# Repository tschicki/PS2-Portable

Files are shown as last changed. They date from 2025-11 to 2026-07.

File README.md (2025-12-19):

# A Custom PlayStation 2 Portable from Scratch

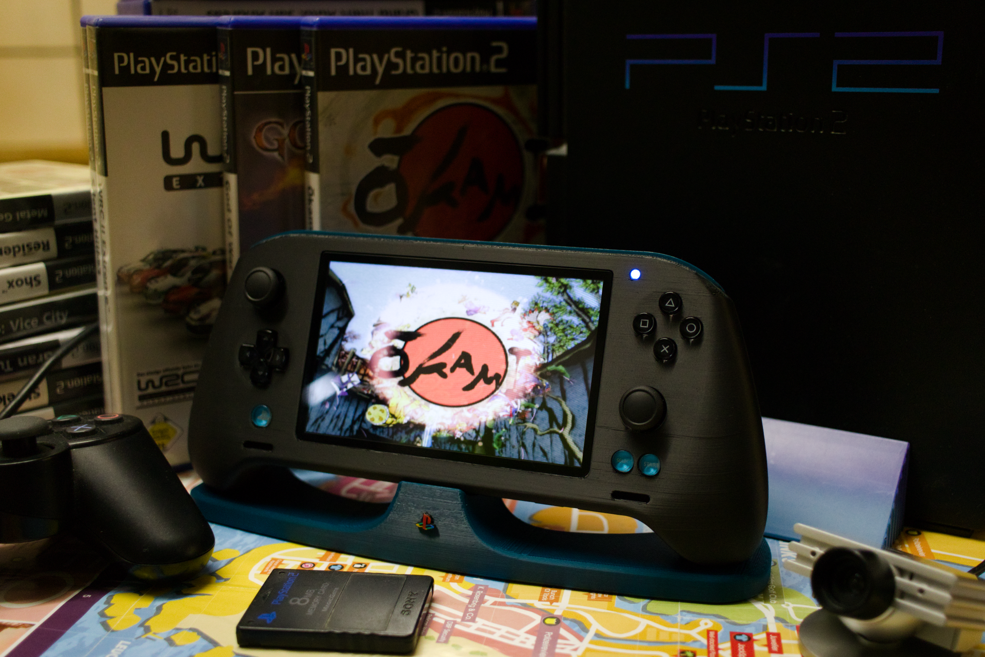
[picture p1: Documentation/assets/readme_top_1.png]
  

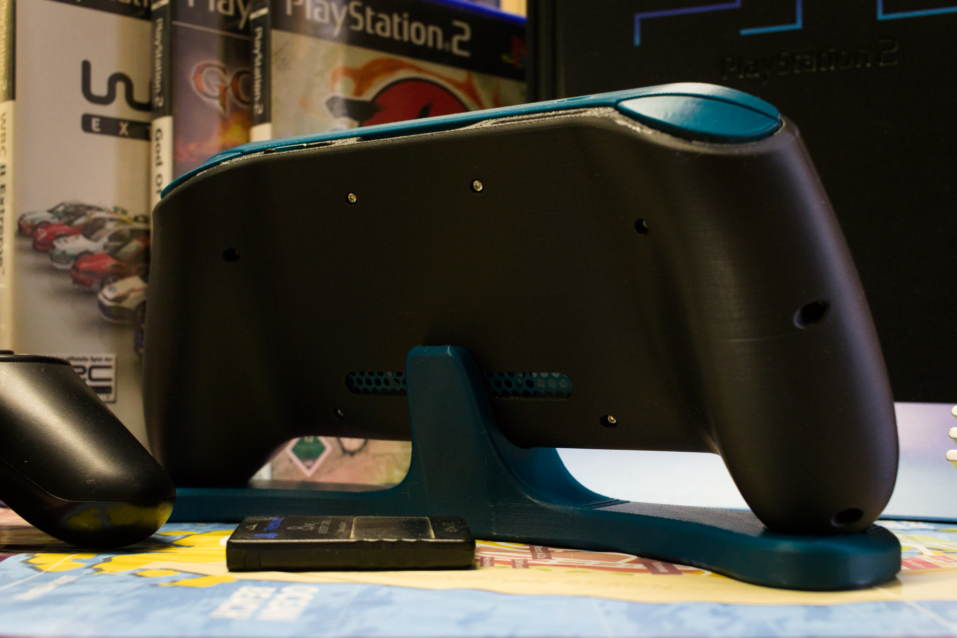
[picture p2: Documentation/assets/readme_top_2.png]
  

  

## About this Project
Just like the title says, this is a PlayStation 2 portable designed from scratch. This portable contains presumably world's first custom reverse engineered PS2 mainboard not made by Sony. It is only reusing 6 ICs of an original PS2, salvaged from SCPH-7900x or SCPH-9000x mainboards.

Most PS2 games can be played natively via OPL or NHDDL and the portable also features support for PS1 games via DKWDRV. Its two custom memory card slots are compatible with miniaturized PS2 Memory Cards, SD-Cards (MX4SIO) and a miniaturized SD2PSX.

Development of this project was started in 2022.

## Overview

### Custom PS2 AIO Mainboard
The mainboard was designed from scratch and is based on the SCPH-7900x and SCPH-9000x PS2 revisions. It also includes modern features, like USB-C PD charging and battery management, fully digital video output, I2S speaker and headphone amplifier and a customized boot ROM to boot directly into homebrew.  

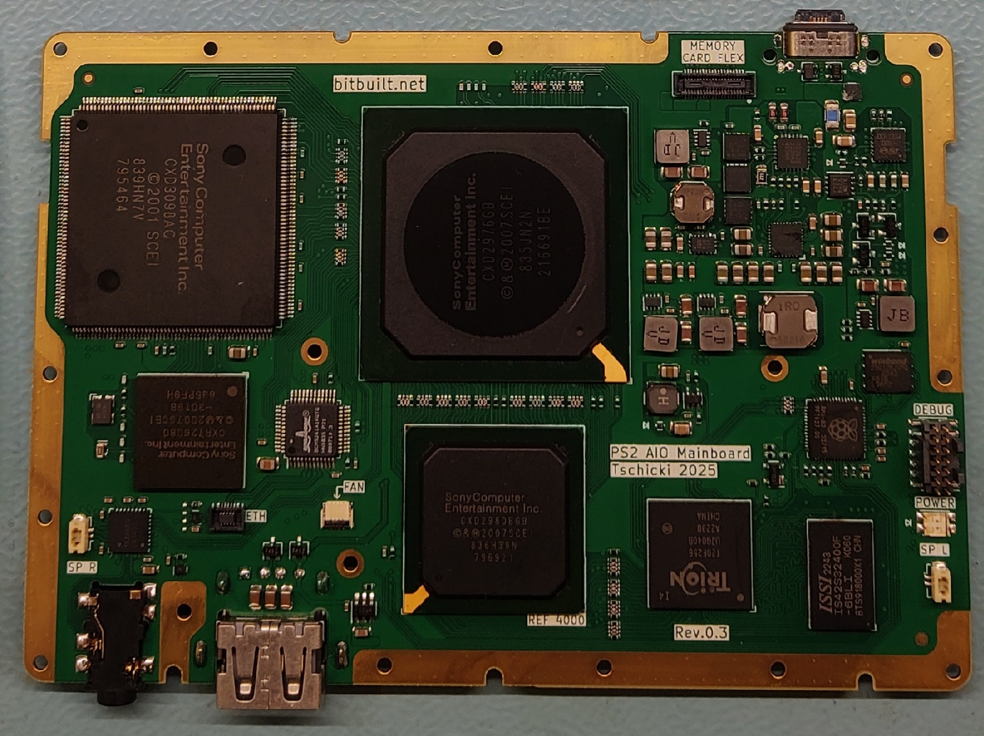
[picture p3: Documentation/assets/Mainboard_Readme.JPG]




#### Details:

- Battery Management:
    - USB C PD charging at 5V/9V/15V
    - Powered from 2S 5000mAh 21700 batteries for a total of 37Wh or about 4.5h of runtime on a single charge
    - Supports charge & play and includes a battery fuel gauge, protector and cell balancing

- Power Management:
    - Custom developed power management featuring modest EE and GS undervolting
    - Soft power button with minimal quiescent current
    - Monitoring to detect short circuits and overcurrent conditions

- Video Output:
    - Custom developed digital video processor based on a Trion T20 FPGA, written from scratch in VHDL
    - Fully digital direct drive of a 5” 480x800p DPI LCD by tapping right into the Graphics Synthesizer 24bit RGB output, replacing the stock PS2 video DAC
    - Features a motion-adaptive deinterlacer, line doubler, bilinear video scaler and OSD
    - Includes support for following resolutions:
        - 512i(256p) x 256, 512i(256p) x 320, 512i(256p) x 384, 512i(256p) x 448, 512i(256p) x 512, 512i(256p) x 640 at 50Hz
        - 448i(240p) x 256, 448i(240p) x 320, 448i(240p) x 384 at, 448i(240p) x 448, 448i(240p) x 512, 448i(240p) x 640 at 60Hz
        - VESA 480x640 at 60Hz

- Audio:
    - Custom I2S headphone and speaker amplifier using LM49450

- System Management:
    - Custom RP2040-based System Controller (SysCon) handling charging, discharging, power on/off, power management and monitoring
    - Custom developed DualShock 2 gamepad emulator running on core 1
        - Developed from scratch
        - Including rumble
        - Support for PS1 games
    - Custom developed configuration menu for changing and displaying various settings:
        - State of charge display (both in menu and via RGB LED)
        - EE temperature display and fan settings
        - Headphone and speaker volume
        - Various video processing settings, LCD brightness
        - Analog stick calibration and inversion
        - Deadzone settings
        - Power monitoring and TTE/TTF
        - And more…
    - SysCon firmware and video processor gateware updatable via drag & drop from USB-C

- Custom PS2 Boot ROM
    - Boots directly into PS2BBL, thanks to the BIOS modifications of Epaminondas – no softmods required

- Additional Features:
    - Fully functional PS2 RTC, enabled by an always-on standby rail

### Mechanical Assembly

The whole mechanical assembly was designed from scratch for FDM printing. The design goal was to make it as ergonomic as possible, while keeping the overall appearance simple and minimalistic.
The assembly is split into an outer shell and an inner assembly called 'skeleton' in an attempt to make assembly & disassembly easier and to allow easy shell replacements. Another priority for me was to use threaded inserts for all screws and to have easily replaceable non-soldered batteries.

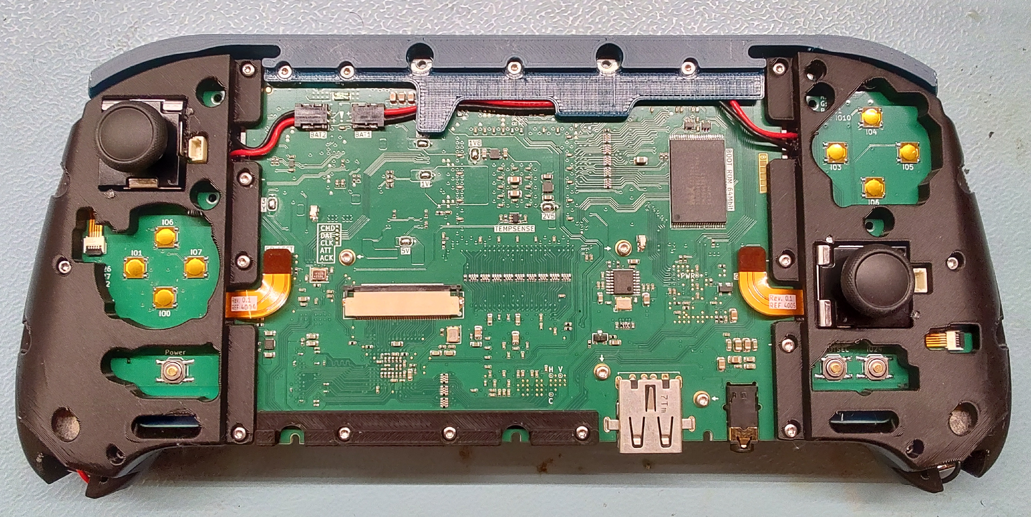
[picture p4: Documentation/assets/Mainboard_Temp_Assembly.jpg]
  

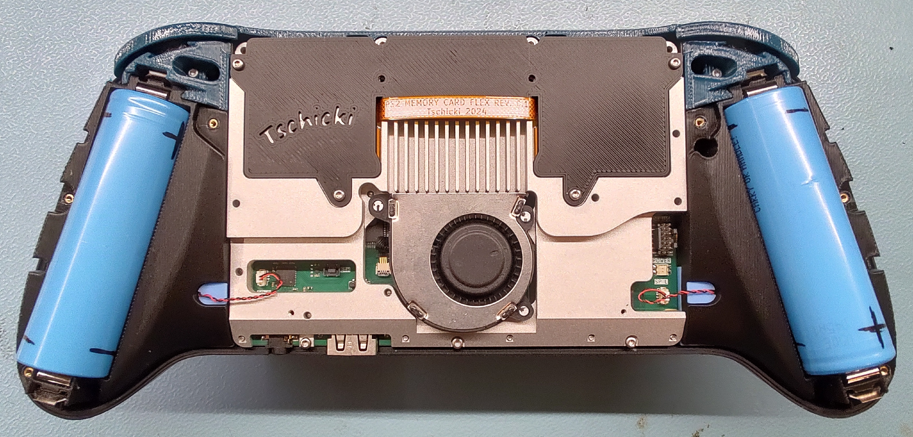
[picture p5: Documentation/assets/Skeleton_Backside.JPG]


#### Details:

- Gamepads
    - Custom designed & modular gamepad subassemblies that connect to the mainboard via I2C for best flexibility
    - PSVITA 2000 face buttons
    - 3.3V Nintendo Switch hall effect analog sticks
    - Rumble support: Coin-style rumble motors
    - Custom developed trigger mechanism using living hinges

- Cooling:
    - Custom designed aluminium heatsink covering the whole mainboard for maximum mechanical rigidity
    - Nintendo switch lite fan with configurable linear fan curve

- Interfaces:
    - Two fully accessible memory card slots, miniaturized by reusing SD card sockets
        - Natively compatible with MX4SIO, a custom reverse engineered PS2 memory card and a custom form factor SD2PSX 'uSD2PSX'
    - One USB A connector of the PS2, for using original accessories or USB sticks (DKWDRV)
    - Stereo headphone jack
    - USB-C connector for charging and SysCon firmware update

- Video and Audio
    - Stereo Nintendo Switch OLED speakers
    - 5" DPI LCD covered by a Nintendo 3DS XL glass screen lens

## Accessories
To further enhance the user experience, some more or less optional accessories were designed. 
- A *uSD2PSX* memory card in SD-Card format for running backups and saving games. Can also be unplugged to play on multiple consoles / portables, and is compatible for use on a stock console using a modified MX4SIO memory card. The best way to play games on the PS2 portable, and pretty much mandatory.
- A stand to place the portable while charging and when not in use.
- A travel case to protect the portable on-the-go.
- A reverse engineered PS2 memory card for saving games. Same form factor and interface as the uSD2PSX, but less useful. Don't bother with this and build the uSD2PSX instead.

## How to Build
I would highly recommend **not** to build one, even if you know what you are getting yourself into. If you're still not convinced to stop here, you can find the project documentation in the [documentation](https://github.com/tschicki/PS2-Portable/tree/main/Documentation) folder. It's best to read all the docs before you decide to continue.

You will need a lot of equipment and comprehensive electronics, soldering, troubleshooting and preferably also programming skills to have a chance of getting the custom PS2 mainboard to boot.

There is a [worklog](https://bitbuilt.net/forums/threads/some-ps2-project.5433/) of the whole project on BitBuilt, you might find some additional information there.

### Electronics
All custom PCBs, their Gerbers and their BOM can be found in the respective project under the [Electronics](https://github.com/tschicki/PS2-Portable/tree/main/Electronics) folder. All PCBs come from JLCPCB.

### Mechanics
All custom designed mechanical parts can be found under [Solidworks](https://github.com/tschicki/PS2-Portable/tree/main/Solidworks). If you would like to edit them, they were all designed using SolidWorks Maker. Otherwise, the STEP and STL exports can be found under [Output](https://github.com/tschicki/PS2-Portable/tree/main/Solidworks/Output).  
The housing parts were designed to be FDM printed, the CNC heatsink can be ordered from JLCCNC.

### Firmware & Gateware
The source files of the left & right gamepad firmware can be found [here](https://github.com/tschicki/PS2-Portable/tree/main/SysCon%20Firmware/PS2_Gamepad_02).  
The SysCon firmware can be found [here](https://github.com/tschicki/PS2-Portable/tree/main/SysCon%20Firmware/SysCon_FW).  
The Trion T20 gateware can be found [here](https://github.com/tschicki/PS2-Portable/tree/main/SysCon%20Firmware/SysCon_FW/ps2_video_processor).  

In order to obtain the required firmware, you need to compile it yourself. See the [documentation](https://github.com/tschicki/PS2-Portable/blob/main/Documentation/Part%2010_Development%20and%20Debugging.md) for that.

### Bill of Materials
The bill of materials for the mechanical assembly can be found [here](https://github.com/tschicki/PS2-Portable/blob/main/Documentation/Part%200_Mechanical%20BOM.md). The electrical BOM for each PCBA is in the [Electronics](https://github.com/tschicki/PS2-Portable/tree/main/Electronics) folder.

### Assembly Instructions
Check the [documentation](https://github.com/tschicki/PS2-Portable/tree/main/Documentation) folder. I tried to structure the sequence of documents so that it can guide you along for your build.

## Special Thanks
Thanks to the BitBuilt community for reading and commenting the worklog, it really helped to keep the motivation up! And special thanks to:
- Mister M and Gman for releasing their PS2 mainboard scans – without them this project would’ve taken much longer!
- Epaminondas for his amazing work on the custom PS2 BIOS. Seriously, you rock!
- Stuckpixel for helping out with converting the SPI part of the gamepad emulator to PIO. It’s much more reliable now!
- wisi and mixa232323 for guiding me in the right direction with all the boot ROM shenanigans
- StonedEdge and thedrew for their various suggestions and tips along the way
- All the awesome people working on the SD2PSX, neutrino and NHDDL! It's incredible to see how far the PS2 homebrew scene has come in the last couple of years!

## Known Bugs and Anomalies
This is a hobby project, so the end result will never be flawless. The design has seen hundreds of hours of playtesting, where following anomalies were discovered:
- The PS2 RTC drifts by about 7s a day, this could most likely be solved by selecting a different 32kHz crystal or by tweaking the load capacitors. However, the characteristics of the original crystal and the Mechacon's oscillator circuits are unknown.
- Games with static and permanently flickering elements can cause image retention on the LCD. I only noticed this on one game so far - Castlevania: Symphony of the Night, where certain HUD elements flicker. It is not recommended to play such games to prevent damage to the LCD.

## License
All firmware, gateware and hardware in this repository is licensed under the [MIT License](LICENSE).

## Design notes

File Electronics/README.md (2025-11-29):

# PCB Outputs

This directory contains all the PCB projects. You will find the Gerber files in the respective *Gerber/* folders. The BOM is in ibom format and can be found in the *BOM/* folders where applicable. For very simple PCBs like the gamepad flex PCBs you will find the needed components in Part 5 of the project documentation.

If you need the BOM in CSV format, you can open the ibom files and export the content as CSV.

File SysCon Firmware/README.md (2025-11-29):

# Firmware

In the */PS2_Gamepad_02/* directory you will find the firmware project for both gamepads. It's the same firmware for both, the side is determined by a pin on the RP2040 that is high on one and low on the other gamepad PCB.

In the */SysCon_FW/* directory you will find the SysCon firmware project. You will need this for the PS2 AIO Mainboard bringup described in the project doc Part 6.

In the */SysCon_FW/ps2_video_processor/* directory you will find the VHDL project for the Video Processor FPGA.

Some more hints and guidance about setting up the environment can be found in the project doc Part 10.

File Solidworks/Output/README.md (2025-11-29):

# Mechanical Part Outputs

In here you will find the STEP and STL exports of all mechanical parts to 3D print / CNC. 

Please ignore the *./Output Assembly* folder, it contains the assembly file and all respective component bodies for me to easily export all files at once. In case you modify any parts in the working assembly under *./Solidworks/PS2_Assembly.SLDASM*, the respective parts in the export assembly should update automatically.
To export all models, open the assembly *./Output Assembly/Export.SLDASM* and save as either STEP or STL - make sure that you select to export the parts of the assembly individually in the options before saving.

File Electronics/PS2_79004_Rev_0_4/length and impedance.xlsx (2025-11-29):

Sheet: Stackup_Impedances
Stackup:
single ended impedances:
 | top | 2 | 3 | 4 | 5 | bot
50R | 0.1565 | n/a | 0,1344* | 0,1344* | n/a | 0.1565 | *assuming gnd on both adjacent layers
68R | 0.0721 | n/a | n/a | n/a | n/a | 0.0721
60R | 0.1026 | n/a | 0.0881 | 0.0881 | n/a | 0.1026
 |  | n/a |  |  | n/a
 |  | n/a |  |  | n/a
 |  | n/a |  |  | n/a
 |  | n/a |  |  | n/a
 |  | n/a |  |  | n/a
 |  | n/a |  |  | n/a
 |  | n/a |  |  | n/a

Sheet: SDRAM
top | DQ0 | 20.33
 | DQ3 | 20.7 | min | max
 | DQ2 | 17.97 | 16.15 | 23.63 | signal propagation speed should be around 6-7ps/mm (very roughly)
 | DQ4 | 17.08 |  |  | the minimum of setup/hold time in the SDRAM DTS is 800ps
 | DQ1 | 18.16 | clk
 | DQ5 | 17.38 | 20.19 |  | 10% of the setup/hold time is 80ps, or about 12mm
 | DQ7 | 19.39 |  |  | at 150MHz and such short traces, length matching most likely doesn't matter much, so based on that napkin math a length mismatch of about +-6mm should be fine for all signals
 | DQM0 | 17.24 | clk+6 | clk-6
 | WE | 16.99 | 26.19 | 14.19 | impedance target for all signals should be in the range of 60R
 | RAS | 17.07
 | CE | 16.48 |  |  | for outer layers: | for layer 3:
 | A11 | 17.95
 | BA1 | 19.74
 | A11 | 17.77
 | A0 | 18.28
 | DQM2 | 19.08
 | DQ18 | 17.09
 | DQ20 | 18.34
 | DQ21 | 16.15
 | DQ19 | 20.16
 | DQ23 | 18.84
2 | DQ13 | 21.98
 | DQ15 | 19.94
 | DQ11 | 19.55
 | DQ14 | 21.19
 | DQ12 | 19.96
 | DQ10 | 19.97
 | DQ9 | 21.16
 | A9 | 20.18
 | A7 | 21.78
 | A8 | 19.79
 | A5 | 21
 | A6 | 19.16
 | A4 | 22.29
 | A3 | 18.84
 | DQM3 | 20.94
 | DQ29 | 20.05
 | DQ30 | 21.24
 | DQ27 | 22.76
 | DQ25 | 23.63
back | DQ6 | 21.23
 | DQM1 | 19.43
 | DQ8 | 20.91
 | CLK | 20.19
 | CKE | 21.05
 | CAS | 17.62
 | BA0 | 18.59
 | A10 | 19.39
 | DQ31 | 22.48
 | DQ28 | 21.68
 | DQ24 | 23.05
 | DQ26 | 21.55
 | DQ16 | 20.24
 | A2 | 20.97
 | DQ17 | 22.66
 | DQ22 | 21.89

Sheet: Ethernet MDI
ethernet:
length: within 1,27mm (RX/TX)
100R Zdiff; 50R Zo; both+-10%
keep below 5 cm total length
coplanar clearance 5*w = 0,6mm
routed on top layer

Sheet: USB+USBC
USB Zdiff/Zo: 90R/45R +-15%
USB-C CC lines: 50R single ended -> 0,125mm trace width is sufficient for layer 3
USB routed on bot layer for PS2 | USB routed on layer3 for SysCon

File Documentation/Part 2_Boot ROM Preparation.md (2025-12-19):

# Part 2: Boot ROM Preparation
This part of the assembly documentation will describe how to prepare the MX29LV640ET NOR flash for the PS2 AIO Maonboard Assembly.
The chip must be flashed with a functional BIOS, otherwise the console will never boot.

For the Boot ROM you have two options:
1. Flash a stock SCPH-7900x BIOS of your console's region
2. Modify the stock SCPH-7900x BIOS of your console's region to auto-boot into PS2BBL and flash that

Since the SD2PSX offers a very easy and attractive way to softmod the PS2, a boot rom modification is not strictly required. However, your choice here will mandate how you have to set up the BOOT Memory Card of your SD2PSX. If you go for option 1, you need to set up the Memory Card just like you would set it up for a stock console. For option 2 on the other hand, you will only need to provide the PS2BBL config file and an .ELF of the hombrew launcher of your choice (NHDDL recommended) on the BOOT Memory Card. The fastest and easiest way for sure is option 1: to flash a stock boot rom and DVD rom onto the 64Mbit NOR flash. For advanced users, option 2 is still listed.

## Option 1: Stock Boot ROM
1. Obtain a SCPH-7900x BIOS of your donor console's region. Make sure to also dump/obtain the matching DVD ROM. 
    - (preferred) You can dump both from the donor console using PS2Ident. 
    - Otherwise you can find a matching v2.20 Boot ROM and v3.11 DVD ROM of the donor's region online.
2. Ensure in PCSX2 that the Boot ROM is functional. 
3. Then you will need to merge Boot and DVD ROM together. 
    - To do that, use the python script 'merge_boot_upper_dvd_lower_with_padding.py' in the *Boot ROM* directory
    - Make sure to rename the Boot ROM to `BOOT_ROM.bin` and the DVD ROM to `DVD_ROM.bin` before running the script, and place them in the script’s directory. 
    - To launch the script, open a terminal in the script’s directory and type `python merge_boot_upper_dvd_lower_with_padding.py`. You need to have Python 3.12+ installed.
4. A file called “MERGED_ROM.bin” will appear in the explorer. This is the ROM you need to program onto the NOR flash. Refer to *Flash Programming* for that.
5. Verify in the file properties that the binary has exactly 8MB, otherwise something went wrong with merging.

## Option 2: Modified Boot ROM
What you will need in addition to Option 1:
- an .ELF of [PS2BBL](https://github.com/israpps/PlayStation2-Basic-BootLoader), preferrably the one with the smallest filesize (i.e. no fancy features like MMCE). You can also use the custom build of PS2BBL I put in the [Boot ROM directory](https://github.com/tschicki/PS2-Portable/tree/main/Boot%20ROM), it launches OSDSYS instead of emergency mode when no memory card is plugged.
- [ROMMAN](https://github.com/israpps/romman) for building the custom Boot ROM binary

Obtain a stock SCPH-7900x BIOS of your console's region. Make sure to also dump/obtain the matching DVD ROM. The easiest is to create a folder and copy both the Boot ROM binary and ROMMAN there.

### The following applies if you have ROMMAN compiled for Windows:
1. Extract the Boot ROM using ROMMAN: 
    > romman-windows.exe -x [*Path to Boot ROM filename*].bin
2. Modify the EELOAD module extracted by ROMMAN, you find it in the **folder** [*Boot ROM filename*].bin
    - Open the EELOAD file in a HEX editor (e.g. [ImHex](https://https://imhex.werwolv.net/)) and look for *rom0:OSDSYS* and *rom0:TESTMODE*; replace **OSDSYS** with **PS2BBL**
    - This modification will force the console to boot into PS2BBL instead of OSDSYS  
      
3. In the ROM config ([*Boot ROM filename*].csv) add the following line before the DECKARD module: `PS2BBL,,,,`
    - This will tell ROMMAN to insert PS2BBL here  
     
4. Delete the .ELF file extension of the obtained PS2BBL ELF (should just be a file, no .ELF file) and copy it to all the other modules in the **folder** [*Boot ROM filename*].bin created by ROMMAN
5. Build the new ROM using ROMMAN: 
    > romman-windows.exe -g [Boot ROM filename].csv ext_[Boot ROM filename].bin/ [name of generated binary].bin
6. Test the newly built Boot ROM in PCSX2 -> you should be greeted by a PS2BBL logo
7. Lastly, merge the custom Boot ROM and the DVD ROM the same way as described for Option 1.

## Last Step: Flash Programming
For programming I use a TL-866II PLUS with TSOP-48 adapter and the software “Xgpro”. 
1. Select the correct flash chip from the top left, for the stock BOM it is “MX29LV640ET @TSOP48”.  

    
2. Open the generated binary file using “load file”, I never had to change the default settings here.  

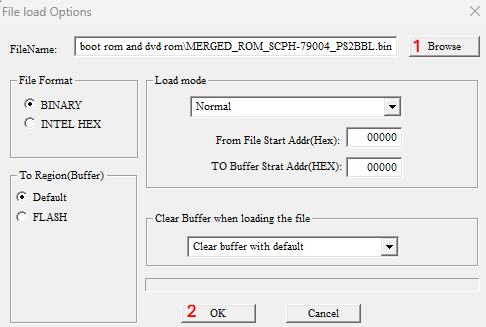
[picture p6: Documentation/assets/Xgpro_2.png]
    
3. Then use the button “PROG.” to program the flash with the binary, this takes some time. Make sure the verify was successful!  

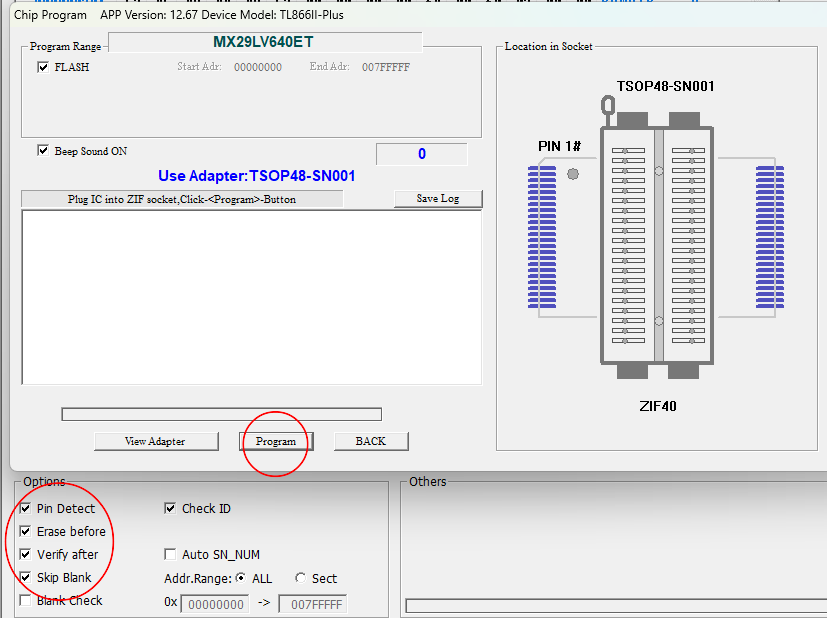
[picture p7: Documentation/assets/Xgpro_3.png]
     
4. Afterwards you can remove the flash from the adapter, it’s now programmed with the BIOS and ready to use for soldering.

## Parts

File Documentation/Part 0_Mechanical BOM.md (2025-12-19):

# Part 0: Mechanical BOM
This part of the assembly documentation will give an overview of all off-the-shelf and custom parts required for the mechanical assembly.

## Off-The-Shelf Components (REF1xxx)
|REF| Description | QTY | Preferred Part | Alternative | Comment |
|-----|---|---|----|---|---|
|1000| Nintendo Switch Lite Fan	 | 1	| - | - | Use an OEM fan if possible, the knockoff ones are hit or miss - some are terribly loud and vibrate a lot |
|1001| PLP1-100-FD Light Pipe	 | 1	|[Link](https://www.digikey.at/en/products/detail/bivar-inc/PLP1-100-FD/5721997)| - | - |
|1002| Switch OLED Speaker | 2	|[Link](https://de.aliexpress.com/item/1005006776523668.html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)| - | A lot of offers are salvaged and arrive broken; order a couple more than needed|
|1003| 5 inch IPS LCD | 1	|[Link](https://www.buydisplay.com/ips-5-tft-lcd-display-module-wvga-800x480-high-resolution-for-mp4-gps)| - | 480x800 IPS; MPN 'ER-TFT050-6'; buydisplay have an ebay store where you might find this panel in your region|
|1004| Rumble Motor | 2	|[Link](https://de.aliexpress.com/item/1005007232956167.html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)| - | dimensions: 10x3.4mm; voltage: 3V |
|1005| Battery Contact | 4	|[Link](https://www.digikey.at/en/products/detail/keystone-electronics/209/151583)| - | Keystone 209 |
|1006| 21700 Battery | 2	| Samsung INR21700-50E | - | It's important to use 5000mAh, that's what the fuel gauge is configured for|
|1007| Screw M1.6x5mm | - | - |	-| ISO14583 T5 Lenshead or similar; A2 stainless|
|1008| Screw M1.6x6mm | - | - | - | ISO14581 T5 Countersunk or similar; A2 stainless|
|1009| PSVITA 2000 Action Buttons | 1 |[Link](https://de.aliexpress.com/item/1005005248755849.html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)| - | Difficult to find good quality OEM options; most suck. Avoid all colors other than black, they are usually terrible. The linked ones are fine from experience|
|1010| PSVITA 2000 DPad | 1	|[Link](https://de.aliexpress.com/item/1005005248755849.html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)| - | Difficult to find good quality OEM options; most suck. Avoid all colors other than black, they are usually terrible. The linked ones are fine from experience|
|1011| PSVITA2000 Start/Select | 1	| - | - | check aliexpress, for this one the cheap knockoff buttons also work OK; difficult to find standalone, you might need to order a full button set |		
|1012| PSVITA 2000 Power | 1 | - | - | check aliexpress, for this one the cheap knockoff buttons also work OK; difficult to find standalone, you might need to order a full button set |		
|1013| Switch Analog Stick | 2	|[Link](https://de.aliexpress.com/item/1005006339839843.html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)| - | Preferrably Hall-Effect. **Must be 3.3V compatible!** |
|1014| M1.6 brass threaded inserts  | - |[Link](https://de.aliexpress.com/item/1005004975376499.html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)| - | M1.6; OD 2.5mm; 3mm length |
|1015| Nintendo 3DS XL Screen Lens  | 1	|[Link](https://de.aliexpress.com/item/1005006348556032.html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)| - | With adhesive |
|1016| EZMate HC Housing | 2	|[Link](https://www.digikey.at/de/products/detail/molex/2082982021/18687096?s=N4IgTCBcDa4AwA4wE4lzARhAXQL5A)| - | MPN: 2082982021|		
|1017| EZMate HC Crimp contacts | 4 |[Link](https://www.digikey.at/de/products/detail/molex/2082995001/18687105?s=N4IgTCBcDa4AwA4wE5kFY5wIwgLoF8g)| - | MPN: 2082995001|		
|1018| Wire red | - |[Link](https://www.digikey.at/de/products/detail/cnc-tech/10064-22-1-0500-004-1-TS/15851348)| - | 22AWG; outer diameter: 1.11-1.26mm|
|1019| Wire black | - |[Link](https://www.digikey.at/de/products/detail/cnc-tech/10064-22-1-0500-001-1-TS/15851314)| - | 22AWG; outer diameter: 1.11-1.26mm|
|1020| Speaker dust cover | 2 |[Link](https://de.aliexpress.com/item/1005008057849390.html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)| - | 16mm*5mm; usually called "short" |			
|1021| Double-sided Adhesive Tape | - |[Link](https://de.aliexpress.com/item/1005009377010900.html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,scm-url:1007.40050.354490.0,pvid:4acd2414-c102-4e50-99c7-33186ac94385,tpp_buckets:668%232846%238112%231997&pdp_ext_f=%7B%22order%22%3A%2272%22%2C%22eval%22%3A%221%22%2C%22sceneId%22%3A%2230050%22%7D&pdp_npi=6%40dis%21EUR%214.08%211.92%21%21%2133.30%2115.65%21%40211b876717579581245908348e77ce%2112000048918233520%21rec%21AT%211649060191%21X%211%210%21n_tag%3A-29919%3Bd%3Ab6ccbfbd%3Bm03_new_user%3A-29895&utparam-url=scene%3ApcDetailBottomMoreOtherSeller%7Cquery_from%3A%7Cx_object_id%3A1005009377010900%7C_p_origin_prod%3A)| - | Use the 2mm wide option |
|1022| 0.5mm thermal pad | - |[Link](https://www.digikey.at/de/products/detail/bergquist/gp1500-0-020-02-0404/307783)| - | can also be a similar one, but it should be 0.5mm thick and soft |
|1023| 1mm thermal pad | - |[Link](https://www.digikey.at/de/products/detail/bergquist/GP1500-0-040-02-0404/307784)| - | can also be a similar one, but it should be 1mm thick and soft |	
|1024| 1mm foam rubber pads with adhesive | - | - | - | for padding of travel case; can be obtained from multiple sources |	
|1025| Screw M3x25 | 2 | - | - | ISO 4762 cylinder head; required for travel case; |

## 3D-Printed Componentss (REF2xxx)
For printing guides, refer to the mechanical components preparation, [Part 1](https://github.com/tschicki/PS2-Portable/blob/main/Documentation/Part%201_Mechanical%20Components%20Preparation.md).

|REF| Description | QTY |
|-----|---|---|
|2000| PS2 Main Housing Top |1|	
|2001| PS2 Main Housing Bot	 |1|	
|2002| Button Cover Left	 |1|
|2003| Button Cover Right	 |1|
|2004| Battery Compartment Left	 |1|
|2005| Battery Compartment Right	|1|
|2006| Speaker Cover Left	 |1|
|2007| Speaker Cover Right	 |1|
|2008| Screen Lens Frame	 |1|	
|2009| Lower Display Mount	 |1|
|2010| R1-L1 Bar	 |1|
|2011| L2 Button	 |1|
|2012| R2 Button	 |1|
|2013| MemoryCard Cover	 |1|
|2014| Backside Vent Cover	 |1|	
|2015| Rumble Sleeve	 |2|	
|2016| Speaker Plug	 |2|
|2017| uSD2PSX Frame |1|
|2018| uSD2PSX Stiffener |1|
|2019| Display Stand |1|
|2020| Travel Case Top |1|
|2021| Travel Case Bot |1|
|2022| Travel Case Latch Left |1|
|2023| Travel Case Latch Right |1|

## CNC Components (REF3xxx)
For ordering information, refer to the mechanical components preparation, [Part 1](https://github.com/tschicki/PS2-Portable/blob/main/Documentation/Part%201_Mechanical%20Components%20Preparation.md).

|REF | Description  | QTY |
|----|---|-----|
|3000| PS2 Heatsink |1 |	

## PCBs (REF4xxx)
For ordering information, refer to the mechanical components preparation, [Part 1](https://github.com/tschicki/PS2-Portable/blob/main/Documentation/Part%201_Mechanical%20Components%20Preparation.md).

|REF | Description  | QTY |
|----|---|-----|
|4000| PS2 Mainboard |1|	
|4001| Gamepad Left	 |1|
|4002| Gamepad Right	 |1|
|4003| Memory Card Flex	 |1|
|4004| Gamepad Flex Left	|1|
|4005| Gamepad Flex Right	|1|
|4006| R1 R2 Flex	 |1|
|4007| L1 L2 Flex	 |1|
|4008| uSD2PSX Flex	 |1|

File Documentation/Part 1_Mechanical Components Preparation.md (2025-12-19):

# Part 1: Components Preparation and Ordering
This part of the assembly documentation will give a couple of hints on obtaining all the custom parts and preparing them for assembly. This includes PCBs, 3D-printed parts and CNC parts.

You will find the 3D models of all mechanical parts in the [Output](https://github.com/tschicki/PS2-Portable/tree/main/Solidworks/Output) folder, the Gerbers of all PCBs are in their respective electronics folder under *Gerber/*.

## Recommended Tools:
- Soldering iron
- Side cutters
- Scalpel or similar
- Tweezers
- Tool for M1.6 brass inserts

## Recommended Materials:
- Solder

## 3D-Printed Parts

In General:
- All excess material must be removed after printing, this especially applies to overhangs and support material interfaces. Just take a good look at all parts and clean them up nicely using the necessary tools.
- The TPU parts should really be printed from TPU to avoid assembly issues.
- The outer housing could also be ordered as SLS or SLA part, but consider the following:
    - Both parts are kind of thin and long, so prone to warping
    - For ordering a SLA, the holes for the set inserts must be enlarged either in the 3D files or manually
- The outer housings can be painted

### PS2 Main Housing Top (REF2000)
- Preferred Material: PLA
- Infill: 100% 

It's best to print this one a bit slower with thinner layers for better quality. Add at least tree supports to the lower display edge, the speaker openings, DPAD and the shoulder button areas. Will need a big brim to stay in place nicely.

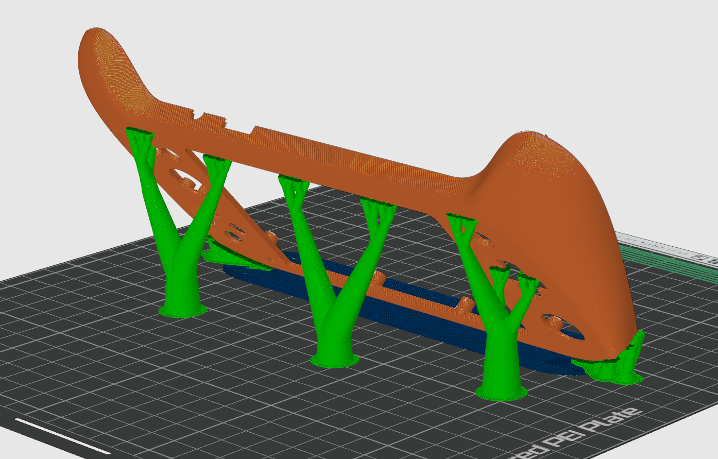
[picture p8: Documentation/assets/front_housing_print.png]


### PS2 Main Housing Bot (REF2001)
- Preferred Material: PLA
- Infill: 100% 

It's best to print this one a bit slower with thinner layers for better quality. Enabling auto tree supports should be sufficient. Can be printed vertically like shown below or tilted a little to remove all the supports for the screw posts.  

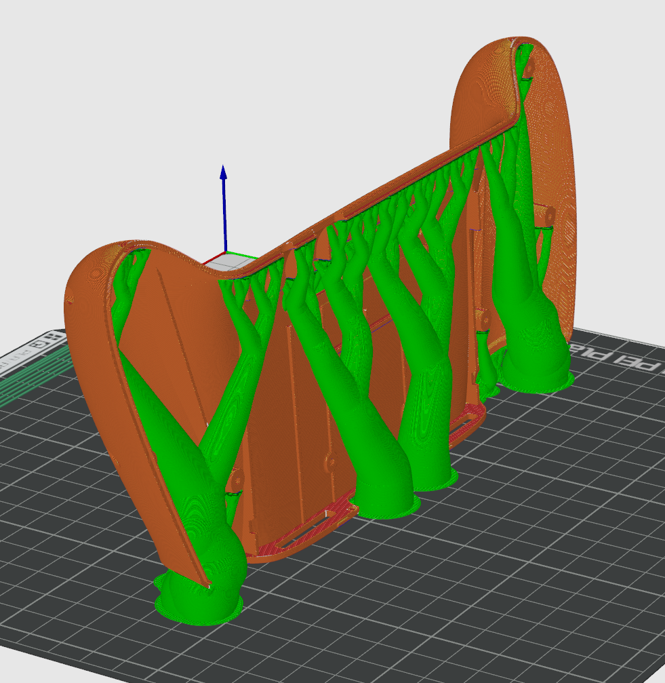
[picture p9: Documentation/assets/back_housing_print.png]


### Button Cover Left (REF2002) and Button Cover Right (REF2003)
- Preferred Material: PLA
- Infill: 50% 

The overall shape is just mirrored, so both are similar to print. Enabling auto tree supports should be sufficient.

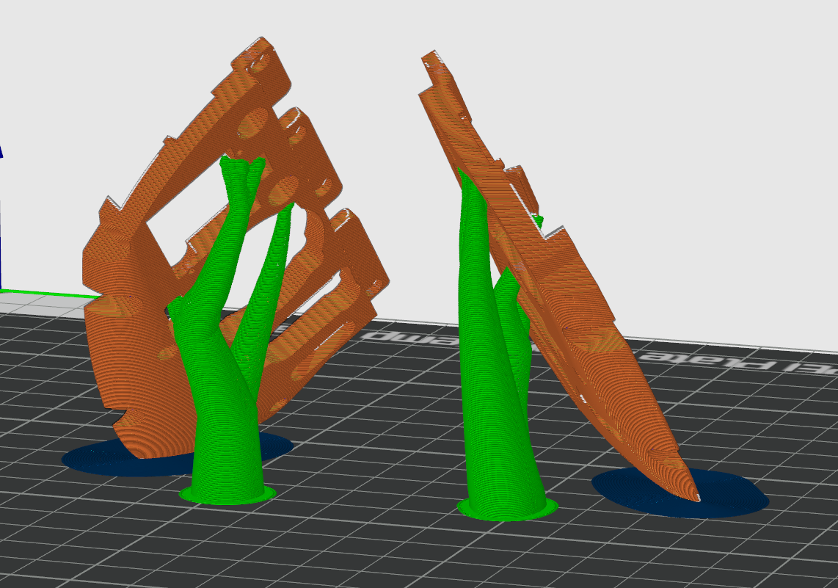
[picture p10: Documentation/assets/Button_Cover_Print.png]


### Battery Compartment Left (REF2004) and Battery Compartment Right (REF2005)
- Preferred Material: PLA
- Infill: 50% 

The overall shape is just mirrored, so both are similar to print. Enabling auto tree supports should be sufficient.

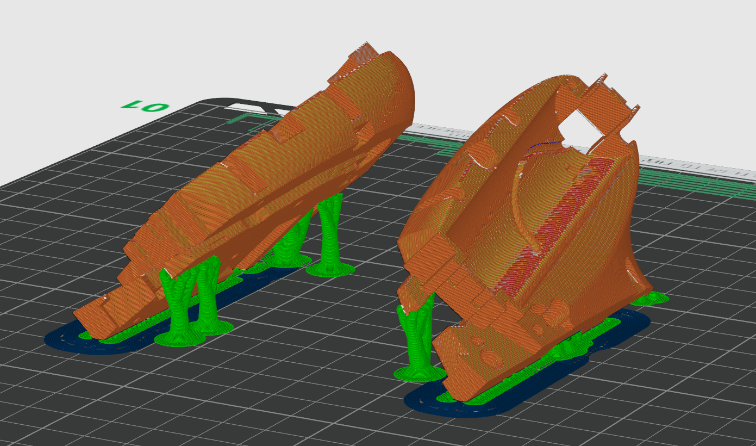
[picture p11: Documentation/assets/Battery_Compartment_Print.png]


### Speaker Cover Left (REF2006) and Speaker Cover Right (REF2007)
- Preferred Material: TPU 95A
- Infill: 15%

Don't use a textured print bed for optimal fitment.

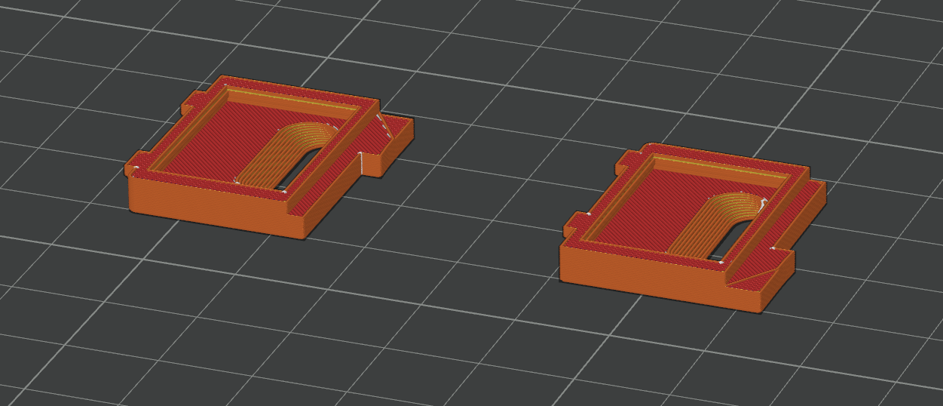
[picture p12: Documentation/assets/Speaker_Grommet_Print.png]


### Screen Lens Frame (REF2008)
- Preferred Material: PLA
- Infill: 50% 

Don't use a textured print bed for optimal fitment.

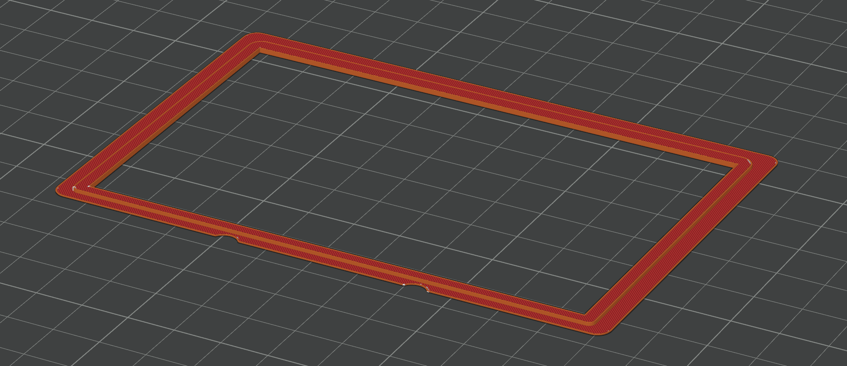
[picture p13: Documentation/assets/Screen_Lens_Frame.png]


### Lower Display Mount (REF2009)
- Preferred Material: PLA
- Infill: 50% 

Don't use a textured print bed for optimal fitment.

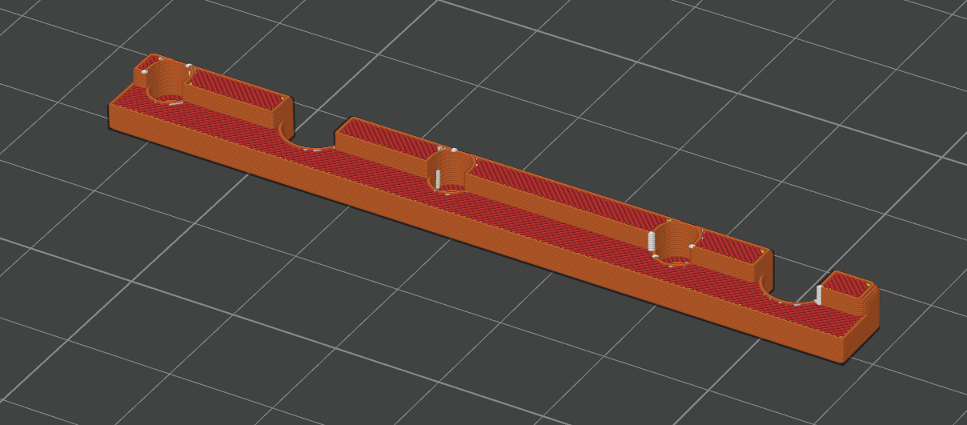
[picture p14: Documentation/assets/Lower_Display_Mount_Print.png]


### R1-L1 Bar (REF2010)
- Preferred Material: PETG
- Infill: 100% 

Likes to warp, so a brim might be needed. For best fitment, it is recommended to use normal (no tree) supports with PLA interface layer to get a smooth and flat surface.

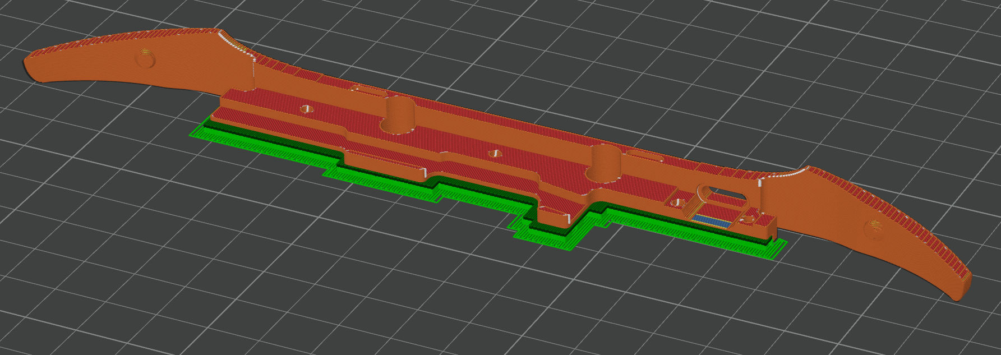
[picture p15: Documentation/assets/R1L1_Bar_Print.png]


### L2 Button (REF2011) and R2 Button (REF2012)
- Preferred Material: PETG
- Infill: 100% 

Prints fine without supports. PLA is not recommended.



### MemoryCard Cover (REF2013)
- Preferred Material: PLA
- Infill: 50% 

Prints fine without supports. PETG could be considered, but the heatsink does not get warm enough to deform PLA.



### Backside Vent Cover (REF2014)
- Preferred Material: PLA
- Infill: 50%

Don't use a textured print bed for optimal fitment.



### Rumble Sleeve (REF2015)
- Preferred Material: TPU 95A
- Infill: 15%

Nothing special to note.



### Speaker Plug (REF2016)
- Preferred Material: TPU 95A
- Infill: 100%

Nothing special to note.



### uSD2PSX Frame (REF2017)
- Preferred Material: PLA
- Infill: 100%

Print with 0.1mm layer height.



### uSD2PSX Stiffener (REF2018)
- Preferred Material: PLA
- Infill: 100%

Print with 0.1mm layer height.



### Travel Case Top (REF2020)

- Preferred Material: PLA
- Infill: 50% 

Print with auto tree support:



### Travel Case Bot (REF2021)

- Preferred Material: PLA
- Infill: 50% 

Print with auto tree support:



### Travel Latch Left & Right (REF2022 & REF2023)

- Preferred Material: PETG
- Infill: 100% 

No supports needed.



### Display Stand (REF2019)

- Preferred Material: PLA
- Infill: 15%

Prints fine without supports.



## CNC Parts and PCBs (JLC)
### Overview



### PS2 Heatsink (REF3000)
- Supplier: JLCCNC
- Material: Aluminium 6061
- Surface: Bead blasting; anodizing is absolutely not recommended for heat transfer reasons!
- Tolerance: ISO 2768 m
- Threads: TODO: create tapping drawing for the supplier; for now it's cheaper and faster to tap yourself; 

If you don't order the part pre-tapped, you will need to tap M1.6 threads in following locations:





### PS2 Mainboard (REF4000)
- Supplier: JLCPCB
- Type: 6-Layer rigid
- Stackup: JLC06121H-3313; 1.2mm thickness
- Material: FR4 TG155
- Copper: Outer 1oz; Inner 0.5oz
- Plating: ENIG
- Via: VIPPO; Epoxy Filled and Capped
- [Gerber](https://github.com/tschicki/PS2-Portable/tree/main/Electronics/PS2_79004_Rev_0_4/Gerber)

### Gamepad Left (REF4001) and Gamepad Right (REF4002)
- Supplier: JLCPCB
- Type: 4-Layer rigid
- Stackup: JLC04081H-7628; 0.8mm thickness
- Material: FR4 TG135-140
- Copper: Outer 1oz; Inner 0.5oz
- Plating: HASL
- Via: tented or plugged
- [Gerber Left](https://github.com/tschicki/PS2-Portable/tree/main/Electronics/PS2_Gamepad_Left/Gamepad_Left_02/Gerber)
- [Gerber Right](https://github.com/tschicki/PS2-Portable/tree/main/Electronics/PS2_Gamepad_Right/Gamepad_Right_02/Gerber)

### Memory Card Flex (REF4003)
- Supplier: JLCPCB
- Type: 2-Layer flex
- Thickness: 0.11mm
- Stiffener: FR4 0.6mm
- Copper: 1/3oz
- Outline: Laser-cut
- [Gerber](https://github.com/tschicki/PS2-Portable/tree/main/Electronics/PS2_memcard_flex/Gerber)

### Gamepad Flex Left (REF4004) and Gamepad Flex Right (REF4005)
- Supplier: JLCPCB
- Type: 2-Layer flex
- Thickness: 0.11mm
- Stiffener: Polyimide 0.25mm
- Copper: 1/3oz
- Outline: Laser-cut 
- [Gerber Left](https://github.com/tschicki/PS2-Portable/tree/main/Electronics/PS2_Gamepad_Left/Flex_Left/Gerber)
- [Gerber Right](https://github.com/tschicki/PS2-Portable/tree/main/Electronics/PS2_Gamepad_Right/FLex_Right/Gerber)

### R1 R2 Flex (REF4006) and L1 L2 Flex (REF4007)
- Supplier: JLCPCB
- Type: 2-Layer flex
- Thickness: 0.11mm
- Stiffener: Polyimide 0.25mm
- Copper: 1/3oz
- Outline: Laser-cut
- Gold Fingers -> YES (0.3mm total thickness flex + stiffener)
- [Gerber L1 L2](https://github.com/tschicki/PS2-Portable/tree/main/Electronics/PS2_Gamepad_Left/Flex_L1_L2/Gerber)
- [Gerber R1 R2](https://github.com/tschicki/PS2-Portable/tree/main/Electronics/PS2_Gamepad_Right/Flex_R1_R2/Gerber)

### uSD2PSX Flex (REF4008)
- Supplier: JLCPCB
- Type: 2-Layer flex
- Thickness: 0.11mm
- Stiffener: None
- Copper: 1/3oz
- Outline: Laser-cut 
- [Gerber](https://github.com/tschicki/PS2-Portable/tree/main/Electronics/uSD2PSX/Gerber)

## Tools

### Reballing Stencils
The custom reballing stencils are supplied by JLCPCB. They are 90x90mm and fit the common rose-gold reballing fixtures. The cutouts are optimized for 0.55mm solder balls. 
You can find the Gerbers [here](https://github.com/tschicki/PS2-Portable/tree/main/Electronics/PS2_Reballing_Stencils_Eval/Gerber). The files contain a panel outline too, so the panel can either have a 190x190mm custom size (cheaper shipping) or JLCs default 380x280mm stencil size.  
For ordering add the following comments:

- Please do not change the stencil aperture
- Stencil thickness: 0.2mm
- Engraving: Text and position, see file "engrave.gbr"

### Tool for M1.6 Brass Inserts
A tool for M1.6 heat set inserts is very difficult to find, especially as a tip for soldering irons. I personally use the M2 adaper for Ersa soldering irons available from [CNCKitchen](https://cnckitchen.store/de/collections/soldering-tips-and-sets). To have the correct diameter and about 3mm length, I modified it using a drill, file and sandpaper.

### Heatsink Tapping Tool
Proper handles for M1.6 taps are just as uncommon as the tools for M1.6 brass inserts. The [Output](https://github.com/tschicki/PS2-Portable/tree/main/Solidworks/Output) folder contains a 3D printed tool that could help you.

### Sanding Tool
In case you want to fill and paint the outer housing I made a tool for sanding the action button & DPAD cavities. It has the same curvature and you can just adhere a piece of sandpaper to it using double-sided tape. You can also find it in the [Output](https://github.com/tschicki/PS2-Portable/tree/main/Solidworks/Output) folder.

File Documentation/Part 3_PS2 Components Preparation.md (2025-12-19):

# Part 3: PS2 Components Preparation
This part of the assembly documentation will describe how to salvage the required PS2 components for the portable PS2.

General tips for the procedure:
- This process will generate lots of toxic solder fumes, so a proper fume extractor and sufficient ventilation are highly recommended!
- While I always touch flux and isopropanol with bare hands, you should know better than me and wear protective gloves!
- Testing a SCPH-9000x mainboard with its internal power supply in a non- or partially assembled housing can expose you to mains voltage! Be very careful when handling the integrated power supply and absolutely avoid touching it as much as possible! Remember: those primary side capacitors can also shock you, even when the unit is unplugged!
- You can and will burn yourself during the procedure! Hot air is hot and soldering irons are hot (doh…)

I’m not a professional IC reballer and I’ve only done a handful of chips so far, so please take the below steps and tools with a grain of salt. If you own a BGA rework station you probably know better than me and should only read the below procedure for reference. If you have no reballing experience, it’s best to try the procedure on a broken mainboard first, as your first attempt is very likely to fail.

Following components of a PS2 **SCPH-7900x or SCPH-9000x** mainboard are to be salvaged:



> White: EE  
> Green: GS  
> Red: Clock PLL  
> Pink: Ethernet PHY  
> Blue: Mechacon  
> Yellow: DSP

Additionally, a USB A port of a PS2 **SCPH-7000x to SCPH-7900x** is required. **DO NOT** use the port of a SCPH-9000x! It is physically different and while it fits the custom mainboard, due to its height distribution it will not fit below the screen!



> On the right is a SCPH-7900x USB port -> WILL FIT  
> On the left is a SCPH-9000x USB port -> WILL NOT FIT!

## Recommended Tools:
The below tools act mainly as a suggestion, you can of course use everything that gets the job done.

-	Temperature controlled (reflow) oven
-	Hot air station (e.g. ATTEN ST-862D), use the biggest possible nozzle
-	IR preheater (e.g. AOYUE 853A)
-	Soldering iron with a high heat capacity tip (for solder wick)
-	Thermometer, ideally with 2 thermocouples rated min. 300°C
-	Vacuum pickup tool (not absolutely needed, but very handy)
-	Reballing fixture for 90x90mm stencils - the common rose-gold ones work well
-	Custom EE, GS and Mechacon stencils, see the tools section in [Part 1](https://github.com/tschicki/PS2-Portable/blob/main/Documentation/Part%201_Mechanical%20Components%20Preparation.md)
-	A microscope, up to 45x magnification
-	All the usual stuff: tweezers, scalpel, Kapton tape, …

## Recommended Materials:
-	0.55mm leaded solder balls
-	Solder, preferably leaded
-	Solder wick
-	Isopropanol 99%
-	Flux, lots of flux. The tacky stuff. Stirri ASM-TF works well.
-	A SCPH-7900x or SCPH-9000x mainboard, obviously

## Procedure

### Before Starting:
-	Make sure you have a **SCPH-7900x or SCPH-9000x** mainboard revision!
-	**IMPORTANT:** Before starting, ensure that the mainboard is fully functional

### Preparation Baking:
1.	Bake the mainboard at 110°C for about 5 hours to remove any moisture from components and PCB.   
    This is important to reduce the likelihood of delamination or popcorning of the EE and GS substrates during reballing and reflowing.
2.	After baking, give the mainboard a quick test to ensure it still works.
3.	In case the chip removal doesn’t happen right after baking, seal the mainboard in an ESD bag, preferably together with desiccant.

### Component Removal:
1.	Place the mainboard on the preheater, preferably mount a thermocouple on the bottom layer for monitoring.
2.	Place another thermocouple on the top layer, if possible try to stick it below or next to the EE, as this is the hardest chip to remove.
3.	Securing the thermocouples with Kapton tape works quite well
4.	Using the preheater, heat the bottom thermocouple to around 220°C, give it a couple of seconds for the heat to transfer through the board.
5.	Heat up the EE using hot air, try to keep the top thermocouple below 300°C to stress the chips as little as possible. A good starting point for the hot air station would be 90% airflow at 360°C.  
    Focus on the EE first, heat it in a circular motion and carefully poke it with the tweezers until you can push it.
6.	Using a vacuum pickup tool (or tweezers if you’re skilled) remove the EE from the board and place it on something with low thermal conductivity and low surface area to reduce the thermal shock. I like to use an empty electrical tape roll for that.
7.	Continue heating the GS the same way, as the board is already on temperature it will be much easier to remove than the EE. Remove it the same way as the EE and put it aside.
8.	Continue with the remaining chips, I recommend the following sequence: Mechacon, Clock PLL, Ethernet PHY and DSP last.
9.	Again, avoid thermal shocks for all chips.
10.	For EE, GS and Mechacon: apply a good amount of flux and leaded solder to the solder balls and clean them up using solder wick. Use the lowest possible soldering iron temperature (between 250 and 300°C), a tip with high thermal mass makes this much easier.  
    And very important: do not apply pressure when wiping the chips with the solder wick!
11.	Make sure that the pads are absolutely clean from solder, any bump or leftover piece will increase the risk of failure later!
12.	Also clean up the remaining QFP chips with leaded solder, flux and wick
13.	Clean all chips thoroughly with 99% isopropanol.

### Reballing:

> - This applies only to EE, GS and Mechacon, the steps are the same for all three  
> - A generic stencil may be used (assuming all unused holes are masked), but I highly recommend the custom designed stencils for all three chips.  
> - It is very important to keep all the equipment and tools as clean as possible! Thoroughly clean the BGA fixture, stencils, tweezers and everything that touches the solder balls using 99% isopropanol. 
> - Do this after every chip and as often as possible! The solder balls stick to everything that’s even slightly contaminated, which will make this much more difficult!  
> - NEVER EVER put contaminated solder balls back into the jar of fresh ones!

1.	Place the chip and respective stencil in the fixture, align them.
2.	Drop a solder ball in each corner and adjust the height of the stencil, so the balls are held in place, but do not protrude too much from the stencil (I’d say approx. 1/3 of the ball’s height can protrude)
    - When the stencil is too high, the solder balls may start moving below the stencil and contaminate everything with flux later
    - When the stencil is too low, the solder balls might jump out of their holes again and contaminate everything with flux.
    - Both results most likely end up with solder balls sticking to the stencil instead of the chip, or moving during stencil removal -> leads to a lot of manual rework with tweezers!
3.	When the height was set, lift the stencil and apply a thin layer of tacky flux over the whole bottom surface of the chip, make sure you don’t miss any pads! Easiest to do with your finger
    - Make sure the chip is absolutely clean before applying flux! No residue, no dust, no hairs!
4.	Place the chip in the fixture again and close it
5.	Drop in a bunch of solder balls and ensure that all holes are filled with exactly one ball
6.	Give the lid a tiny wiggle in both X and Y directions and carefully lift it up
7.	If you’re skilled and/or lucky, all solder balls are in place and perfectly aligned
8.	If not -> either arrange the bad solder balls manually with tweezers or clean everything off and restart
9.	Place the chip on the preheater, I usually use a leftover stencil as a tray for it to sit on
    - I usually pick the chip up using tweezers in one of the corners (all 3 have a missing pad in every corner)
    - Do not bump the chip anymore! The slightest bump might push the solder balls out of alignment!
    - I usually set my preheater to 320°C for reballing
    - Be careful with heating when using a stencil as a tray, it warps
10.	Heat up the chip to about 150-200°C with the preheater and slowly hover over all solder balls using hot air
    - BE VERY CAREFUL WITH THE AIRFLOW! Too high and you will blow the solder balls out of position! Worst case they merge, which is a real pain to fix!
    - Recommended hot air setting (applies to ST-862D): 320°C, 10% airflow
11.	Carefully observe all solder balls, they turn shiny and move slightly when they are melting. When you think all are molten, keep applying the heat for a couple of seconds to ensure all solder balls connect to their pad. Lastly, carefully apply some drops of flux spread over the chip to reach all solder balls. This prevents them from turning dull and wrinkled, and increases the chance of them not falling off during cleaning.
12.	When everything is done, carefully remove the chip from the preheater and place it aside to allow the solder balls to solidify. Again, place it on something with low thermal conductivity to allow the chip to cool down slowly.
13.	When the chip is at room temperature, clean it CAREFULLY using 99% isopropanol. No force at all to not rip off any of the solder balls! A fine ESD safe brush works well. Make sure to remove every little piece of dust to increase the chance of a working mainboard!
14.	When everything is done, bake all chips again for an hour at 110°C

### Obtaining the USB A Port:
1.	As mentioned, make sure you get a mainboard with the right type of USB A port
    - In general, I have seen them on all slim models prior to the SCPH-9000x
    - Make sure you have the right port, compare it to the picture above! The position of the mounting pins when looking into the port are the best way to spot which port you have!
2.	Remove the port, try to keep it in one piece and don’t melt the plastics.
3.	Remove all the solder on the pins using solder wick and clean the port using 99% isopropanol

### Inspection and Packaging: 
1.	Do a final inspection under a microscope. 
    - Check that all solder balls are in place and have the same size. You can also carefully wipe the underside of the chip on some paper; any protruding solder balls will leave very visible lines. This is not very ESD safe, though.
    - The solder balls shall be round and shiny, not dull and wrinkled
    - No flux residue
    - If you spot any soldering defects on the BGA solder balls, you should probably start with a new console. Reflowing the same chips again will reduce the chance of success.
2.	Make sure to remove every piece of dust and hair under the microscope, especially for the BGAs.
3.	Inspect the DSP for bent, missing or shorted pins
    - Slightly bent pins can easily be fixed, for badly bent pins there is a high chance of breaking them while fixing. Lots of DSP pins are unconnected, so in case you do break a pin it might still be salvageable -> check the schematic in that case!
    - Be very careful when handling the DSP in general, the pins are easy to bend
4.	Package all components in an ESD safe bag, together with some desiccant 

## Result:
When everything is done, you should end up with the following components:


 
Package them in ESD & humidity safe packaging: 



# End
You now have all the PS2 components you need for assembling the PS2 AIO Mainboard!

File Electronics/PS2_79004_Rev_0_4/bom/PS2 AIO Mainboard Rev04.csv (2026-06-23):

 | References | Value | Footprint | Part Number | Quantity
1 | C207, C208, C306, C309, C314, C318, C325, C328, C401, C510, C511, C512, C513, C516, C517, C518, C519, C532, C601, C602, C606, C607, C608, C609, C610, C611, C612, C613, C614, C615, C801, C805, C810, C901, C905, C906, C907, C908, C909, C910, C911, C912, C913, C914, C916, C917, C918, C919, C920, C921, C922, C923, C924, C925, C926, C927, C928, C929, C930, C931, C932, C933, C934, C935, C936, C937, C938, C939, C944, C1301, C1401, C1403, C1404, C1405, C1406, C1407, C1408, C1409, C1503, C1504, C1507, C1601, C1602, C1701, C1702, C1802, C1803, C1804, C1805, C1806, C1807, C1808, C1809, C1810, C1811, C1813, C1814, C1815, C1816, C1817, C1818, C2001, C2004, C2005, C2006, C2007, C2008, C2101, C2102, C2104, C2108, C2109, C2110, C2111, C2113, C2116, C2117, C2201, C2203, C2204, C2206, C2207, C2209, C2210, C2213, C2215, C2216, C2217, C2218, C2219, C2220, C2221, C2222, C2223, C2224, C2225, C2226, C2227, C2229, C2230, C2231, C2232, C2233, C2234, C2235, C2236, C2237, C2502, C2903, C3005, C3006 | 100n | C_0402_1005Metric | CC0402KRX7R7BB104 | 151
2 | C2603, C2604, C2605, C2606, C2607, C2609, C2610, C2611, C2612, C2613, C2614, C2615, C2616, C2617, C2619, C2620, C2621, C2622, C2623, C2624, C2802, C2803, C2804, C2805, C2806, C2807, C2808, C2809, C2810, C2811, C2812, C2813 | 100n | C_0201_0603Metric | GRM033Z71C104KE14D | 32
3 | C301, C302, C303, C304, C305, C307, C316, C319, C320, C321, C322, C323, C501, C502, C1801, C1812, C2103, C2501 | 10u | C_0805_2012Metric | TMK212BBJ106MGHT | 18
4 | C504, C505, C507, C508, C521, C522, C523, C524, C533, C536, C537, C942, C943, C2211, C2214, C3001, C3002, C3003 | 22u | C_0805_2012Metric | GRM21BR61A226ME44L | 18
5 | C203, C204, C205, C206, C605, C616, C806, C809, C2107, C2114, C2115, C2118, C2119, C2202, C2205, C2208 | 1u | C_0603_1608Metric | CL10B105KA8NNNC | 16
6 | C308, C503, C506, C509, C528, C529, C530, C531, C534, C535, C538, C2601, C2608, C2801, C2814, C3004 | 4u7 | C_0603_1608Metric | CL10A475KO8NNNC | 16
7 | C201, C202, C1402, C2002, C2003, C2105, C2106, C2112, C2504 | 2u2 | C_0805_2012Metric | GRM21BR71E225KE11L | 9
8 | C313, C803, C808, C811, C1303, C2212, C2228, C2301, C2503 | 1n | C_0402_1005Metric | CC0402KRX7R9BB102 | 9
9 | C326, C327, C525, C807, C902, C903, C904, C915, C940 | 10n | C_0402_1005Metric | CC0402KRX7R8BB103 | 9
10 | C941, C2401, C2402, C2403, C2404, C2405, C2406, C2407 | 100p | C_0402_1005Metric | CC0402KRX7R9BB101 | 8
11 | C514, C2602, C2618, C2625, C2626, C2627, C2628 | 220n | C_0402_1005Metric | CC0402KRX5R8BB224 | 7
12 | C312, C315, C317, C324, C2901, C2902 | 470n | C_0603_1608Metric | GCM188R71E474KA64D | 6
13 | C603, C604, C1505, C1506 | 15p | C_0402_1005Metric | CC0402JRNPO9BN150 | 4
14 | C802, C804, C1302 | 5p | C_0402_1005Metric | CC0402BRNPO9BN5R0 | 3
15 | C310, C311 | 47n | C_0402_1005Metric | AC0402KRX7R9BB473 | 2
16 | C526, C527 | 47u | C_0805_2012Metric | CL21A476MQYNNNG | 2
17 | C515 | 22n | C_0402_1005Metric | GCM155R71H223KA55D | 1
18 | C520 | 270p | C_0402_1005Metric | GRM155R71H271KA01D | 1
19 | R202, R205, R311, R313, R406, R604, R606, R614, R616, R1304, R1305, R1307, R1504, R1505, R1507, R1508, R1510, R2001, R2307, R2401, R2402, R2403, R2404, R2405, R2406, R2408, R2409, R2411, R2412 | 1k | R_0402_1005Metric | RC0402FR-071KL | 29
20 | R402, R403, R405, R407, R501, R508, R605, R615, R1201, R1202, R1501, R1502, R1503, R1514, R1601, R2102, R2501, R2701, R2702, R2703, R2704, R2705, R2706, R2707, R2708, R2709, R2710, R2711 | 10k | R_0402_1005Metric | RC0402JR-0710KL | 28
21 | R304, R305, R314, R315, R1301, R1302, R1303, R1306, R1509, R2301, R2302, R2303, R2304, R2305, R2306, R2308 | 68R | R_0402_1005Metric | RC0402FR-0768RL | 16
22 | R203, R206, R207, R211, R309, R401, R404, R507, R607, R610, R2101 | 100k | R_0402_1005Metric | ERJ-U02F1003X | 11
23 | R208, R209, R301, R601, R608, R609, R611, R612, R613 | 2k2 | R_0402_1005Metric | RC0402FR-072K2L | 9
24 | R204, R509, R2407, R2410, R2413, R2414 | 15k | R_0402_1005Metric | ERJ-2RKF1502X | 6
25 | R602, R603, R801, R802, R1506, R2901 | 22R | R_0402_1005Metric | RC0402FR-0722RL | 6
26 | R502, R503, R504, R505 | 42k2 | R_0402_1005Metric | ERJ-2RKF4222X | 4
27 | R201, R1701, R1702 | 560R | R_0402_1005Metric | RC0402FR-07560RL | 3
28 | R302, R303, R2902 | 12k | R_0402_1005Metric | ERJ-2RKF1202X | 3
29 | R510, R1512, R1515 | 45k3 | R_0402_1005Metric | RC0402FR-0745K3L | 3
30 | R210, R306 | 100R | R_0402_1005Metric | RC0402JR-07100RL | 2
31 | R317, R318 | 68R | R_0603_1608Metric | ERJ-UP3J680V | 2
32 | R1513, R2002 | 1K5 | R_0402_1005Metric | RC0402FR-071K5L | 2
33 | R307 | 30k | R_0402_1005Metric | RC0402FR-0730KL | 1
34 | R308 | 5k23 | R_0402_1005Metric | RC0402FR-075K23L | 1
35 | R310 | 270R | R_0805_2012Metric | ERJ-P06J271V | 1
36 | R312 | 0R01 | R_1206_3216Metric | LVK12R010DER | 1
37 | R316 | 10R | R_0402_1005Metric | RC0402JR-0710RL | 1
38 | R506 | 6k8 | R_0402_1005Metric | ERJ-2RKF6801X | 1
39 | R1511 | 1M | R_0402_1005Metric | RC0402FR-071ML | 1
40 | R2003 | 1K2 | R_0402_1005Metric | RC0402FR-071K2L | 1
41 | R2502 | 5R6 | R_0402_1005Metric | RC0402FR-075R6L | 1
42 | L501, L502, L503, L504 | 2u2 | L_Coilcraft_XGL4020 | EXLA1V0402-2R2-R | 4
43 | L301 | 1uH | L_TDK_SPM6530 | SPM6530T-1R0M120 | 1
44 | L505 | 1u | SPM5030T-1R0M | SPM5030T-1R0M | 1
45 | L2501 | 4u7 | IND_TAIYO_NRS4012_TAY | NRS4012T4R7MDGJ | 1
46 | D201, D202, D3001, D3002 | ESDA25W | SOT-323_SC-70 | ESDA25W | 4
47 | D203, D401, D402, D2501 | D_Schottky | SOD-923_0P6X0P85_ONS | NSR0240P2T5G | 4
48 | D1501 | Power LED | LED_Lite-ON_LTST-C155 | LTST-C155KGJRKT | 1
49 | U801, U901, U1401, U1801, U2001, U2201 | 627G04LF, CXD2976GB, CXR726080, CXD3098AQ, BCM5241, CXD2980 | TSSOP-16_4.4x5mm_P0.65mm, PS2_CXD2976GB_35.0x35.0mm_P1.0mm, BGA-169_14.0x14.0mm_Layout13x13_P1.0mm, PS2_CXD3098AQ_208_28x28mm_P0.5mm, LQFP-48_7x7mm_P0.5mm, PS2_CXD2980CGB_23.0x23.0mm_P1.0mm | get from PS2 79k/90k | 6
50 | U502, U503, U504, U505 | TPS629210 | SOT-583 | TPS629210DRLR | 4
51 | U203, U2101 | TXS0102DQE | X2SON-8_1.4x1mm_P0.35mm | TXS0102DQE | 2
52 | U508, U509 | TLV75518PDRV | WSON-6-1EP_2x2mm_P0.65mm_EP1x1.6mm | TLV75518PDRV | 2
53 | U601, U2102 | 74LVC1G07 | Texas_USON-6_1x1.45mm_P0.5mm_SMD | SN74LVC1G07QDRYRQ1 | 2
54 | U1501, U2701 | APX811-31UG | SOT-143 | APX811-31UG-7 | 2
55 | U1701, U1702 | 74LVC1G08 | SOT-353_SC-70-5 | SN74LVC1G08DCK | 2
56 | U201 | TVS2200DRV | WSON-6-1EP_2x2mm_P0.65mm_EP1x1.6mm | TVS2200DRVR | 1
57 | U202 | STUSB4500 | QFN-24_EP_4x4_Pitch0.5mm | STUSB4500QTR | 1
58 | U301 | BQ25792B | BQ25792RQMR | BQ25792RQMR | 1
59 | U302 | MAX17320 | TQFN-24-1EP_4x4mm_P0.5mm_EP2.6x2.6mm | MAX17320G20+ | 1
60 | U501 | MPQ8626GD | MPQ8626GD-Z | MPQ8626GD-Z | 1
61 | U506 | AP22653A | SOT-23-6 | AP22653AW6-7 | 1
62 | U507 | TLV75525PDRV | WSON-6-1EP_2x2mm_P0.65mm_EP1x1.6mm | TLV75525PDRV | 1
63 | U602 | W25Q128JVPIQ | WSON-8-1EP_6x5mm_P1.27mm_EP3.4x4.3mm | W25Q128JVPIQ | 1
64 | U603 | RP2040 | QFN-56-1EP_7x7mm_P0.4mm_EP3.2x3.2mm | RP2040 | 1
65 | U1601 | LM20BIM7 | SOT-353_SC-70-5 | LM20BIM7 | 1
66 | U1703 | S29JL064J55TFI000 | TSOP-I-48_18.4x12mm_P0.5mm | MX29LV640ETTI-70G | 1
67 | U2103 | LM49450 | WQFN-32-1EP_5x5mm_P0.5mm_EP3.1x3.1mm | LM49450SQ/NOPB | 1
68 | U2501 | TPS92360 | SOT-353_SC-70-5 | TPS92360DCKR | 1
69 | U2601 | T20F256I4 | BGA-256_14.0x14.0mm_Layout16x16_P0.8mm_Ball0.45mm_Pad0.32mm_NSMD | T20F256C4 | 1
70 | U2801 | IS45S32400F | BGA-90_8.0x13.0mm_Layout2x3x15_P0.8mm | IS42S32400J-6BL | 1
71 | Y601 | 12MHz | Crystal_SMD_3225-4Pin_3.2x2.5mm | FL1200112 | 1
72 | Y801 | 18.432MHz | Crystal_SMD_3225-4Pin_3.2x2.5mm | 7M-18.432MEEQ-T | 1
73 | Y1501 | 32.768kHz | Crystal_SMD_MicroCrystal_CM9V-T1A-2Pin_1.6x1.0mm | ABS05-32.768KHZ-9-T | 1
74 | Y1502 | 16,934MHz | Crystal_SMD_3225-4Pin_3.2x2.5mm | STDCRG2-16.9344M | 1
75 | X2901 | ASE-50MHz | Oscillator_SMD_Abracon_ASE-4Pin_3.2x2.5mm | ASE-50.000MHZ-E-T | 1
76 | F201 | Fuse | Fuse_1206_3216Metric | C1Q 3 | 1
77 | RN601, RN1301, RN1302, RN1303, RN1304, RN1305, RN1306, RN1307, RN1308, RN1309, RN2001, RN2301, RN2302, RN2303, RN2304, RN2305, RN2306, RN2307, RN2308, RN2309, RN2310, RN2311, RN2312, RN2313, RN2314, RN2315, RN2316, RN2317, RN2318, RN2319, RN2320, RN2321, RN2322, RN2323, RN2324, RN2325, RN2401, RN2402, RN2403, RN2404 | 68R | R_Array_Convex_4x0402 | YC124-JR-0768RL | 40
78 | FB2601, FB2801, FB2901 | 33R @ 100MHz | R_0402_1005Metric | BLM15PX330SN1D | 3
79 | Q301, Q302, Q303 | CSD17575Q3 | CSD17308Q3 | CSD17575Q3 | 3
80 | Q401, Q402, Q601 | DMN67D8L | SOT-23 | BSS138-TP | 3
81 | Q201 | Q_SI7223DN | PowerPAK1212-8_VIS | SI7223DN-T1-GE3 | 1
82 | Q403 | BSS84AK | SOT-23 | BSS84AK,215 | 1
83 | RN2002 | 51R | R_Array_Convex_4x0402 | YC124-JR-0751RL | 1
84 | J3002, J3004, J3005 | ETH, GAMEPAD LEFT, GAMEPAD RIGHT | DF40C-10DP-0.4V51_HIR, DF40C-10DS-0.4V51_HIR | DF40C-10DS-0.4V(51) | 3
85 | J301, J302 | BAT1, BAT2 | MOLEX_2082940020_2pin | 2082940020 | 2
86 | J2101, J2102 | LEFT SPEAKER, RIGHT SPEAKER | JST_SUR_BM02B-SURS-TF_1x02-1MP_P0.80mm_Vertical | BM02B-SURS-TF | 2
87 | J2103 | SJ-43504-SMT-TR | CUI_SJ-43504-SMT-TR | SJ-43504-SMT-TR | 1
88 | J2501 | Conn_01x40_MountingPin | CONN_62684402100ALF_AMP | 62684-402100ALF | 1
89 | J3001 | EXPANSION HDR | DF40C-40DS-0.4V | DF40C-40DS-0.4V(51) | 1
90 | J3003 | USB_A | PS2_USB_mid_mount | get from PS2 70k to 79k | 1
91 | J3006 | Debug | FTSH-107-01-F-DV-K-P-TR | FTSH-107-01-F-DV-K-P-TR | 1
92 | J3007 | 2328702-4 | TE_2328702-4 | 2328702-4 | 1
93 | P201 | CX90MW6-16P | CX90_632x232_HIR | CX90MW6-16P | 1

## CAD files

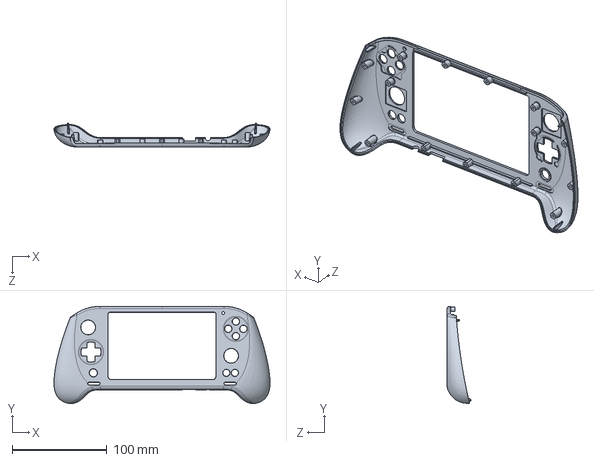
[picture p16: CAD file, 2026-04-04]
Solidworks/Output/Output Assembly/PS2 Main Housing Top REF2000 DesignSupports.SLDPRT
228.1 x 102.6 x 25.0 mm

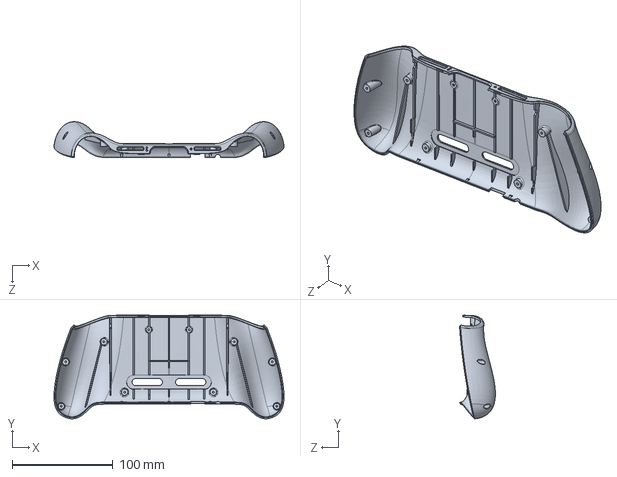
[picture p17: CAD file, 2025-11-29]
Solidworks/Output/Output Assembly/PS2 Main Housing Bot REF2001.SLDPRT
228.1 x 102.8 x 35.5 mm

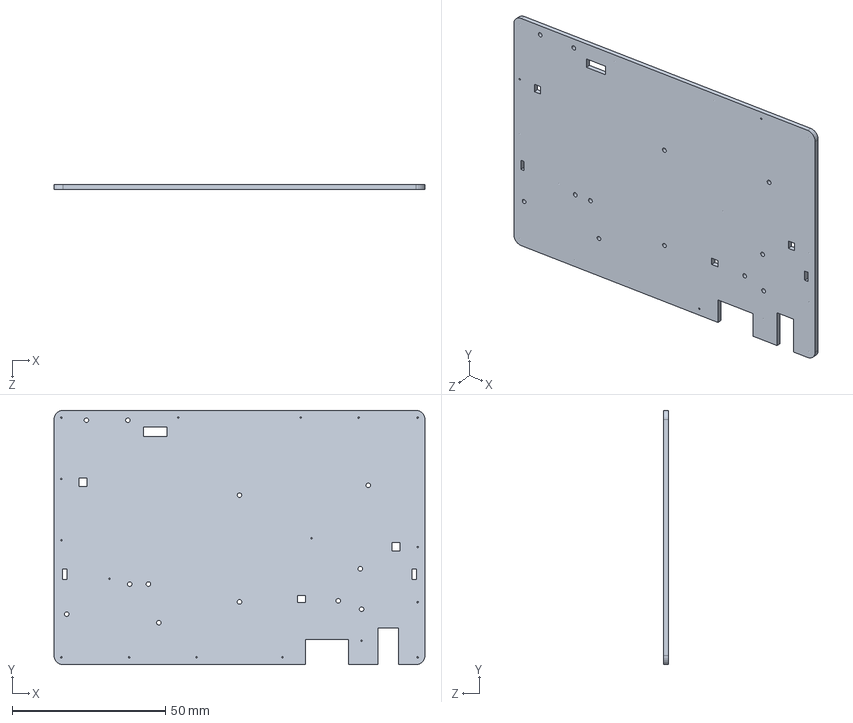
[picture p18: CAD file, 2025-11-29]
Solidworks/PS2_Mainboard_Outline.SLDPRT
121.0 x 83.0 x 1.60 mm

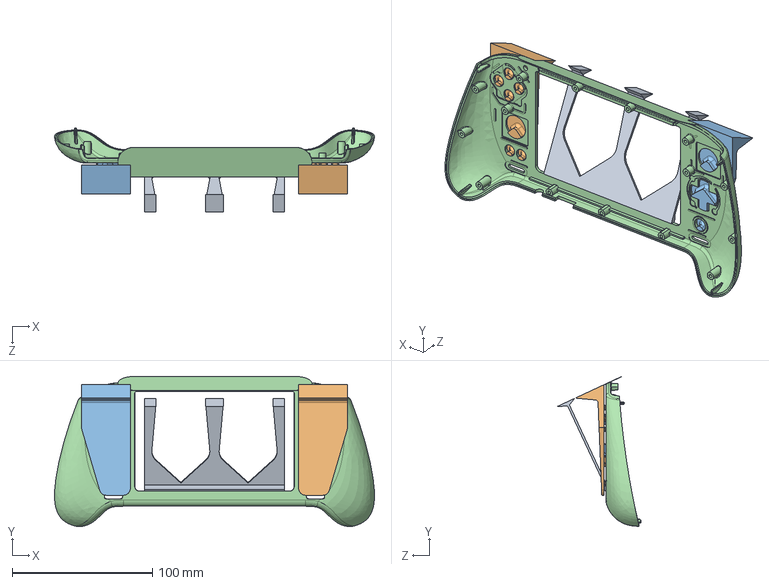
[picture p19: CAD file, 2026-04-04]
Solidworks/Output/STEP/PS2 Main Housing Top REF2000 DesignSupports.STEP
228.2 x 107.0 x 60.0 mm

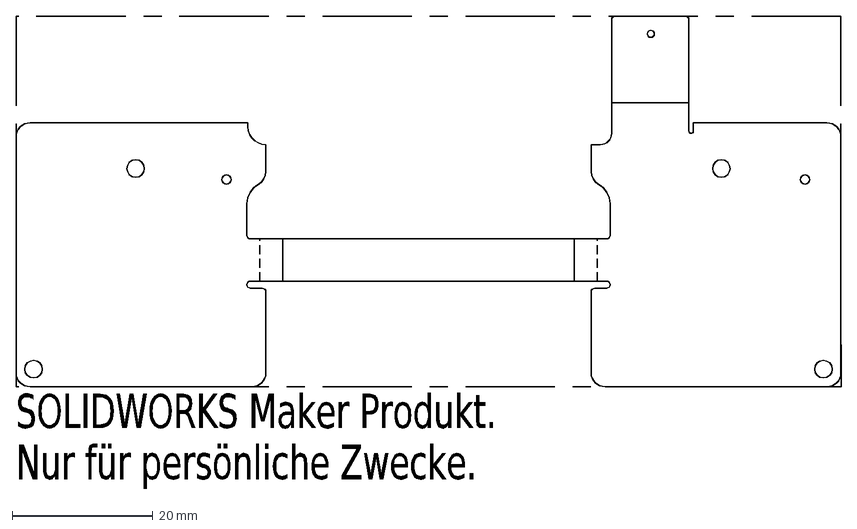
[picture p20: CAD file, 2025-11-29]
Electronics/PS2_memcard_flex/Abwicklung - memcard_flex.DXF
SOLIDWORKS Maker Produkt.
Nur für persönliche Zwecke.

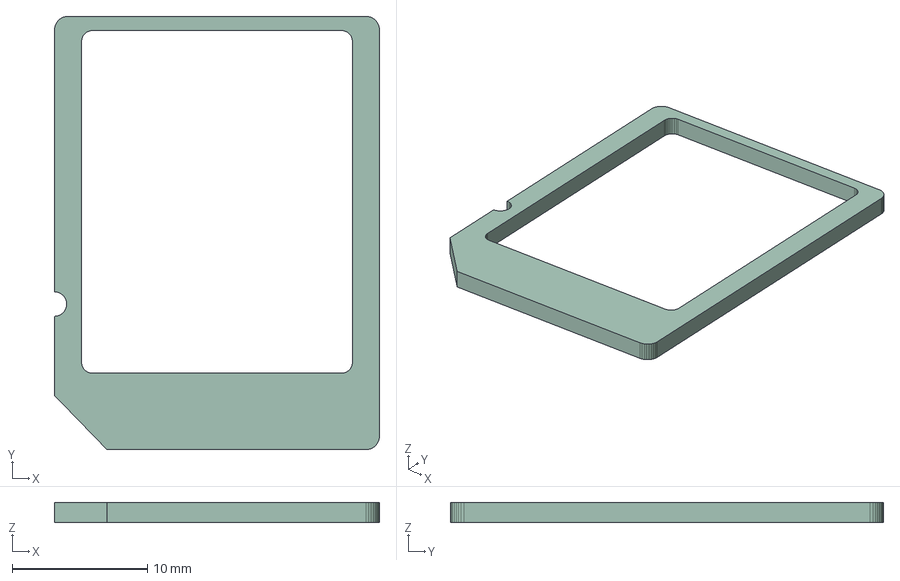
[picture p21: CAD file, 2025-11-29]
Electronics/PS2_SD_MemoryCard/SD_stiffener.step
24.0 x 32.0 x 1.48 mm

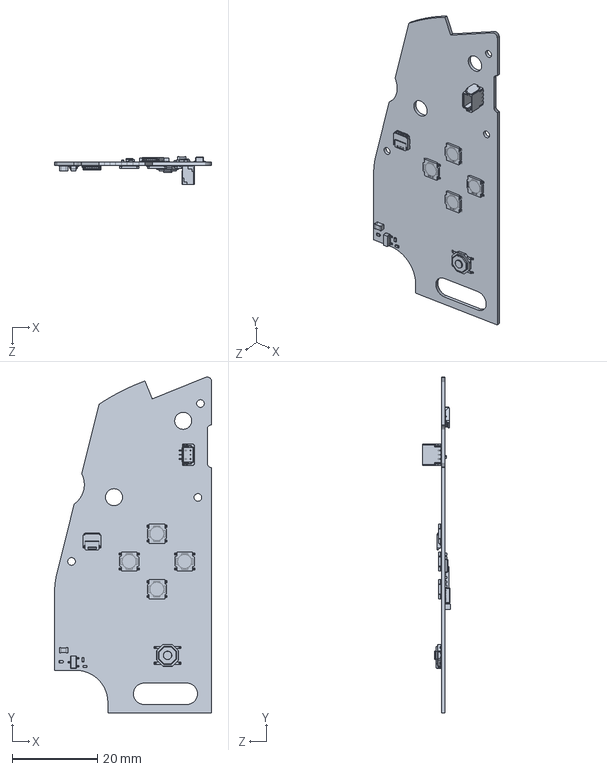
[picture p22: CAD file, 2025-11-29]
Solidworks/CBA_Export/Gamepad_Left_export.SLDPRT
36.8 x 78.7 x 6.50 mm

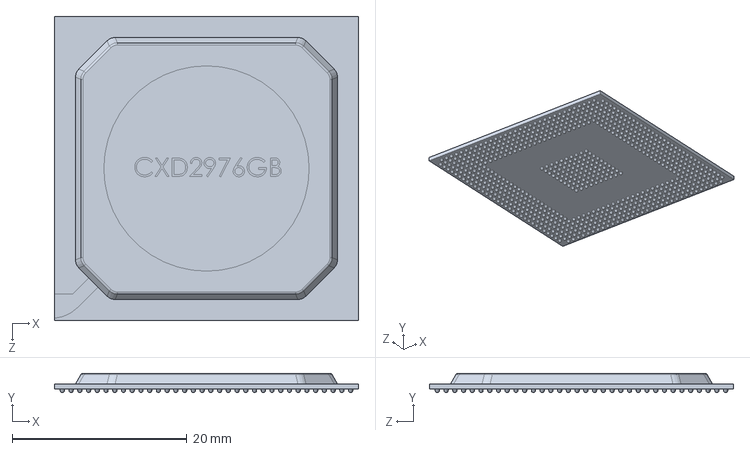
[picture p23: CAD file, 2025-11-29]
Solidworks/Mainboard/CXD2976GB.SLDPRT
34.8 x 2.20 x 34.8 mm

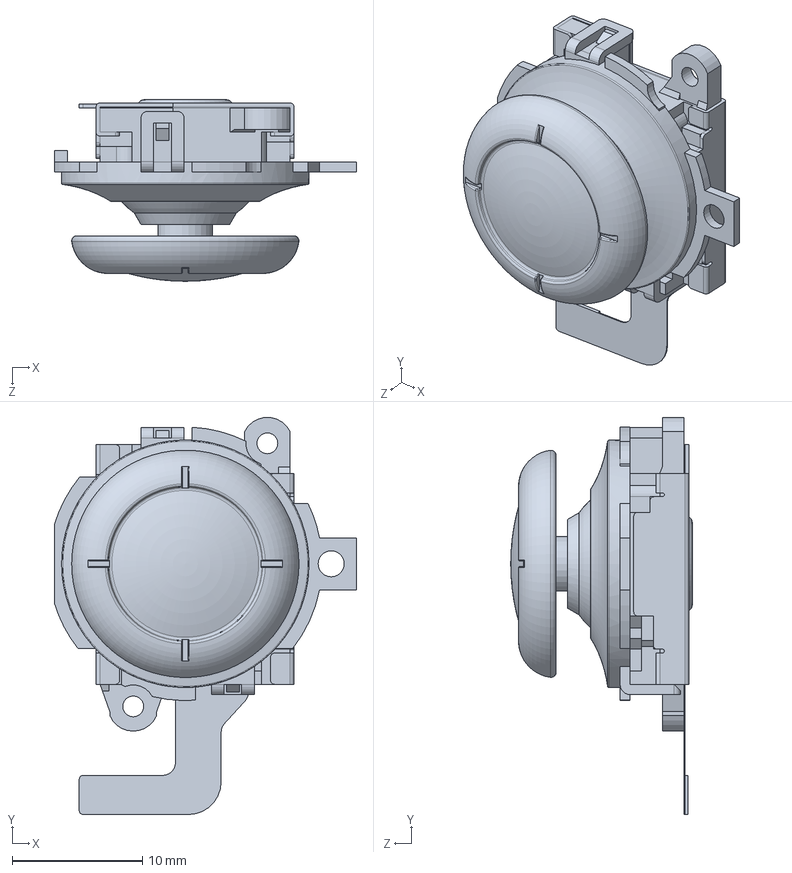
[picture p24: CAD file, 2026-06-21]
Solidworks/OTS_Parts/NS2_Analog_Stick.SLDPRT
23.2 x 30.5 x 14.0 mm

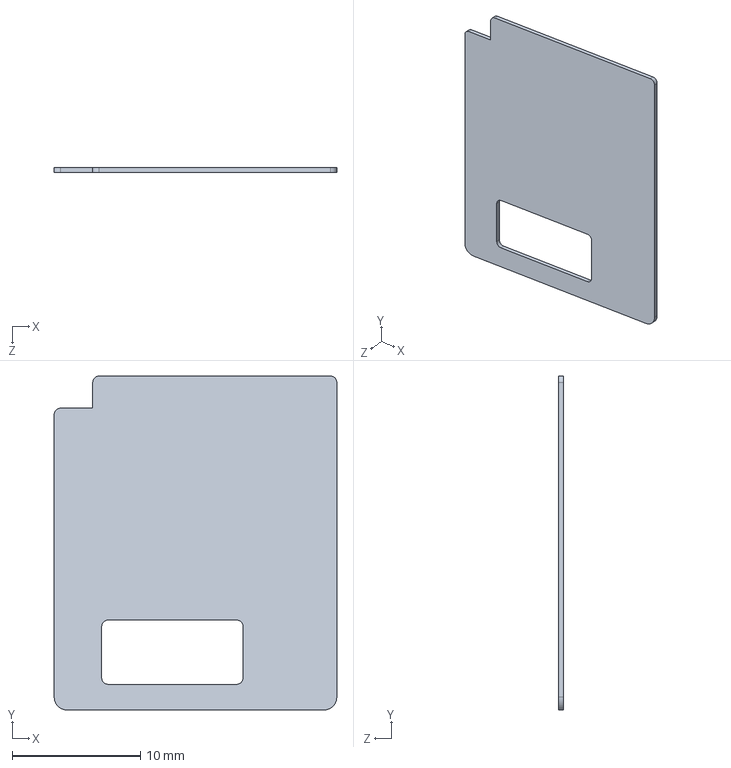
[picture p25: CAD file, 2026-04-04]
Solidworks/Output/STEP/uSD2PSX Stiffener REF2018.STEP
22.0 x 26.0 x 0.4 mm

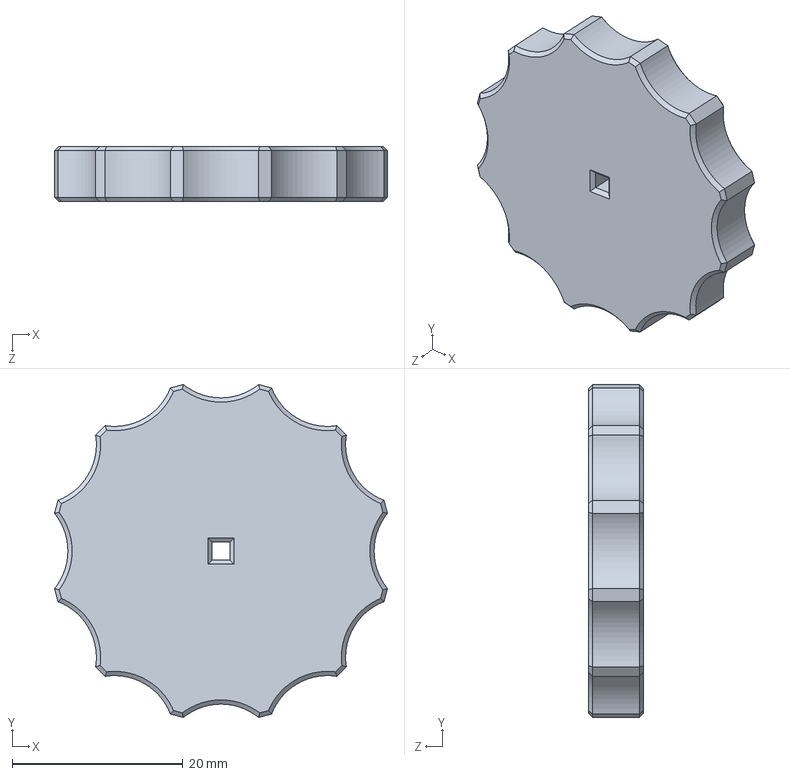
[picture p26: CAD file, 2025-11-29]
Solidworks/Tools/tapping_tool.SLDPRT
39.0 x 39.0 x 6.50 mm

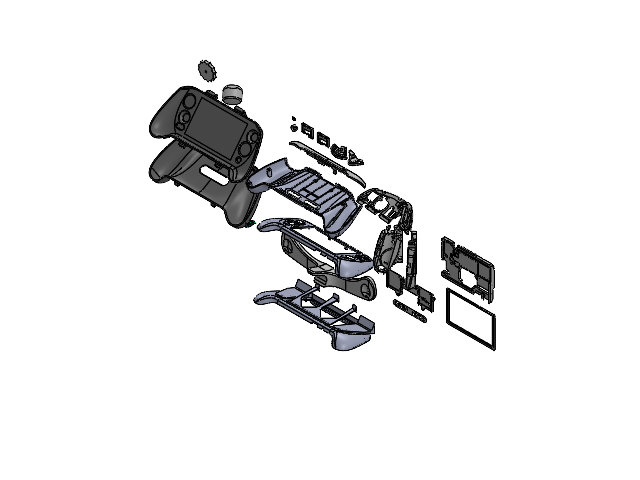
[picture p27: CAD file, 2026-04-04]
Solidworks/Output/Output Assembly/Export.SLDASM
Backside Vent Cover REF2014
Battery Compartment Left REF2004
Battery Compartment Right REF2005
Button Cover Left REF2002
Button Cover Right REF2003
L2 Button REF2011
Lower Display Mount REF2009
MemoryCard Cover REF2013
PS2 Heatsink REF3000
PS2 Main Housing Bot REF2001
PS2 Main Housing Top REF2000
R1-L1 Bar REF2010
R2 Button REF2012
Rumble Sleeve REF2015
Screen Lens Frame REF2008
Speaker Cover Left REF2006
Speaker Cover Right REF2007
Speaker Plug REF2016
Display Stand REF2019
Travel Case Bot REF2021
Travel Case Top REF2020
Travel Case Latch Left REF2022
Travel Case Latch Right REF2023
uSD2PSX Frame REF2017
uSD2PSX Stiffener REF2018
DPAD Sanding Tool
Heatsink Tapping Tool
PS2 Main Housing Top REF2000 DesignSupports

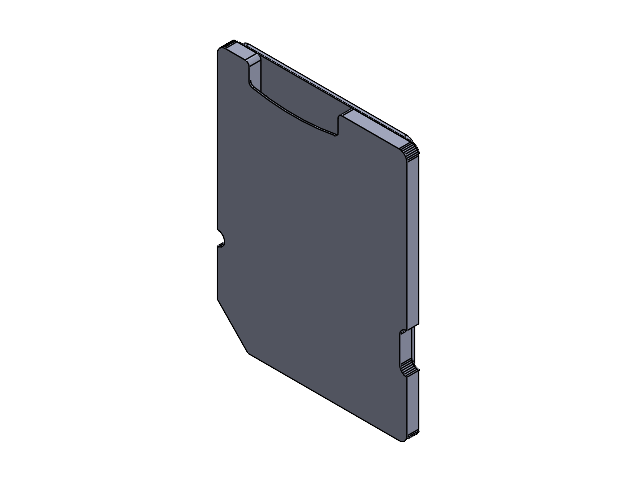
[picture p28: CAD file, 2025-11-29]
Solidworks/uSD2PSX/uSD2PSX_Assembly.SLDASM
uSD2PSX_PCBA
uSD2PSX_Frame
uSD2PSX_Base

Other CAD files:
Solidworks/Output/Output Assembly/PS2 Main Housing Top REF2000.SLDPRT
Solidworks/Output/STEP/PS2 Main Housing Top REF2000.STEP
Solidworks/Output/STEP/PS2 Main Housing Bot REF2001.STEP
Solidworks/Output/STL/Export - uSD2PSX Stiffener REF2018-1.STL
Solidworks/Speaker_Plug.SLDPRT
Electronics/PS2_SD_MemoryCard/SD_stiffener.SLDPRT
Electronics/PS2_SD_MemoryCard/SD_stiffener.STL
Solidworks/Button_Cover.SLDPRT
Solidworks/CBA_Export/Gamepad_Right_export.SLDPRT
Solidworks/Display_Stand.SLDPRT
Solidworks/Gamepad_Flex.SLDPRT
Solidworks/Gamepad_Outline.SLDPRT
Solidworks/Lower_Display_Mount.SLDPRT
Solidworks/Mainboard/5037630691.SLDPRT
Solidworks/Mainboard/CXD2980CGB.SLDPRT
Solidworks/Mainboard/CXD3098AQ.SLDPRT
Solidworks/Mainboard/CXR726080.SLDPRT
Solidworks/Mainboard/JST_BM02B-SURS-TF_DIY.SLDPRT
Solidworks/Mainboard/PS2_USB_A_90k.SLDPRT
Solidworks/Mainboard/TSOP50-II.SLDPRT
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

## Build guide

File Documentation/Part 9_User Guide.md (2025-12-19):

# Part 9: User Guide
This part of the assembly documentation will give you a couple of hints when it comes to using the portable.

## Power On and Off
- Long-press the PlayStation button to turn on the portable
- Long-presss the PlayStation button to turn off the portable. Turning off has a couple of seconds delay, so no worries if the system doesn't shut down right away!

## Charging and Discharging
> As with all Li-Ion powered devices:
> - Don't leave the system unattended while charging!  
> - Don't charge or use in hot environments! Room temperature recommended.
> - Don't use unnecessarily long USB cables for charging!

The portable supports USB-C PD charging with the following profiles:
- 5V 500mA (fallback if a USB-A charger or PC is plugged)
- 5V 3A
- 12V 3A
- 15V 3A

While the highest PDO could provide up to 45W in total, the portable is configured to charge at about 9W. During charge and play the portable is using about 15W.
For best compatibility choose a high-wattage adapter that supports up to 20V operation. If a power adapter doess not support the portable's power profiles, charging will fall back to 5V 500mA. 
From experience, USB-C chargers from laptops often don't work for charging the PS2 portable (looking at you, Dell). I personally use a UGREEN 65W dual-port USB-C charger, sometimes also a Steam Deck charger.

The RGB LED on the front is used as state-of-charge and status indicator. In normal usage and during charging it displays the state of charge using the following color gradients from 100% to 10% : dark blue (full) -> light blue -> green -> yellow (~50%) -> dark yellow -> orange -> red blinking(almost empty).
Currently there are two status LED patterns: 
- charging error: blinking red / blue; will block charging until USB cable is unplugged;
- low battery alert: blinking red; battery almost empty; Once the LED blinks red, you have about 30-45 minutes to save progress or find a charger.

## First Time Usage
For the first couple of charge cycles, the state of charge will not be very accurate. When you first use the PS2 portable, it is recommended to fully discharge it to about 6V. You find the battery voltage information in the General->PM Monitoring menu. Then you can fully charge it to 100%.
Do this for a couple of cycles and the state of charge accuracy should improve a lot!

## Menu
The config menu is kept very basic annd provides the most important settings. You enter it by short-pressing the PlayStation button while the PS2 is powered on. Note that the menu is only displayed when the PS2 outputs a valid video signal, i.e. it will not appear when the console is off or an unsupported resolution is displayed.

### Button mapping in the menu:
- Cross: selecting menu items and toggling some settings that can only be on or off
- Circle: going back to the previous menu page
- Up/Down: Selecting menu items
- Left/Right: Decrementing/Incrementing settings
- PlayStation button (short press): exiting the menu

Selected items are blue, deselected items are white.

### Main Menu:
- **SOC**: State of charge in %
- **CHARGE/DISCHARGE**: Charge and Discharge indicator. Will tell you whether a charger is plugged or not.
- **EE TEMP**: Emotion Engine temperature reading in °C. It's good to keep an eye on this when you're playing in a hot environment, the portable will shut down when the temperature reaches **50°C**.
- **Audio Settings**: Allows you to change the headphone and speaker volume
- **Video Settings**: Change resolutions, offsets, brightness, video motion threshold and more
- **Input Settings**: Perform analog stick calibration, invert sticks, set PS1 mode, adjust rumble
- **General**: Contains the power management monitoring and lets you check the estimated time to full/empty
- **Store Settings**: Pressing Cross to store the surrent settings in flash at the next shutdown. If successful will display 'OK' next to the entry.

### Audio Menu:
- **HP Volume**: HP stands for headphone. Setting to zero mutes headphone audio
- **SP Volume**: SP stands for speakers. Setting to zero mutes the speakers

### Video Menu:
- **Resolution Configs**: Configure resolutions and offsets for the currently displayed resolution.
- **Other Configs**: Change brightnesss, motion threshold, phase and other settings.
- **Current Resolution**: Displays the resolution your PS2 is currently outputting, for information only

The video settings are mirrored 5 times. There is a set of settings for the vertical resolutions 512i, 448i, 256p, 240p and 480p. Each set can be changed independently of the others and is only applied when that specific vertical resolution is displayed. Note that you always change the set of settings for the resolution that is shown in 'Current Resolution' (i.e. currently displayed).

#### Resolution Configs Menu
- **X Position**: Move the image left and right
- **Y Position**: Move the image up and down
- **Input Res X**: Change the active horizontal input resolution
- **Input Res Y**: Change the active vertical input resolution
- **Output Res X**: Change the horizontal bilinear scaler target resolution. To obtain 4:3 aspect ratio: set to 640 for NTSC, ~600 for PAL
- **Output Res Y**: Change the vertical bilinear scaler target resolution
- **MAGH**: Change the horizontal magnification and input resolution; If you notice that your game has vertical lines, try changing this value. Cannot be changed if 'MAGH Autodetect' is enabled

#### Other Configs Menu
- **Brightness**: Change display brightness from 0 to 100%
- **Horizontal Phase** : Configure in which clock cycle a pixel shall be sampled; this usually does nothing, but sometimes it can remove blurriness
- **Deinterlacer Debug** : When enabled, all pixels where motion is detected will be colored pink. This only works for interlaced inputs. Useful for tweaking the Motion Threshold.
- **Motion Threshold** : Sets the threshold for when the motion adaptive deinterlacer detects motion. Lower values will favor bob deinterlacing (more blurry and wobbly), higher values favor weave deinterlacing (more combing artefacts). Only applies to interlaced inputs.
- **MAGH Autodetect** : When enabled the system will try to automatically adjust the image settings according to the currently displayed horizontal resolution (640, 512, 384, 320,...). It's recommended to keep this enabled by default. 

### Input Settings Menu
- **Analog Stick Calibration**: Use this to configure the center point and min/max of both analog sticks. Launch the function and follow the instructions.
- **Invert Axis**: If you want to invert X/Y of either stick, use this function. Hold the stick in the axis you want to invert and press cross to invert it.
- **Deadzone**: Sets the analog stick deadzone (doh...). It's best to keep this below 10
- **PS1 Analog**: Useful for PS1 games. When enabled the left analog stick will be mapped to the DPAD
- **Rumble Intensity**: 0 is off and 3 is the strongest rumble. Only works if you installed rumble motors

### General Menu
- **About**: Self-explanatory
- **PM Monitoring**: Check battery power and voltage & TTF, TTE
- **Fan Low Temp**: Set the temperature where the cooling fan is off
- **Fan High Temp**: Set the temperature where the cooling fan is at 100%

The fan curve is linear between the lower and higher temperature limit.

#### PM Monitoring Menu
- **Battery Power**: A negative value indicates discharging and a positive one charging
- **Battery Voltage**: The Total battery pack voltage; useful for the first couple of discharge cycles
- **Time to Full**: More or less accurate, only applies when a charger is plugged
- **Time to Empty**: More or less accurate, only applies when a charger is unplugged

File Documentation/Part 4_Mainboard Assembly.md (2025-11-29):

# Part 4: Custom Mainboard Assembly
This part of the assembly documentation will describe soldering the *PS2 AIO Mainboard*.
The mainboard assembly and bringup is very challenging, plan for at least 10 hours if everything goes smoothly. There are a couple of options to assemble the mainboard, you could for example get the maonboard mostly populated by a supplier like JLCPCB or PCBWAY. Another approach would be to solder everything by hand using hot air, it's slower and more error-prone, but doable. The approach described here will require a reflow oven, it's from my experience the most reproducible way to populate the mainboard.

General tips for the procedure:
- This process will generate lots of toxic solder fumes, so a proper fume extractor and sufficient ventilation are highly recommended!
- While I always touch flux and isopropanol with bare hands, you should know better than me and wear protective gloves!
- Only touch the mainboard on the edges, try to not tough the ENIG plating with your bare fingers
- You can and will burn yourself during the procedure! Hot air is hot and soldering irons are hot (doh…)

## Recommended Tools:
The below tools act mainly as a suggestion, you can of course yuse everything that gets the job done.
-	Temperature controlled (reflow) oven
-	Pasting fixture
-	Soldering iron
-	Vacuum pickup tool
-	A microscope, up to 45x magnification
-	A good pair of precision tweezers
-	Multimeter
## Recommended Materials:
-	Top & bottom solder stencil for the mainboard; you should probably order it together with the mainboard
-	Solder paste, class 4 or 5; can be lead-free or leaded
-	Solder (lead-free or leaded)
-	Copper tape
-	Flux

## Procedure
The procedure is split into three main parts, I recommend you to take a break between each of them. First we will populate the bottom layer (~3h), then the top layer (~3h) and lastly measure the power rail impedances to GND (~1h), to get a good idea of whether the PS2 AIO mainboard would be functional.

### Bottom layer assembly
Before starting, carefully inspect the PCB under a microscope to spot possible defects early. Then apply solder paste to the bottom layer. The default stencil has no cutouts for the NOR flash, USB-C connector and clock PLL, these are best hand-soldered after doing the top layer. If your stencil does have these cutouts, consider to mask them.

Populate the bottom layer SMD components using the convenient HTML BOM file, except for the mentioned parts. The USB A socket will be done last, together the other components listed above.

> Take special care to orient all ICs and polarized components correctly. 
> Some parts might need to be checked under the microscope to spot the pin 1 indicator. 
> In case of doubt, consult the part’s datasheet and cross-check with the PCB layout. When the parts are placed, place the board in the reflow oven for the first reflow.

Place the mainboard in the reflow oven and inspect all connections under the microscope afterwards. Then apply copper tape over the LCD connector, battery connectors and gamepad connectors. This is to keep them from falling off, or melting during the top layer reflow. Alternatively, you could adhere these components to the board using specialized glue for SMD reflow. With this you are done with the bottom layer

### Top layer assembly
For pasting the top layer it is highly recommended to have a pasting fixture, as the underside of the mainboard is not flat anymore. On the default top layer stencil, all BGA ICs have no cutouts for the solder paste. 
Make sure to not get any solder paste onto the BGA pads! Proceed by populating all components except for the BGAs. Again, be careful with pin 1 indicators! 
The last components to be placed are the BGAs, here we need to take some more care:

- First clean all BGA pads using a Q-Tip slightly moistened in 99% isopropanol. 
- Verify under the microscope that no dust or hairs are on the BGA pads or the underside of the BGAs and then continue by spreading a thin layer of flux over **ALL** BGA pads. 
- Place the EE, GS, Mechacon, T20 and SDRAM in their intended position -> pin 1 indicator! Align them as good as possible using the silkscreen markings.

In case you have some doubts about orientations, you can refer to the reference pictures of the mainboard. This also applies to the debug header, don't populate it the wrong way around!
Once all parts on the top layer are placed, do a last thorough check under the microscope and place the mainboard in the reflow oven. As the underside is not flat anymore, it’s best to place the mainboard on some spacers inside the reflow oven, I usually use 6x M6 nuts. Do a reflow using a lead-free profile (T20 and SDRAM have lead-free solder balls) and let the mainboard cool down without thermal shocks.
Remove the copper tape and solder the remaining components by hand – Clock PLL, NOR flash, USB-C, USB-A. It’s very important that the NOR flash was already programmed with a PS2 BIOS – please refer to [Part 2](https://github.com/tschicki/PS2-Portable/blob/main/Documentation/Part%202_Boot%20ROM%20Preparation.md) for that. 
When soldering the USB-A socket, be very careful that it’s the correct style of connector and make sure to assembly it on the correct side (bottom!). After soldering the USB-C connector, there will most likely be some excess solder at the 6 mounting pads on the top layer. It's important that you remove all excess and make all 6 solder joints flush with the PCB, otherwise the heatsink will not sit flush here!

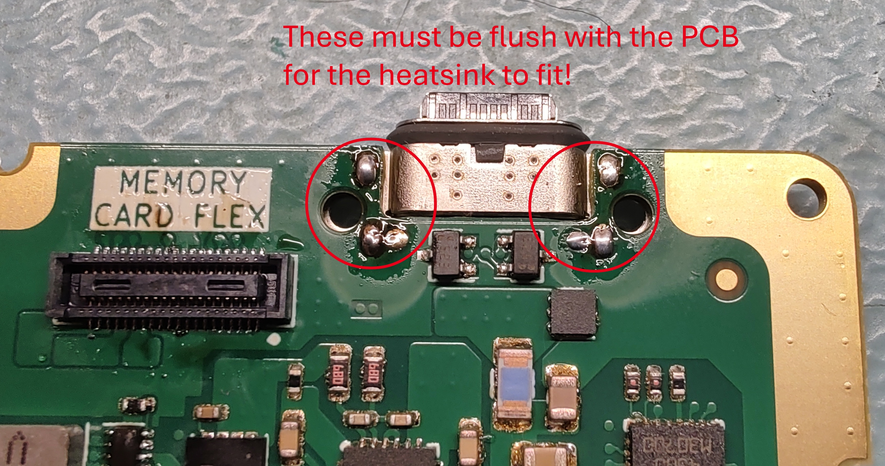
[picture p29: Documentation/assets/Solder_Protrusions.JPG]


At this point, all required components according to the mainboard’s BOM should be installed. Now go over the whole mainboard and inspect every solder connection. It’s very likely that some pins are shorted, while other pins might have no connection. Fix all faults you can find before proceeding, for the DSP it might help to gently push on every pin to see whether it is properly soldered to the board. Cleaning everything properly will help you spot issues!

> Be 100% sure that all solder connections are good before starting with the board bringup!

### Impedances
Before powering on the mainboard for the first time, check the resistances of all points in the table below. Make sure that no jumper on the bottom layer was closed yet.
Note: The resistances vary from console to console, so your measurements don’t need to exactly match the ones shown in the table. Just make sure you are within the same ballpark; the sample size is just too small currently. 
**It would be great if you could document the measured values for future reference.**

| Positive Probe | Negative Probe | Impedance |
|---|---|---|
|VBUS | GND | >50kΩ |
|VSYS | GND | >1MΩ |
|VPACK+ | GND | >1MΩ |
|BAT_POS | GND | >1MΩ |
|BAT_POS | BAT_CENT | >1MΩ |
|BAT_CENT | BAT_NEG | >1MΩ |
|VRTC | GND | >100kΩ |
|T20_1V2 | GND | ~500kΩ |
|T20_1V8 | GND | ~80kΩ |
|T20_3V3 | GND | ~50kΩ |
|PS2_3V3 | GND | ~3.4kΩ |
|PS2_2V5 | GND | ~40kΩ |
|PS2_1V8 | GND | ~3.7kΩ |
|PS2_1V | GND | ~30Ω |
|PS2_5V | GND | >1MΩ |
|5V_USB | GND | >1MΩ |
|SYS_3V3_SBY | GND | >9kΩ |

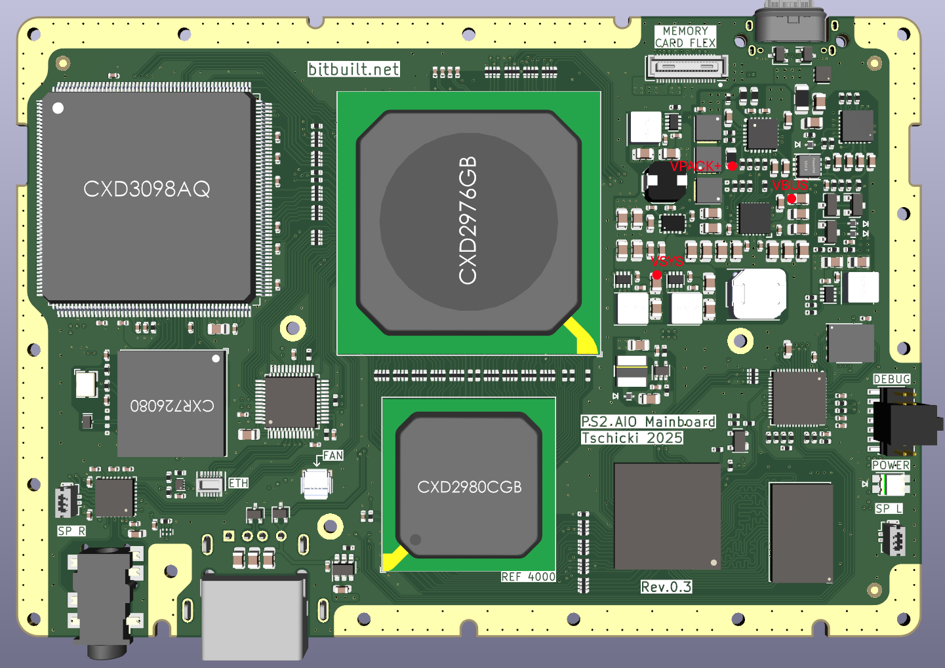
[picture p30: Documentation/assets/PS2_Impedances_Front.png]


*Mainboard front view with measurement points*

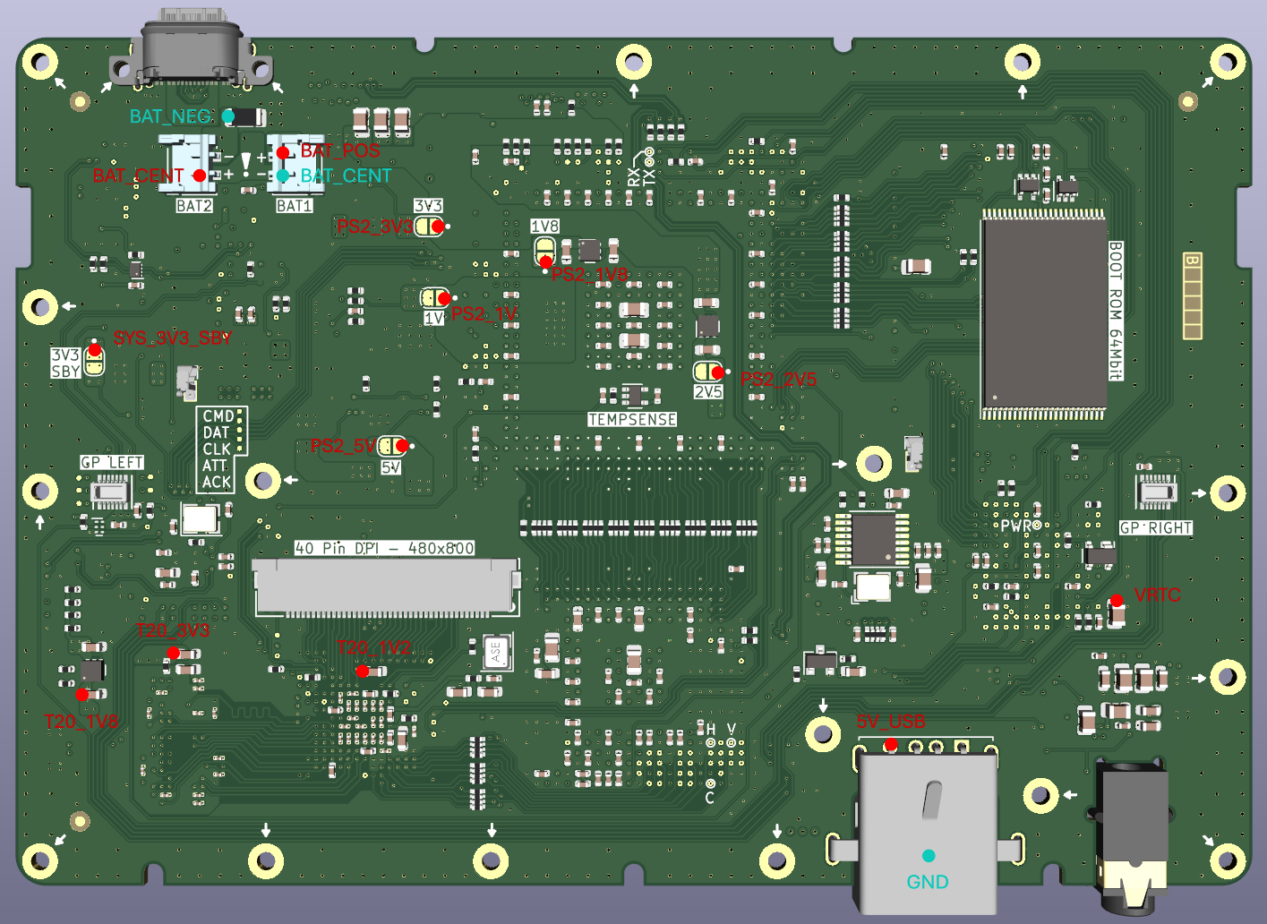
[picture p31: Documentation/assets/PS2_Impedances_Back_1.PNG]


*Mainboard backside view with measurement points*

### Final Touches
It's a good idea to retouch all SMD connectors with leaded or lead-free solder if you used low-temperature lead-free solder paste (the kind that contains Bismuth) for the assembly, as that type of solder is soft and not very robust.  
Especially the left and right gamepad connectors can be a bit fragile and it is recommended to add a small drop of epoxy to either side of the connectors in any case. Just try to not get it on the pins annd let it cure properly before proceeding.

## End
With all these steps done successfully, you have an assembled PS2 AIO mainboard in your hands. If the measurements look OK, you can continue with the next part.

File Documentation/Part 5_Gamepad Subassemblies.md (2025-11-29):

# Part 5: Gamepad Subassemblies
This part of the assembly documentation will describe how to assemble the left and right gamepad sub-assemblies. These connect to the PS2 AIO Mainboard via Mezzanine connectors and also contain the battery compartments and speakers.

## Recommended Tools:
- Soldering iron
- Side cutters
- Scalpel or similar
- Tweezers
- Tool for M1.6 heat set inserts
- Ruler
- Crimping tool IWS-0302BS
- Screw driver kit with at least a T5 bit

## Recommended Materials:
- Solder

## PCB Assembly
- Assemble the *Gamepad Left* (REF4001) and *Gamepad Right* (REF4002) PCBs with the parts of their electrical BOM. 
    - For the action buttons (cross, circle, square, triangle, up, down, left, right) it is up to the user to choose which variant of the tactile switches is appropriate. 160gf and 100gf work best, I personally prefer 100gf for all; 160gf will give more tactile feedback.
    - Check thoroughly for shorts and open connections, especially around the RP2040 and SPI flash. 
    - To be safe, also measure the resistance between VCC and GND (easiest at the bulk decoupling capacitor next to the flex connector). 
- Assemble the *R1 R2 Flex* (REF4006) and *L1 L2 Flex* (REF4007) with two **KSC222JLFS** tactile switches each.
- Assemble the *Gamepad Flex Left* (REF4004) and *Gamepad Flex Right* (REF4005) with two **DF40C-10DP-0.4V(51)** plugs each. 
    - Make sure you use the plugs (the ones with the additional mounting pins) and not the sockets!

> For the flex PCBs it is recommended to set your soldering iron temperature to ~250°C and to use leaded solder. The thin PEI dielectric can and will be damaged by high temperatures.

## Mechanical Assembly
The procedure may use left and right gamepad assembly interchangably. For the most part, both left and right sides are just mirrored and very similar to assemble. Where the procedures for left and right differ, both sides are described.

1. Plug the *Switch Analog Stick* (REF1013) into the respective FFC socket, as seen in the image below.

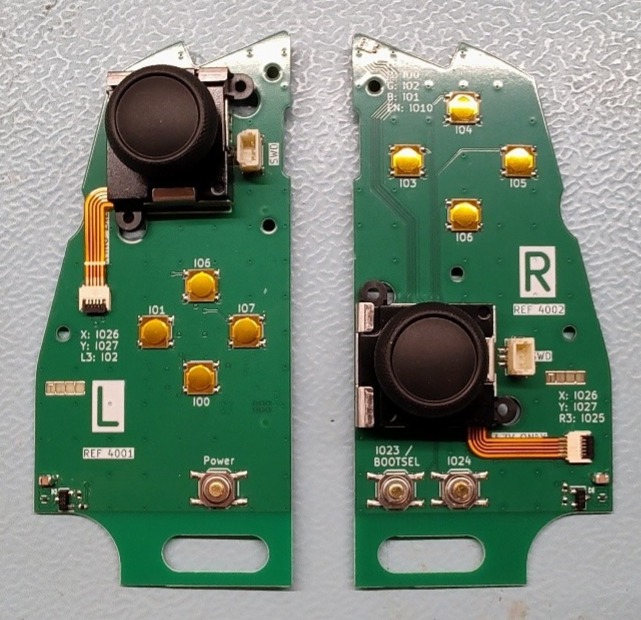
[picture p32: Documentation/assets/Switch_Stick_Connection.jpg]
    

2. Press the *Gamepad PCB* into the respective *Button Cover Left* (REF2002) or *Button Cover Right* (REF2003). If too much force is required, trim the three notches in the 3D printed part slightly using a scalpel.
3. Fixate the *Switch Analog Stick* using two screws. 
    - These screws are not yet specified, I usually use the screws that come with switch analog sticks. If they are too long, you may need to shorten them with sidecutters...

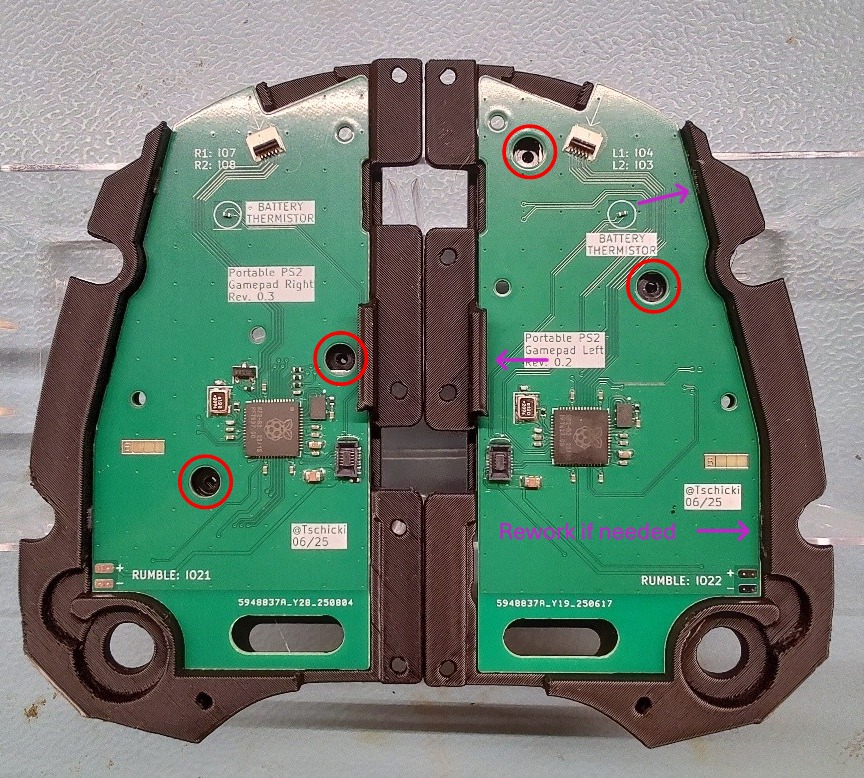
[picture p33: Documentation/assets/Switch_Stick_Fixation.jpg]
    

4. Connect the *Gamepad Flex* as seen in the image below. Make sure it is fully seated.
    - REF4004 is for the left side, REF4005 for the right side

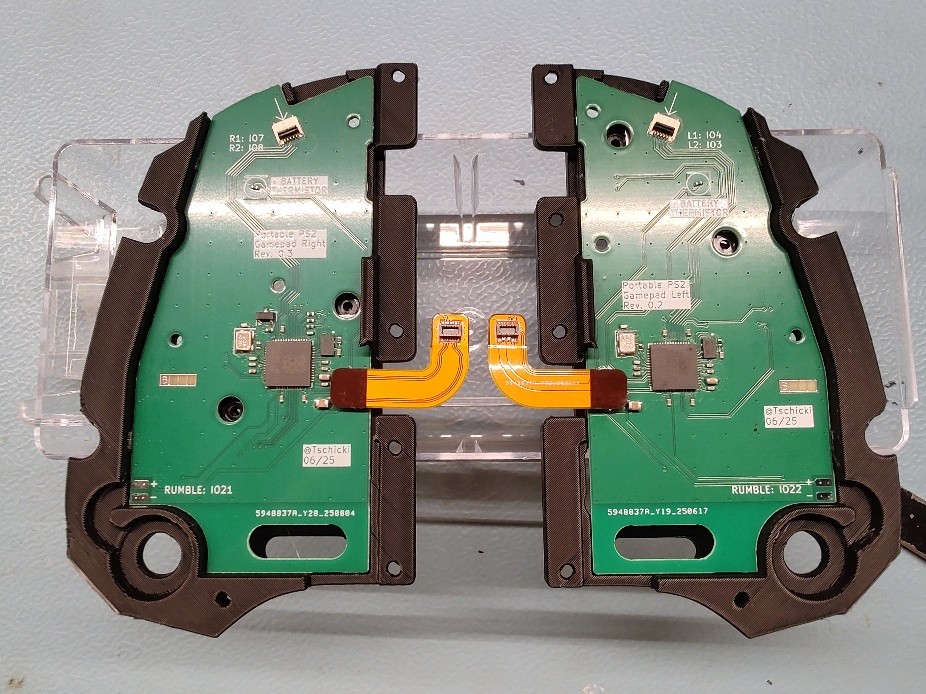
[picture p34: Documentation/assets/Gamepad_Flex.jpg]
    
 
5. Push the *Rumble Motor* (REF1004) into the *Rumble Sleeve* (REF2015). Remove the adhesive protector of the *Rumble Motor*. Test-fit the *Rumble Motor* in the Button cover to cut the wires to length. Pre-tin them and solder the wires to the rumble pads as seen in the image below.
    - This step is optional, omit if you don't want rumble support.

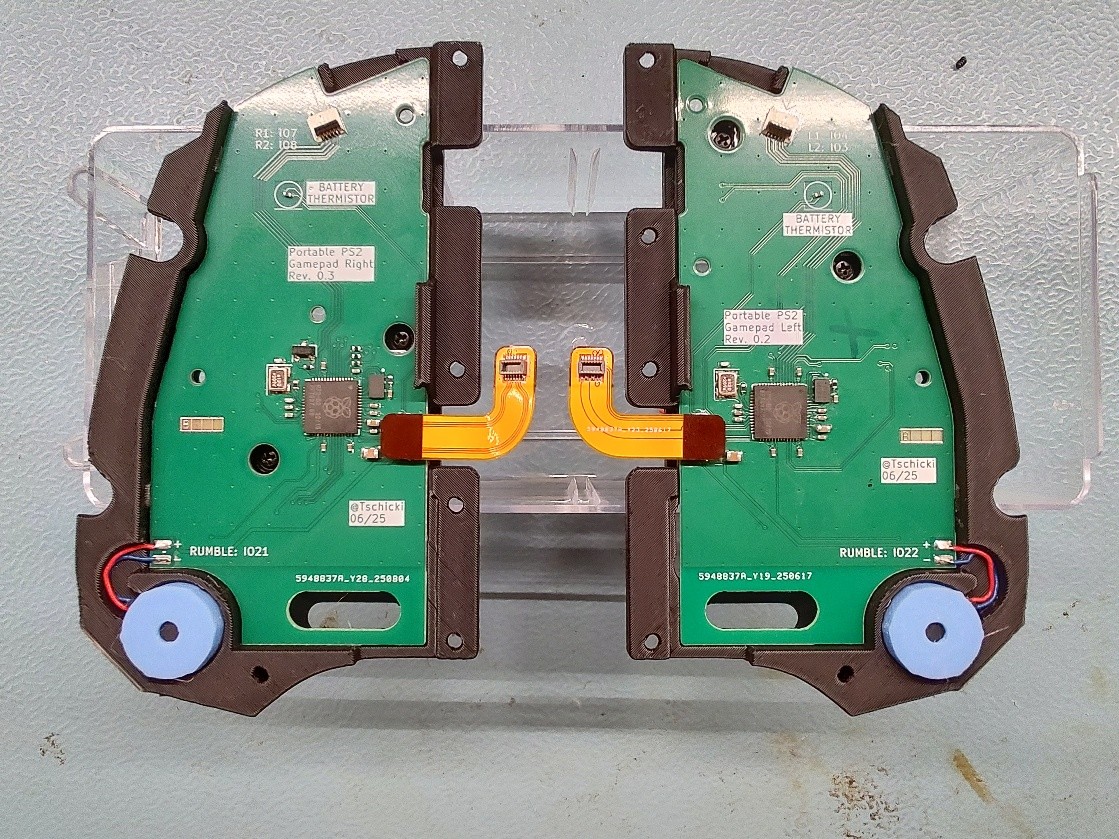
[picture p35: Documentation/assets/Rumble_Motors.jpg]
    

6. Install the *M1.6 Threaded Inserts* (REF1014) in the *Battery Compartment*. Two on the front-facing side and four on the back-facing side. I recommend to push them in to slightly below the surface and then remove any protruding plastic with a scalpel. Make sure the surfaces are flush.
 
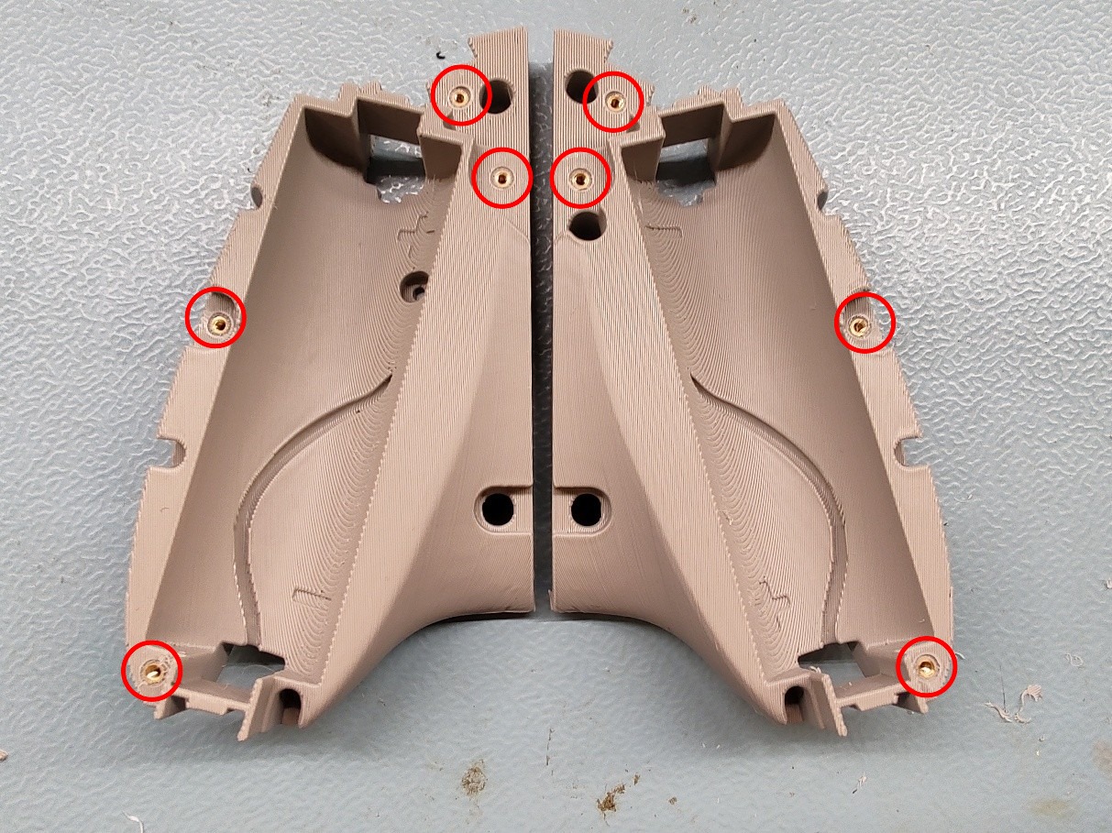
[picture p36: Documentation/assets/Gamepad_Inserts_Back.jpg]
    

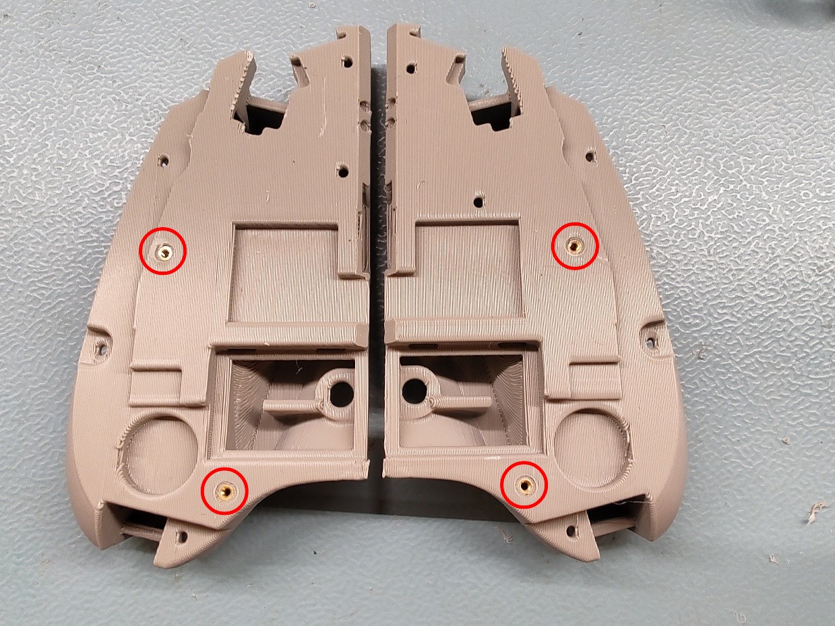
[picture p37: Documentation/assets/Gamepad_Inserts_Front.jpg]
    

7. Cut 4 pieces of wire (REF1018 & REF1019) to length for the battery connections:

    | Side	| Wire Color |	Length |
    |---------------|-----|------|
    | Left Gamepad	| Red |	13cm |
    |               | Black | 6cm |
    | Right Gamepad	| Red |	15cm |
    |               | Black | 22cm |

8. Remove the insulation on one end of each wire and solder it to a *Battery Contact* (REF1005) . Pay close attention to which side the wire enters the *Battery Contact* in the image below. This is important for easier wire routing.

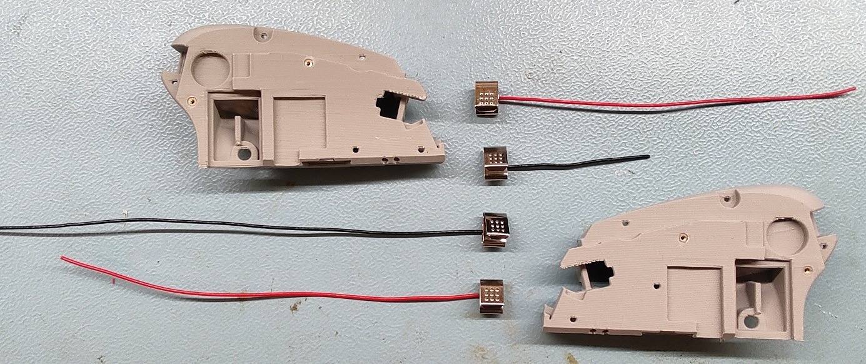
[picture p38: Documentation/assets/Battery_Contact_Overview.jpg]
      
    
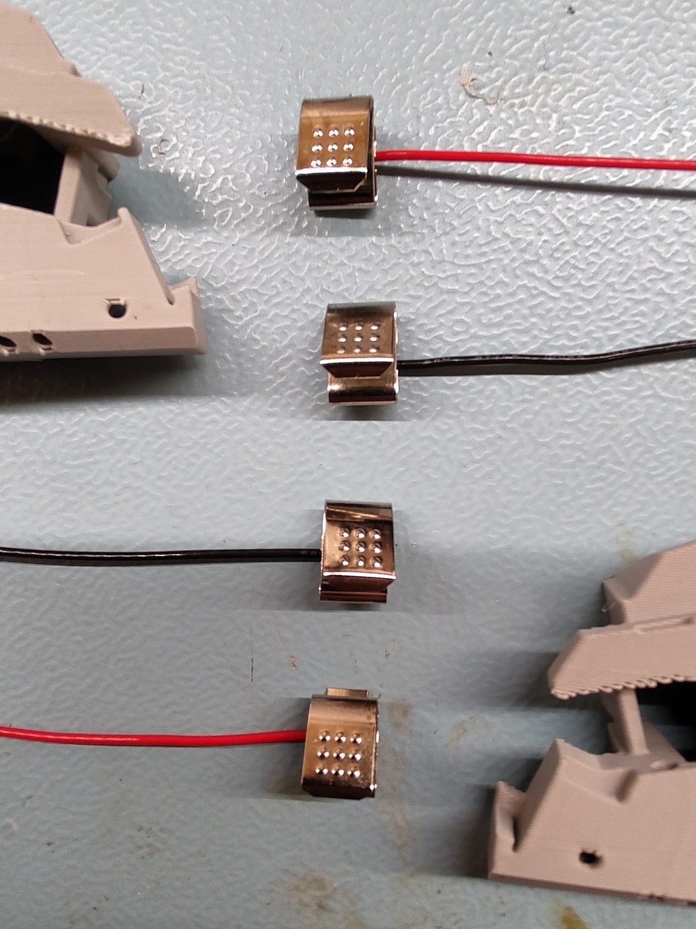
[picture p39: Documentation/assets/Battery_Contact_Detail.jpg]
    
    
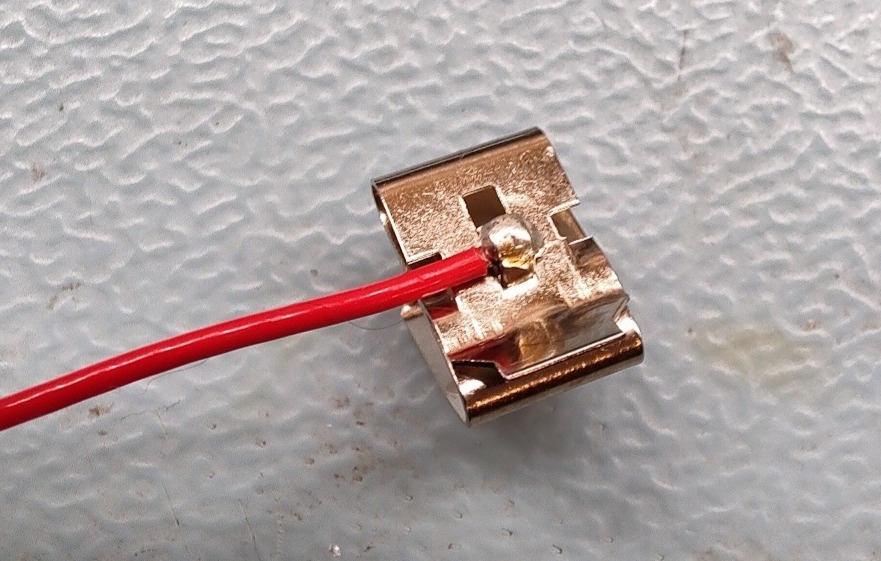
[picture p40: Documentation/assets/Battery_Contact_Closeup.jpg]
    

9. Install the battery contacts with the attached wires from the front-side, as shown below. Push the contacts in, until they click in place.
    > IMPORTANT:
    > -	Pay close attention to NOT swap the wires of left & right gamepads, as they are different in length!
    > -	Pay VERY close attention to NOT swap the polarity – install the red wire on the ‘+’ side and the black wire on the ‘-’ side.
    
    Left Gamepad:  
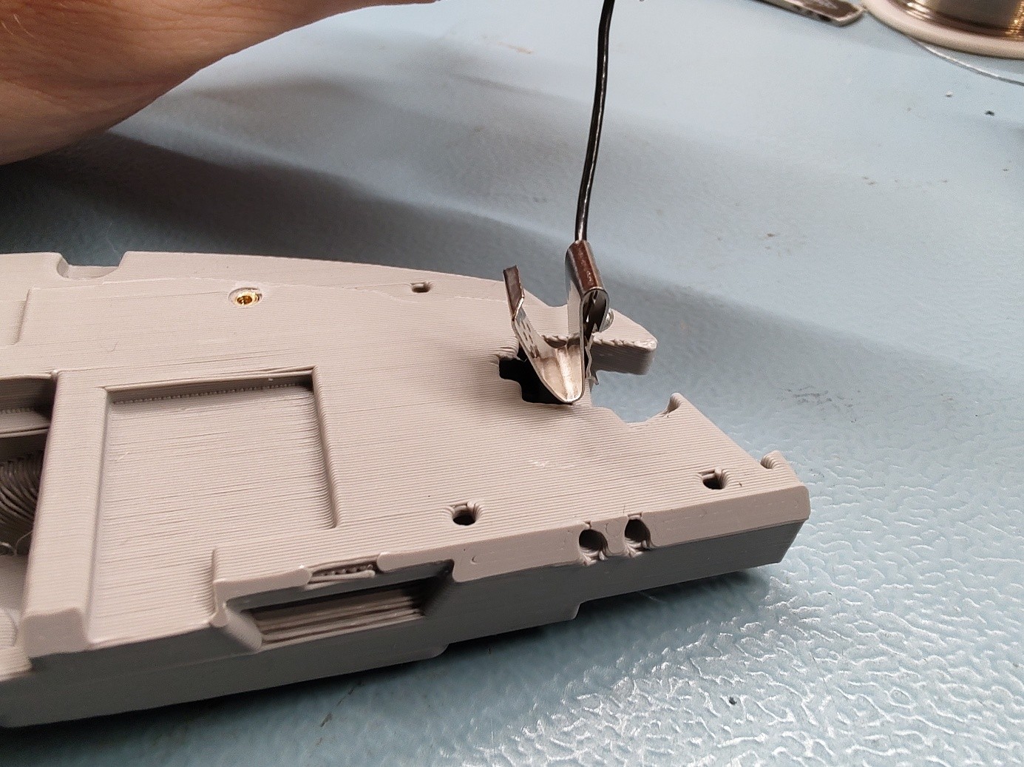
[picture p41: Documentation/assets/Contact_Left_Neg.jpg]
    
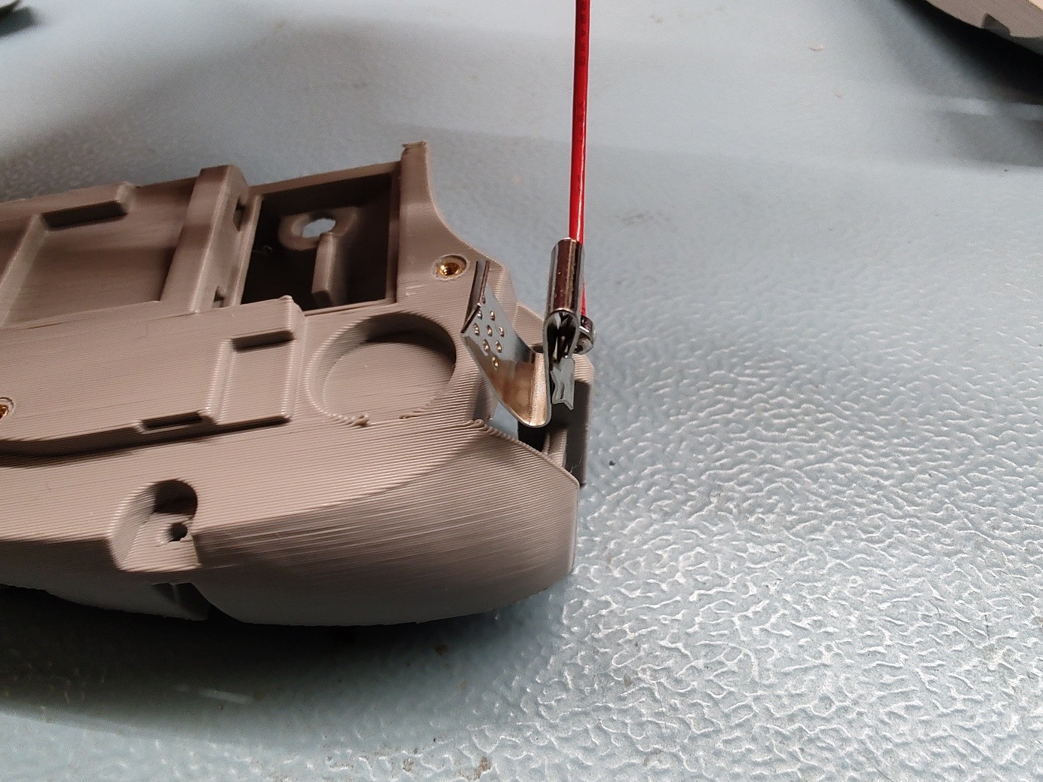
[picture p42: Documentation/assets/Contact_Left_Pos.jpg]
      
    Right Gamepad:  
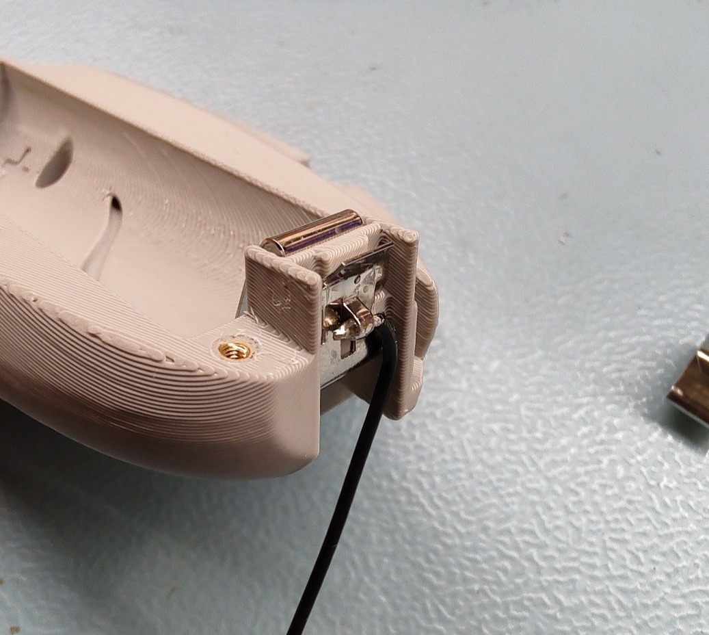
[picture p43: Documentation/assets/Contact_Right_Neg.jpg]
    
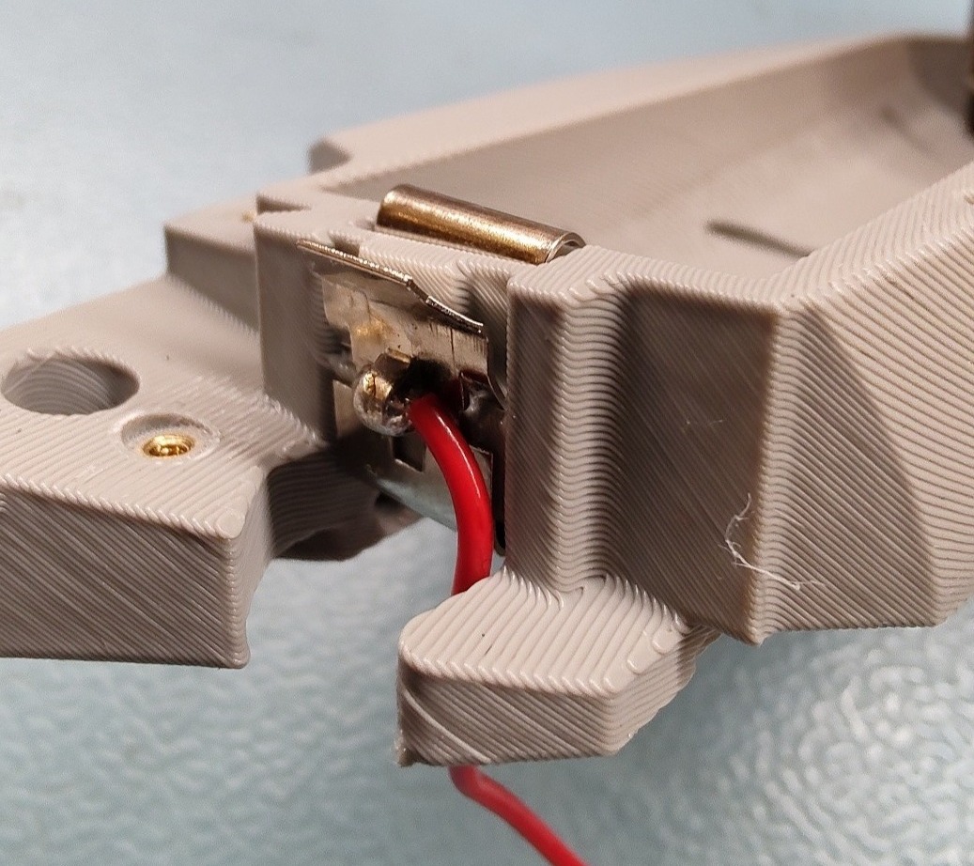
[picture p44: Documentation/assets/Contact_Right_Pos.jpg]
    

10. Guide the wires through their channels as seen in the image below. Again, pay close attention to the polarity! Then shorten the wires of the right gamepad to slightly above 10cm and the wires of the left gamepad to slightly above 2cm, see the image below for reference.
 
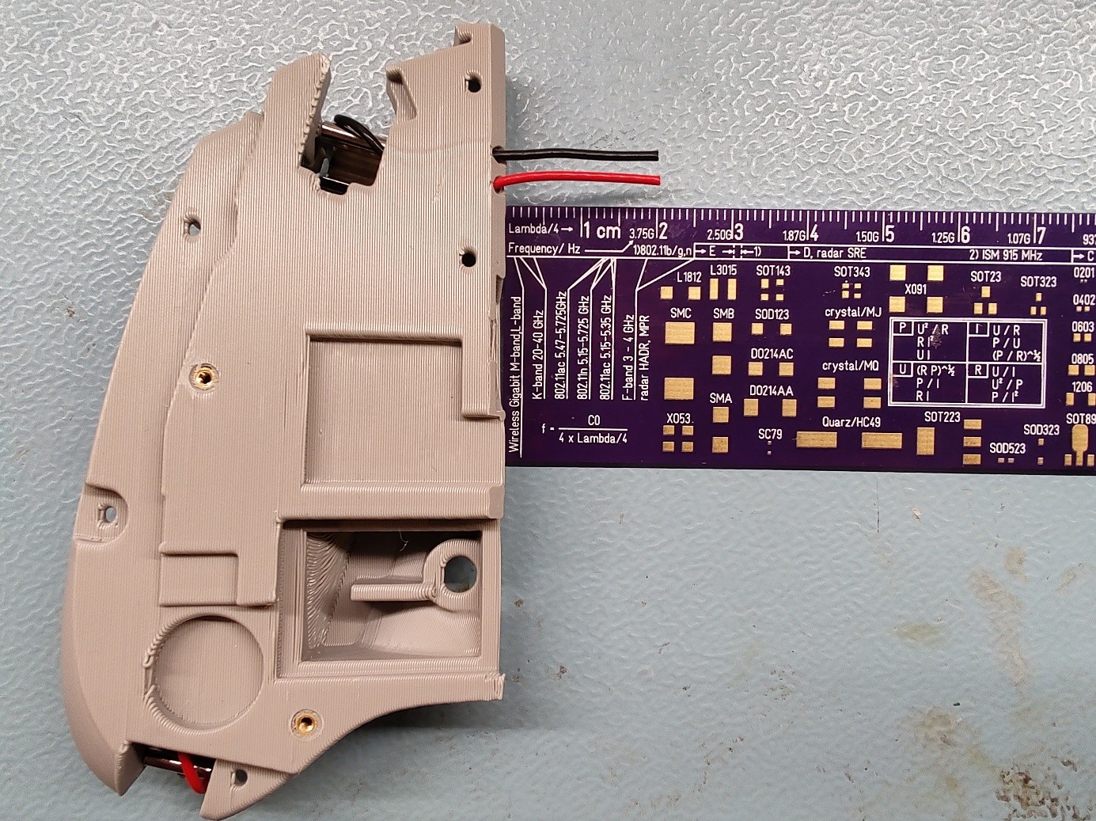
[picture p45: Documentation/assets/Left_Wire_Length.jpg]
    
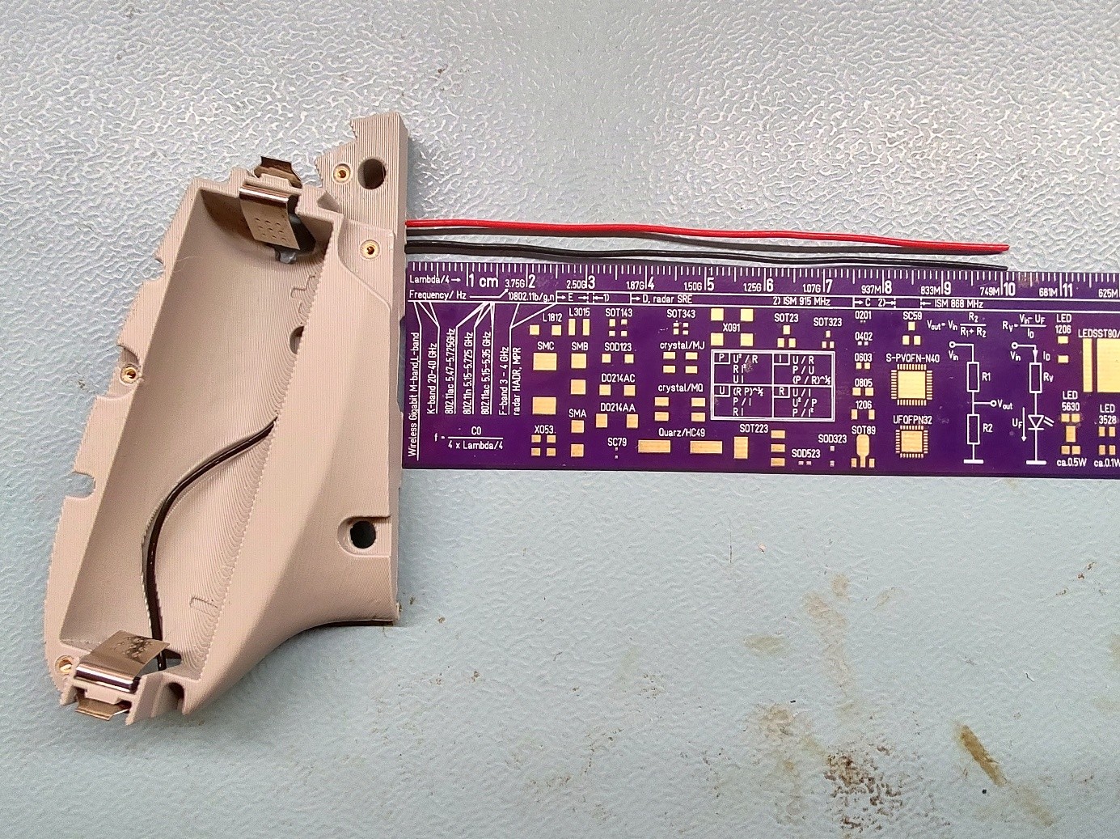
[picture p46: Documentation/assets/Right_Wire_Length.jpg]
    
 
11. Remove the insulation at the end and crimp on the *EZMate HC Crimp contacts* (REF1017) for the *EZMate HC Housings* (REF1016). Beware that this requires a special crimping tool for optimal results (see Tools section). It is highly recommended to already consider the orientation of the plug, so the crimp contacts are facing the right way. Bending the Plug 180° can be a bit tricky afterwards, as the wires are quite stiff.

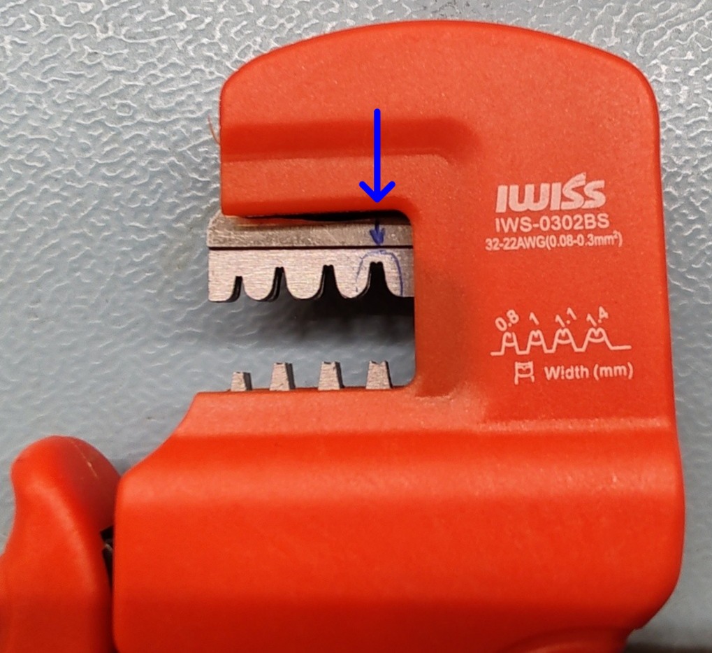
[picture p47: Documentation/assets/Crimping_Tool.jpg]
    
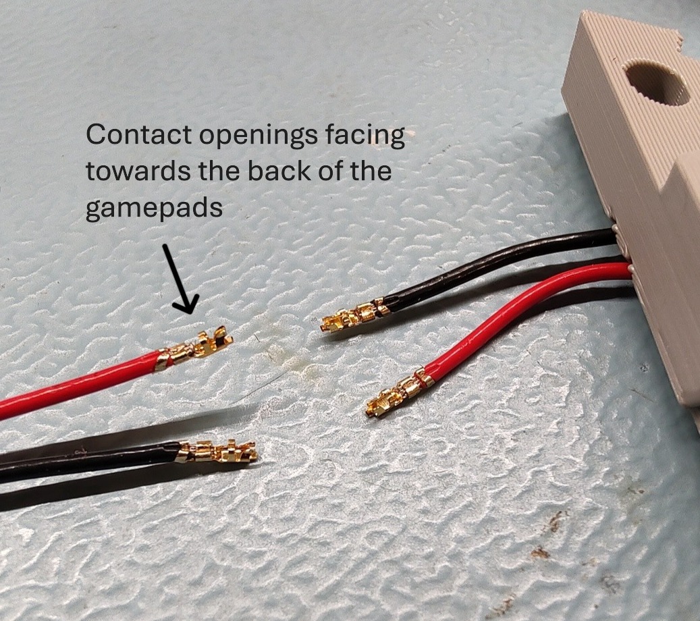
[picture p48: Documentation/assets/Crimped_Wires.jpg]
    
  
12. Slide the crimped wires into the *EZMate HC Housing*. Again, be very careful with the orientation. The wires shall go straight into the plug, see the reference image below for the correct polarity.  
The opening of theplug should face the back of the gamepad, so it can be plugged straight into the mainboard without twisting it 180°.

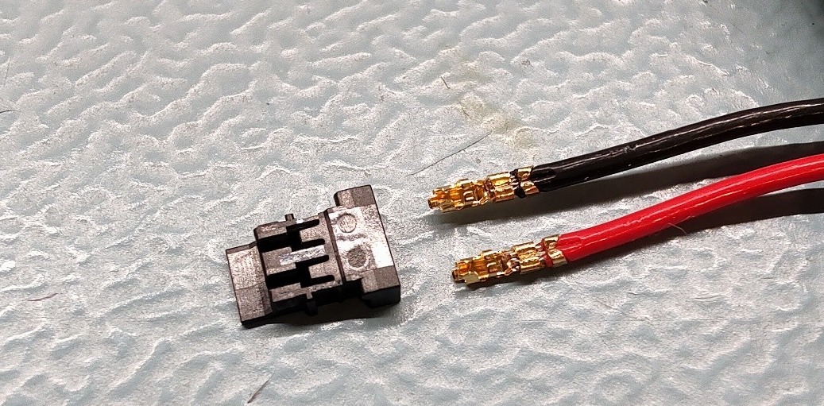
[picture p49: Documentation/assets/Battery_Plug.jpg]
    

13. Clip the *Nintendo Switch Lite speaker* (REF1002) into the *Speaker Cover* (REF2006 & REF2007) in the orientation shown below. Install the *Speaker Cover* in the respective gamepad, guide the plug and wires of the speaker through the opening in the *Battery Compartment*.
  
    Left Gamepad:  
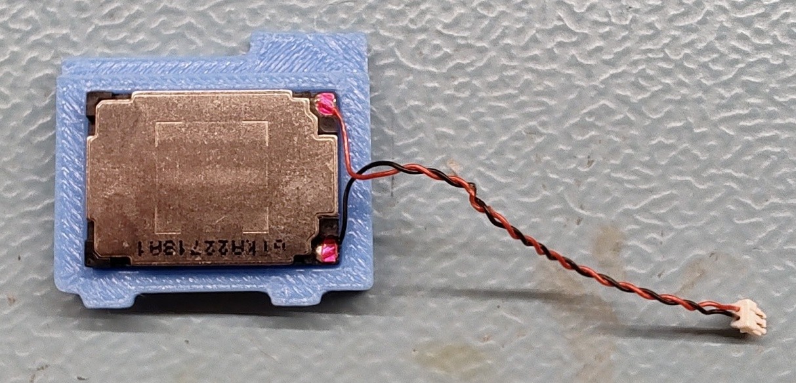
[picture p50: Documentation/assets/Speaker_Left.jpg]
    

    Right Gamepad:  
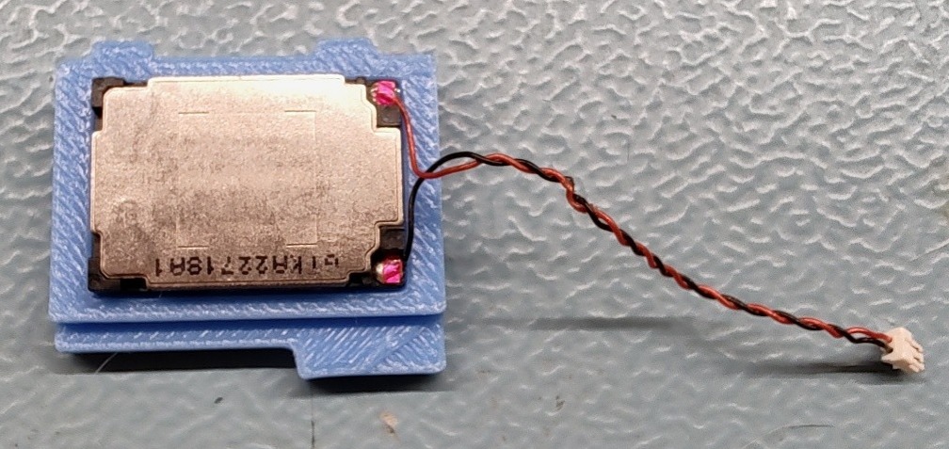
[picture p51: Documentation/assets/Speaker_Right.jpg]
    

    Installed:  
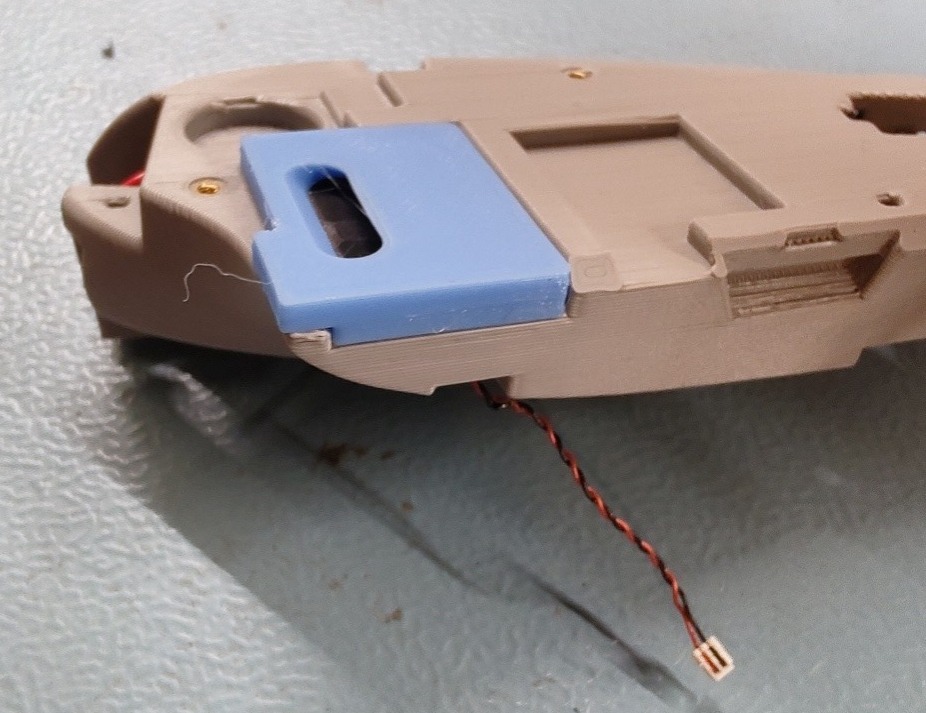
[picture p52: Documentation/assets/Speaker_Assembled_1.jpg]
    

14. Turn the gamepad around and insert the S*peaker Plug* (REF2016) into the *Battery Compartment*. The *Speaker Plug* has a small cutout for the speaker wires to go through, it is very likely that you have to enlarge it manually using a scalpel, depending on your printer. The resulting assembly should look like this:  
    
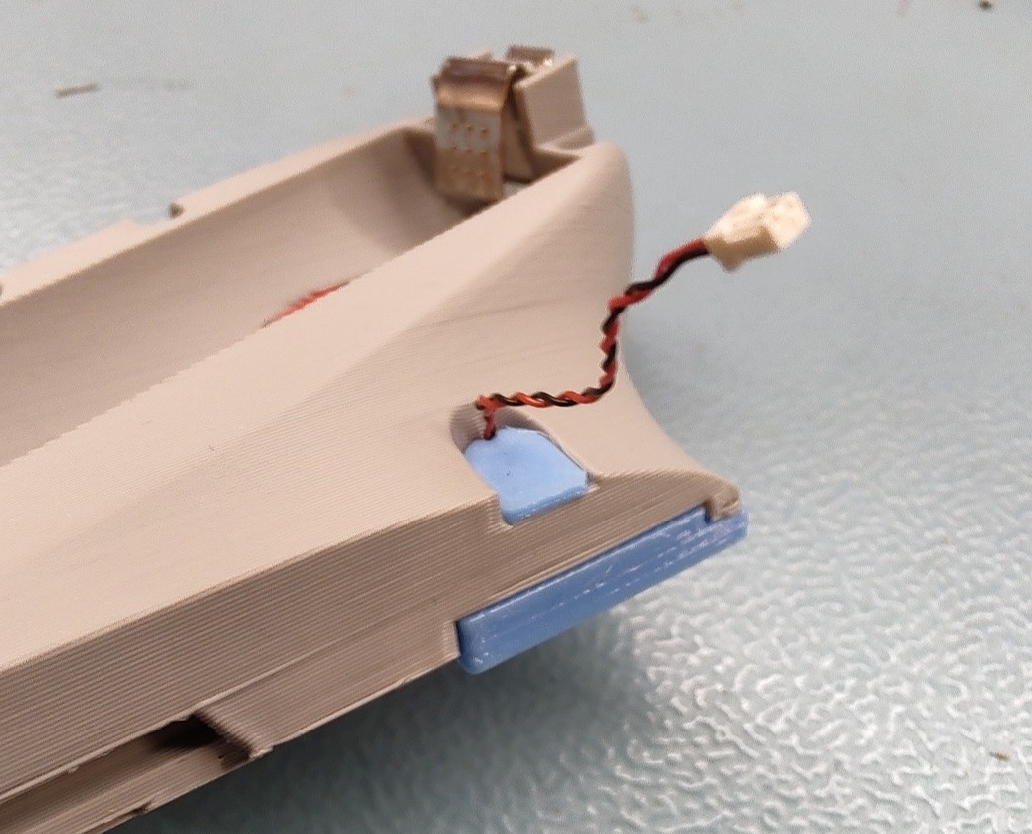
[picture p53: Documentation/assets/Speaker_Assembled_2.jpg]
    
 
15. Connect the *R1 R2 Flex* (REF4006) and *L1 L2 Flex* (REF4007) to the left and right gamepad PCBs, as shown below. Do not forget to close the little latch.

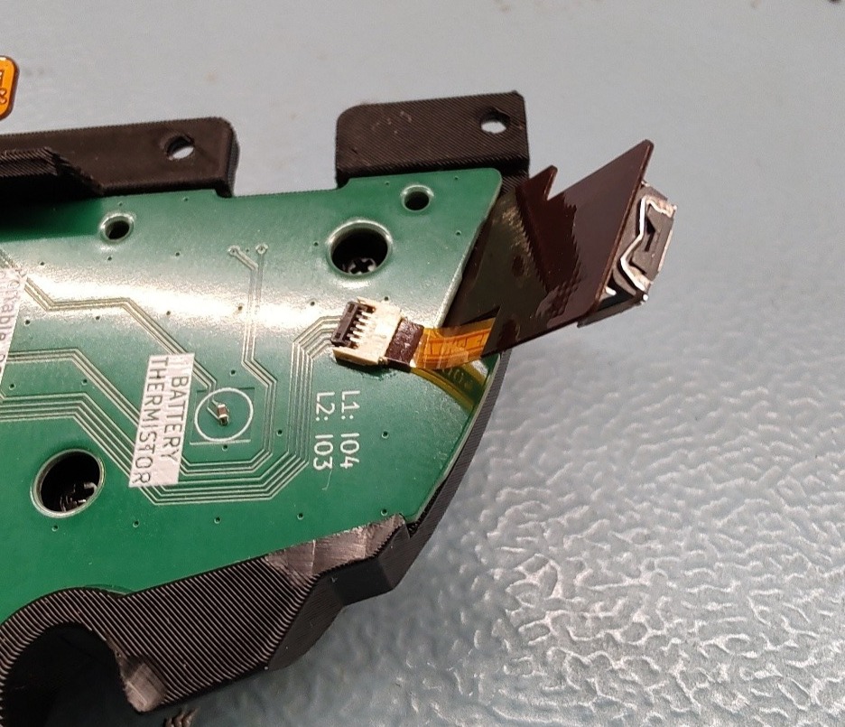
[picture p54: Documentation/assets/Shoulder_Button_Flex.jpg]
    
 
16. Place a ~10*4mm big piece of the 1mm thick thermal (REF1023) pad onto the battery thermistor, as shown below. Don’t forget to remove the protective film on both sides.

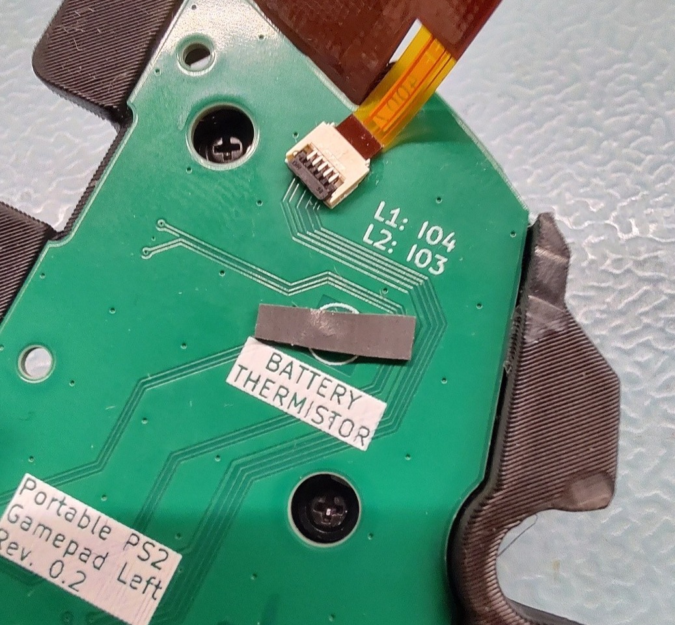
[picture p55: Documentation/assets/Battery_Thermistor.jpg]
    

17. Assemble the *Button Cover* and *Battery Compartment*. Do this by first aligning the snap hook of the *Button Cover* with the respective cutout in the *Battery Compartment*. Do this at an angle and close close the assembly like a book, using the snap hook as guide and hinge. Pay special attention that the shoulder button flex PCB aligns with the slot in the *Battery Compartment*. Do not apply force, or you risk breaking the shoulder button flex PCBs.

    Afterwards check that the *R1 R2 Flex* (REF4006) and *L1 L2 Flex* (REF4007) are in place, and that the thermal pad is held in place by the battery Compartment. The part above the thermistor should be raised above the surface, to make contact with the battery later.
    Also check that the gap between *Button Cover* and *Battery Compartment* is as small as possible. A gap here could indicate that the touching surfaces of the 3D printed parts are uneven and need more rework.
 
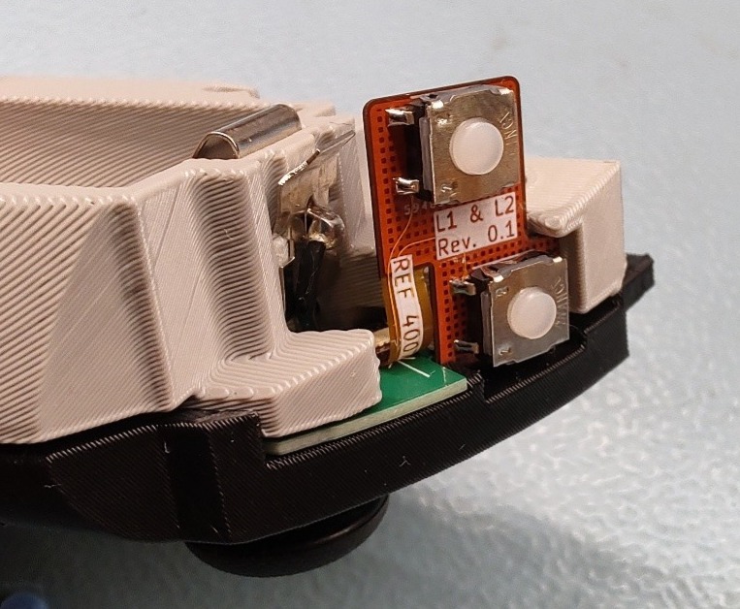
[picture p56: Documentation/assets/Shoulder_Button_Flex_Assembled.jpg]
    
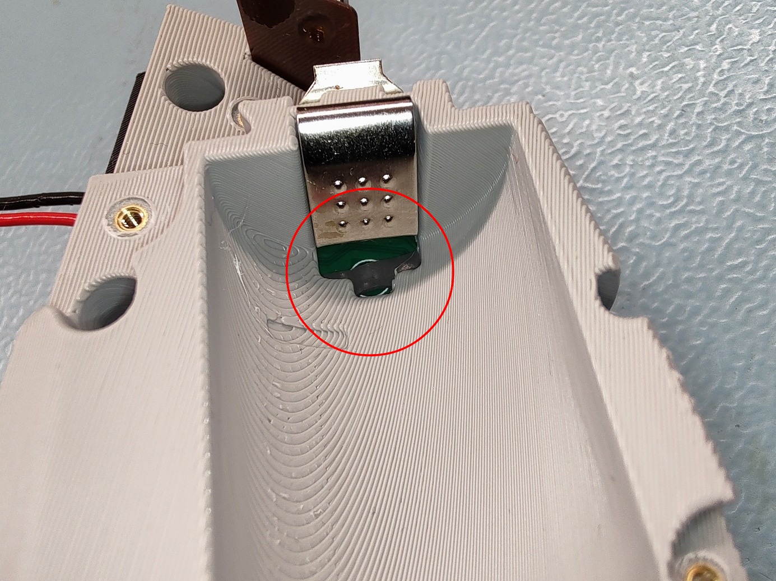
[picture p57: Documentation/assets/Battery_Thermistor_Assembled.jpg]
    
 
18. Slide the according *R2 Button* or *L2 Button* (REF2011 & REF2012) onto the *R1 R2 Flex* (REF4006) or *L1 L2 Flex* (REF4007) respectively. This can be tricky, depending on the accuracy of your printer. You might need to rework the slot in the button for guiding the flex PCB, if the PCB doesn’t quite fit (the slot is too narrow). When installed, the button shall sit flush with the Battery Compartment.
 
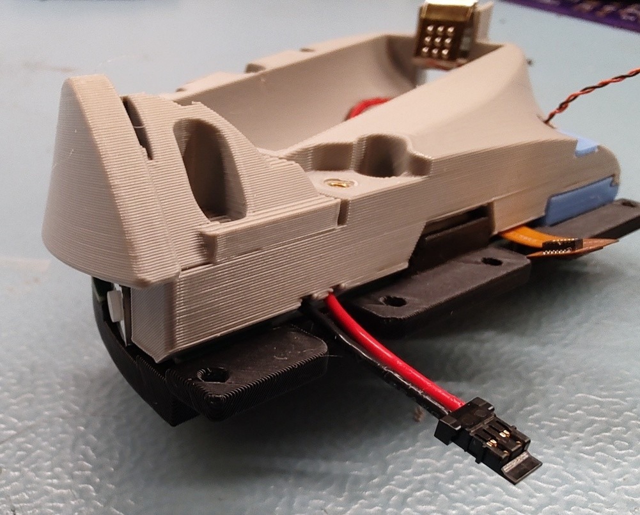
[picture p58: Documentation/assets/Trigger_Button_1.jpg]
    
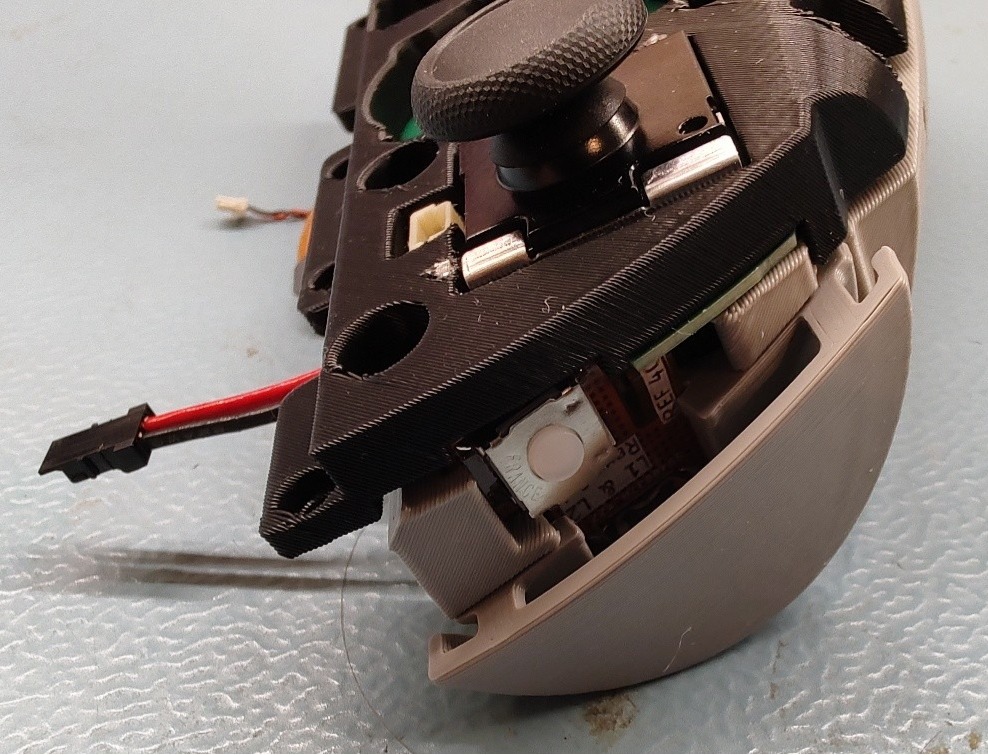
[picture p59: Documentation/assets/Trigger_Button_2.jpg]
    
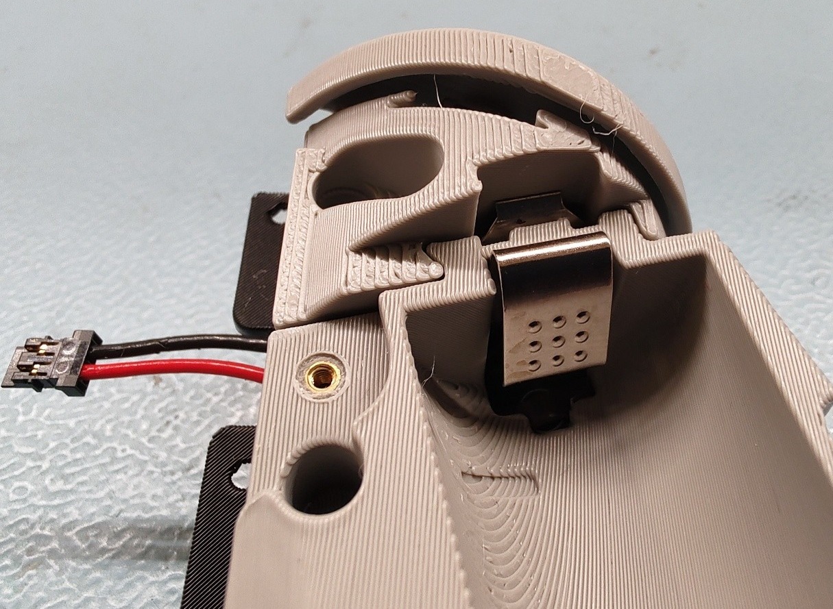
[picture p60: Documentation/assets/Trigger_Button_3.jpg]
    

19. So far the whole assembly was held together by magic. Insert M1.6x5mm screws (REF1007) in the following locations and tighten them. Two from the front and one from the back.

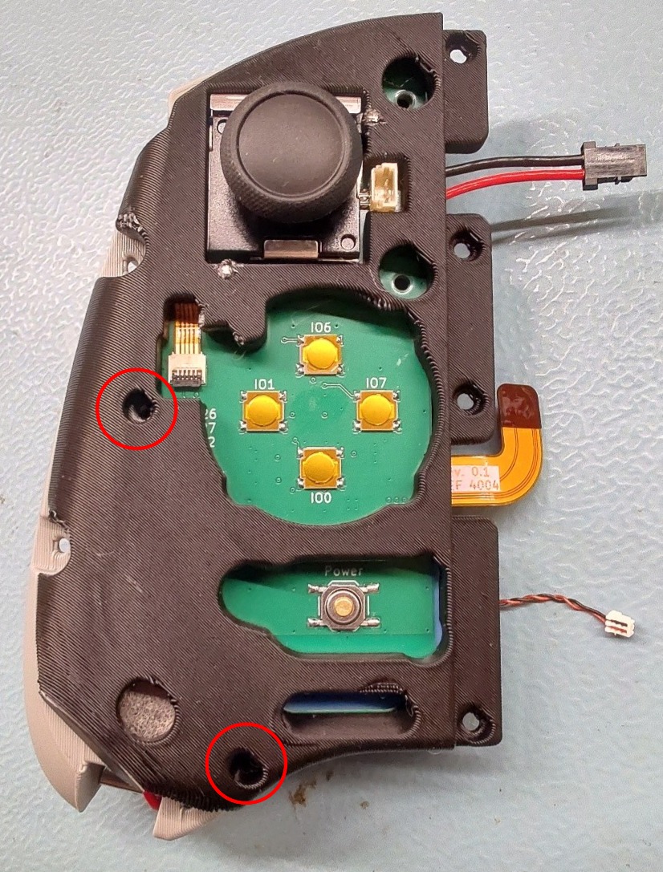
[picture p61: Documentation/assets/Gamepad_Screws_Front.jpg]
    
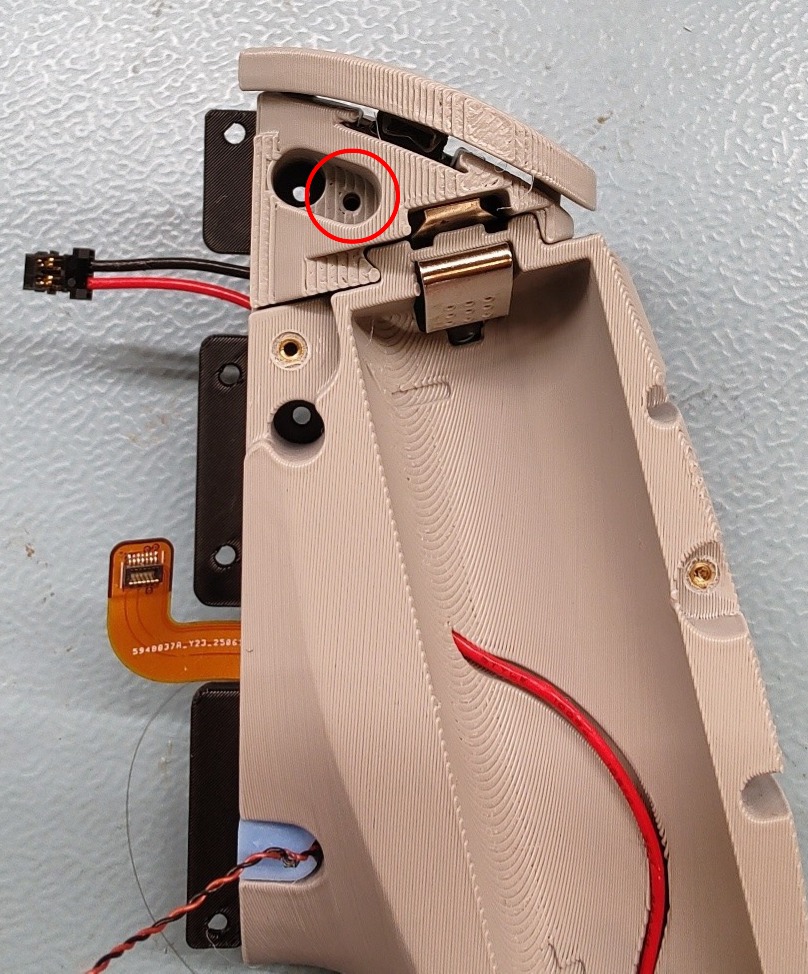
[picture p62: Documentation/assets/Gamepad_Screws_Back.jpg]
    

# End
Both gamepad sub-assemblies are now fully assembled and ready for the next steps!

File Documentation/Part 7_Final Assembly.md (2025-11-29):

# Part 7: Final Assembly of the Portable
This part of the assembly documentation will describe how to assemble the full portable PS2.

## Recommended Tools:
- Scalpel or similar
- Tweezers
- Tool for M1.6 heat set inserts
- Screw driver kit with at least a T5 bit

## Recommended Materials:
- Glue (epoxy preferred)
- Double-sided tape

## Mechanical Assembly

1. Press the *Nintendo Switch Lite Fan* (REF1000) onto the *PS2 Heatsink* (REF3000). It's a tight fit the first time you do it, and doing it before the assembly puts less mechanical stress on the mainboard.

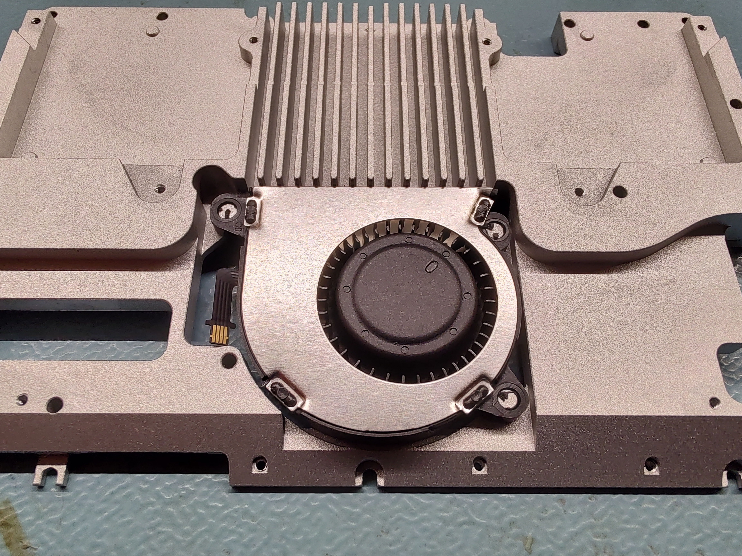
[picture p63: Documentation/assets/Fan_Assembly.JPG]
    

1. Mount the *MemoryCard Flex* (REF4003) in the *MemoryCard Cover* (REF2014):  

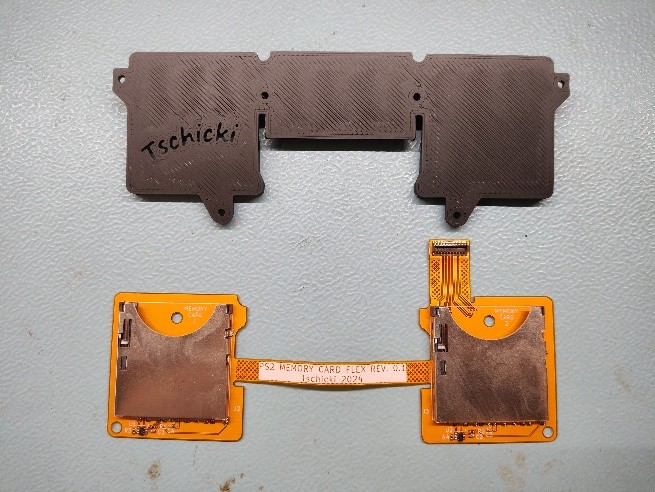
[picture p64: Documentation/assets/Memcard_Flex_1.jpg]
 	
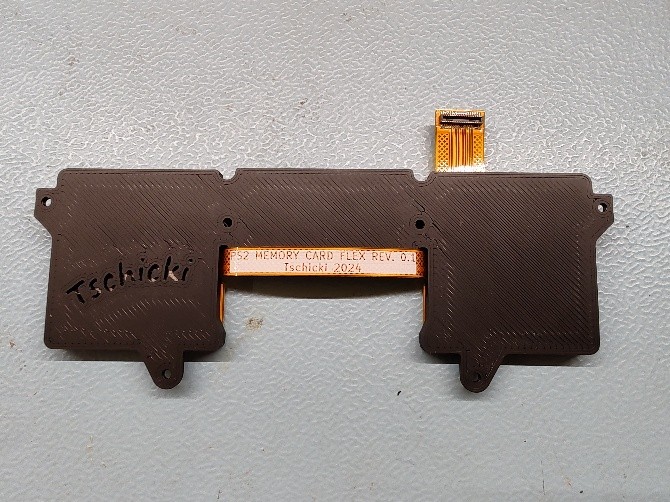
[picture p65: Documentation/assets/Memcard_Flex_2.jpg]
    
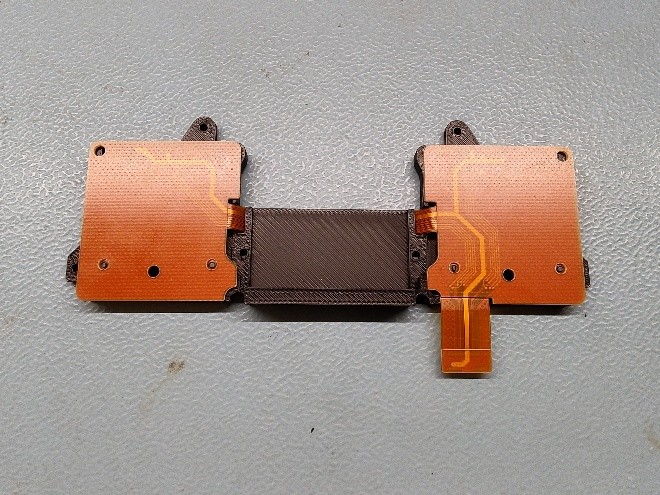
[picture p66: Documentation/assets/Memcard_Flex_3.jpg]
    

2. Insert the resulting subassembly in the *PS2 Heatsink*, take care that the *MemoryCard Flex* is fully seated. Then insert 4 screws M1.6x5mm (REF1007).

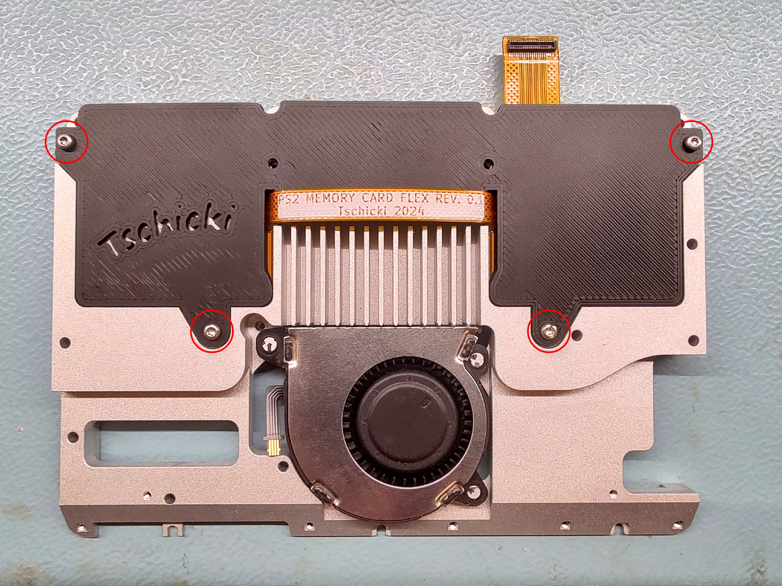
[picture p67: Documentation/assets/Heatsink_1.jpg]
    
4. Cut a 18x18mm piece of 1mm thick thermal pad (REF1023). Cut a 30x30mm, 4x4mm and a 4x11mm piece of 0.5mm thermal pad (REF1022).   

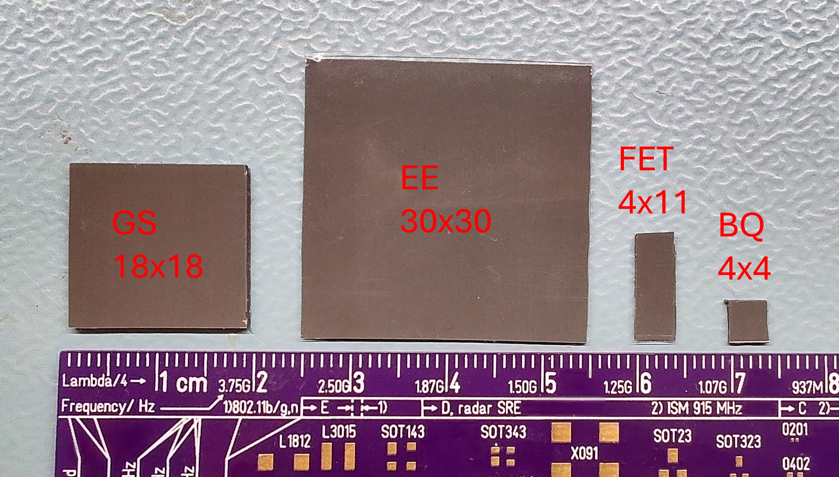
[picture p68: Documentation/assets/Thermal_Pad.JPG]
    
5. Stick the 30x30mm thermal pad onto the EE, the 18x18mm on the GS, the 4x4mm pad on the BQ25792 and the 4x11mm pad on the three charge FETs as shown below, connect the *MemoryCard Flex* to the *PS2 Mainboard*.  

    
6. Close the resulting assembly like a book.  

    
7. Add the *R1-L1 Bar* (REF2010), *Lower Display Mount* (REF2009), left & right gamepad subassembly (manufactured in [Part 5](https://github.com/tschicki/PS2-Portable/blob/main/Documentation/Part%205_Gamepad%20Subassemblies.md)) and mount them the following way:
    - First insert and tigthen the 4 M1.6x5mm screws (REF1007) circled in purple
    - Then tighten the 11 M1.6x5mm screws (REF1007) circled in red.
    - Manage the battery wires roughly to fit below the *R1-L1 Bar* and plug them into the mainboard. 
    - Insert the *R1-L1 Bar* and fasten it with 4 countersunk M1.6x6mm screws (REF1008) circled in green. Make sure to guide the battery wires of the right gamepad through the intended channels of the *R1-L1 Bar* before tightening its screws. 

    
8. Insert the *Gamepad Flex Left* (REF4004) and *Gamepad Flex Right* (REF4005) and the battery connectors, if not done already.  

    

9. Insert the left and right speaker connectors and connect the 4-pin FFC of the fan to the *PS2 Mainboard*. The fan FFC can be a bit subborn, use tweezers. Do not forget to close the latch of the fan connector.  

    

12. Install 15x M1.6 threaded inserts (REF1014) into the *PS2 Main Housing Top* (REF2000). Push them in to slightly below the surface and then remove any protruding plastic with a scalpel. Make sure the surfaces are flush, otherwise the portable will not close correctly.  

    
13. Adhere the two *Speaker Dust Covers* (REF1020) to the inside of the speaker holes on the *PS2 Main Housing Top*.  

    

14. Adhere the double-sided adhesive tape (REF1021) to the flat side of the *Screen Lens Frame*. Make sure there is no gap, as this mainly serves as dust-protection.

    

15. Remove the protective film of the *Nintendo 3DS XL Screen Lens* (REF1015) and adhere it into the *Screen Lens Frame*, to the side with the protruding feature of the exact same size as the screen lens. The alignment between the two parts is critical, make sure the screen lens is not shifted or rotated!  
    
    

16. Remove the protective films of the *5 inch DPI display* (REF1003) and the double-sided adhesive on the *Screen Lens Frame*. Without getting any dust between them, align the *Screen Lens Frame* to the lower left corner of the display and join them. Both **must** be aligned on the left, right and lower edges. Again, the alignment between the two parts is key, so take your time and do it right!

    
    

14. Adhere the now created display subassembly to the *PS2 Main Housing Top* from the inside. If it needs to be permanent, use epoxy. I personally like to use Tesa 5157, then you can reuse the display subassembly in case you want to swap housings. Apply the tape / glue on the left, right and bottom lips of the *Screen Lens Frame* and press it into the *PS2 Main Housing Top*. Take care to first insert the upper edge of the display subassembly into the respective groove of the *PS2 Main Housing Top*, then leverage the subassembly into position.

    

16. Insert the *PLP1-100-FD Light Pipe* (REF1001) into the hole above the LED on the right gamepad. The longer side of it must face towards the outside.  

    
17. The power button (REF1012) will need some rework in order to fit - the actuator needs to be cut off using a scalpel. The start and select buttons may also need a slightly shortened actuator, but far less than the power button.

    
    
17. Insert all buttons into the inner skeleton and lift the *PS2 Main Housing Top* onto it from above. Insert the 40-pin flex cable of the *5 inch DPI display* (REF1003). Close the connector by gently pushing both left and right tabs into the connector at the same time.
Then move the *PS2 Main Housing Top* into position and do a quick check whether the light pipe and all buttons are in their cutouts.

    

18. Flip the assembly around; insert and tighten 13 M1.6x5mm screws (REF1007) in the locations marked below. Work your way from the center to the outside.  

    
19. Insert and tighten 2 M1.6x6mm screws in the following locations:  

    
20. Test whether all buttons are pressable and feel good. The 3D printed parts may need some more rework if this is not the case.
21. Adhere the *Backside Vent Cover* (REF2014) to the *PS2 Main Housing Bot* (REF2001) using some glue.  

    
22. Insert the *21000 Batteries* (REF1006) with **COORECT POLARITY**  

    
22. Seat the *PS2 Main Housing Bot* on the assembly and mount it using 10x M1.6x5mm screws (REF1007). Be careful to not pinch the *MemoryCard Flex* while closing the housing!  

    
23. The portable will not turn on right after assembly. Plug a charger, the LED will come on and then blink red/blue. This will force the battery protector to enable power, now the portable can be powered on by long-pressing the power button.

# End
The PS2 portable is now fully assembled! It's a good point now to read through the general usage tips in [Part 9](https://github.com/tschicki/PS2-Portable/blob/main/Documentation/Part%209_User%20Guide.md).
It is also highly recommended to build some accessories for the portable (see [Part 8](https://github.com/tschicki/PS2-Portable/blob/main/Documentation/Part%208_Accessories%20Assembly.md)):
- uSD2PSX - A must, if you want to play games on your portable!
- Travel case - Adds a layer of protection to your PS2 portable, if you like to carry it in your backpack!
- Display Stand - Quite handy for charging and perfect to display your portable when you're not using it!

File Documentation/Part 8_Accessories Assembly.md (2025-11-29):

# Part 8: Accessories Assembly
This part of the assembly documentation will describe how to assemble the accessories of the PS2 portable.

## Recommended Tools:
- Soldering iron
- Side cutters
- Scalpel or similar
- Tweezers
- Tool for M1.6 heat set inserts
- Ruler
- Crimping tool IWS-0302BS
- Screw driver kit with at least a T5 bit

## Recommended Materials:
- Solder
- Kapton Tape
- 2 component epoxy

## uSD2PSX

### PCB Assembly
- Assemble the uSD2PSX Flex (REF4008) with the parts of its electrical BOM. 
    - Adhere the flex PCB to another rigid PCB using kapton tape, to make soldering easier

> For the flex PCB it is recommended to set your soldering iron temperature to ~250°C and to use leaded solder. The thin PEI dielectric can and will be damaged by high temperatures.



### Programming and Testing

This is the testpoint pinout:  


In order to flash the SD2PSXtd firmware, you will need to obtain the .uf2 file first. Find it [here](https://sd2psxtd.github.io).
For flashing you will need a 3.3V power supply to power the SD2PSX. Solder it to the +3V3 and GND test points. You will also need the BOOTSEL button (or alternatively short BOOTSEL to GND), solder it to QSPI_SS and GND.
Lastly you will need to sacrifice a USB A cable and solder D+, D- and GND of the cable to the testpoints USB_IN_DP, USB_IN_DN and GND. With these connections done, you can connect the USB cable to a PC, hold the BOOTSEL button and then enable 3.3V power. An explorer window should open and you can drag the SD2PSXtd firmware into it.

Now it is time to setup the uSD2PSX for loading games, the SD Card setup is identical to a normal SD2PSX. You will need to obtain CIV.bin and create a SD2PSX config file on the SD Card.
It's important to set Autoboot=ON and Mode=PS2 in the config file, the example config on the SD2PSXtd website already has this. In my case the firmware did not apply these setting initially, so there is a high chance that you will also need to connect the SD2PSX OLED display and two buttons (like on the SD2PSX) to the flex PCB. The OLED needs 3.3V, GND, SDA and SCL. You connect them to +3V3, GND, OLED_SDA and OLED_SCL. The two buttons are connected to SW1, SW2 and GND. 

Prepare the SD Card, insert it and power the uSD2PSX from 3.3V. Now you should be able to navigate the menu, enable PS2 mode and set Autoboot to ON if needed. When this is done you can desolder all wires from the testpoints and thoroughly clean the PCB, as flux residue might affect the adhesion of the epoxy we use later.

This setup is very much subobtimal, but fitting an SD2PSX onto a 2-layer SD Card sized flex PCB did not allow for connectors or a BOOTSEL button. Luckily this only needs to be done once (or if the firmware ever needs to be updated).
If you are planning to do this more than once, it might make sense to make something like this:  
      
      
    

### Assembly

The uSD2PSX consists of the flex PCBA, a *uSD2PSX Frame* (REF2017) and a *uSD2PSX Stiffener* (REF2018).

1. Apply 2K epoxy on the blue areas on the top side of the uSD2PSX flex PCB. Keep some distance around the openings of the micro SD Card slot and do not apply too much! 

    
2. Place the *uSD2PSX Frame* onto the uSD2PSX flex, align them and clamp the assembly somewhere during curing.
3. When cured, apply epoxy on the *uSD2PSX Stiffener* (correct side!) and place it on the bottom layer of the uSD2PSX flex.
4. Align them, so the part is flush with the upper edge and centered horizontally. Clamp the assembly for curing.
5. Once cured, cut off all excess epoxy using a scalpel.
6. Now you can insert the SD card again and test the uSD2PSX with the PS2 portable!
7. Lastly, place a piece of kapton tape over the exposed testpoints to provide at least a little ESD protection.




## Debugger
The debugger is optional and only required if you want to develop code for the SysCon or video processor.

What you need:
- [FT2232H Mini Module](https://ftdichip.com/products/ft2232h-mini-module/) for debugging the T20 FPGA
- RP2040 Zero programmed with the [debugger firmware](https://github.com/sentoxo/debugprobe_rp2040-zero)
- Debugger PCB (2 layer, 1.6mm), find it in the Electronics directory
- **FTSH-107-01-F-DV-K-P-TR** header and matching cable for the debugging FPGA and SysCon
- **SM03B-SRSS-TB** header and matching cable for programming the left and right gamepads

Solder all components to the Debugger PCB, preferrably using female pin headers (if you ever need to remove the RP2040 Zero or the FT2232H). That's about it for the debugger.






## Travel Case
The *Travel Case* is optional and less defined than the system itself.
There is space for about 1mm to 1.5mm of padding all around the portable, to keep it safe and free from scratches. What material to use and how to apply it is up to you, I personally use 1mm rubber foam sheets with pre-applied adhesive (REF1024).

You will need the following:

- ~1mm thick foam rubber sheets (REF1024), or some padding of your choice
- Two 25mm long M3 cylinder head screws (REF1025) for the hinge
- Top and bottom Travel Case housing (REF2020 and REF2021)
- Two Travel Case latches (REF2022 and REF2023)

Assembly:

1. Press the Travel Case latches (REF2022 and REF2023) into the top Travel Case part. They are marked left and right. Be careful when inserting to not crack the plastic or separate the layers. If they really don't fit, you may need to rework the parts using a scalpel.
2. Join top and bottom Travel Case housing parts using the 2 M3x25 cylinder head screws (REF1025)
3. Apply padding to the inside of the Travel Case. It's best to regularly check the fitment using the portable. If you go the foam rubber route, here is a reference on how I apply it:





Done!

## Display Stand
The *Display Stand* (REF2019) actually needs no assembly at all, if you want you can insert the PlayStation logo salvaged from the orgiginal PS2 slim shell in the front. There is a little protusion on the cylindrical part of the PS2 logo that you might need to remove for the logo to fit properly.



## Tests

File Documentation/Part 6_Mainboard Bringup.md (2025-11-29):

# Part 6: PS2 AIO Mainboard Bringup 
This part of the assembly documentation will describe the bringup process of the custom PS2 AIO Mainboard. In order to compile the needed SysCon and gamepad firmware, you will need to set up the RP2040 SDK in VSCode - you will find more detailed steps in [Part 10](https://github.com/tschicki/PS2-Portable/blob/main/Documentation/Part%2010_Development%20and%20Debugging.md).

## Recommended Tools:
- Soldering iron
- Multimeter
- Pico Debug Probe OR PS2 debugger (PS2 debugger is an accessory, see [Part 8](https://github.com/tschicki/PS2-Portable/blob/main/Documentation/Part%208_Accessories%20Assembly.md))
- USB-C power meter (voltage/current/wattage)
- USB-C PD power supply (20V >15W)
- Screwdriver kit (T5)

## Recommended Materials:
- Solder (lead-free or leaded)
- USB-C cable
 
## Procedure
### Assembly for Testing
For more details about the final assembly, refer to the assembly procedure of the whole system ([Part 7](https://github.com/tschicki/PS2-Portable/blob/main/Documentation/Part%207_Final%20Assembly.md)). Below steps are only a sum-up of what is needed to temporarily assemble for testing and programming the PS2 AIO Mainboard.
- Temporarily mount the mainboard in the heatsink with a couple of screws. No thermal pad needed for now.
- Mount the Bumper bar and bottom display frame temporarily to hold the display later.
- Connect the left and right gamepad sub-assembly. Do not forget to connect the left and right gamepad flex, speakers and battery cables. Do a quick check that 3V3_SBY is not shorted afterwards.
- Do not insert batteries yet!

The temporary assembly for testing should look something like this:  

 
> -	DO NOT INSERT BATTERIES YET
> -	In this image you can also see that all supply jumpers are shorted, they should all be OPEN at the start of your testing session! Only close them in the respective testing steps below!
> -	It is not needed to insert all screws, just enough for the assembly to not fall apart

## Overview
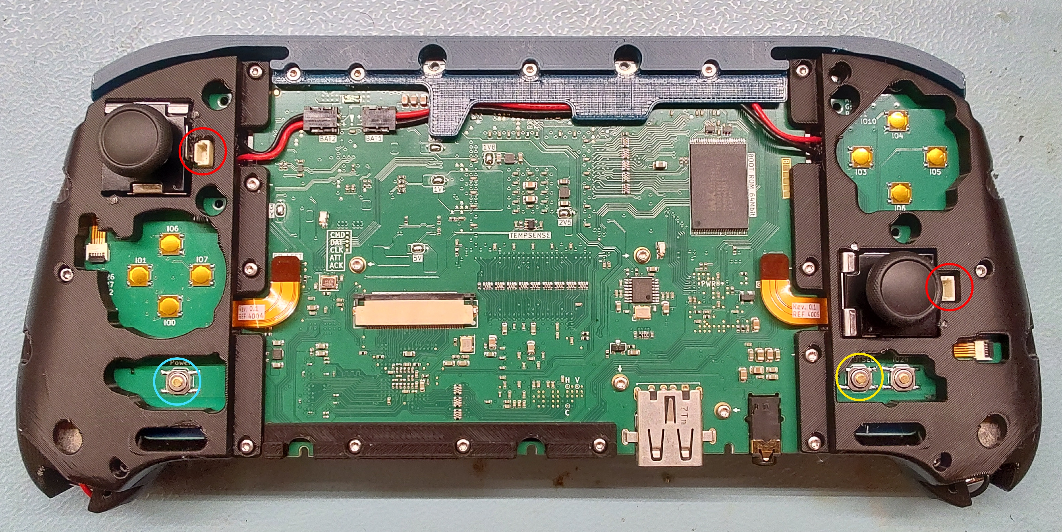
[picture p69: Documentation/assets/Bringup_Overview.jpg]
  

> Red Circle: Gamepad debug header  
> Blue Circle: Power Button  
> Yellow Circle: BOOTSEL  
 
### Step 1: Flashing the USB-C PD Controller and Gamepads & Supply Voltage Check
1. Close the jumper 3V3_SBY on the bottom layer. Leave all other jumpers open!  
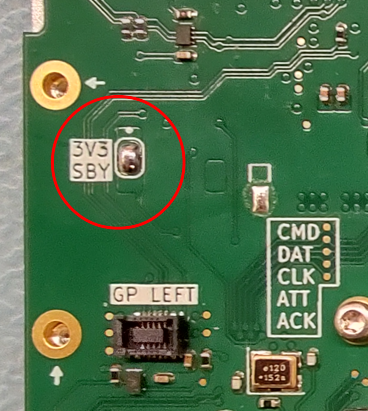
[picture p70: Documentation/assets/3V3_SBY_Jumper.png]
    
2. Connect the system to a PC using a USB-C cable with USB-C power monitor, while holding the BOOTSEL button (select button on right gamepad), an explorer window opens and the SysCon shows up as USB storage device. 
3. Now drag the SysCon firmware compiled for Step 1 into the window to flash it.
    > **To obtain the correct firmware:**  
    > Uncomment only the line `#define MFG_STEP_1` in the file MCU_Interface.h and compile the SysCon firmware. See [Part 10](https://github.com/tschicki/PS2-Portable/blob/main/Documentation/Part%2010_Development%20and%20Debugging.md) for more details.      
    >
    > **What this version of the firmware does:**
    > -	After pressing the power button for one second, the SysCon will flash the USB-C PD config to the NVM of the STUSB4500.
    > -	Afterwards, the SysCon will turn on all DC-DC converters and halt until unplugged.

4.	Press and hold the power button, then before unplugging the USB cable, ensure that the voltages are present on the following power rails:
    - T20_1V2 -> 1.2V
    - T20_1V8 -> 1.8V
    - T20_3V3 -> 3.3V
    - PS2_3V3 -> 3.3V
    - PS2_1V -> 1V
    - PS2_5V -> 5V
    - PS2_2V5 and PS2_1V8: No worries if you don't measure any voltage there at this point, the PS2_3V3 is still open which means these regs are not supplied yet
5. Unplug the USB-C cable from the PC and plug in a USB-C PD capable charger with up to 20V capability (if not done already). Check on the USB power monitor that the mainboard requests 15V (not 20V), which means that the NVM was flashed correctly.
6. Now is a good time to program the gamepads using a Pico Debug Probe. Both gamepads are supplied by the standby power, so you are able to program them right after plugging in the USB-C cable. See [Part 10](https://github.com/tschicki/PS2-Portable/blob/main/Documentation/Part%2010_Development%20and%20Debugging.md).

### Step 2: Testing the PS2 Part
1. Connect the system to a PC using a USB-C cable with USB-C power monitor, while holding the BOOTSEL button (select button on right gamepad), an explorer window opens and the SysCon shows up as USB storage device. 
2. Now drag the SysCon firmware compiled for Step 2 into the window to flash it.
    > **To obtain the correct firmware:**  
    > Uncomment only the line `#define MFG_STEP_2` in the file MCU_Interface.h and compile the SysCon firmware. See [Part 10](https://github.com/tschicki/PS2-Portable/blob/main/Documentation/Part%2010_Development%20and%20Debugging.md) for more details.    
    >
    > **What this version of the firmware does:**
    > -	Enable normal operation without batteries installed (the default firmware would enter error state without batteries, this one doesn’t)

3. Remove the USB-C cable and close the jumpers for 1V, 1V8, 2V5, 3V3 and 5V. This will connect the PS2 circuit to the power management portion and supply it the next time you press the power button.  
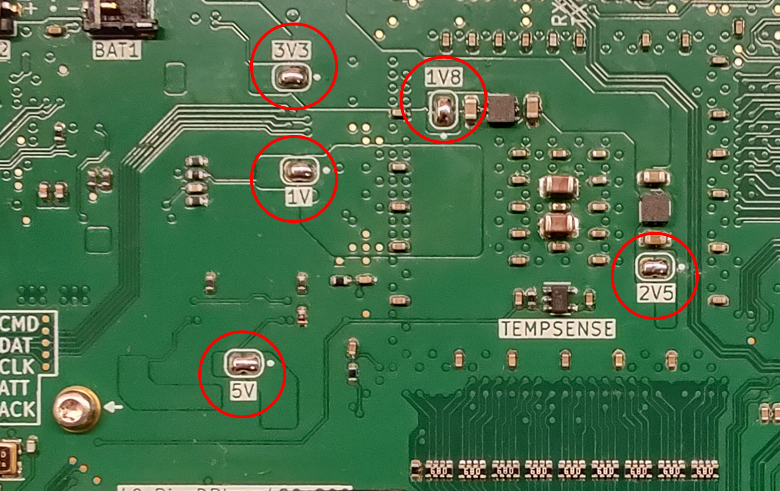
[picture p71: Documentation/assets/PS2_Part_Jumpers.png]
     
4. Temporarily plug in the DPI display to see the PS2 video output. Because we assembled the bumper bar and the lower display frame, we can just seat the display where it would go in the final assembly. Just make sure the backside doesn’t short anything on the mainboard.
5. With the display plugged in and the jumpers closed, plug the system into a USB-C charger capable of delivering at least 15W. Make sure to always connect the USB cable via the power meter to spot any abnormal current draw.
6. Push and hold the power button for at least 2 seconds and unpress it. 
7. Observe the PS2’s power LED labelled POWER (next to the debug header) and the USB power meter. The LED must go from red to green and the system should consume less than 10W. You should be greeted by: (depending on custom boot rom version)
    - A PS2BBL error message complaining about a missing config file 
    - First PS2BBL, then OSDSYS
8. Quick-Press the power button and ensure that the SysCon menu is displayed.

    > **First Troubleshooting**  
    > - If you see abnormally high power consumption, unplug immediately and check for shorts!  
    > - If the display stays black and you can’t enter the SysCon menu, but you hear the PS2 boot sound, there might be an issue with the FPGA, the GS, or in general the video config of the SysCon. Check the video data path in that case.  
    > - If you can get into the SysCon menu while the display is black, then the PS2 is at least outputting a valid video signal and the cause is most likely somewhere on the PS2 side. This might happen if some pins on the DSP or boot rom are shorted, or if the bios is non-functional.  
    > - If the display stays black and there is no sound & you can’t enter the SysCon menu, then you will have to start serious troubleshooting. Most of the time it is caused by shorts or open connections, so start by thoroughly inspecting the mainboard again. I pray for you that the issue is not under one of the BGAs…   

9. If you get an image, audio, and the SysCon menu is accessible, the chances of success are very high!
10.	Remember, the EE doesn’t have a thermal pad yet, so try to power off the system before the EE reaches 45°C, by long-pressing the power button while not in the SysCon menu. The system should power off
11.	Unplug the USB-C cable.
 

### Step 3: Flashing the Battery Protector
Now that we know that most of the mainboard is functional, it is time to program the MAX17320 and get the system powered by batteries.
1. In order to avoid confusion and fire, it is highly recommended that you mark the positive and negative contacts of the 21700 cells. The image below shows the polarity, but be sure to always double-check with a multimeter and in case of doubt consult the battery’s datasheet.  
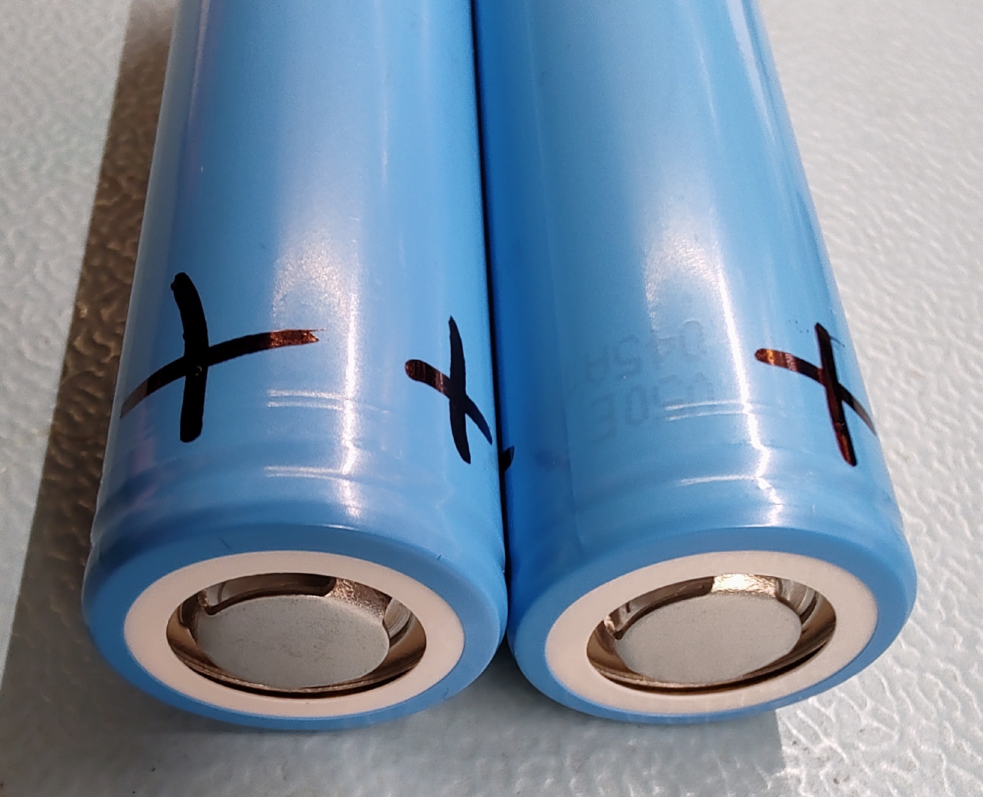
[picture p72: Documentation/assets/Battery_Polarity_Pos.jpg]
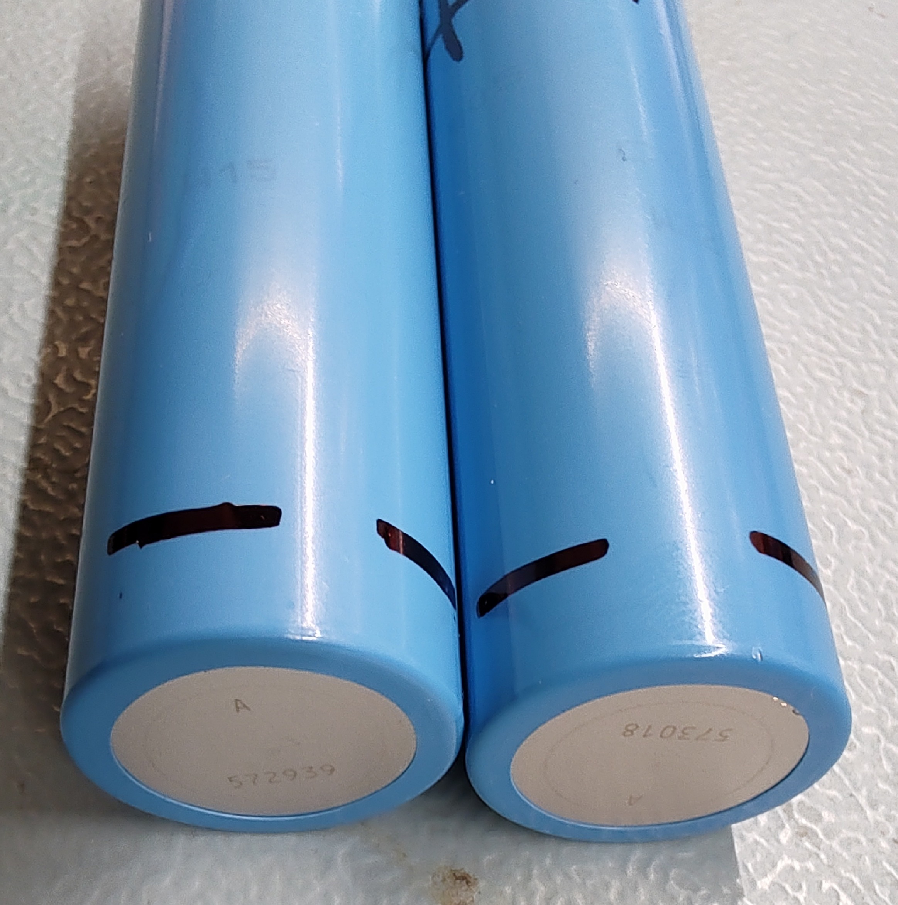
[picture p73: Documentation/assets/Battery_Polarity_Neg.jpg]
      
2. If not done yet, plug the battery connectors into the mainboard, check that red goes to + and black to - everywhere.

    > BE VERY CAREFUL TO NOT INSERT THE BATTERIES WITH WRONG POLARITY!!! THIS CAN AND WILL BREAK YOUR SYSTEM!!!!
3. Insert the batteries with correct polarity -> the battery compartment has + and – marked for both gamepads.
4. Connect the system to a PC using a USB-C cable with USB-C power monitor, while holding the BOOTSEL button (select button on right gamepad), an explorer window opens and the SysCon shows up as USB storage device. 
5. Now drag the SysCon firmware compiled for Step 3 into the window to flash it.
    > **To obtain the correct firmware:**  
    > Uncomment only the line `#define MFG_STEP_3` in the file MCU_Interface.h and compile the SysCon firmware. See [Part 10](https://github.com/tschicki/PS2-Portable/blob/main/Documentation/Part%2010_Development%20and%20Debugging.md) for more details.    
    >
    > **What this version of the firmware does:**
    > -	Load the MAX17320 config into its nonvolatile memory upon long-pressing the power button, then halt until the USB-C cable is unplugged
    >
    > Beware that the MAX17320 NVM has very limited write cycles, so only do this once or twice!

5. When the firmware was programmed, long-press the power button for the MAX17320 to be programmed.
6. This process can take about 10 seconds, then determine whether the operation was successful:
    - The LED blinks green -> SUCCESS
    - The LED blinks red/blue -> NVM write failed
7. Unplug the USB cable and continue with step 4. This firmware blocks charging entirely, so you can only give charging a try after flashing the final firmware below. 

### Step 4: Flashing the Final Firmware
1. Connect the system to a PC using a USB-C cable with USB-C power monitor, while holding the BOOTSEL button (select button on right gamepad), an explorer window opens and the SysCon shows up as USB storage device. 
2. Now drag the final SysCon firmware into the window to flash it.
    > **To obtain the correct firmware:**  
    > Ensure that `#define MFG_STEP_1`, `#define MFG_STEP_2` and `#define MFG_STEP_3` are all commented out again before compiling. See [Part 10](https://github.com/tschicki/PS2-Portable/blob/main/Documentation/Part%2010_Development%20and%20Debugging.md) for more details.   
    >
    > **What this version of the firmware does:**
    > -	It's the final firmware compiled without bringup / debug flags!
3. Unplug the USB-C cable from the PC and plug in a USB-C PD capable charger, do not power the system on yet!
4. The system should now charge with about 9W to 10W, as indicated by the status LED
    - For the first charging attempt it is possible that a charging error is displayed. This happens usually when batteries were unplugged. Try replugging the USB-C cable.
    - Latest at the second attempt, the power LED indicates charging.
5. If charging works, unplug the charger and try powering on the system from batteries by long-pressing the power button.
    - You should be greeted by the same screen as in step 2.

# End
You have now successfully:
-	Assembled the PS2 AIO mainboard
-	Checked all supplies for short circuits
-	Programmed the configs of both USB-C PD controller and battery protector
-	Verified the correct functionality of the PS2 circuits  
-	Programmed the SysCon firmware

It was already noted in the beginning that all the mechanical assembly so far was temporary. Everything but the gamepad sub-assemblies can be disassembled again for the proper assembly steps.

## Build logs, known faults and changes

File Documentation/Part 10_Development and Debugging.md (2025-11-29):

# Part 10: Development and Debugging
This part of the assembly documentation will describe what you need to get started with developing and debugging SysCon and video processor code.
It is highly recommended to build the PS2 Debugger described in [Part 8](https://github.com/tschicki/PS2-Portable/blob/main/Documentation/Part%208_Accessories%20Assembly.md) for this!

## Tooling
### Firmware (SysCon & Gamepads)
You need to setup the tooling in order to program and/or debug the SysCon and gamepads. What you need to do first:
- Install VSCode
- Install the [Raspberry Pi Pico extension](https://marketplace.visualstudio.com/items?itemName=raspberry-pi.raspberry-pi-pico)

In the Raspberry Pi Pico Quick Access Tab on the left you can import the [SysCon project](https://github.com/tschicki/PS2-Portable/tree/main/SysCon%20Firmware/SysCon_FW) and [gamepad project](https://github.com/tschicki/PS2-Portable/tree/main/SysCon%20Firmware/PS2_Gamepad_02). Clean CMake and you should be good to go for developing and compiling both SysCon and gamepad code! Don't forget to set the build type to debug for debugging!

This setup is also required for manufacturing the *PS2 AIO Mainboard*, as you will need to compile the SysCon and gamepad firmware.

### Gateware
The Video Processor is an Efinix Trion T20 FPGA, so you need to download the [Efinity software](https://www.efinixinc.com/products-efinity.html) for creating a valid bistream for it. You need to create an account, but the software is free.
The FPGA project is located [here](https://github.com/tschicki/PS2-Portable/tree/main/SysCon%20Firmware/SysCon_FW/ps2_video_processor) and called sdram.xml. Open it in Efinity and from here on you should be able to run the full workflow.

## SysCon

### Manufacturing
For the SysCon, the only file you will need to touch for manufacturing is called [MCU_Interface.h](https://github.com/tschicki/PS2-Portable/blob/main/SysCon%20Firmware/SysCon_FW/inc/MCU_interface.h) and can be found in the ./inc/ folder. Right below all the includes are the three defines of interest *MFG_STEP_1*, *MFG_STEP_2*, *MFG_STEP_3*. They need to be included (or not) according to the instructions given in [Part 6](https://github.com/tschicki/PS2-Portable/blob/main/Documentation/Part%206_Mainboard%20Bringup.md). When these are set as required, make sure the build type is set to *release* and compile the project. Afterwards, you should find the file *main.uf2* in the *build* folder inside the SysCon project, this is the file to flash the the SysCon via USB. Just check the plausibility of its timestamp before you flash it. 

### Developing
For developing you will need the *PS2 Debugger* to interface with the SysCon. It connects to the debug header on the heatsink-side of the *PS2 AIO Mainboard*. The debugger features SWD, UART and JTAG (for the T20), but does not provide power - so you will need to connect the mainboard to a charger for debugging. The *MCU_Interface.h* file also has some interesting debug flags to print status information via UART, which can be observed using the debugger's COM port.

## Gamepads
### Manufacturing and Developing
The tooling for both gamepads is the same as the SysCon, but they don't have a USB interface to load the firmware. Here the debugger is mandatory (either the *PS2 Debugger* or a pico debug probe) to upload the code using the *Flash Project (SWD)* button in the Pico SDK. In order for this to work, the system needs to be plugged in a charger to power the gamepads.

## Video Processor
Luckily you don't need to touch the video processor during manufacturing.
### Developing
After setting up the tooling you can modify the gateware to your hearts content. For testing your code on hardware you have two options:
- After you created the bitstream, recompile the SysCon firmware and upload it to the SysCon. The FPGA bitstream is embedded in the firmware at compile time and the SysCon takes care of loading it onto the T20. The script that takes care of the conversion from bitstream to C header file is here: */SysCon Firmware/SysCon_FW/generated/bit2source.py*
- Use the FT2232H Mini Module on the PS2 Debugger to load the bitstream via JTAG in the Efinity software (select the programmer on the top). It connects to the debug header on the heatsink-side of the *PS2 AIO Mainboard*.
    - The Syscon blocks JTAG access to the T20 by default, to disable this find the line `#define BLOCK_T20_JTAG` in MCU_Interface.h and comment it out; reflash the firmware to apply the change.
    - Now you can do all your T20 JTAG shenanigans while the PS2 is running!

No IP was used in the creation of the video processor, every module was written from scratch in VHDL. This should make the design quite portable with minimal changes! Have fun!

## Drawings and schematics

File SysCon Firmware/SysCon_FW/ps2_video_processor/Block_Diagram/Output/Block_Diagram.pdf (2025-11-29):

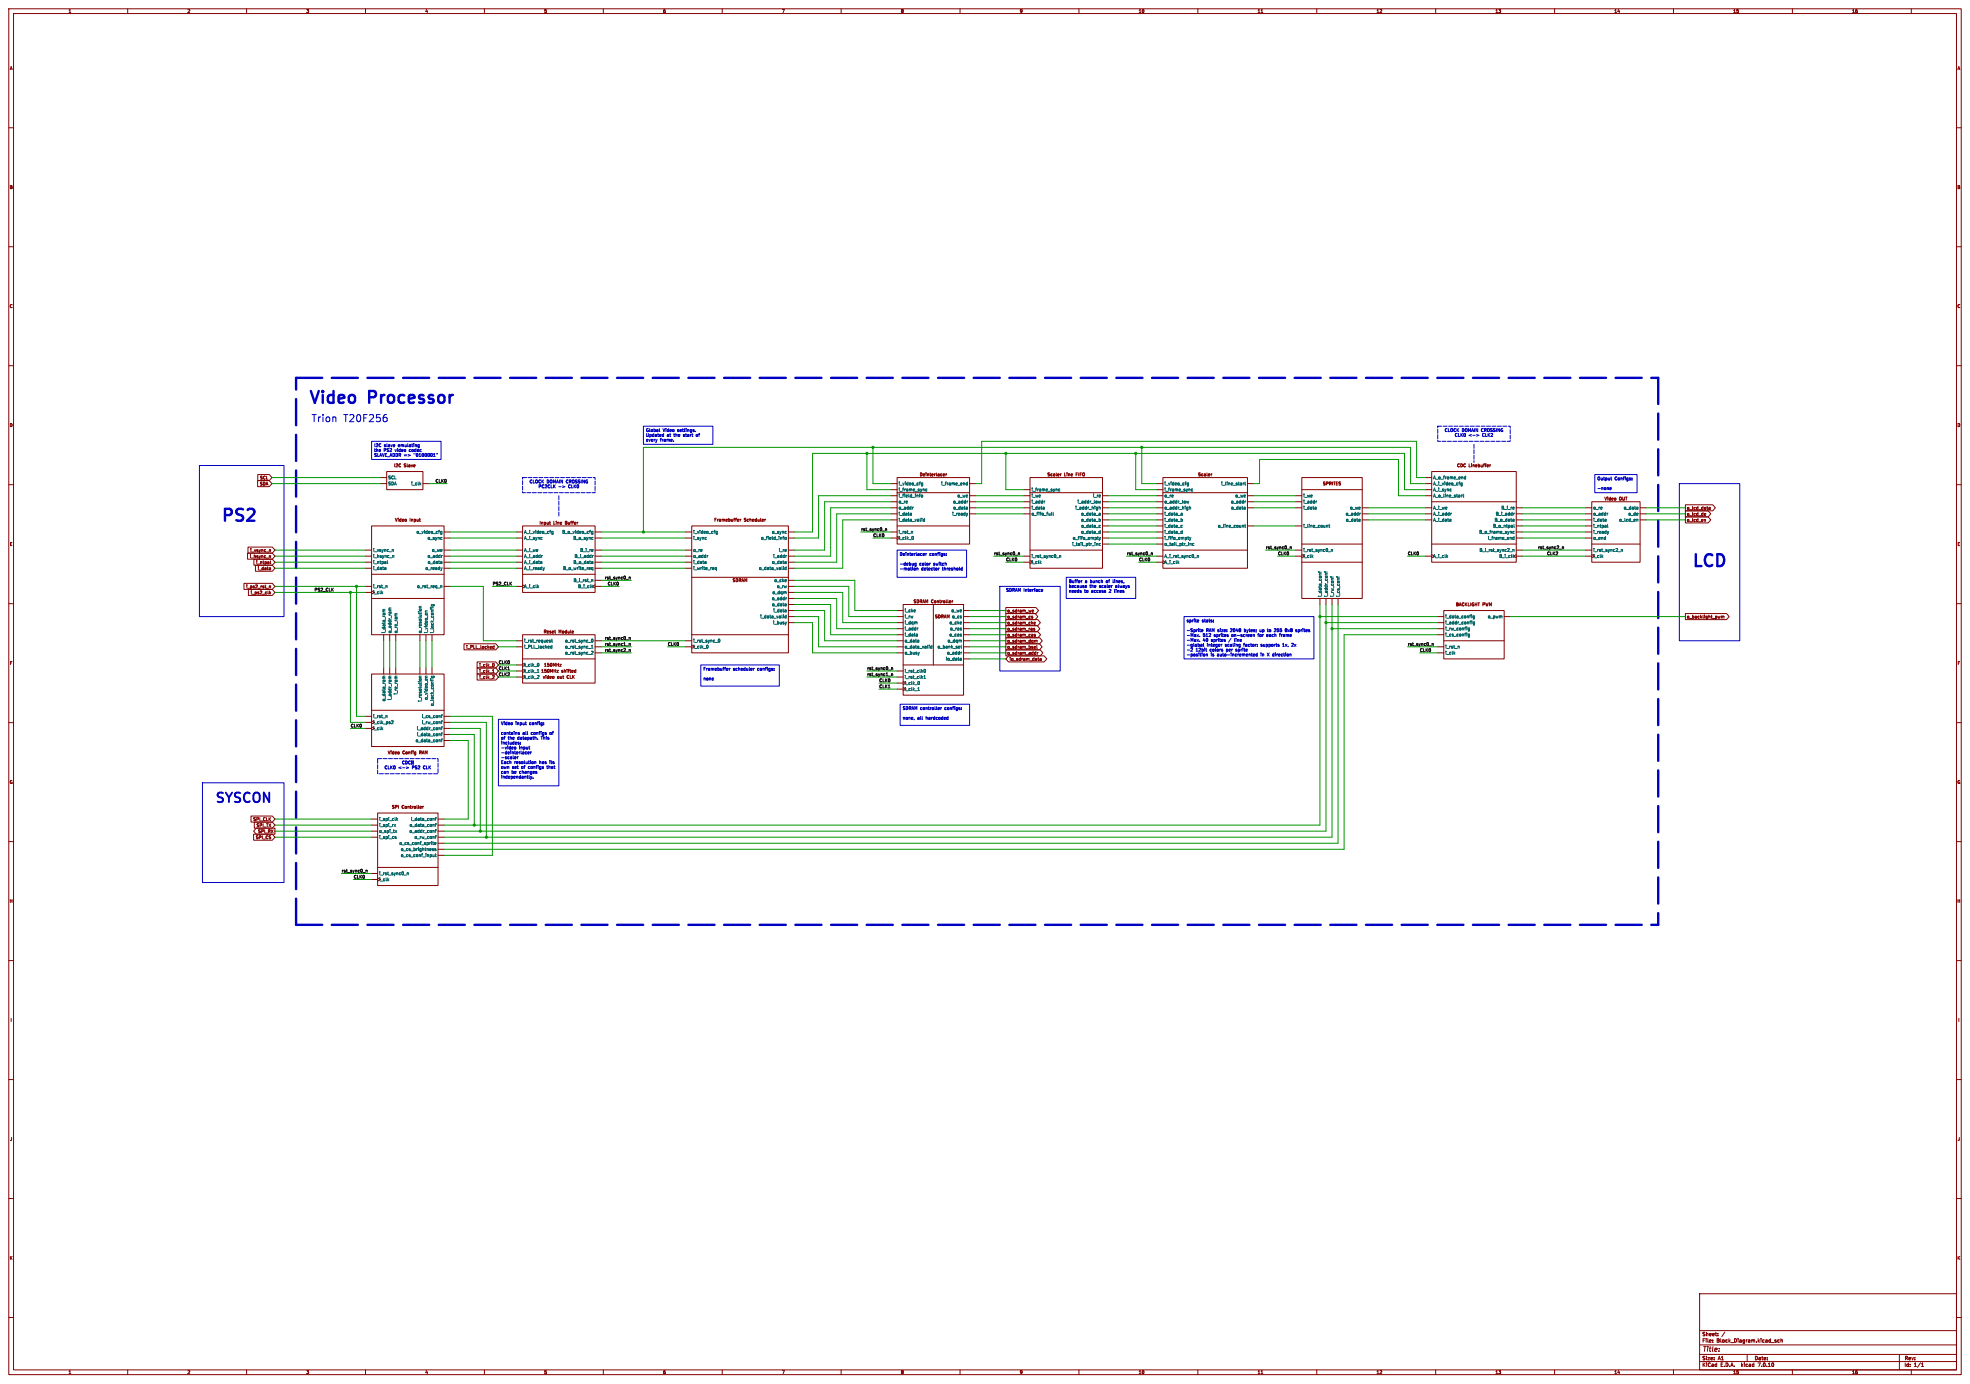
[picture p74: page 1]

Id: 1/1 Title: File: Block_Diagram.kicad_sch Sheet: /

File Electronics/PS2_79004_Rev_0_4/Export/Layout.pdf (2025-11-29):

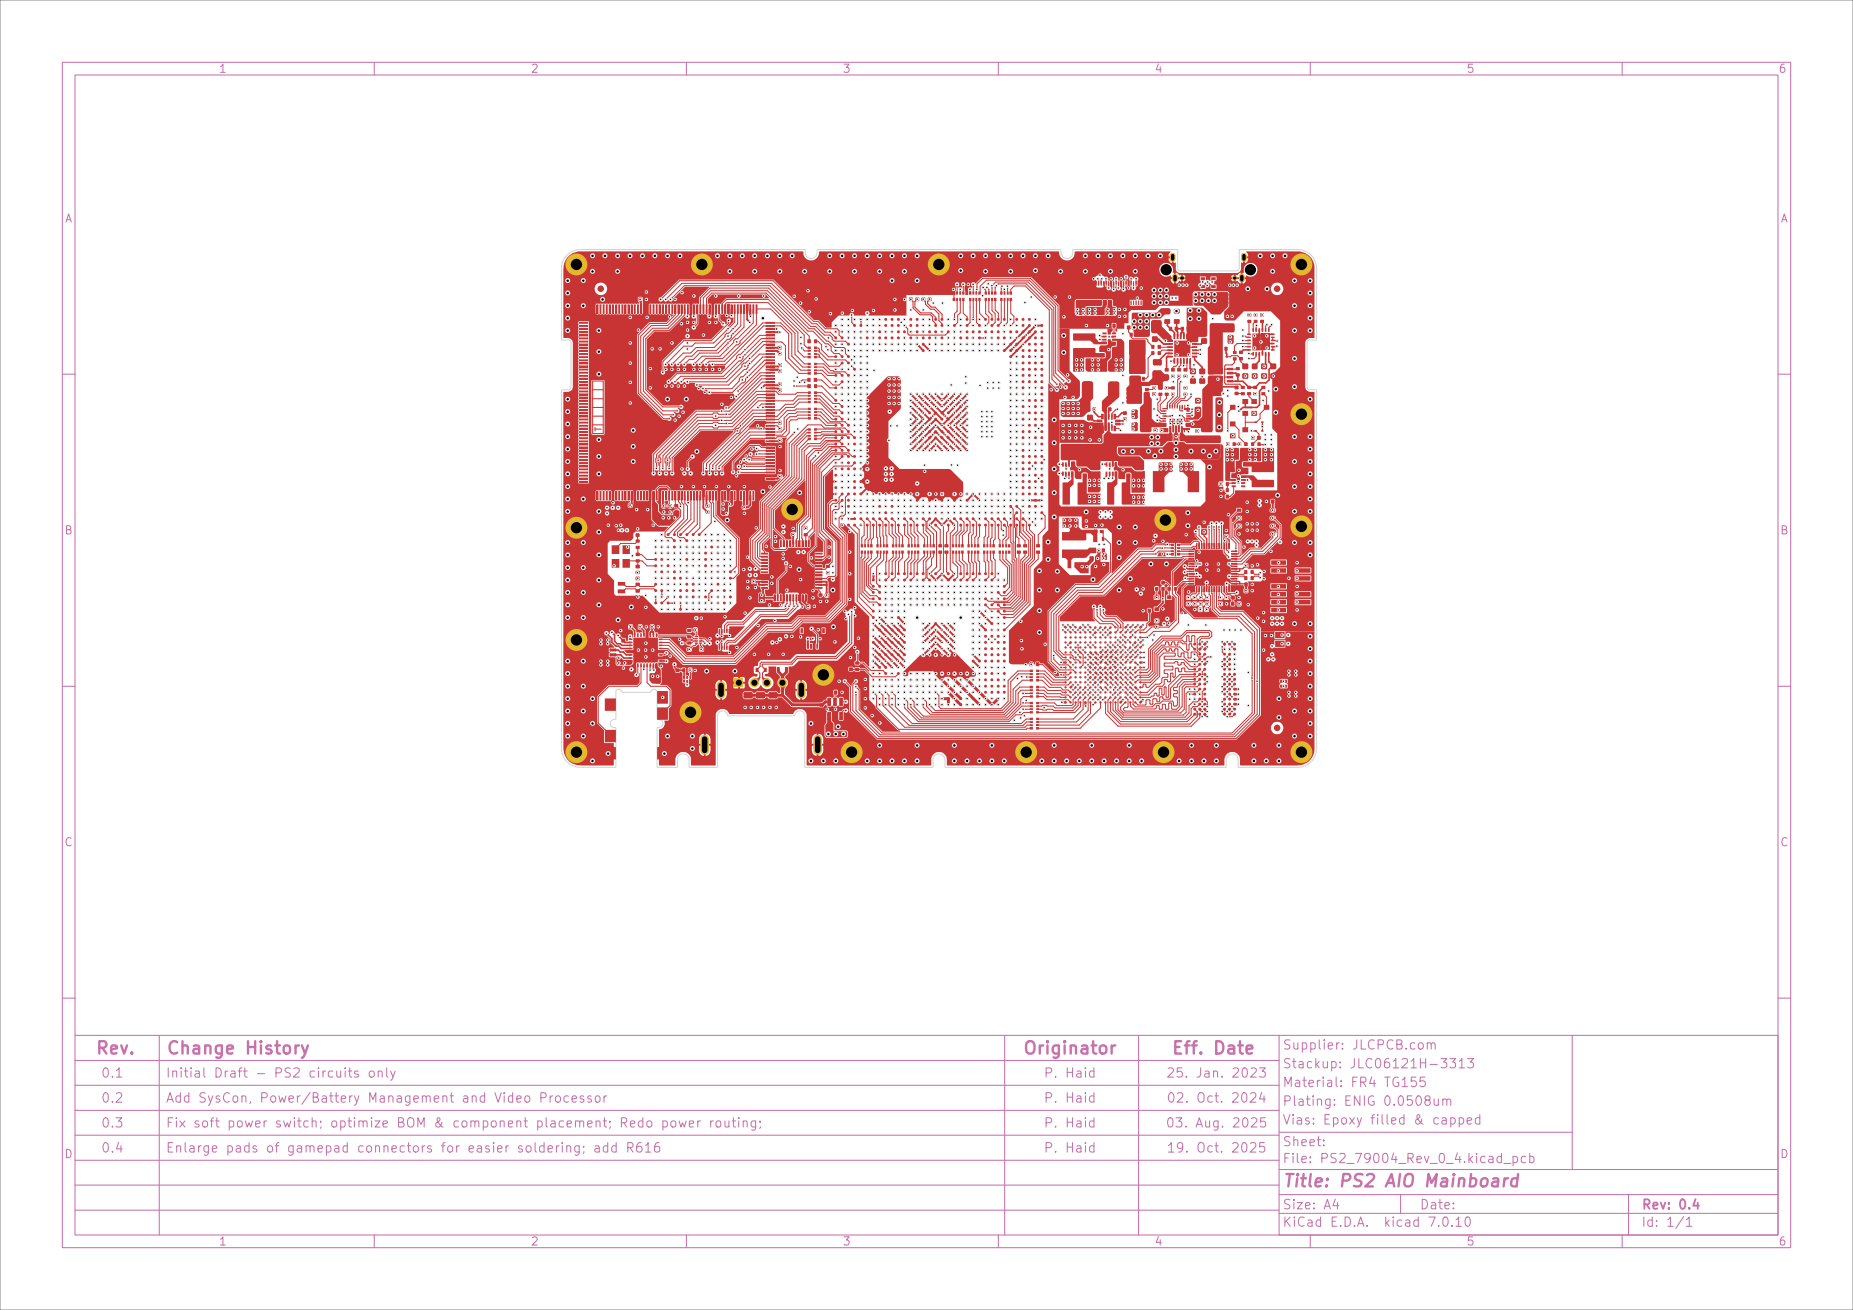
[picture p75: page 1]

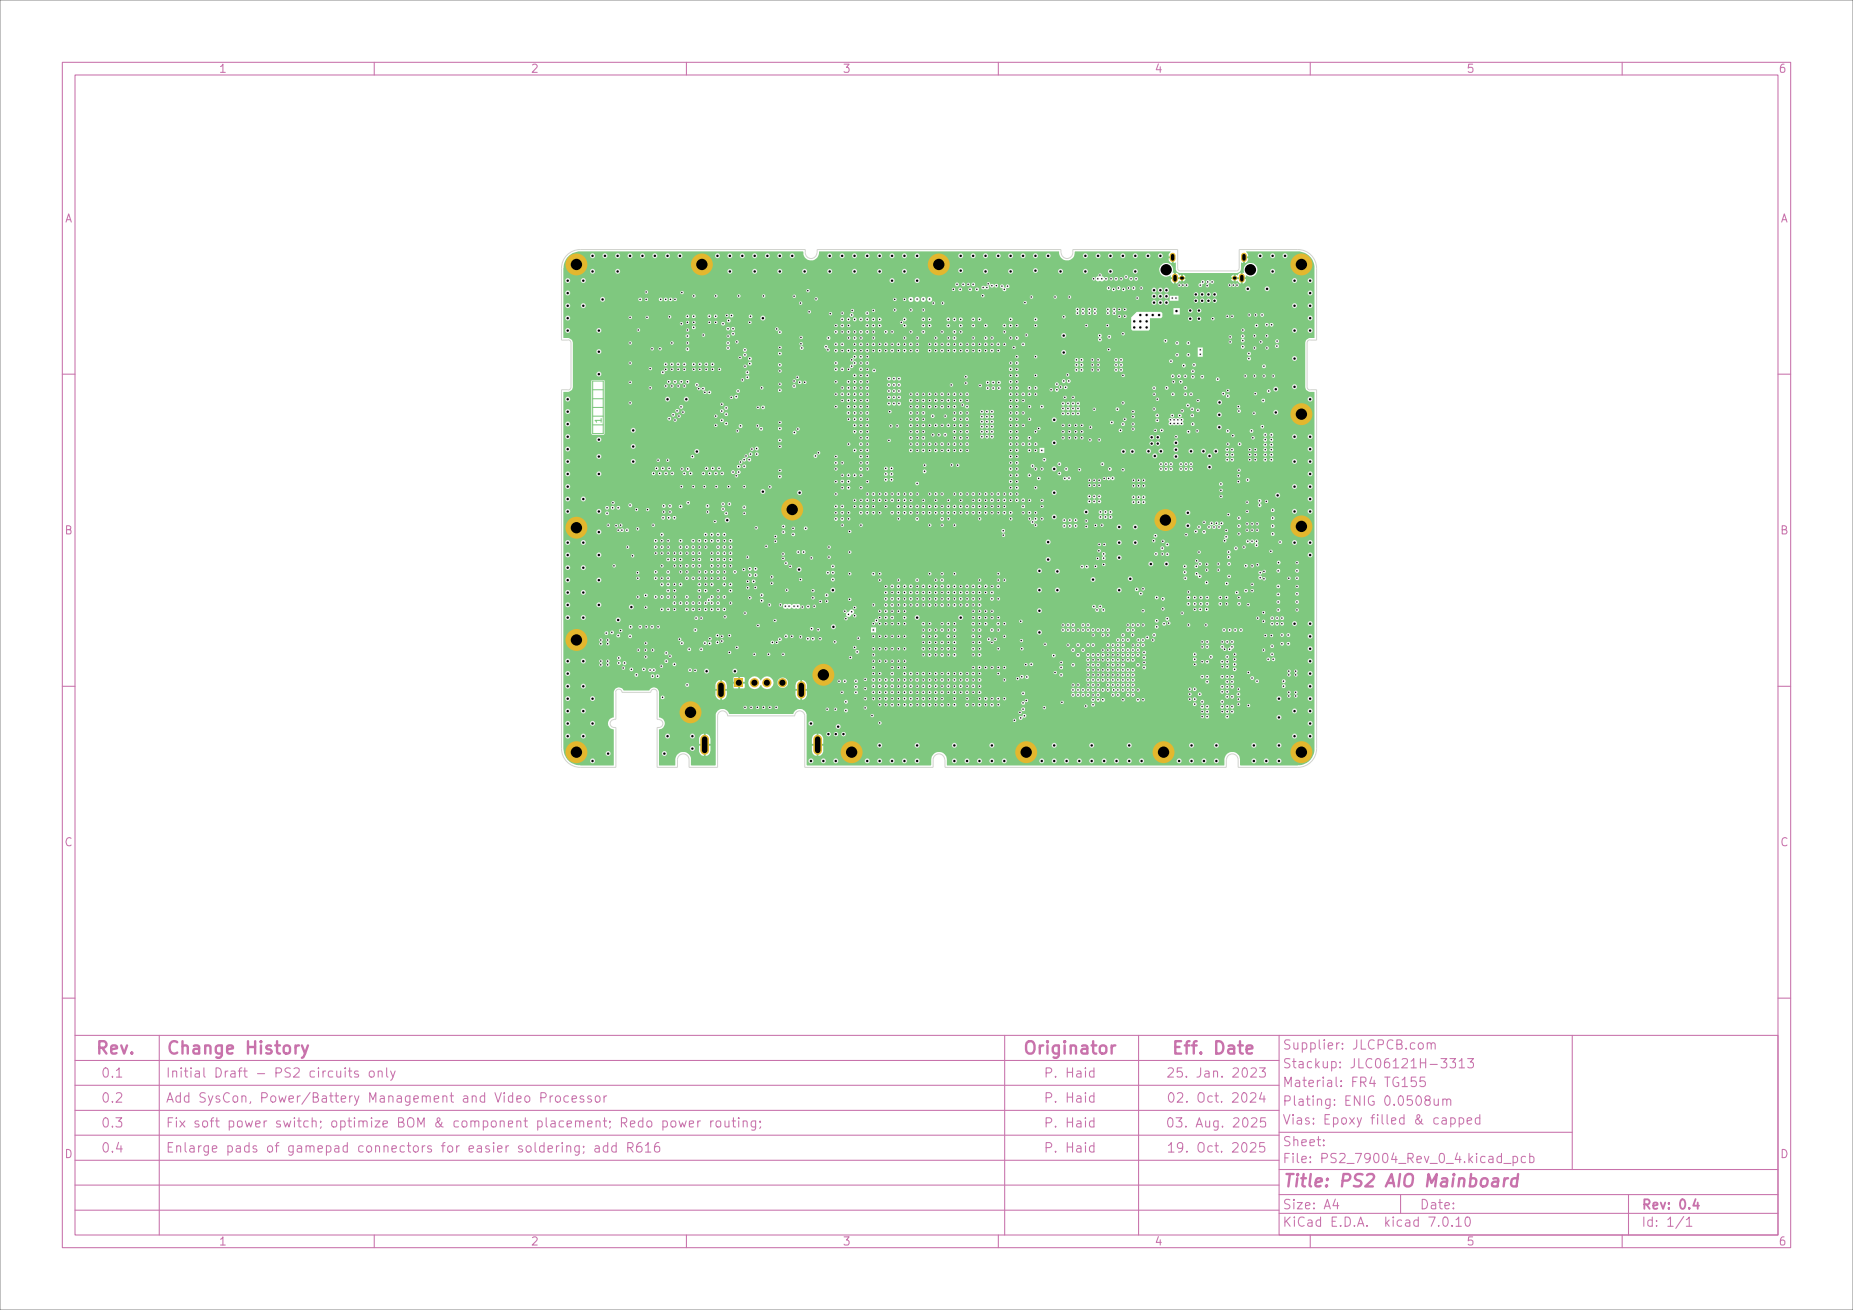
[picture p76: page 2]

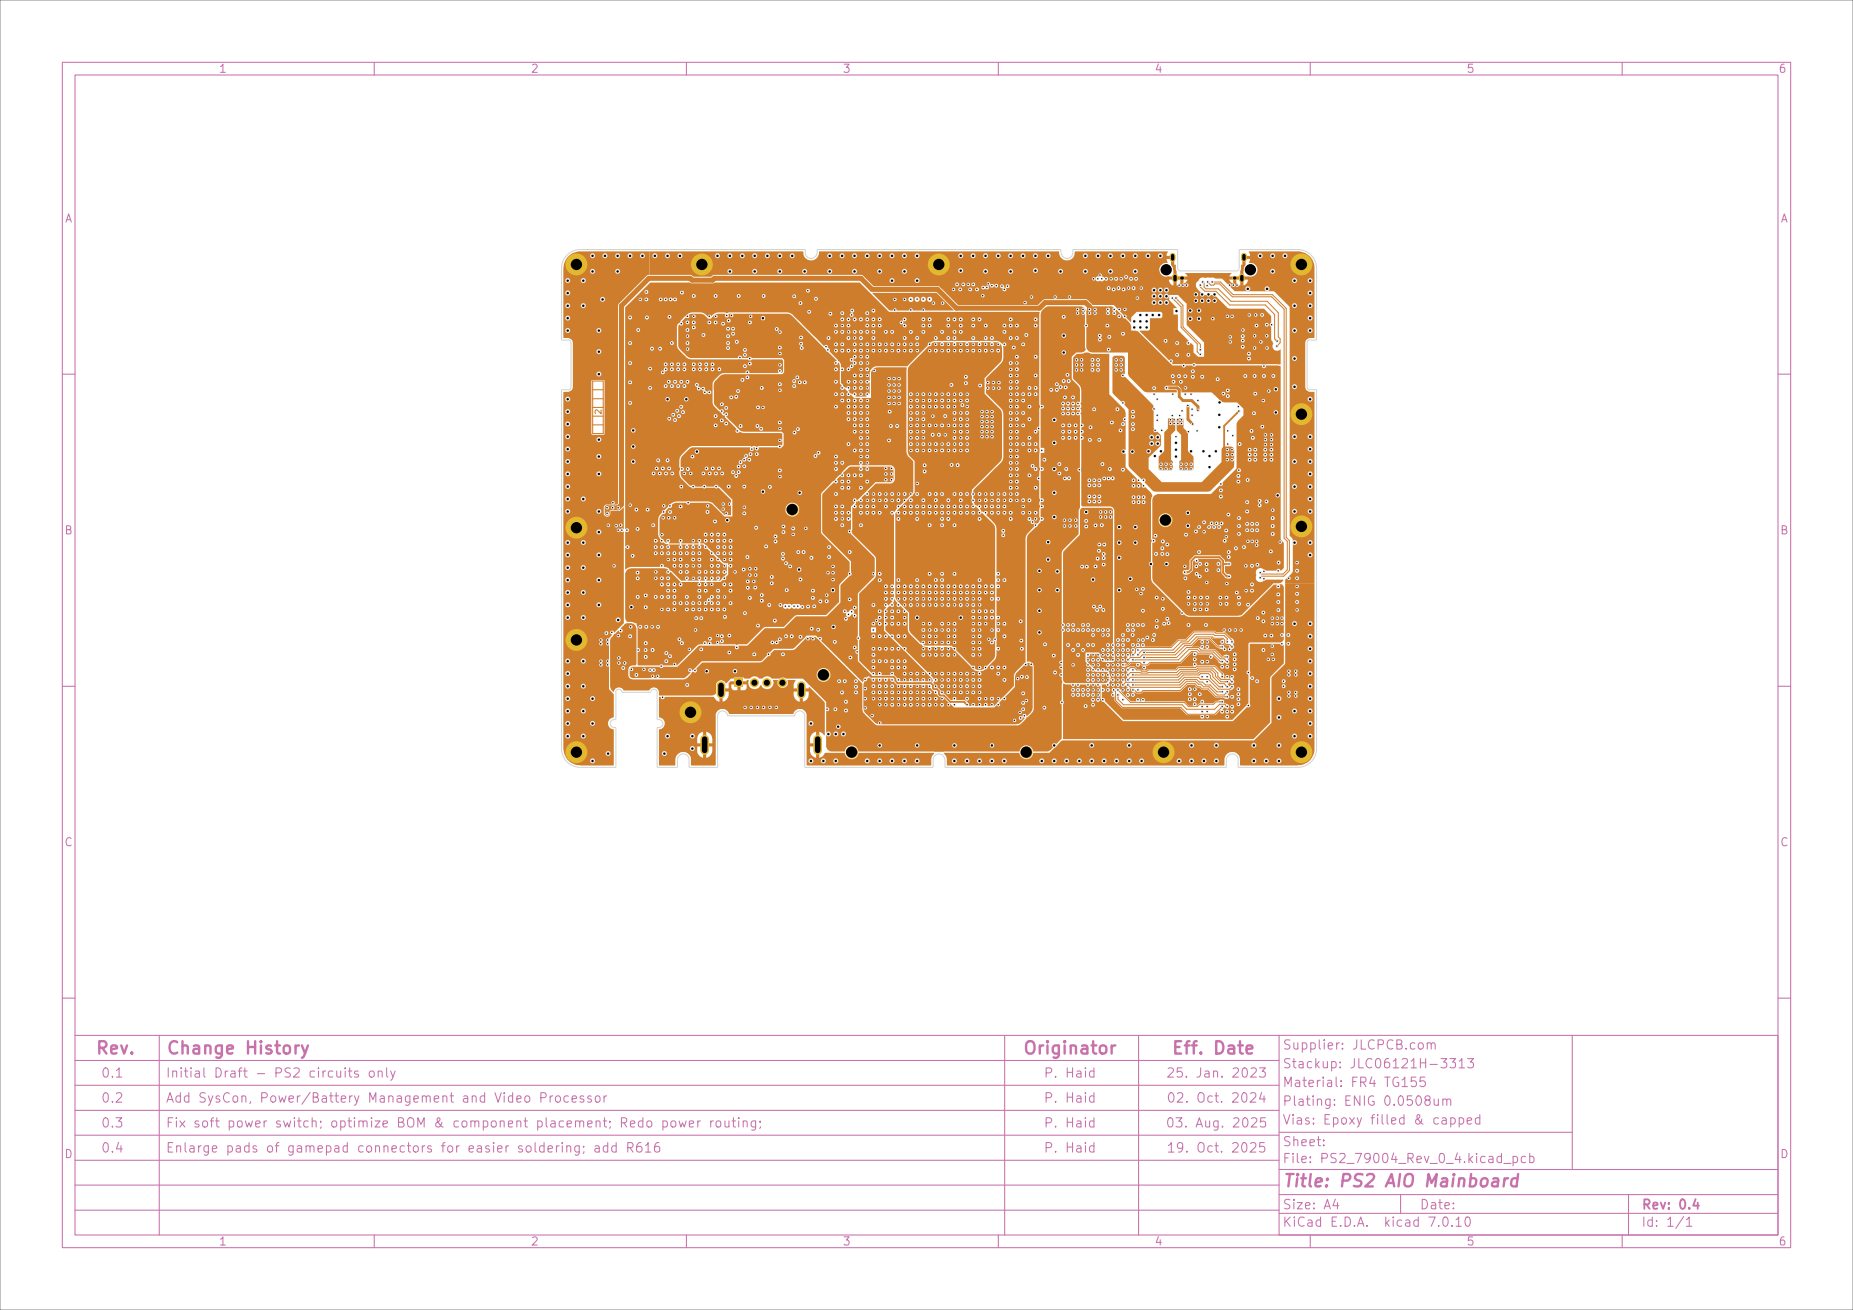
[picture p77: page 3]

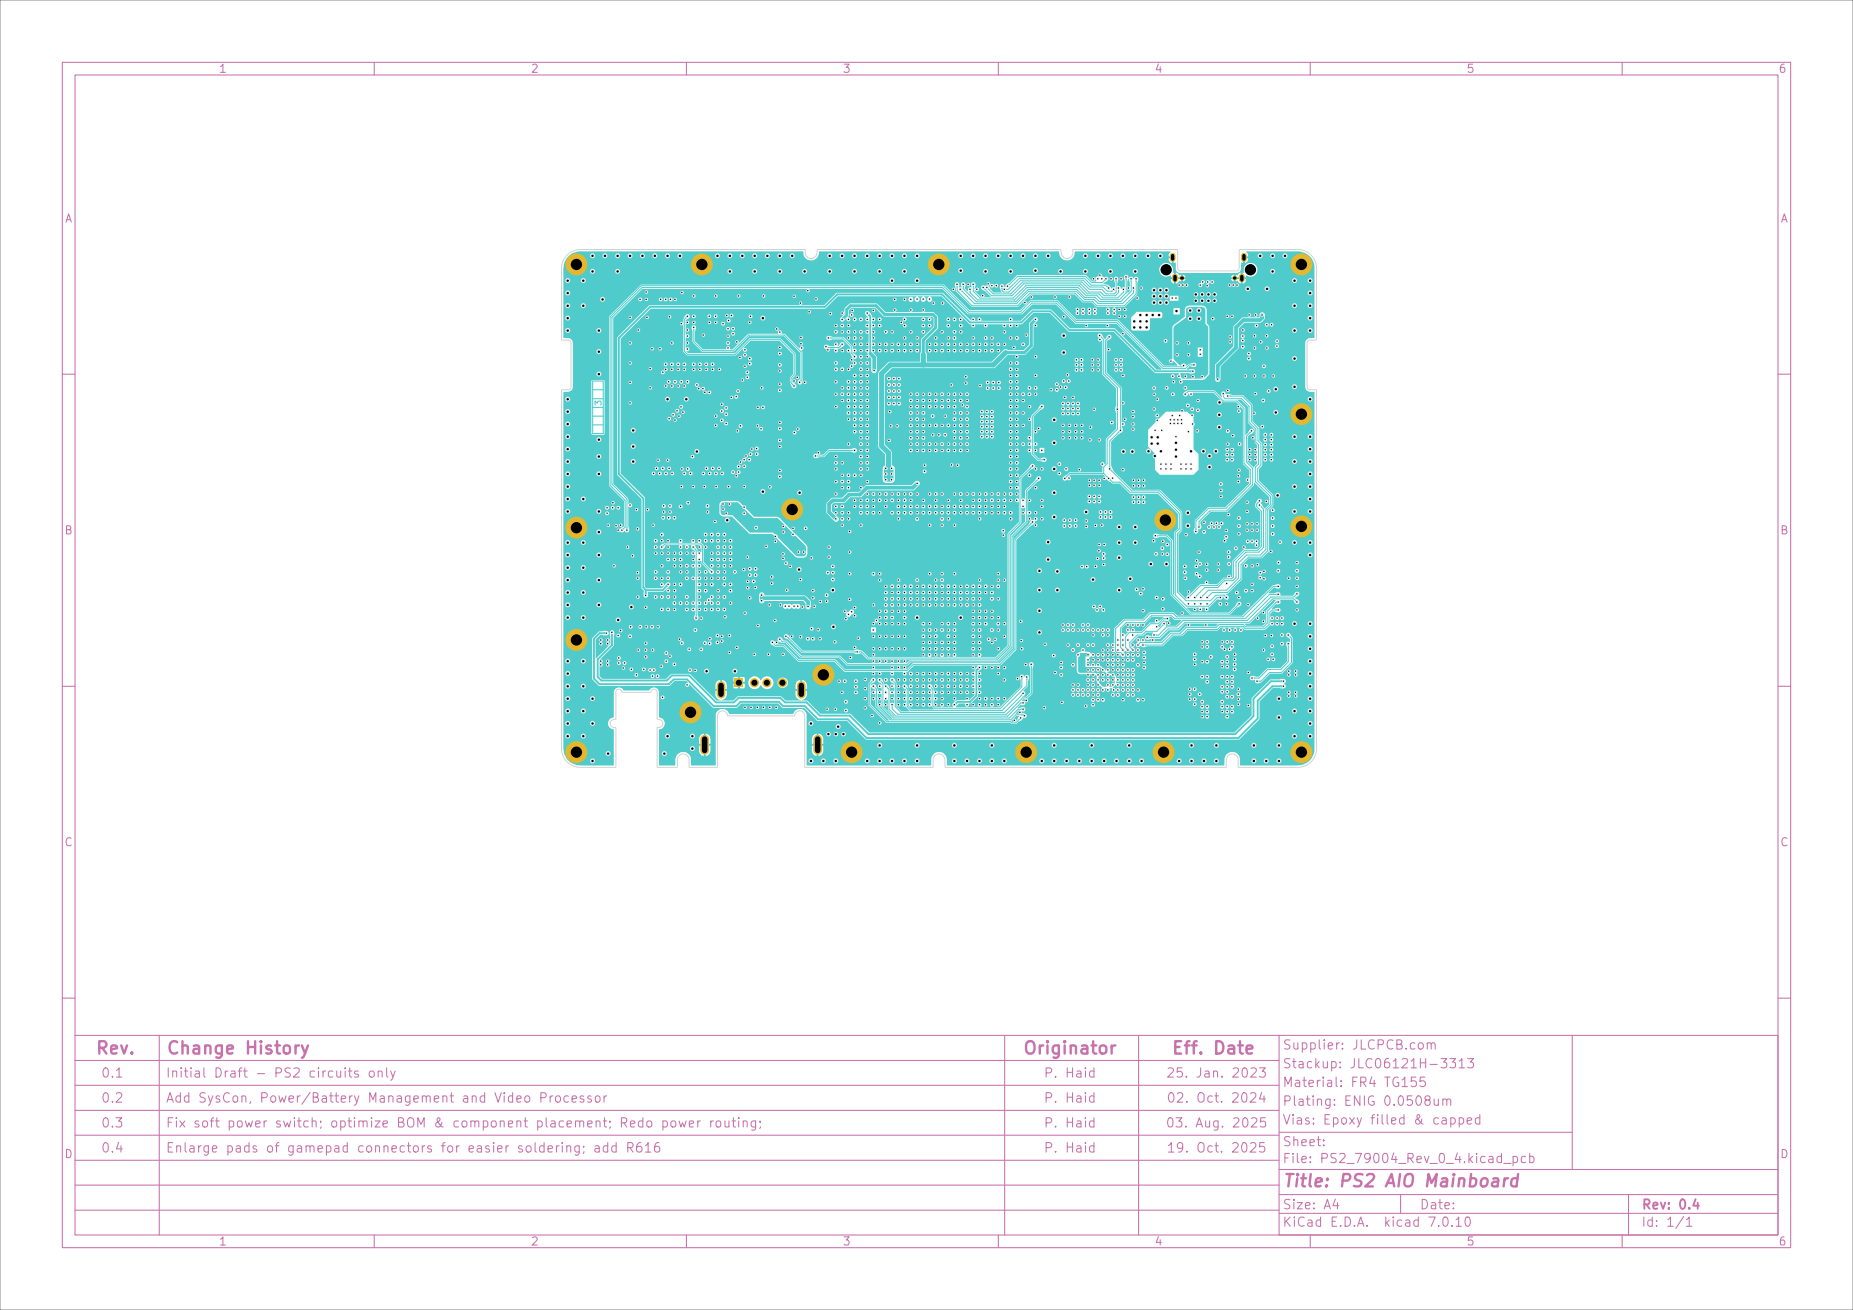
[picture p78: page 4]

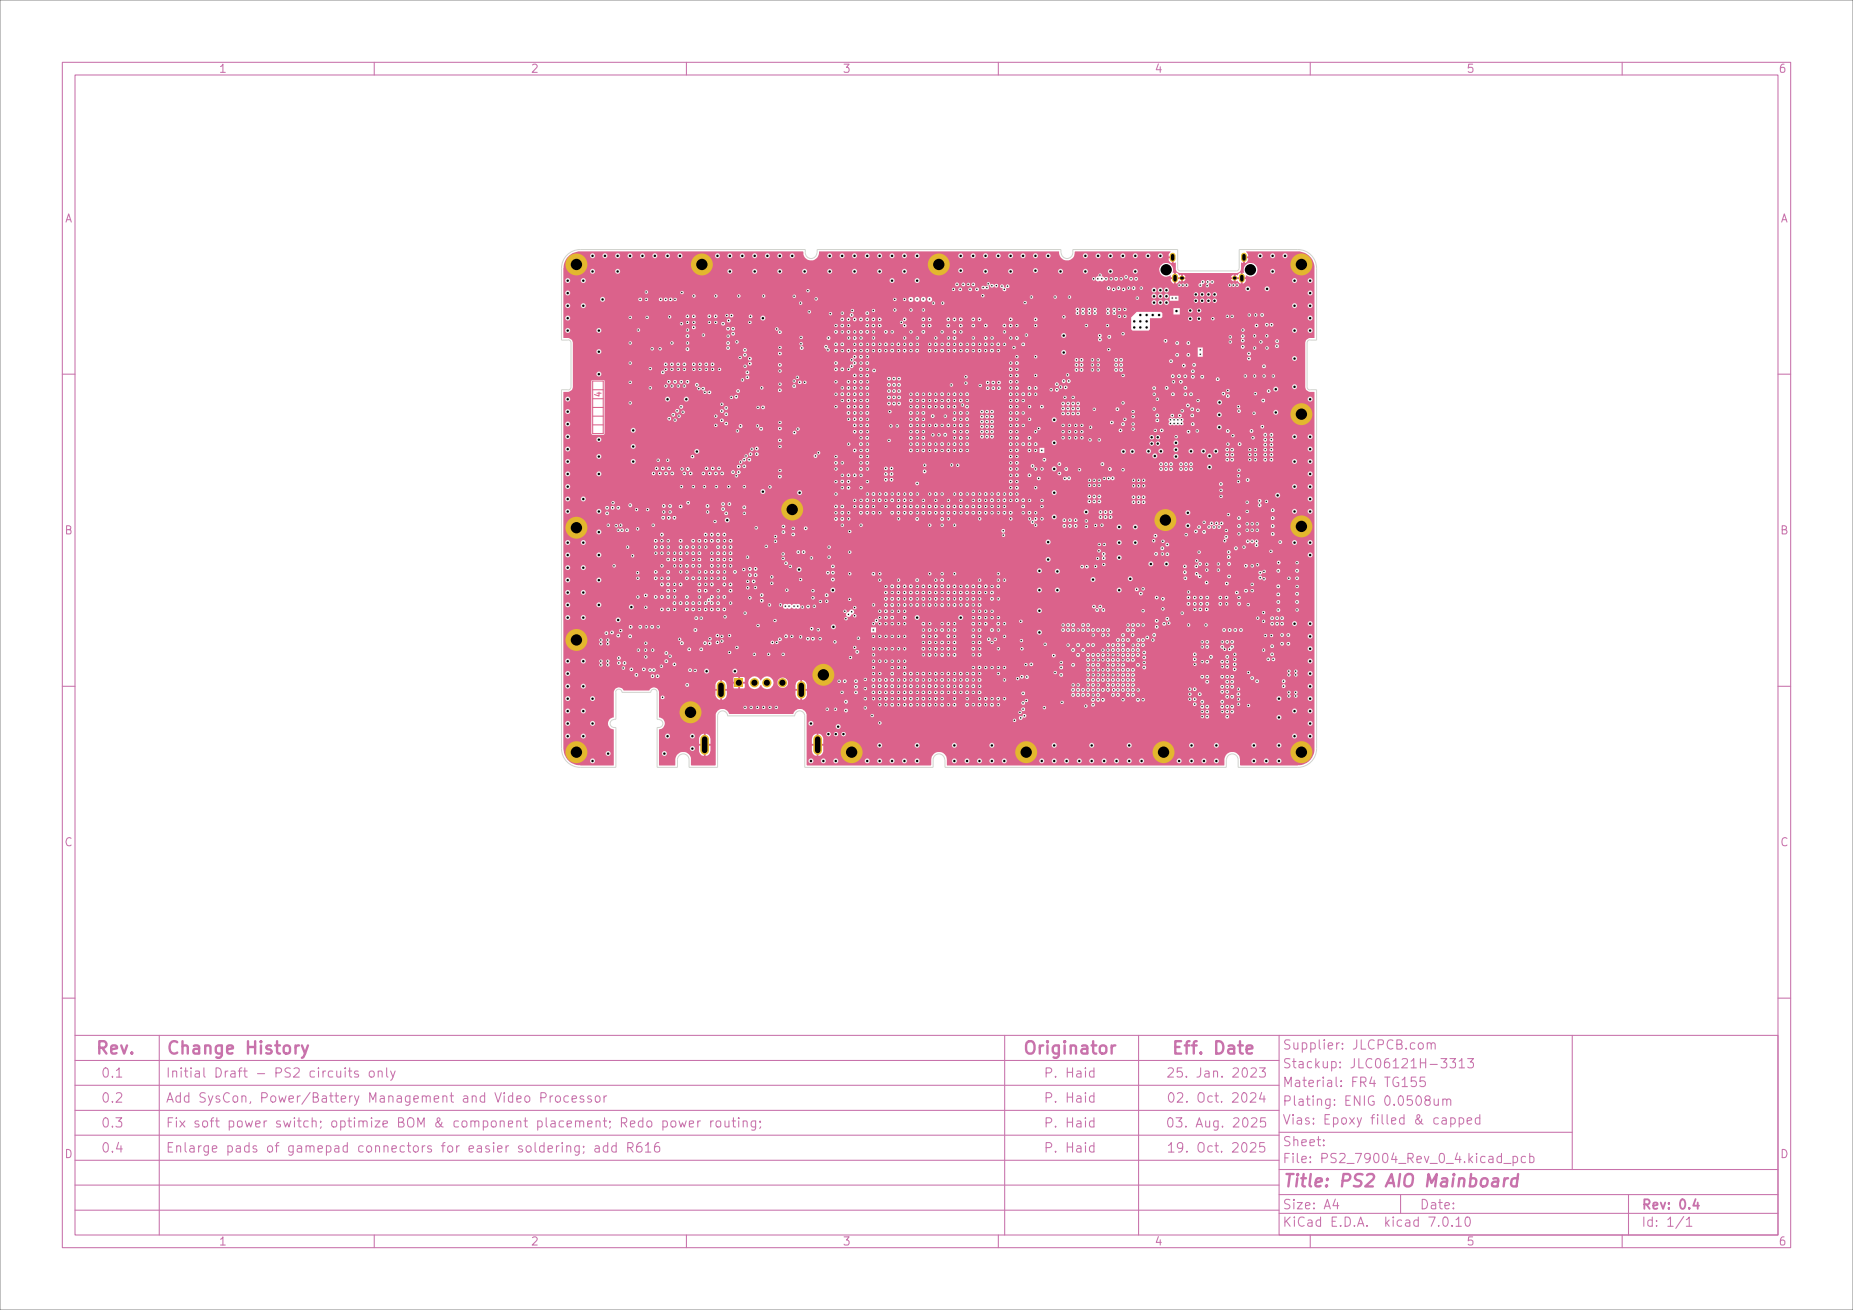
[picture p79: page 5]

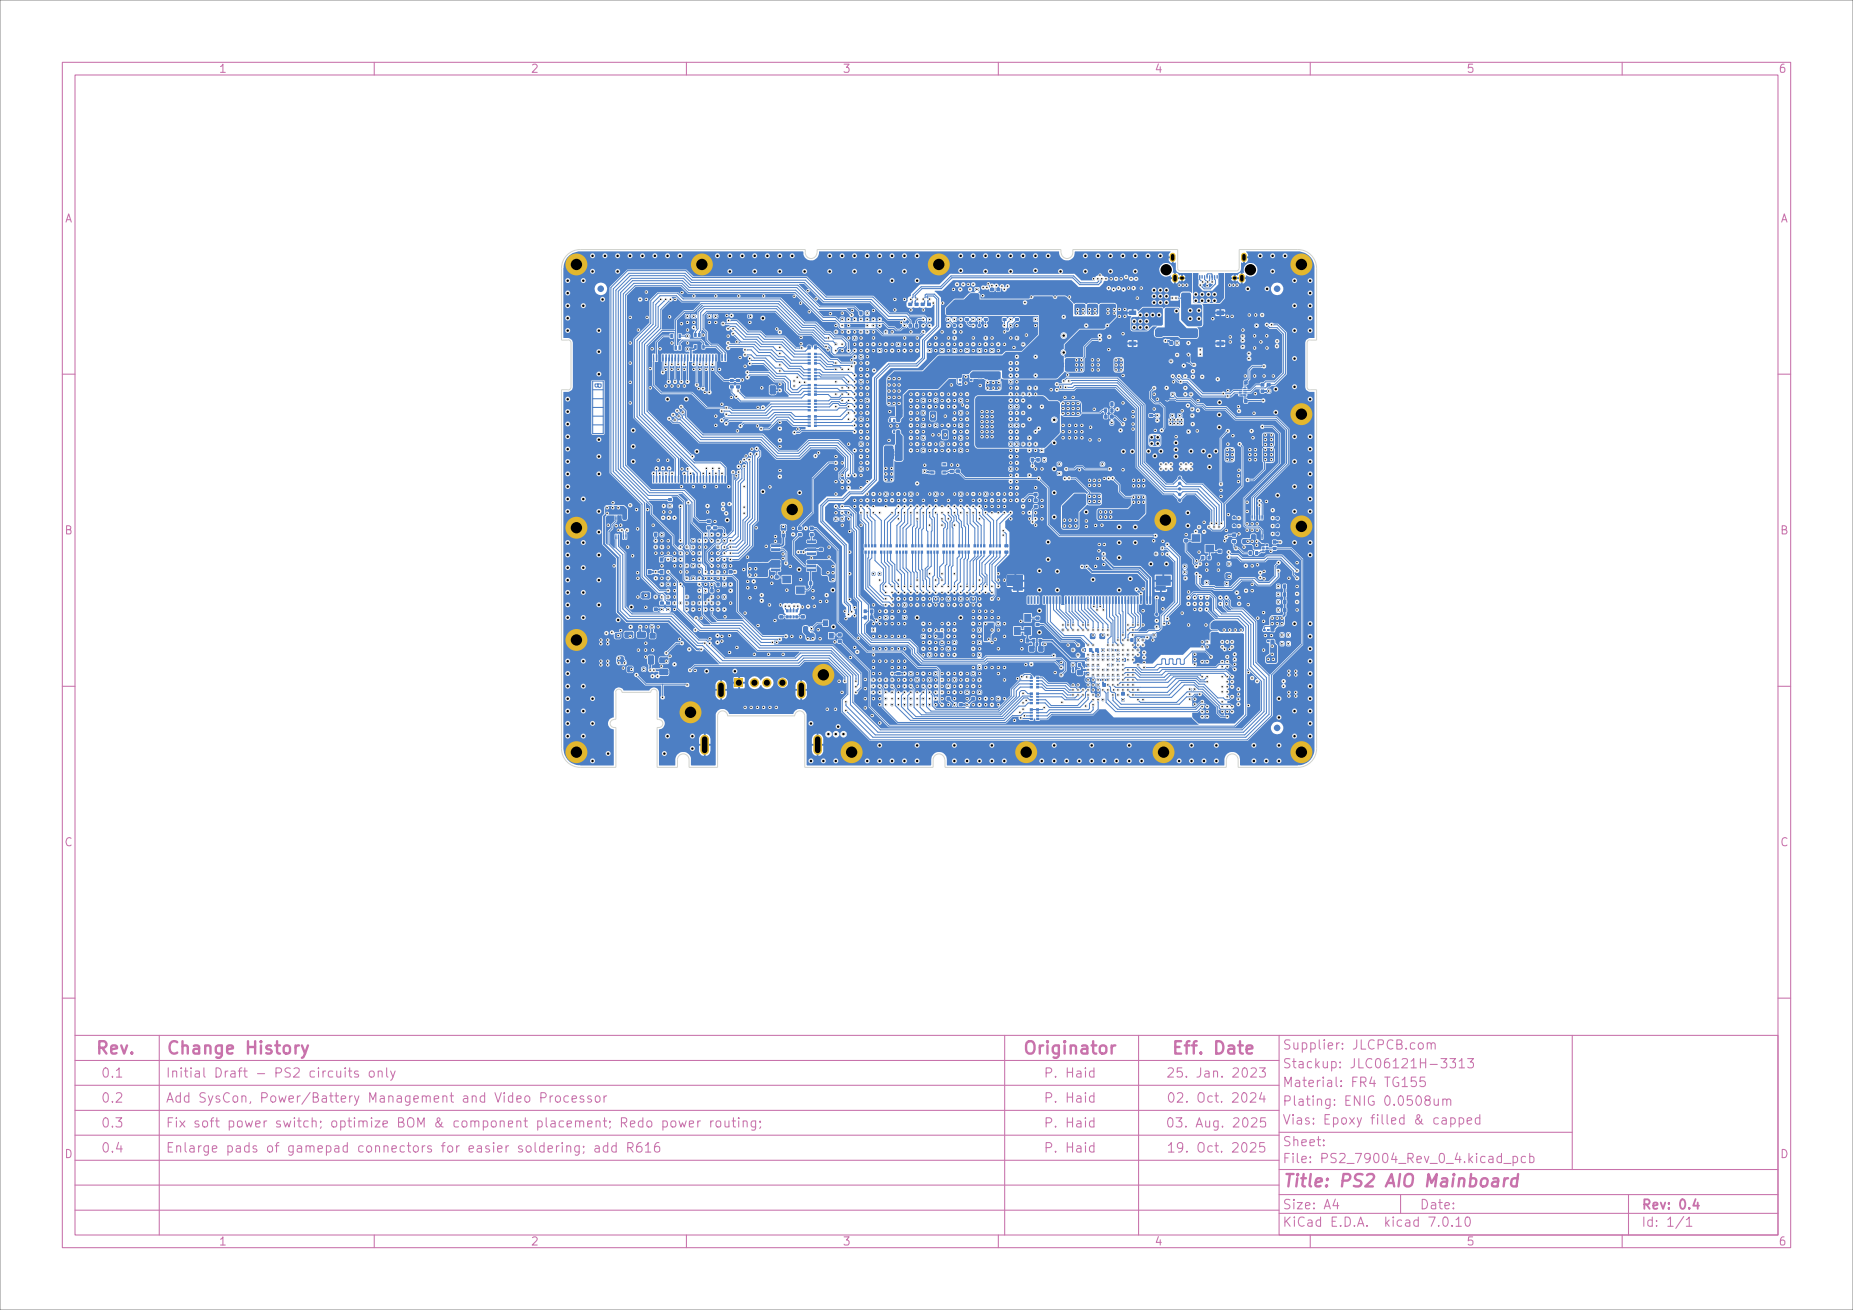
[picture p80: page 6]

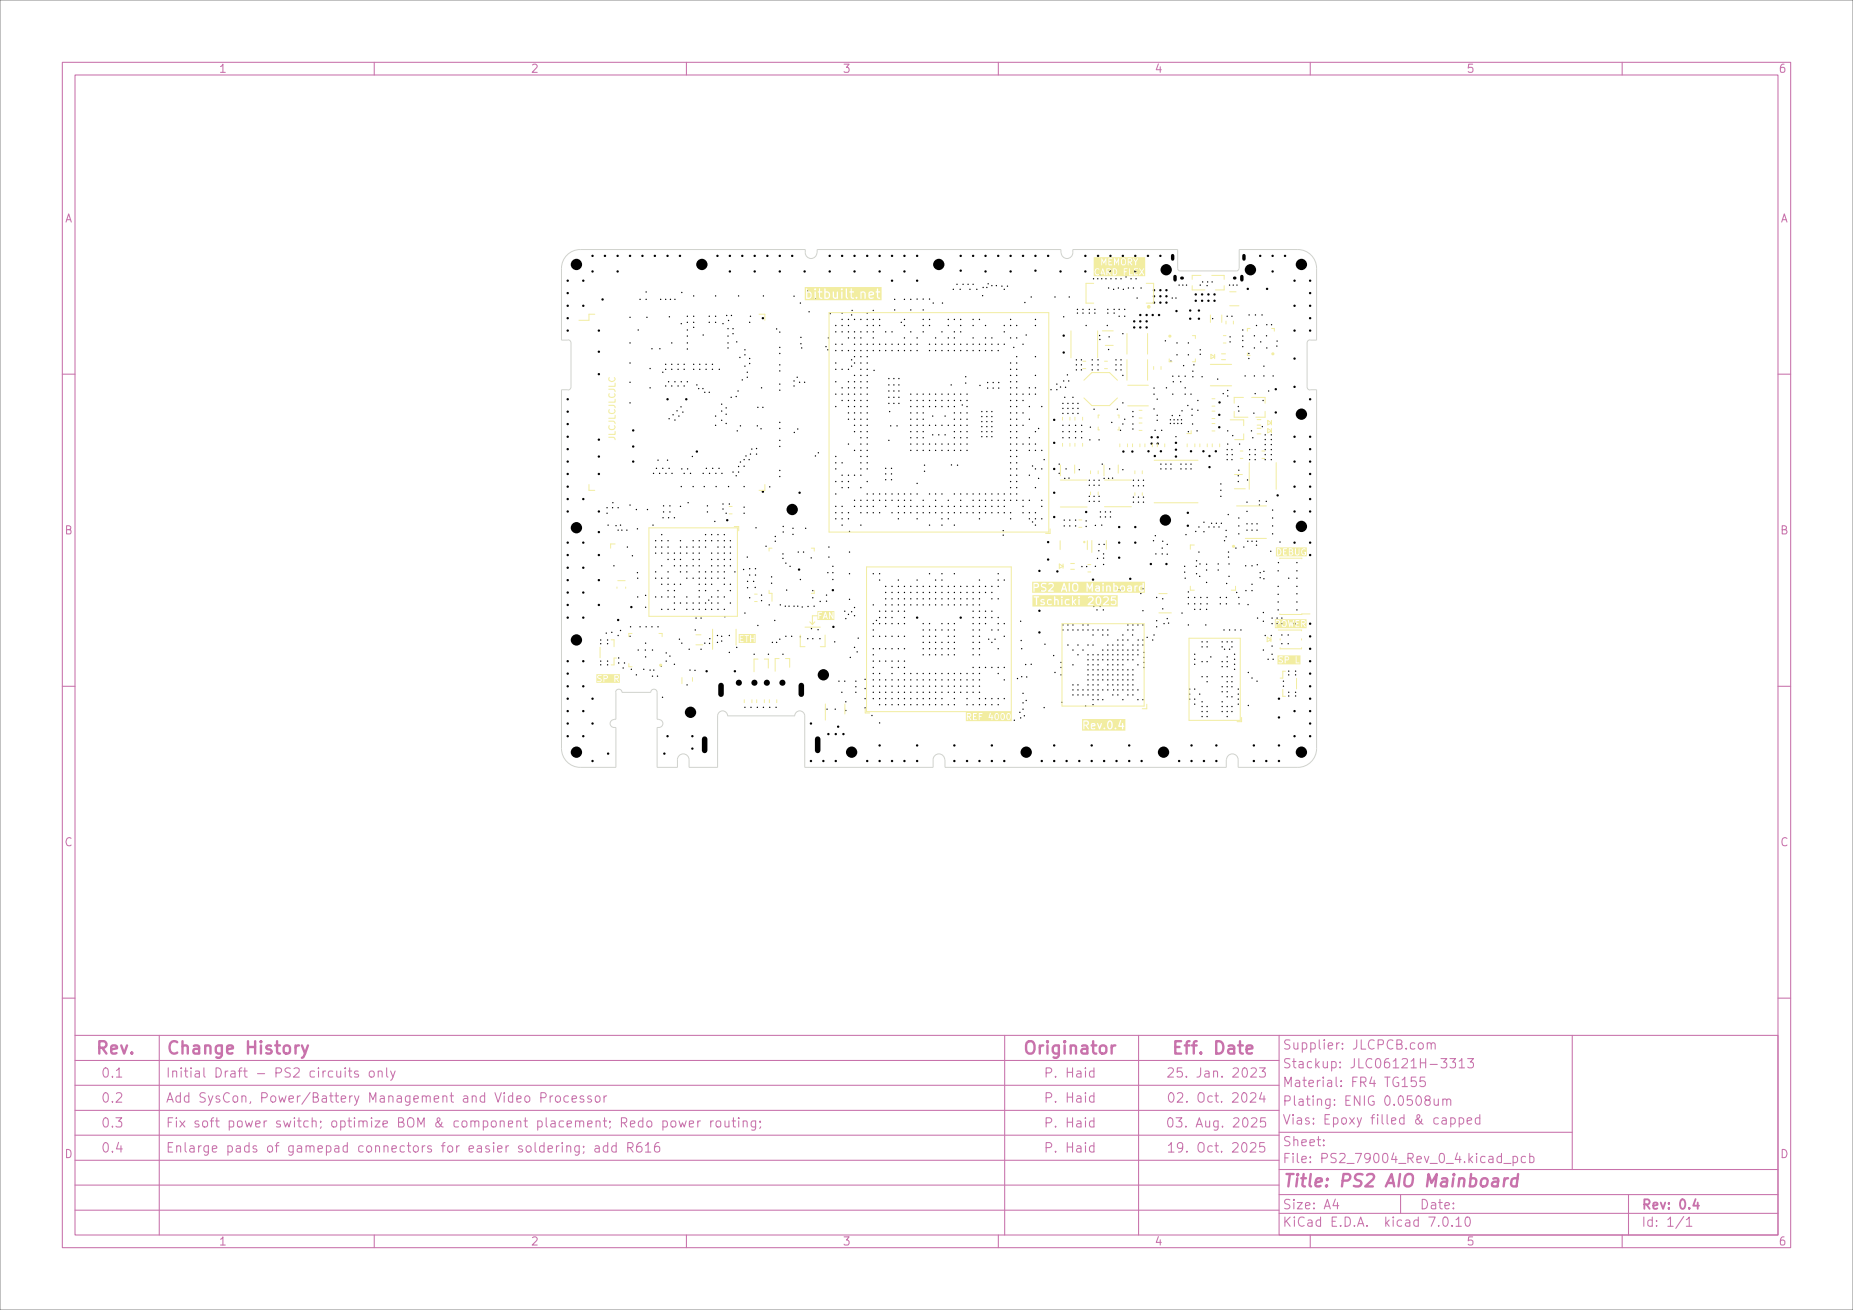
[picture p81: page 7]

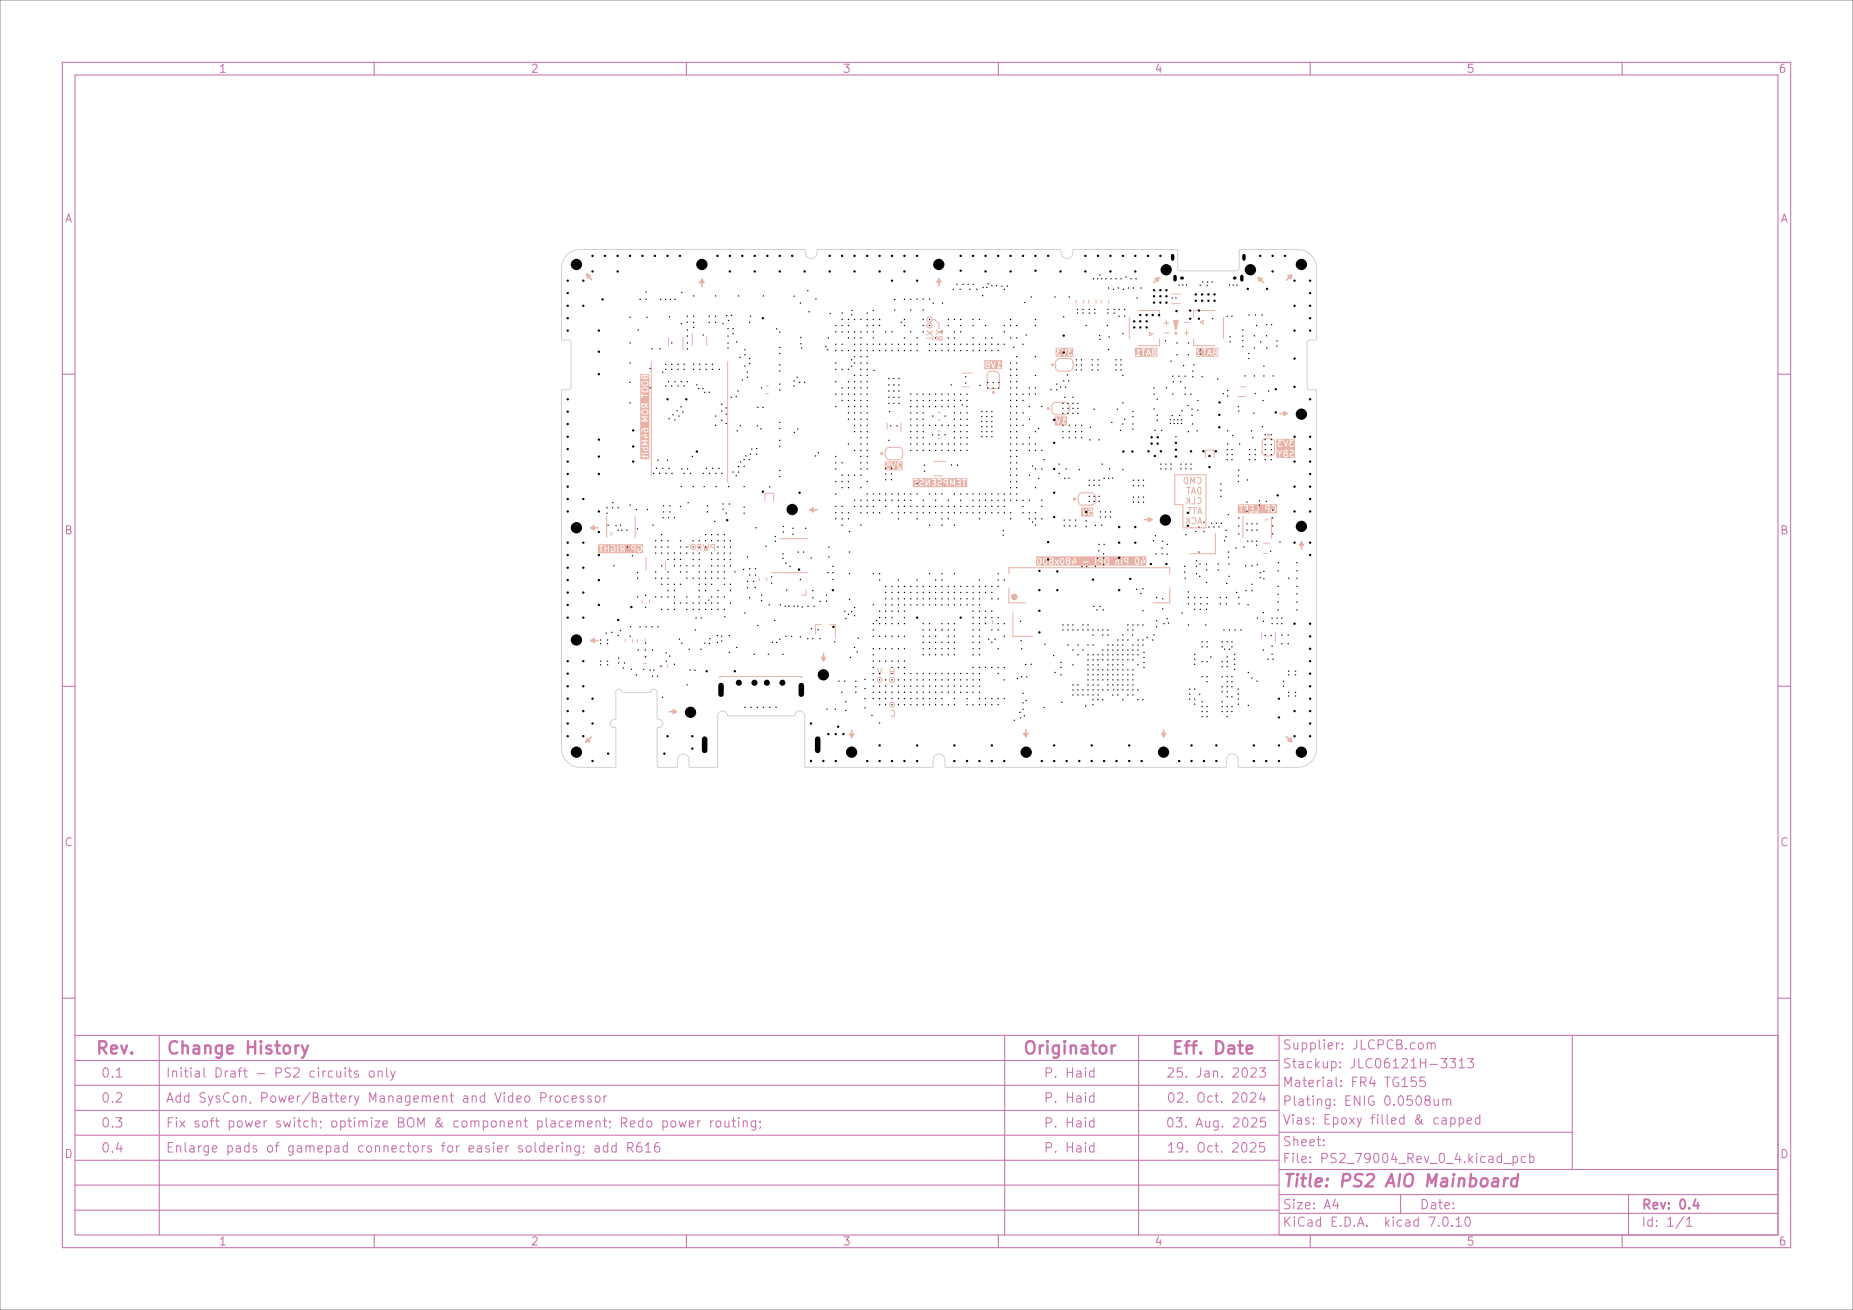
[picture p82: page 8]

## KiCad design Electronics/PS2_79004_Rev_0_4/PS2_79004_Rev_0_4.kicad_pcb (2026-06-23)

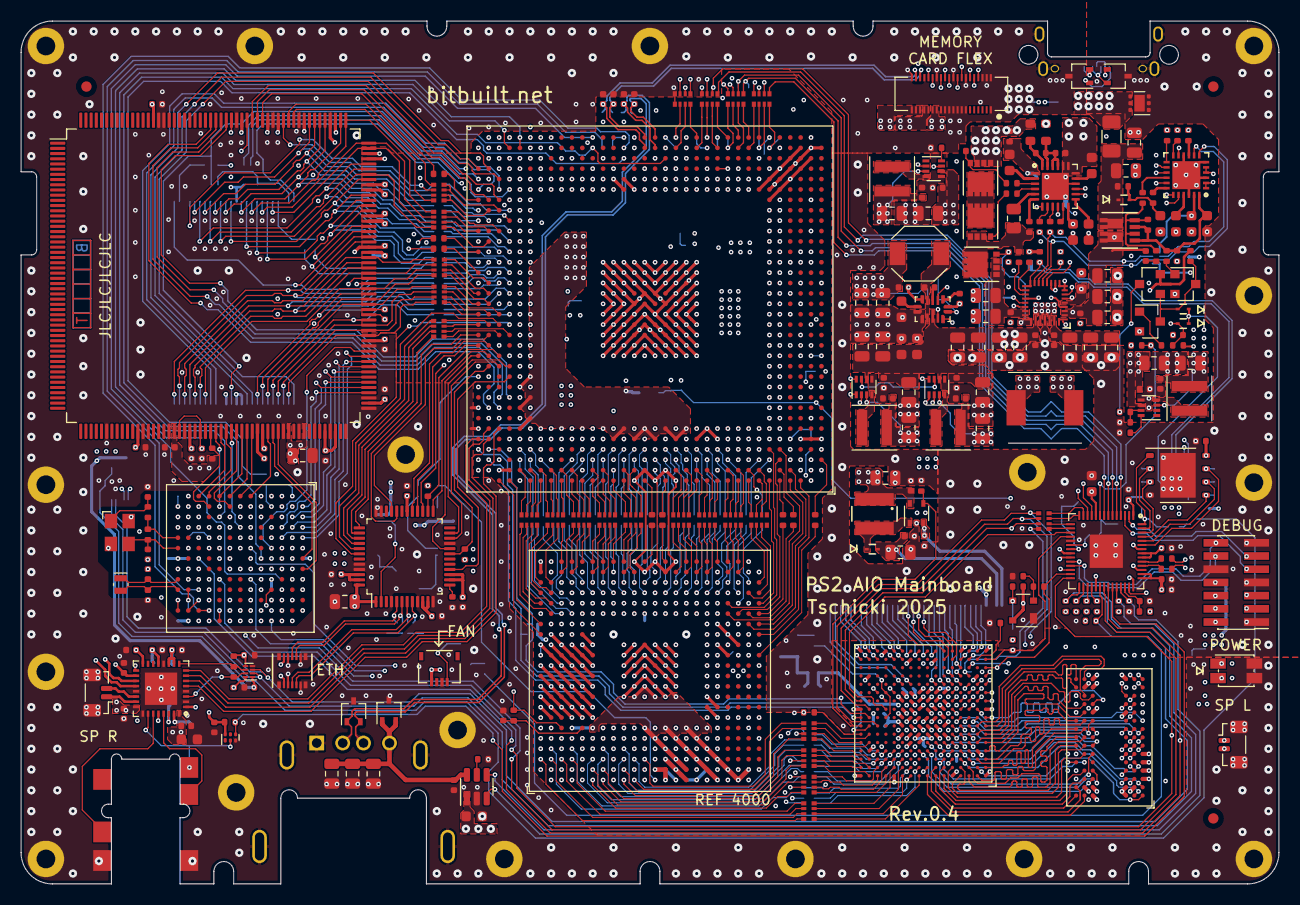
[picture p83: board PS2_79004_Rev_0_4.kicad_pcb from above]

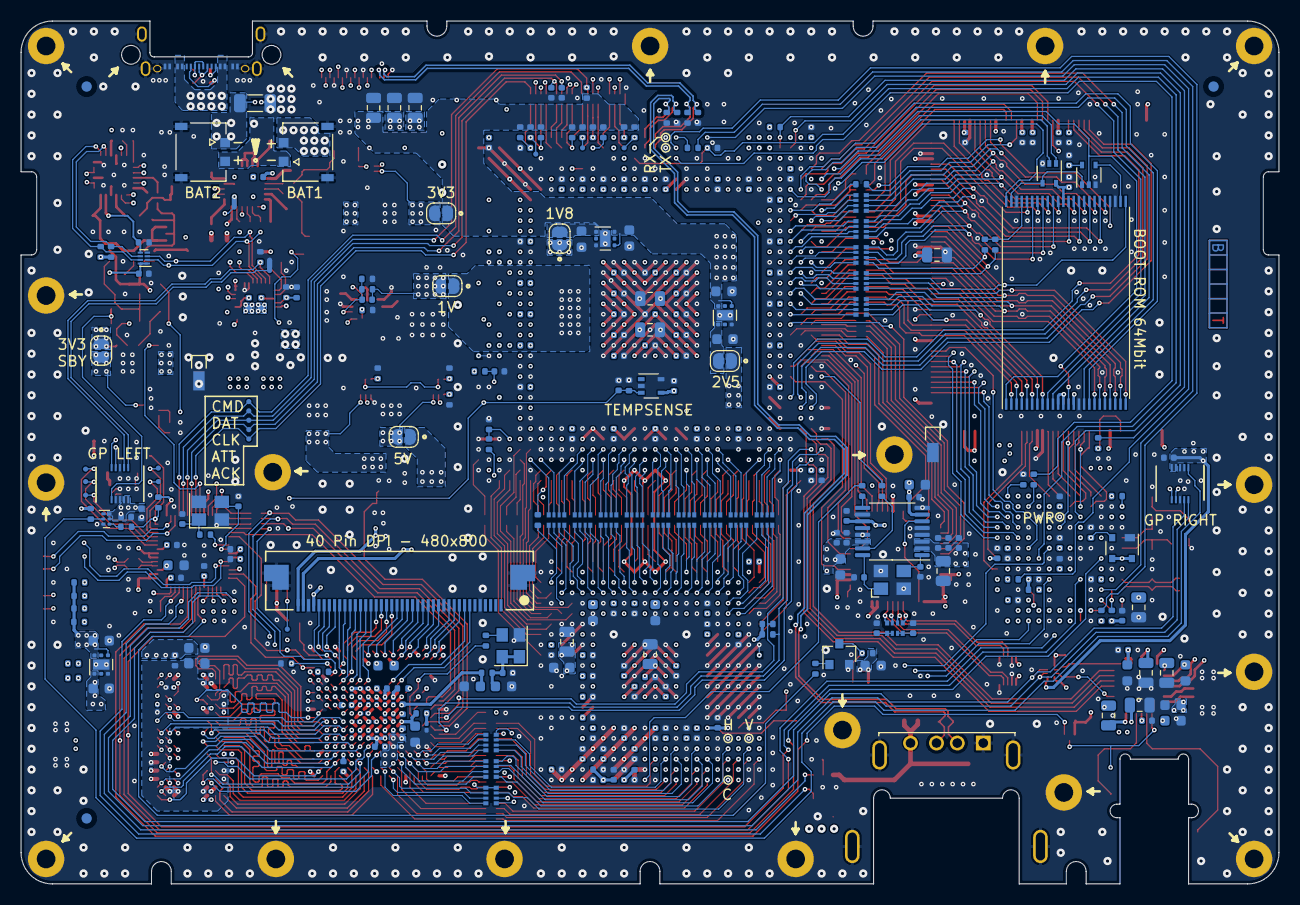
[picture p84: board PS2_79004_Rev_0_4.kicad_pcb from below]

Board: 6 copper layers, 121.0 x 83.0 mm, 770 parts (488 on the bottom side), 807 nets.

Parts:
C201, C202, C1402, C2002, C2003, C2105, C2106, C2112, C2504: 2u2; C_0805_2012Metric
C203, C204, C205, C206, C605, C616, C806, C809, C2107, C2114, C2115, C2118, C2119, C2202, C2205, C2208: 1u; C_0603_1608Metric
C207, C208, C306, C309, C314, C318, C325, C328, C401, C510, C511, C512, C513, C516, C517, C518, C519, C532, C601, C602, C606, C607, C608, C609, C610, C611, C612, C613, C614, C615, C801, C805, C810, C901, C905, C906, C907, C908, C909, C910, C911, C912, C913, C914, C916, C917, C918, C919, C920, C921, C922, C923, C924, C925, C926, C927, C928, C929, C930, C931, C932, C933, C934, C935, C936, C937, C938, C939, C944, C1301, C1401, C1403, C1404, C1405, C1406, C1407, C1408, C1409, C1503, C1504, C1507, C1601, C1602, C1701, C1702, C1802, C1803, C1804, C1805, C1806, C1807, C1808, C1809, C1810, C1811, C1813, C1814, C1815, C1816, C1817, C1818, C2001, C2004, C2005, C2006, C2007, C2008, C2101, C2102, C2104, C2108, C2109, C2110, C2111, C2113, C2116, C2117, C2201, C2203, C2204, C2206, C2207, C2209, C2210, C2213, C2215, C2216, C2217, C2218, C2219, C2220, C2221, C2222, C2223, C2224, C2225, C2226, C2227, C2229, C2230, C2231, C2232, C2233, C2234, C2235, C2236, C2237, C2502, C2903, C3005, C3006: 100n; C_0402_1005Metric
C301, C302, C303, C304, C305, C307, C316, C319, C320, C321, C322, C323, C501, C502, C1801, C1812, C2103, C2501: 10u; C_0805_2012Metric
C308, C503, C506, C509, C528, C529, C530, C531, C534, C535, C538, C2601, C2608, C2801, C2814, C3004: 4u7; C_0603_1608Metric
C310, C311: 47n; C_0402_1005Metric
C312, C315, C317, C324, C2901, C2902: 470n; C_0603_1608Metric
C313, C803, C808, C811, C1303, C2212, C2228, C2301, C2503: 1n; C_0402_1005Metric
C326, C327, C525, C807, C902, C903, C904, C915, C940: 10n; C_0402_1005Metric
C504, C505, C507, C508, C521, C522, C523, C524, C533, C536, C537, C942, C943, C2211, C2214, C3001, C3002, C3003: 22u; C_0805_2012Metric
C514, C2602, C2618, C2625, C2626, C2627, C2628: 220n; C_0402_1005Metric
C515: 22n; C_0402_1005Metric
C520: 270p; C_0402_1005Metric
C526, C527: 47u; C_0805_2012Metric
C603, C604, C1501, C1502, C1505, C1506: 15p; C_0402_1005Metric
C802, C804, C1302: 5p; C_0402_1005Metric
C941, C2401, C2402, C2403, C2404, C2405, C2406, C2407: 100p; C_0402_1005Metric
C2603, C2604, C2605, C2606, C2607, C2609, C2610, C2611, C2612, C2613, C2614, C2615, C2616, C2617, C2619, C2620, C2621, C2622, C2623, C2624, C2802, C2803, C2804, C2805, C2806, C2807, C2808, C2809, C2810, C2811, C2812, C2813: 100n; C_0201_0603Metric
D201, D202, D3001, D3002: ESDA25W; SOT-323_SC-70
D203, D401, D402, D2501: D_Schottky; SOD-923_0P6X0P85_ONS
D1501: Power LED; LED_Lite-ON_LTST-C155
F201: Fuse; Fuse_1206_3216Metric
FB2601, FB2801, FB2901: 33R @ 100MHz; R_0402_1005Metric
FID3001, FID3002, FID3003, FID3004, FID3005, FID3006: Fiducial; Fiducial_1mm_Mask2mm
J301: BAT1; MOLEX_2082940020_2pin
J302: BAT2; MOLEX_2082940020_2pin
J2101: LEFT SPEAKER; JST_SUR_BM02B-SURS-TF_1x02-1MP_P0.80mm_Vertical
J2102: RIGHT SPEAKER; JST_SUR_BM02B-SURS-TF_1x02-1MP_P0.80mm_Vertical
J2103: SJ-43504-SMT-TR; CUI_SJ-43504-SMT-TR
J2501: Conn_01x40_MountingPin; CONN_62684402100ALF_AMP
J3001: EXPANSION HDR; DF40C-40DS-0.4V
J3002: ETH; DF40C-10DP-0.4V51_HIR
J3003: USB_A; PS2_USB_mid_mount
J3004: GAMEPAD LEFT; DF40C-10DS-0.4V51_HIR
J3005: GAMEPAD RIGHT; DF40C-10DS-0.4V51_HIR
J3006: Debug; FTSH-107-01-F-DV-K-P-TR
J3007: 2328702-4; TE_2328702-4
JP501, JP502, JP503, JP504, JP505, JP506: Jumper_2_Bridged; SolderJumper-2_P1.3mm_Open_RoundedPad1.0x1.5mm
L301: 1uH; L_TDK_SPM6530
L501, L502, L503, L504: 2u2; L_Coilcraft_XGL4020
L505: 1u; SPM5030T-1R0M
L2501: 4u7; IND_TAIYO_NRS4012_TAY
NT301, NT302: NetTie_2; NetTie-2_SMD_Pad0.5mm
P201: CX90MW6-16P; CX90_632x232_HIR
Q201: Q_SI7223DN; PowerPAK1212-8_VIS
Q301, Q302, Q303: CSD17575Q3; CSD17308Q3
Q401, Q402, Q601: DMN67D8L; SOT-23
Q403: BSS84AK; SOT-23
R201, R1701, R1702: 560R; R_0402_1005Metric
R202, R205, R311, R313, R406, R604, R606, R614, R616, R1304, R1305, R1307, R1504, R1505, R1507, R1508, R1510, R2001, R2307, R2401, R2402, R2403, R2404, R2405, R2406, R2408, R2409, R2411, R2412: 1k; R_0402_1005Metric
R203, R206, R207, R211, R309, R401, R404, R507, R607, R610, R2101: 100k; R_0402_1005Metric
R204, R509, R2407, R2410, R2413, R2414: 15k; R_0402_1005Metric
R208, R209, R301, R601, R608, R609, R611, R612, R613, R2103, R2104: 2k2; R_0402_1005Metric
R210, R306: 100R; R_0402_1005Metric
R302, R303, R2902: 12k; R_0402_1005Metric
R304, R305, R314, R315, R1301, R1302, R1303, R1306, R1509, R2301, R2302, R2303, R2304, R2305, R2306, R2308: 68R; R_0402_1005Metric
R307: 30k; R_0402_1005Metric
R308: 5k23; R_0402_1005Metric
R310: 270R; R_0805_2012Metric
R312: 0R01; R_1206_3216Metric
R316: 10R; R_0402_1005Metric
R317, R318: 68R; R_0603_1608Metric
R402, R403, R405, R407, R501, R508, R605, R615, R1201, R1202, R1501, R1502, R1503, R1514, R1601, R2102, R2501, R2701, R2702, R2703, R2704, R2705, R2706, R2707, R2708, R2709, R2710, R2711: 10k; R_0402_1005Metric
R502, R503, R504, R505: 42k2; R_0402_1005Metric
R506: 6k8; R_0402_1005Metric
R510, R1512, R1515: 45k3; R_0402_1005Metric
R602, R603, R801, R802, R1506, R2901: 22R; R_0402_1005Metric
R1511: 1M; R_0402_1005Metric
R1513, R2002: 1K5; R_0402_1005Metric
R2003: 1K2; R_0402_1005Metric
R2502: 5R6; R_0402_1005Metric
RN601, RN1301, RN1302, RN1303, RN1304, RN1305, RN1306, RN1307, RN1308, RN1309, RN2001, RN2301, RN2302, RN2303, RN2304, RN2305, RN2306, RN2307, RN2308, RN2309, RN2310, RN2311, RN2312, RN2313, RN2314, RN2315, RN2316, RN2317, RN2318, RN2319, RN2320, RN2321, RN2322, RN2323, RN2324, RN2325, RN2401, RN2402, RN2403, RN2404: 68R; R_Array_Convex_4x0402
RN2002: 51R; R_Array_Convex_4x0402
TP201, TP202, TP203, TP204, TP205, TP206, TP301, TP302, TP303, TP304, TP305, TP306, TP601, TP602, TP603, TP604, TP605, TP606, TP607, TP608, TP1101, TP1301, TP1302, TP1303, TP1304, TP1305, TP1306, TP1307, TP1308, TP1309, TP1310, TP1311, TP1312, TP1313, TP1314, TP1315, TP1316, TP1317, TP1318, TP1319, TP1320, TP1321, TP1322, TP1323, TP1324, TP1325, TP1326, TP1327, TP1328, TP1329, TP1501, TP1502, TP1503, TP1504, TP1505, TP1506, TP1507, TP1508, TP1509, TP1510, TP1511, TP1512, TP1513, TP1514, TP1515, TP1516, TP1517, TP1518, TP1519, TP1520, TP1521, TP1522, TP1523, TP1524, TP1525, TP1526, TP1527, TP1528, TP1529, TP1530, TP1531, TP1532, TP1533, TP1534, TP1535, TP1536, TP1537, TP1538, TP1539, TP1540, TP1541, TP1542, TP1543, TP1544, TP1545, TP1546, TP1547, TP1548, TP1701, TP1702, TP1703, TP1704, TP1901, TP2301, TP2302, TP2303, TP2304, TP2305, TP2306, TP2307, TP2308, TP2309, TP2310, TP2311, TP2312, TP2313, TP2314, TP2315, TP2316, TP2317, TP2318, TP2319, TP2320, TP2321, TP2322, TP2323, TP2324, TP2325, TP2326, TP2327, TP2328, TP2329, TP2330, TP2331, TP2332, TP2333, TP2334, TP2335, TP2401, TP2402, TP2403, TP2404, TP2405, TP2406, TP2407, TP2408, TP2409, TP2410, TP2411, TP2412, TP2701, TP2702, TP2703, TP2704, TP2705, TP2706, TP2707, TP2708, TP2709, TP2901, TP2902, TP2903, TP2904, TP2905, TP2906: Solder_Point; Solder_Point_127
TP3001, TP3002, TP3003, TP3004, TP3005, TP3006, TP3007, TP3008, TP3009, TP3010, TP3011, TP3012, TP3013, TP3014, TP3015, TP3016, TP3017: Solder_Point; mounting_hole_1.6mm
TP3018, TP3019: Solder_Point; TE_1551576-5
U201: TVS2200DRV; WSON-6-1EP_2x2mm_P0.65mm_EP1x1.6mm
U202: STUSB4500; QFN-24_EP_4x4_Pitch0.5mm
U203, U2101: TXS0102DQE; X2SON-8_1.4x1mm_P0.35mm
U301: BQ25792B; BQ25792RQMR
U302: MAX17320; TQFN-24-1EP_4x4mm_P0.5mm_EP2.6x2.6mm
U501: MPQ8626GD; MPQ8626GD-Z
U502, U503, U504, U505: TPS629210; SOT-583
U506: AP22653A; SOT-23-6
U507: TLV75525PDRV; WSON-6-1EP_2x2mm_P0.65mm_EP1x1.6mm
U508, U509: TLV75518PDRV; WSON-6-1EP_2x2mm_P0.65mm_EP1x1.6mm
U601, U2102: 74LVC1G07; Texas_USON-6_1x1.45mm_P0.5mm_SMD
U602: W25Q128JVPIQ; WSON-8-1EP_6x5mm_P1.27mm_EP3.4x4.3mm
U603: RP2040; QFN-56-1EP_7x7mm_P0.4mm_EP3.2x3.2mm
U801: 627G04LF; TSSOP-16_4.4x5mm_P0.65mm
U901: CXD2976GB; PS2_CXD2976GB_35.0x35.0mm_P1.0mm
U1401: CXR726080; BGA-169_14.0x14.0mm_Layout13x13_P1.0mm
U1501, U2701: APX811-31UG; SOT-143
U1601: LM20BIM7; SOT-353_SC-70-5
U1701, U1702: 74LVC1G08; SOT-353_SC-70-5
U1703: S29JL064J55TFI000; TSOP-I-48_18.4x12mm_P0.5mm
U1801: CXD3098AQ; PS2_CXD3098AQ_208_28x28mm_P0.5mm
U2001: BCM5241; LQFP-48_7x7mm_P0.5mm
U2103: LM49450; WQFN-32-1EP_5x5mm_P0.5mm_EP3.1x3.1mm
U2201: CXD2980; PS2_CXD2980CGB_23.0x23.0mm_P1.0mm
U2501: TPS92360; SOT-353_SC-70-5
U2601: T20F256I4; BGA-256_14.0x14.0mm_Layout16x16_P0.8mm_Ball0.45mm_Pad0.32mm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
U2801: IS45S32400F; BGA-90_8.0x13.0mm_Layout2x3x15_P0.8mm
X2901: ASE-50MHz; Oscillator_SMD_Abracon_ASE-4Pin_3.2x2.5mm
Y601: 12MHz; Crystal_SMD_3225-4Pin_3.2x2.5mm
Y801: 18.432MHz; Crystal_SMD_3225-4Pin_3.2x2.5mm
Y1501: 32.768kHz; Crystal_SMD_MicroCrystal_CM9V-T1A-2Pin_1.6x1.0mm
Y1502: 16,934MHz; Crystal_SMD_3225-4Pin_3.2x2.5mm

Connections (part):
1V2_T20: C516.1, C521.1, C2601.1, C2602.1, C2603.1, C2604.1, C2605.1, C2606.1, C2607.1, C2609.1, C2611.1, FB2601.1, L501.2, U502.3 (VOS), U2601.E9 (VCC), U2601.F8 (VCC), U2601.F9 (VCC), U2601.J6 (VCC), U2601.J7 (VCC), U2601.K9 (VCC)
1V8_PS2: C809.1, C810.1, C811.1, C906.1, C908.1, C910.1, C912.1, C915.1, C918.1, C921.1, C923.1, C925.1, C927.1, C929.1, C1407.2, C1408.2, C1409.2, C1812.1, C1813.1, C1814.1, C1815.1, C1816.1, C1817.1, C1818.1, C2221.1, C2223.1, C2225.1, C2227.1, C2229.1, C2230.1, C2231.1, C2232.1, C2233.1, C2234.1, C2235.1, C2236.1, C2237.1, JP506.2 (B), U801.7 (1V8), U801.11 (1V8), U901.AA5 (1V8), U901.AB6 (1V8), U901.AB30 (1V8), U901.AC5 (1V8), U901.AC29 (1V8), U901.AD6 (1V8), U901.AD30 (1V8), U901.AE5 (1V8), U901.AE29 (1V8), U901.AF6 (1V8), U901.AF30 (1V8), U901.AG5 (1V8), U901.AG29 (1V8), U901.AH30 (1V8), U901.AJ21 (1V8), U901.AJ23 (1V8), U901.AJ25 (1V8), U901.AJ27 (1V8), U901.AJ29 (1V8), U901.AK22 (1V8), U901.AK24 (1V8), U901.AK26 (1V8), U901.AK28 (1V8), U901.AK30 (1V8), U901.AL31 (1V8), U901.AM32 (1V8), U901.AN33 (1V8), U901.B2 (1V8), U901.C3 (1V8), U901.D4 (1V8), U901.E5 (1V8), U901.E7 (1V8), U901.E9 (1V8), U901.E11 (1V8), U901.E13 (1V8), U901.F6 (1V8), U901.F8 (1V8), U901.F10 (1V8), U901.F12 (1V8), U901.G5 (1V8), U901.H6 (1V8)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
1V8_T20: C538.1, C2616.1, C2623.1, C2628.1, U509.1 (OUT), U2601.E10 (VCCIO3A_3B_3C), U2601.F10 (VCCIO3A_3B_3C), U2601.F11 (VCCIO3A_3B_3C)
1V_PS2: C913.1, C916.1, C919.1, C922.1, C924.1, C926.1, C928.1, C930.1, C931.1, C932.1, C933.1, C934.1, C935.1, C936.1, C937.1, C938.1, C939.1, C940.1, C941.1, C942.1, C943.1, C944.1, C2201.1, C2202.1, C2204.1, C2205.1, C2207.1, C2208.1, C2210.1, C2211.1, C2213.1, C2214.1, C2216.1, C2218.1, C2220.1, C2222.1, C2224.1, C2226.1, C2228.1, JP501.2 (B), U901.AA14 (1V25), U901.AA16 (1V25), U901.AA18 (1V25), U901.AA20 (1V25), U901.AA22 (1V25), U901.AB13 (1V25), U901.AB15 (1V25), U901.AB17 (1V25), U901.AB19 (1V25), U901.AB21 (1V25), U901.AJ9 (1V25), U901.AJ11 (1V25), U901.AJ13 (1V25), U901.AJ15 (1V25), U901.AJ17 (1V25), U901.AJ19 (1V25), U901.AK8 (1V25), U901.AK10 (1V25), U901.AK12 (1V25), U901.AK14 (1V25), U901.AK16 (1V25), U901.AK18 (1V25), U901.AK20 (1V25), U901.B34 (1V25), U901.N14 (1V25), U901.N16 (1V25), U901.N18 (1V25), U901.N20 (1V25), U901.N22 (1V25), U901.P13 (1V25), U901.P15 (1V25), U901.P17 (1V25), U901.P19 (1V25), U901.P21 (1V25), U901.R14 (1V25), U901.R16 (1V25), U901.R18 (1V25), U901.R20 (1V25), U901.R22 (1V25), U901.T13 (1V25), U901.T15 (1V25)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
2V5_PS2: C914.1, C917.1, C920.1, C2116.1, C2117.1, C2118.1, C2119.1, C2203.1, C2206.1, C2209.1, C2212.1, JP505.2 (B), U901.AP2 (2V5), U901.AP33 (2V5), U901.B33 (2V5), U2103.28 (HPVDD), U2103.32 (CPVDD), U2201.A21 (2V5), U2201.T1 (2V5)
3V3_PS2: C529.1, C530.1, C801.1, C803.1, C805.1, C806.1, C807.1, C808.1, C901.1, C902.1, C903.1, C904.1, C905.1, C907.1, C909.1, C911.1, C1403.1, C1404.1, C1405.1, C1406.1, C1507.1, C1601.1, C1701.1, C1702.1, C1801.1, C1802.1, C1803.1, C1804.1, C1805.1, C1806.1, C1807.1, C1808.1, C1809.1, C1810.1, C1811.1, C2002.1, C2004.1, C2005.1, C2006.1, C2102.1, C2107.1, C2108.1, C2109.1, C2215.1, C2217.1, C2219.1, C3003.1, J3001.27, J3001.29, J3002.9, J3002.10, JP504.2 (B), R1201.1, R1202.1, R1304.2, R1501.1, R1503.1, R1512.1, R1515.1, R2001.1, R2002.1, R2101.2, R2102.1, R2103.1, R2104.1, R2401.1, R2402.1, R2403.1, R2404.1, R2405.1, R2406.1, R2408.1, R2409.1, R2411.1, R2412.1, U507.4 (EN), U507.6 (IN), U508.4 (EN), U508.6 (IN), U801.2 (3V5), U801.3 (3V5)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
3V3_SBY: C208.2, C601.1, C602.1, C608.1, C609.1, C610.1, C611.1, C612.1, C614.1, C615.1, C616.1, C2101.2, C3002.1, C3005.1, C3006.1, J3001.31, J3001.33, J3004.8, J3004.10, J3005.8, J3005.10, JP503.2 (B), R208.1, R209.1, R301.2, R407.1, R601.1, R605.1, R608.1, R609.1, R610.2, R611.1, R612.1, R613.1, U203.1 (VCCA), U203.8 (VCCB), U601.6 (VCC), U602.8 (VCC), U603.1 (IOVDD), U603.10 (IOVDD), U603.22 (IOVDD), U603.33 (IOVDD), U603.42 (IOVDD), U603.43 (ADC_AVDD), U603.44 (VREG_IN), U603.48 (USB_VDD), U603.49 (IOVDD), U2101.1 (VCCA)
3V3_T20: C517.1, C522.1, C531.1, C2612.1, C2613.1, C2614.1, C2615.1, C2617.1, C2618.1, C2619.1, C2620.1, C2621.1, C2622.1, C2624.1, C2625.1, C2626.1, C2627.1, C2801.1, C2802.1, C2803.1, C2804.1, C2805.1, C2901.1, FB2801.1, FB2901.1, J2501.37, JP504.1 (A), L502.2, R2702.1, R2703.1, R2704.2, R2705.2, R2706.2, R2707.2, R2708.2, R2711.1, U503.3 (VOS), U509.4 (EN), U509.6 (IN), U2601.F6 (VCCIO1D_1E), U2601.G6 (VCCIO1D_1E), U2601.H6 (VCCIO1B_1C), U2601.H7 (VCCIO1B_1C), U2601.J10 (VCCIO3D_3E), U2601.J11 (VCCIO3D_3E), U2601.K6 (VCCIO1A), U2601.L6 (VCCIO4B), U2601.L7 (VCCIO4B), U2601.L10 (VCCIO4A), U2601.L11 (VCCIO4A), U2701.4 (VCC), U2801.A7 (VDD), U2801.F9 (VDD), U2801.L7 (VDD), U2801.R7 (VDD)
5V: C528.1, C2110.1, C2111.1, C2113.1, C2114.1, C2115.1, C2501.2, C2502.1, C3001.1, C3004.1, J3001.35, J3001.37, J3001.39, J3007.1, JP502.2 (B), L2501.1, R615.1, U506.1 (IN), U2103.16 (VDD), U2103.18 (LSVDD), U2103.24 (LSVDD), U2501.5 (VIN)
5V_USB: C532.1, C533.1, C536.1, C537.1, D3001.1 (K), D3001.2 (K), J3003.1 (VBUS), U506.6 (OUT)
+1V1: C605.1, C606.1, C607.1, U603.23 (DVDD), U603.45 (VREG_VOUT), U603.50 (DVDD)
/Battery Management/BAT_CENT: J301.1, J302.2, R318.2
/Battery Management/BAT_POS: C328.1, J301.2, Q303.1 (S), Q303.2 (S), Q303.3 (S), R316.2, R317.2
/Battery Management/BQ_BAT: C318.2, C320.2, C322.2, Q301.1 (S), Q301.2 (S), Q301.3 (S), U301.22 (BAT), U301.23 (BAT)
/Battery Management/ILIM: R309.1, U301.17 (ILIM_HIZ)
/Battery Management/PROG: R302.2, R303.2, U301.20 (PROG)
/Battery Management/REGN: C308.2, R308.2, R309.2, U301.5 (REGN)
/Battery Management/SW1: C310.2, L301.1, U301.28 (SW1)
/Battery Management/SW2: C311.2, L301.2, U301.26 (SW2)
/Battery Management/SYS_I2C_SCL: R304.1, R612.2, U203.2 (A1), U301.14 (SCL), U603.32 (GPIO21)
/Battery Management/SYS_I2C_SDA: R305.1, R611.2, U203.3 (A2), U301.15 (SDA), U603.31 (GPIO20)
/Battery Management/VBUS: C207.2, C302.2, C304.2, C307.2, C309.2, Q201.7 (D), Q201.8 (G), R205.2, U301.2 (VBUS), U301.3 (VBUS), U301.8 (VAC2), U301.9 (VAC1)
/Battery Management/VPACK+: Q301.5-8 (D), Q302.1 (S), Q302.2 (S), Q302.3 (S), R306.2, R310.1, R311.2
/Battery Management/VSYS: C314.2, C316.2, C319.2, C321.2, C323.2, C501.1, C502.1, C504.1, C505.1, C506.1, C507.1, C508.1, C509.1, C510.1, C511.1, C512.1, C513.1, Q403.2 (S), R403.2, U301.25 (SYS), U501.3 (VIN), U502.6 (VIN), U503.6 (VIN), U504.6 (VIN), U505.6 (VIN)
/Battery Management/~CHRG_EN: R301.1, U301.13 (~CE), U603.12 (GPIO9)
/Connectors/MC1_ACK: J3001.32, RN2401.2 (R2.1)
/Connectors/MC1_ATT: J3001.26, RN2401.4 (R4.1)
/Connectors/MC1_CLK: J3001.30, RN2401.3 (R3.1)
/Connectors/MC1_CMD: J3001.24, RN2402.3 (R3.1)
/Connectors/MC1_DAT: J3001.22, RN2402.4 (R4.1)
/Connectors/MC2_ACK: J3001.18, RN2404.3 (R3.1)
/Connectors/MC2_ATT: J3001.12, RN2403.1 (R1.1)
/Connectors/MC2_CLK: J3001.16, RN2404.4 (R4.1)
/Connectors/MC2_CMD: J3001.10, RN2403.2 (R2.1)
/Connectors/MC2_DAT: J3001.8, RN2403.3 (R3.1)
/Connectors/RD+: J3002.3, RN2002.8 (R1.2), U2001.8 (RD+)
/Connectors/RD-: J3002.5, RN2002.7 (R2.2), U2001.7 (RD-)
/Connectors/SPI_SS: J3006.5, R2701.1, U2601.P3 (GPIOL_00_SS_N)
/Connectors/SYS_FAN_PWM: J3007.4, Q601.3 (D), R615.2
/Connectors/SYS_SWCLK: J3006.12, U603.24 (SWCLK)
/Connectors/SYS_SWDIO: J3006.14, U603.25 (SWD)
/Connectors/SYS_UART_RX: J3006.9, U603.3 (GPIO1)
/Connectors/SYS_UART_TX: J3006.11, U603.2 (GPIO0)
/Connectors/TCK: J3006.4, R2706.1, U2601.M2 (TCK)
/Connectors/TD+: J3002.6, RN2002.5 (R4.2), U2001.5 (TD+)
/Connectors/TD-: J3002.4, RN2002.6 (R3.2), U2001.6 (TD-)
/Connectors/TDI: J3006.8, R2704.1, U2601.K5 (TDI)
/Connectors/TDO: J3006.6, R2705.1, U2601.L5 (TDO)
/Connectors/TMS: J3006.2, R2707.1, U2601.M1 (TMS)
/Connectors/USB1_DN: C2406.1, D3002.2 (K), J3003.2 (D-), R2413.1, U901.AN17 (USB1_D-)
/Connectors/USB1_DP: C2407.1, D3002.1 (K), J3003.3 (D+), R2414.1, U901.AP17 (USB1_D+)
/Connectors/USB2_DN: C2404.1, J3001.38, R2407.1, U901.AN18 (USB2_D-)
/Connectors/USB2_DP: C2405.1, J3001.36, R2410.1, U901.AP18 (USB2_D+)
/Connectors/~SYSCON_BOOTSEL: J3005.2, R601.2, U601.2
/PS2_REG_EN: R607.1, U501.5 (EN), U502.7 (EN), U503.7 (EN), U504.7 (EN), U506.3 (EN), U603.39 (GPIO27_ADC1)
/PS2_REG_PG: R610.1, U501.9 (PGOOD), U502.2 (PG), U503.2 (PG), U504.2 (PG), U506.4 (~FAULT), U603.38 (GPIO26_ADC0)
/PlayStation 2 - MAIN/AUX_I2C_SCL: J3004.3, J3005.3, R609.2, U603.30 (GPIO19), U2101.3 (A2)
/PlayStation 2 - MAIN/AUX_I2C_SDA: J3004.1, J3005.1, R608.2, U603.29 (GPIO18), U2101.2 (A1)
/PlayStation 2 - MAIN/Audio & Network/AUDIO_MC: U901.E34 (AUDIO_MC), U2103.8 (MCLK)
/PlayStation 2 - MAIN/Audio & Network/AUDIO_SCL: U901.F33 (AUDIO_SCL), U2103.7 (I2S_CLK)
/PlayStation 2 - MAIN/Audio & Network/AUDIO_SDA: U901.E33 (AUDIO_SDA), U2103.6 (I2S_SDI)
/PlayStation 2 - MAIN/Audio & Network/AUDIO_WS: U901.F32 (AUDIO_WS), U2103.5 (I2S_WS)
/PlayStation 2 - MAIN/Audio & Network/Ethernet_16: U901.L31 (ETH_16), U2001.16 (EE_L31)
/PlayStation 2 - MAIN/Audio & Network/Ethernet_19: R2002.2, U901.M33 (ETH_19), U2001.19 (EE_M33)
/PlayStation 2 - MAIN/Audio & Network/Ethernet_20: U901.N34 (ETH_20), U2001.20 (EE_N34)
/PlayStation 2 - MAIN/Audio & Network/Ethernet_22: U901.M32 (ETH_22), U2001.22 (EE_M32)
/PlayStation 2 - MAIN/Audio & Network/Ethernet_23: U901.M31 (ETH_23), U2001.23 (EE_M31)
/PlayStation 2 - MAIN/Audio & Network/Ethernet_25: U901.N33 (ETH_25), U2001.25 (EE_N33)
/PlayStation 2 - MAIN/Audio & Network/Ethernet_26: R2001.2, U901.N32 (ETH_26), U2001.26 (EE_N32)
/PlayStation 2 - MAIN/Audio & Network/Ethernet_27: U901.N31 (ETH_27), U2001.27 (EE_N31)
/PlayStation 2 - MAIN/Audio & Network/Ethernet_28: U901.P34 (ETH_28), U2001.28 (EE_P34)
/PlayStation 2 - MAIN/Audio & Network/Ethernet_29: U901.P33 (ETH_29), U2001.29 (EE_P33)
/PlayStation 2 - MAIN/Audio & Network/Ethernet_32: U901.R34 (ETH_32), U2001.32 (EE_R34)
/PlayStation 2 - MAIN/Audio & Network/Ethernet_33: U901.R33 (ETH_33), U2001.33 (EE_R33)
/PlayStation 2 - MAIN/Audio & Network/Ethernet_37: RN2001.5 (R4.2), U901.R32 (ETH_37)
/PlayStation 2 - MAIN/Audio & Network/Ethernet_38: RN2001.6 (R3.2), U901.R31 (ETH_38)
/PlayStation 2 - MAIN/Audio & Network/Ethernet_39: RN2001.7 (R2.2), U901.T34 (ETH_39)
/PlayStation 2 - MAIN/Audio & Network/Ethernet_40: RN2001.8 (R1.2), U901.T33 (ETH_40)
/PlayStation 2 - MAIN/Audio & Network/Ethernet_41: U901.T32 (ETH_41), U2001.41 (EE_T32)
/PlayStation 2 - MAIN/Audio & Network/Ethernet_42: U901.T31 (ETH_42), U2001.42 (EE_T31)
/PlayStation 2 - MAIN/Audio/BYPASS: C2106.1, U2103.17 (BYPASS)
/PlayStation 2 - MAIN/Audio/C1N: C2105.2, U2103.31 (C1N)
/PlayStation 2 - MAIN/Audio/C1P: C2105.1, U2103.1 (C1P)
/PlayStation 2 - MAIN/Audio/HPL: J2103.2, U2103.29 (HPL)
/PlayStation 2 - MAIN/Audio/HPR: J2103.3, U2103.27 (HPR)
/PlayStation 2 - MAIN/Audio/HP_SENSE: J2103.5, U2102.2, U2103.26 (HPS)
/PlayStation 2 - MAIN/Audio/LS+: J2101.1, U2103.19 (LLS+)
/PlayStation 2 - MAIN/Audio/LS-: J2101.2, U2103.20 (LLS-)
/PlayStation 2 - MAIN/Audio/REF: C2103.1, C2104.1, U2103.13 (REF)
/PlayStation 2 - MAIN/Audio/RS+: J2102.1, U2103.23 (RLS+)
/PlayStation 2 - MAIN/Audio/RS-: J2102.2, U2103.22 (RLS-)
/PlayStation 2 - MAIN/BIOS/A0: R1701.2, RN1304.4 (R4.1), U1801.140 (HA00)
/PlayStation 2 - MAIN/BIOS/A1: RN1304.3 (R3.1), U1703.25 (A0), U1801.139 (HA01)
/PlayStation 2 - MAIN/BIOS/A2: RN1304.2 (R2.1), U1703.24 (A1), U1801.138 (HA02)
/PlayStation 2 - MAIN/BIOS/A3: RN1304.1 (R1.1), U1703.23 (A2), U1801.137 (HA03)
/PlayStation 2 - MAIN/BIOS/A4: RN1303.5 (R4.2), U1703.22 (A3), U1801.134 (HA04)
/PlayStation 2 - MAIN/BIOS/A5: RN1301.4 (R4.1), U1703.21 (A4), U1801.133 (HA05)
/PlayStation 2 - MAIN/BIOS/A6: RN1301.3 (R3.1), U1703.20 (A5), U1801.132 (HA06)
/PlayStation 2 - MAIN/BIOS/A7: RN1303.6 (R3.2), U1703.19 (A6), U1801.131 (HA07)
/PlayStation 2 - MAIN/BIOS/A8: RN1303.7 (R2.2), U1703.18 (A7), U1801.128 (HA08)
/PlayStation 2 - MAIN/BIOS/A9: RN1301.2 (R2.1), U1703.8 (A8), U1801.127 (HA09)
/PlayStation 2 - MAIN/BIOS/A10: RN1303.8 (R1.2), U1703.7 (A9), U1801.126 (HA10)
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

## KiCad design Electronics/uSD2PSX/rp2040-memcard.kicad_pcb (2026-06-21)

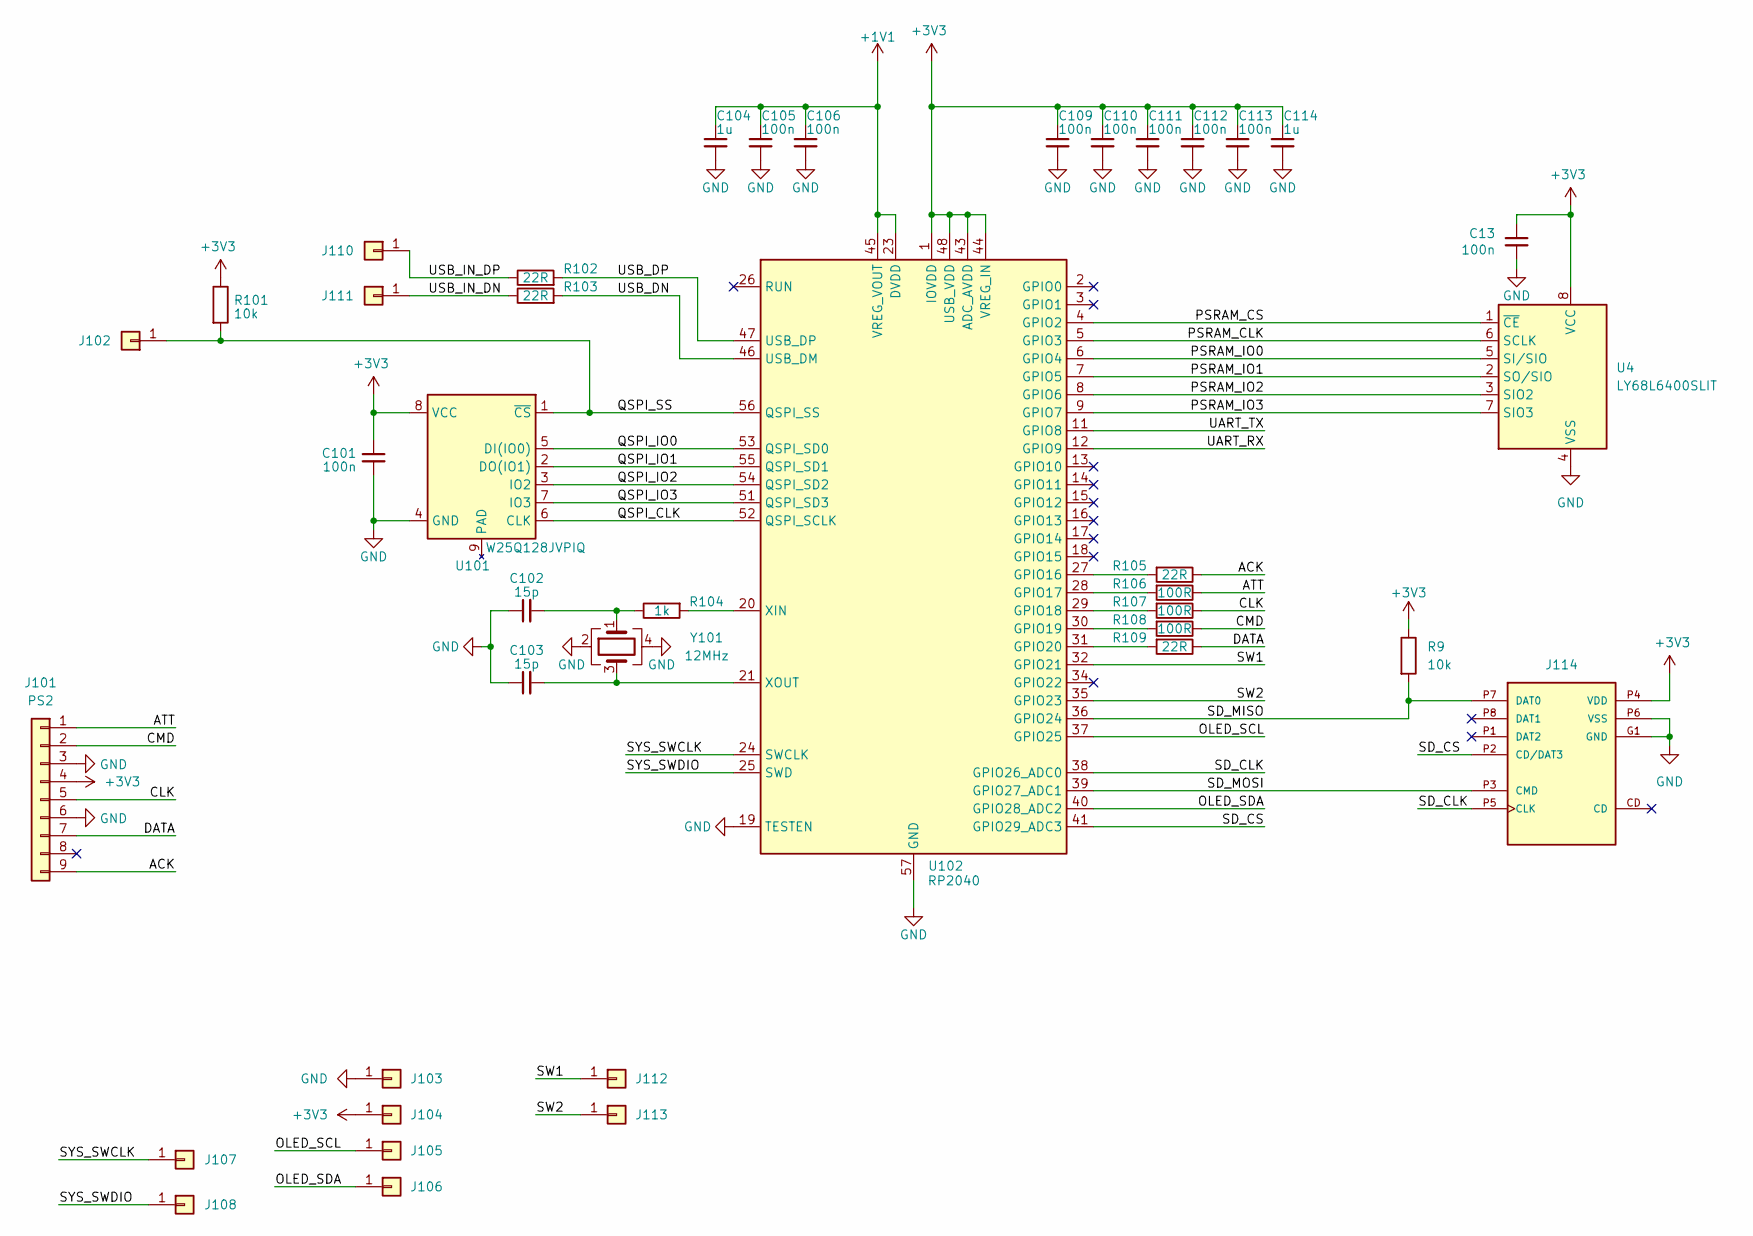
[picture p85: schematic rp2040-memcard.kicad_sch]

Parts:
C13, C101, C105, C106, C109, C110, C111, C112, C113: 100n; C_0402_1005Metric; Part Number CC0402KRX7R7BB104
C102, C103: 15p; C_0402_1005Metric; Part Number CC0402JRNPO9BN150
C104, C114: 1u; C_0603_1608Metric; Part Number CC0603KRX7R7BB105
J101: PS2; SD_Pins
J102: BSEL; TestPoint_Pad_D1.0mm
J103, J112: GND; TestPoint_Pad_D1.0mm
J104, J113: 3V3; TestPoint_Pad_D1.0mm
J105: SCL; TestPoint_Pad_D1.0mm
J106: SDA; TestPoint_Pad_D1.0mm
J107: SWC; TestPoint_Pad_D1.0mm
J108: SWD; TestPoint_Pad_D1.0mm
J110: DP; TestPoint_Pad_D1.0mm
J111: DN; TestPoint_Pad_D1.0mm
J114: MEM2085-00-115-00-A_REV0.2; GCT_MEM2085-00-115-00-A_REV0.2; Part Number MEM2085-00-115-00-A
R9, R101: 10k; R_0402_1005Metric; Part Number RC0402JR-0710KL
R102, R103, R105, R109: 22R; R_0402_1005Metric; Part Number RC0402FR-0722RL
R104: 1k; R_0402_1005Metric; Part Number RC0402FR-071KL
R106, R107, R108: 100R; R_0402_1005Metric; Part Number RC0402JR-07100RL
U4: LY68L6400SLIT; IC_W25Q16JVUXIQ_TR; Part Number APS6404L-3SQR-ZR; LCSC C261881
U101: W25Q128JVPIQ; WSON-8-1EP_6x5mm_P1.27mm_EP3.4x4.3mm; Part Number W25Q128JVPIQ
U102: RP2040; QFN-56-1EP_7x7mm_P0.4mm_EP3.2x3.2mm; Part Number RP2040
Y101: 12MHz; Crystal_SMD_3225-4Pin_3.2x2.5mm; Part Number FL1200112

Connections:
+1V1: C104.1, C105.1, C106.1, U102.23 (DVDD), U102.45 (VREG_VOUT), U102.50 (DVDD)
+3V3: C13.1, C101.1, C109.1, C110.1, C111.1, C112.1, C113.1, C114.1, J101.4, J104.1, J114.P4 (VDD), R9.1, R101.1, U4.8 (VCC), U101.8 (VCC), U102.1 (IOVDD), U102.10 (IOVDD), U102.22 (IOVDD), U102.33 (IOVDD), U102.42 (IOVDD), U102.43 (ADC_AVDD), U102.44 (VREG_IN), U102.48 (USB_VDD), U102.49 (IOVDD)
/ACK: J101.9, R105.1
/ATT: J101.1, R106.1
/CLK: J101.5, R107.1
/CMD: J101.2, R108.1
/DATA: J101.7, R109.1
/OLED_SCL: J105.1, U102.37 (GPIO25)
/OLED_SDA: J106.1, U102.40 (GPIO28_ADC2)
/PSRAM_CLK: U4.6 (SCLK), U102.5 (GPIO3)
/PSRAM_CS: U4.1 (~CE), U102.4 (GPIO2)
/PSRAM_IO0: U4.5 (SI/SIO), U102.6 (GPIO4)
/PSRAM_IO1: U4.2 (SO/SIO), U102.7 (GPIO5)
/PSRAM_IO2: U4.3 (SIO2), U102.8 (GPIO6)
/PSRAM_IO3: U4.7 (SIO3), U102.9 (GPIO7)
/QSPI_CLK: U101.6 (CLK), U102.52 (QSPI_SCLK)
/QSPI_IO0: U101.5 (DI(IO0)), U102.53 (QSPI_SD0)
/QSPI_IO1: U101.2 (DO(IO1)), U102.55 (QSPI_SD1)
/QSPI_IO2: U101.3 (IO2), U102.54 (QSPI_SD2)
/QSPI_IO3: U101.7 (IO3), U102.51 (QSPI_SD3)
/QSPI_SS: J102.1, R101.2, U101.1 (~CS), U102.56 (QSPI_SS)
/SD_CLK: J114.P5 (CLK), U102.38 (GPIO26_ADC0)
/SD_CS: J114.P2 (CD/DAT3), U102.41 (GPIO29_ADC3)
/SD_MISO: J114.P7 (DAT0), R9.2, U102.36 (GPIO24)
/SD_MOSI: J114.P3 (CMD), U102.39 (GPIO27_ADC1)
/SW1: J112.1, U102.32 (GPIO21)
/SW2: J113.1, U102.35 (GPIO23)
/SYS_SWCLK: J107.1, U102.24 (SWCLK)
/SYS_SWDIO: J108.1, U102.25 (SWD)
/UART_RX: U102.12 (GPIO9)
/UART_TX: U102.11 (GPIO8)
/USB_DN: R103.2, U102.46 (USB_DM)
/USB_DP: R102.2, U102.47 (USB_DP)
/USB_IN_DN: J111.1, R103.1
/USB_IN_DP: J110.1, R102.1
GND: C13.2, C101.2, C102.1, C103.1, C104.2, C105.2, C106.2, C109.2, C110.2, C111.2, C112.2, C113.2, C114.2, J101.3, J101.6, J103.1, J114.G1 (GND), J114.G2 (GND__1), J114.G3 (GND__2), J114.G4 (GND__3), J114.G5 (GND__4), J114.G6 (GND__5), J114.G7 (GND__6), J114.G8 (GND__7), J114.G9 (GND__8), J114.G10 (GND__9), J114.P6 (VSS), U4.4 (VSS), U101.4 (GND), U102.19 (TESTEN), U102.57 (GND), Y101.2, Y101.4
unnamed: C102.2, R104.1, Y101.1
unnamed: R105.2, U102.27 (GPIO16)
unnamed: R106.2, U102.28 (GPIO17)
unnamed: R107.2, U102.29 (GPIO18)
unnamed: R108.2, U102.30 (GPIO19)
unnamed: R109.2, U102.31 (GPIO20)
unnamed: R104.2, U102.20 (XIN)
unnamed: C103.2, U102.21 (XOUT), Y101.3

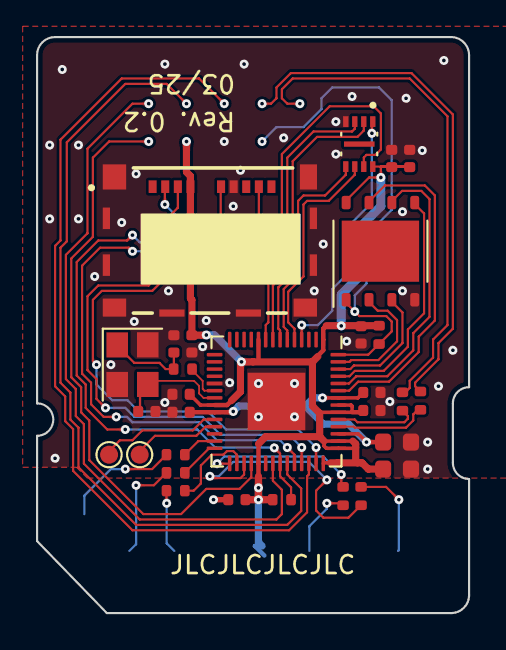
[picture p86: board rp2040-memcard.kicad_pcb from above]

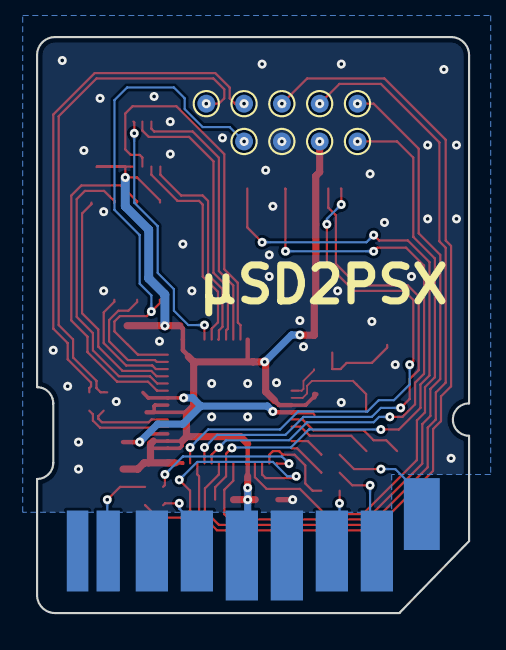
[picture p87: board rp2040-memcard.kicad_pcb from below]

Board: 2 copper layers, 24.0 x 32.0 mm, 40 parts (10 on the bottom side), 42 nets.

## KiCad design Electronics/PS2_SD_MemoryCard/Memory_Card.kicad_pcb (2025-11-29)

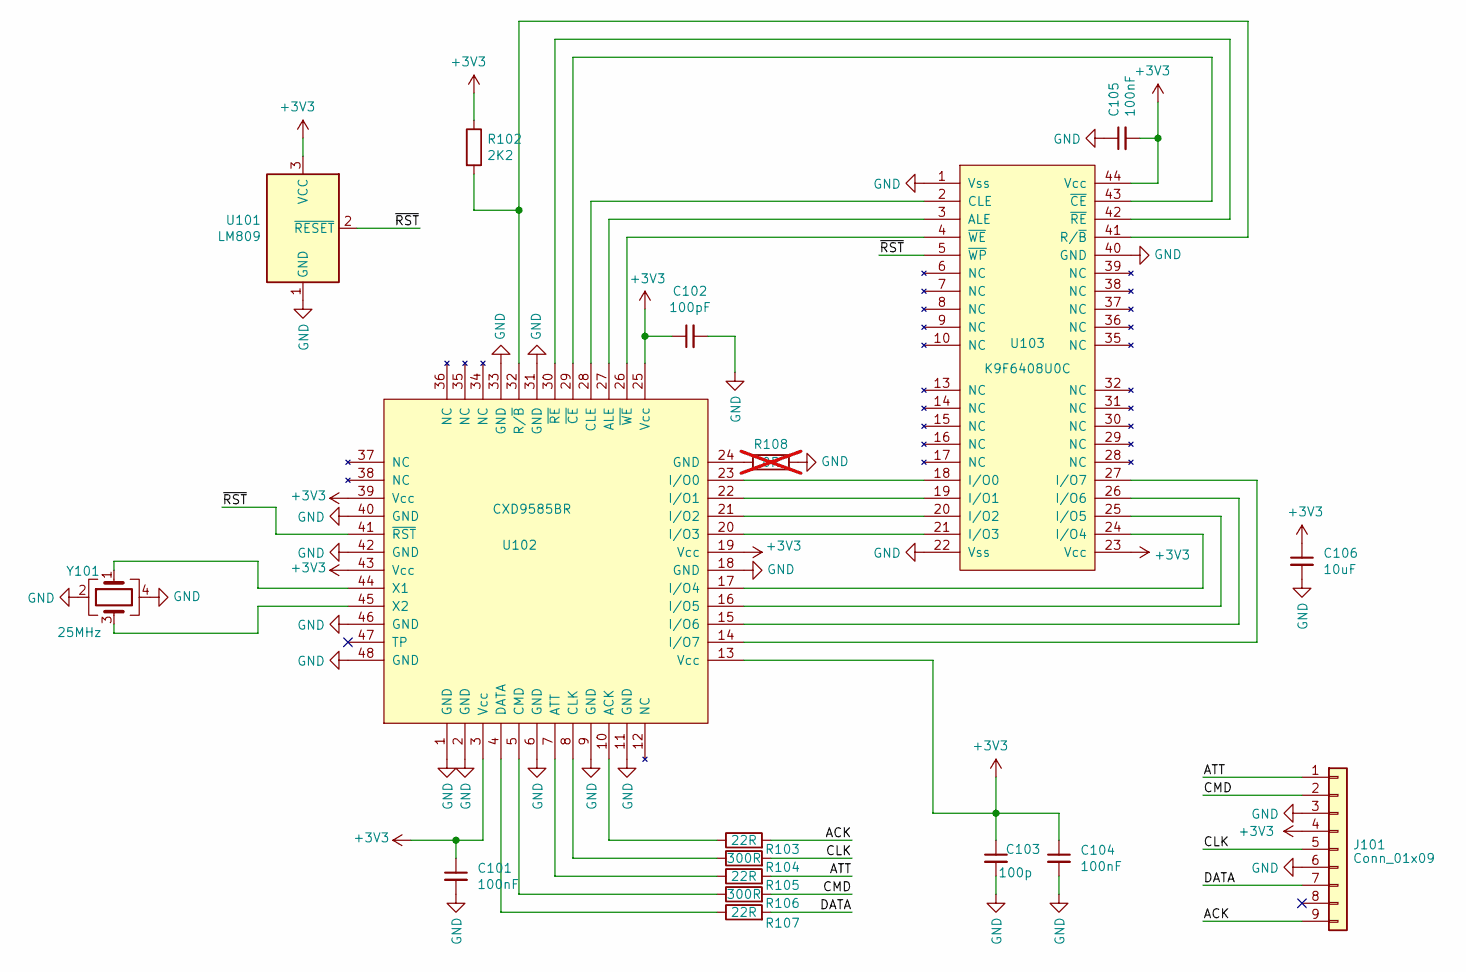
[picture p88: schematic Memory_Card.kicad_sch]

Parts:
C101, C104, C105: 100nF; C_0402_1005Metric; Part Number CC0402KRX7R7BB104
C102: 100pF; C_0402_1005Metric; Part Number CC0402KRX7R9BB101
C103: 100p; C_0402_1005Metric; Part Number CC0402KRX7R9BB101
C106: 10uF; C_0805_2012Metric; Part Number 885012107014
J101: Conn_01x09; SD_Pins
R102: 2K2; R_0402_1005Metric; Part Number RC0402FR-072K2L
R103, R105, R107: 22R; R_0402_1005Metric; Part Number RC0402FR-0722RL
R104, R106: 300R; R_0402_1005Metric; Part Number RC0402JR-07300RL
R108: 0R; R_0402_1005Metric; Part Number RC0402JR-130RL; not fitted
U101: LM809; SOT-23; Part Number LM809M3-2.63/NOPB
U102: CXD9585BR; LQFP-48_7x7mm_P0.5mm; Part Number Get off board
U103: K9F6408U0C; TSOP-II-44_10.16x18.41mm_P0.8mm; Part Number Get off board
Y101: 25MHz; Crystal_SMD_2016-4Pin_2.0x1.6mm; Part Number 402F2501XIAR

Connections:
+3V3: C101.1, C102.1, C103.1, C104.1, C105.2, C106.1, J101.4, R102.1, U101.3 (VCC), U102.3 (Vcc), U102.13 (Vcc), U102.19 (Vcc), U102.25 (Vcc), U102.39 (Vcc), U102.43 (Vcc), U103.23 (Vcc), U103.44 (Vcc)
/ACK: J101.9, R103.2
/ATT: J101.1, R105.2
/CLK: J101.5, R104.2
/CMD: J101.2, R106.2
/DATA: J101.7, R107.2
/~RST: U101.2 (~RESET), U102.41 (~RST), U103.5 (~WP)
GND: C101.2, C102.2, C103.2, C104.2, C105.1, C106.2, J101.3, J101.6, R108.2, U101.1 (GND), U102.1 (GND), U102.2 (GND), U102.6 (GND), U102.9 (GND), U102.11 (GND), U102.18 (GND), U102.31 (GND), U102.33 (GND), U102.40 (GND), U102.42 (GND), U102.46 (GND), U102.48 (GND), U103.1 (Vss), U103.22 (Vss), U103.40 (GND), Y101.2, Y101.4
unnamed: R108.1, U102.24 (GND)
unnamed: R103.1, U102.10 (ACK)
unnamed: U102.27 (ALE), U103.3 (ALE)
unnamed: R105.1, U102.7 (ATT)
unnamed: U102.28 (CLE), U103.2 (CLE)
unnamed: R104.1, U102.8 (CLK)
unnamed: R106.1, U102.5 (CMD)
unnamed: R107.1, U102.4 (DATA)
unnamed: U102.23 (I/O0), U103.18 (I/O0)
unnamed: U102.22 (I/O1), U103.19 (I/O1)
unnamed: U102.21 (I/O2), U103.20 (I/O2)
unnamed: U102.20 (I/O3), U103.21 (I/O3)
unnamed: U102.17 (I/O4), U103.24 (I/O4)
unnamed: U102.16 (I/O5), U103.25 (I/O5)
unnamed: U102.15 (I/O6), U103.26 (I/O6)
unnamed: U102.14 (I/O7), U103.27 (I/O7)
unnamed: R102.2, U102.32 (R/~B), U103.41 (R/~B)
unnamed: U102.44 (X1), Y101.1
unnamed: U102.45 (X2), Y101.3
unnamed: U102.29 (~CE), U103.43 (~CE)
unnamed: U102.30 (~RE), U103.42 (~RE)
unnamed: U102.26 (~WE), U103.4 (~WE)

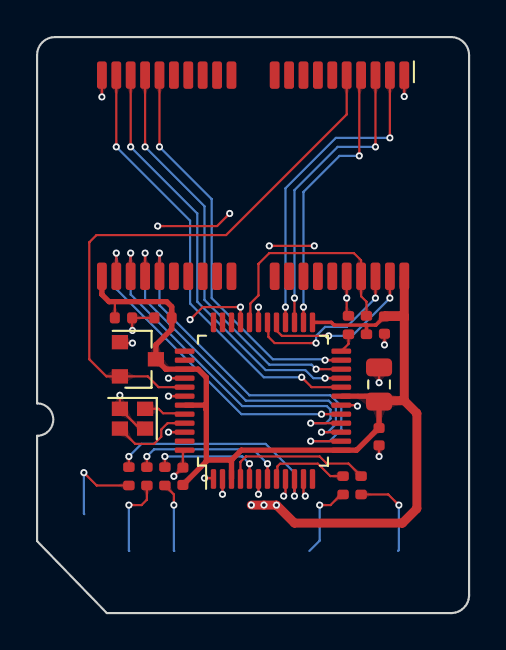
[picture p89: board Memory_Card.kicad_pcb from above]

Board: 2 copper layers, 24.0 x 32.0 mm, 18 parts (1 on the bottom side), 30 nets.

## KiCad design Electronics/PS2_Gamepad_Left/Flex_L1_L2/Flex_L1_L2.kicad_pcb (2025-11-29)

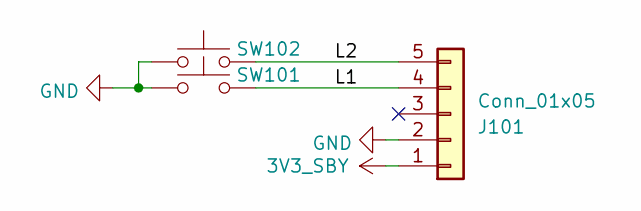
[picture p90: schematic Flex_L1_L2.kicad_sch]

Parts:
J101: Conn_01x05; 5034800540_FFC
SW101, SW102: SW; SW_KSC222J_LFS; Part Number KSC222J_LFS

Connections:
3V3_SBY: J101.1
/L1: J101.4, SW101.2
/L2: J101.5, SW102.2
GND: J101.2, SW101.1, SW102.1

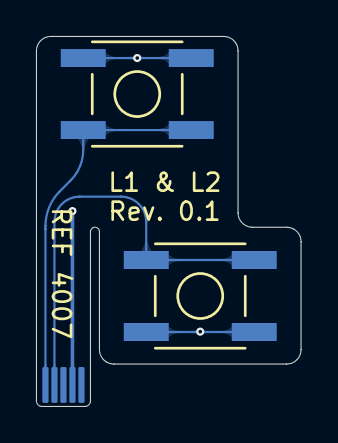
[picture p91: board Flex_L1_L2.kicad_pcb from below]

Board: 2 copper layers, 14.7 x 20.6 mm, 3 parts (3 on the bottom side), 3 nets.

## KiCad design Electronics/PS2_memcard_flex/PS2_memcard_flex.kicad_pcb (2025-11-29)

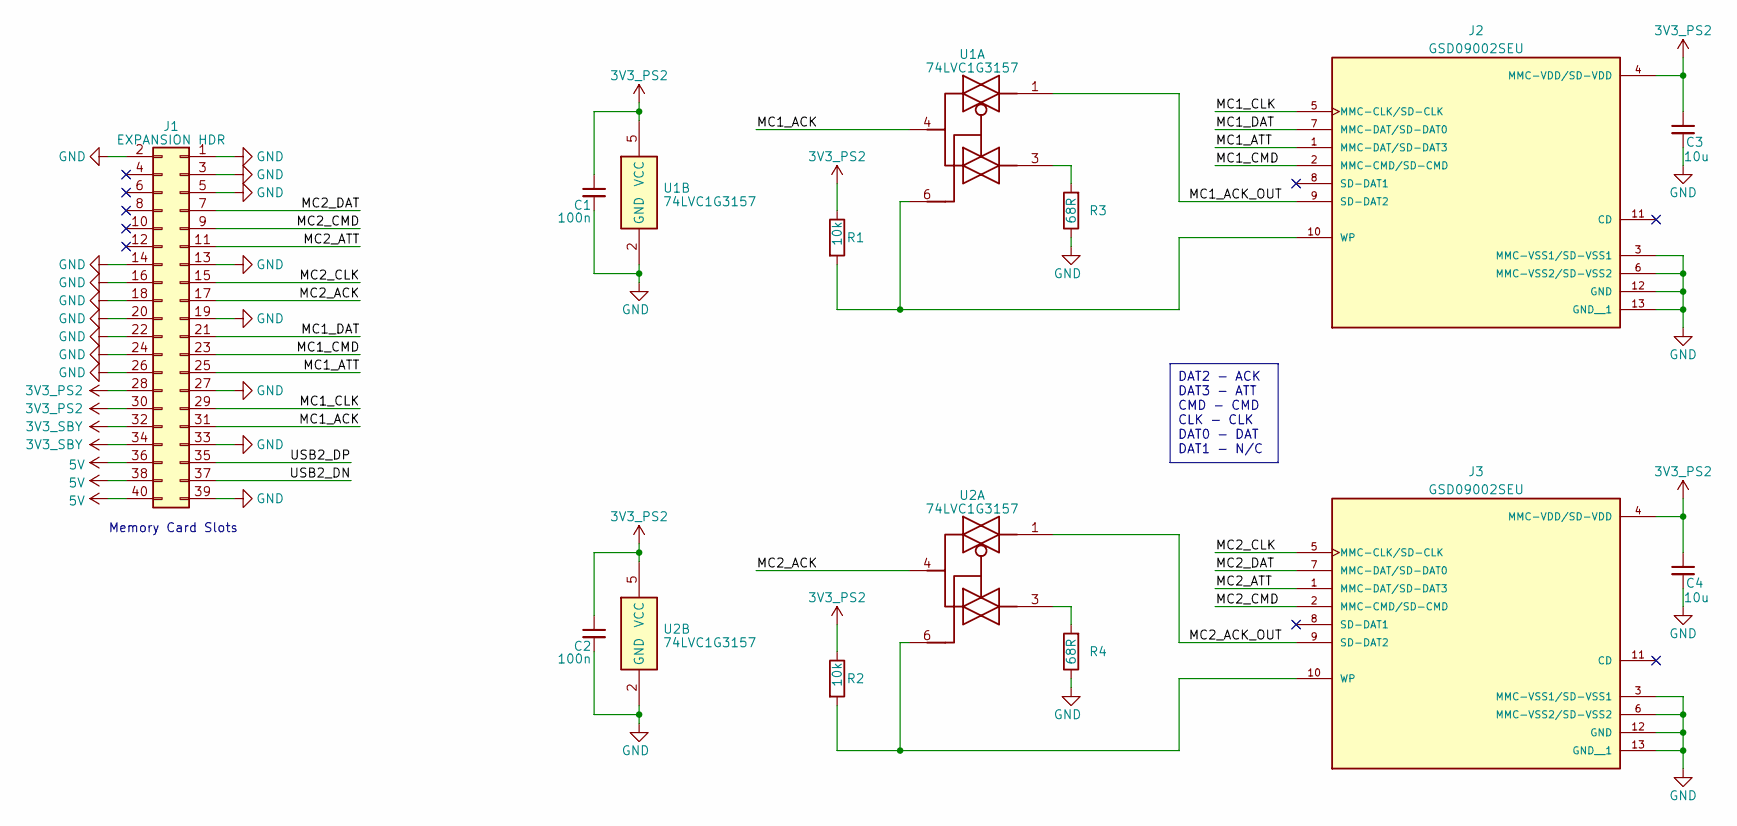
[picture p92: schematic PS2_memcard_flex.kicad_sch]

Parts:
C1, C2: 100n; C_0402_1005Metric; Part Number CC0402KRX7R7BB104
C3, C4: 10u; C_0805_2012Metric; Part Number TMK212BBJ106MGHT
J1: EXPANSION HDR; DF40C-40DP-0.4V; Part Number DF40C-40DP-0.4V(51)
J2, J3: GSD09002SEU; AMPHENOL_GSD09002SEU; Part Number GSD09002SEU
R1, R2: 10k; R_0402_1005Metric; Part Number RC0402JR-0710KL
R3, R4: 68R; R_0402_1005Metric; Part Number RC0402FR-0768RL
U1, U2: 74LVC1G3157; SOT-363_SC-70-6; Part Number 74LVC1G3157GW,125

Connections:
3V3_PS2: C1.1, C2.1, C3.1, C4.1, J1.28, J1.30, J2.4 (MMC-VDD/SD-VDD), J3.4 (MMC-VDD/SD-VDD), R1.1, R2.1, U1.5 (VCC), U2.5 (VCC)
3V3_SBY: J1.32, J1.34
5V: J1.36, J1.38, J1.40
/MC1_ACK: J1.31, U1.4
/MC1_ACK_OUT: J2.9 (SD-DAT2), U1.1
/MC1_ATT: J1.25, J2.1 (MMC-DAT/SD-DAT3)
/MC1_CLK: J1.29, J2.5 (MMC-CLK/SD-CLK)
/MC1_CMD: J1.23, J2.2 (MMC-CMD/SD-CMD)
/MC1_DAT: J1.21, J2.7 (MMC-DAT/SD-DAT0)
/MC2_ACK: J1.17, U2.4
/MC2_ACK_OUT: J3.9 (SD-DAT2), U2.1
/MC2_ATT: J1.11, J3.1 (MMC-DAT/SD-DAT3)
/MC2_CLK: J1.15, J3.5 (MMC-CLK/SD-CLK)
/MC2_CMD: J1.9, J3.2 (MMC-CMD/SD-CMD)
/MC2_DAT: J1.7, J3.7 (MMC-DAT/SD-DAT0)
/USB2_DN: J1.37
/USB2_DP: J1.35
GND: C1.2, C2.2, C3.2, C4.2, J1.1, J1.2, J1.3, J1.5, J1.13, J1.14, J1.16, J1.18, J1.19, J1.20, J1.22, J1.24, J1.26, J1.27, J1.33, J1.39, J2.3 (MMC-VSS1/SD-VSS1), J2.6 (MMC-VSS2/SD-VSS2), J2.12 (GND), J2.13 (GND__1), J3.3 (MMC-VSS1/SD-VSS1), J3.6 (MMC-VSS2/SD-VSS2), J3.12 (GND), J3.13 (GND__1), R3.1, R4.1, U1.2 (GND), U2.2 (GND)
unnamed: J2.10 (WP), R1.2, U1.6
unnamed: J3.10 (WP), R2.2, U2.6
unnamed: R3.2, U1.3
unnamed: R4.2, U2.3

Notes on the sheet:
DAT2 - ACK DAT3 - ATT CMD - CMD CLK - CLK DAT0 - DAT DAT1 - N/C
Memory Card Slots

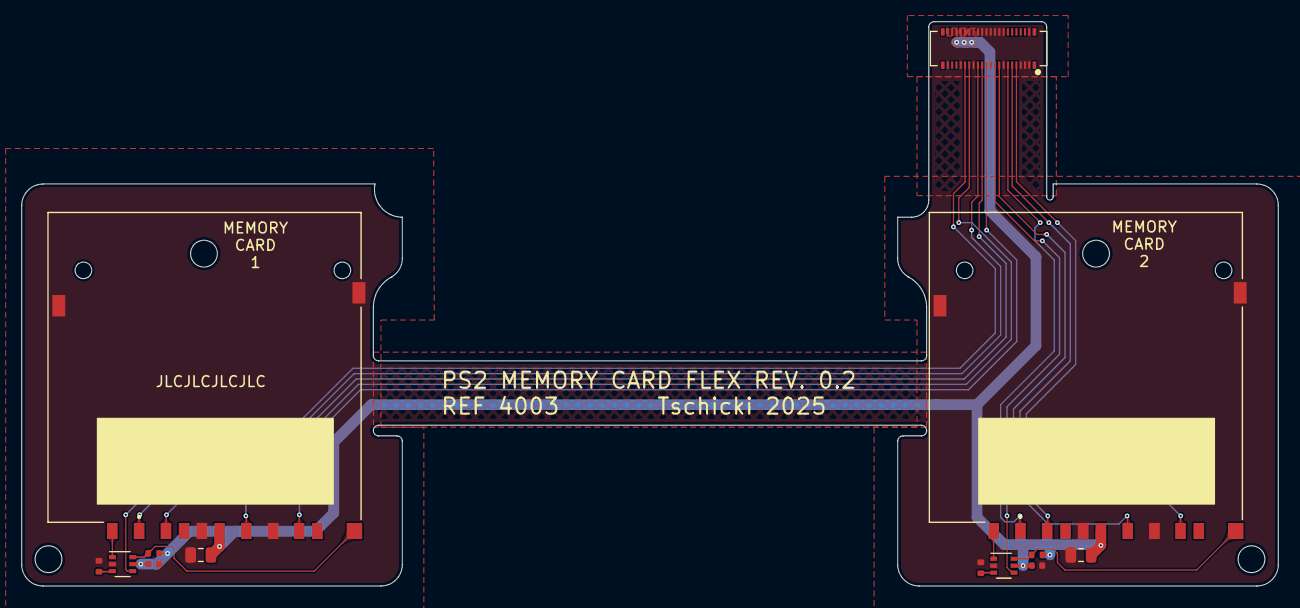
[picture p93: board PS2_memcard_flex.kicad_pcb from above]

Board: 2 copper layers, 117.2 x 52.6 mm, 13 parts (0 on the bottom side), 20 nets.

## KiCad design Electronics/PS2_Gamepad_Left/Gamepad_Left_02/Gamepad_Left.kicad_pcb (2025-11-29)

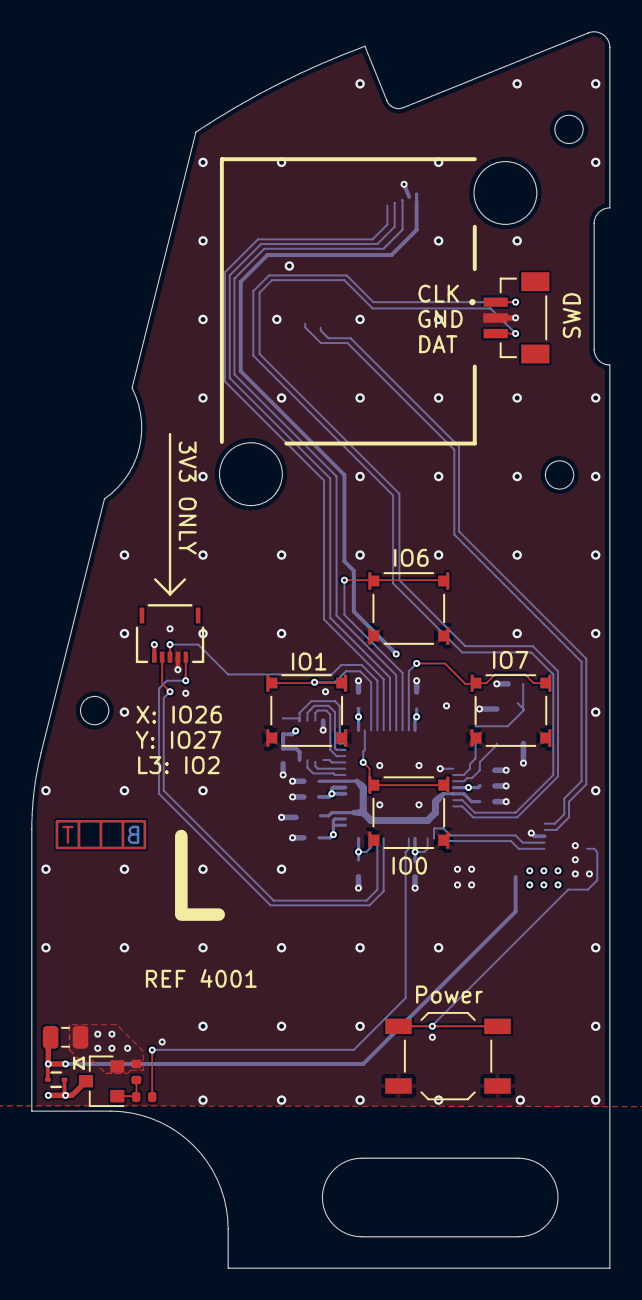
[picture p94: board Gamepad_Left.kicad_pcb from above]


Board: 4 copper layers, 36.8 x 78.7 mm, 35 parts (23 on the bottom side), 32 nets.

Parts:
C101, C105, C106, C107, C109, C110, C111, C112, C113, C114: 100n; C_0402_1005Metric
C102, C103: 15p; C_0402_1005Metric
C104: 1u; C_0603_1608Metric
C108, C115: 4u7; C_0805_2012Metric
D101: D_Schottky; SOD-923_0P6X0P85_ONS
J101: DEBUG_SWD; JST_BM03B-SRSS-TB_LF__SN_
J102: GAMEPAD LEFT; DF40C-10DP-0.4V51_HIR
J103, J116: Conn_01x05_MountingPin; CON_5034800540_MOL
J104: Motor; rumble_dual_solder_pad
Q101: BSS138; SOT-23
R101, R103: 10k; R_0402_1005Metric
R102, R104: 1k; R_0402_1005Metric
SW101, SW102, SW103, SW104: SW; SW_TL3315NF100Q
SW114: SW; SW_SPST_TL3342
TH101: 10k/3435K; R_0402_1005Metric
U101: W25Q16JVUXIQ; IC_W25Q16JVUXIQ_TR
U102: RP2040; QFN-56-1EP_7x7mm_P0.4mm_EP3.2x3.2mm
Y101: 12MHz; Crystal_SMD_3225-4Pin_3.2x2.5mm

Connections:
3V3_SBY: C101.1, C107.1, C108.1, C109.1, C110.1, C111.1, C112.1, C113.1, C114.1, C115.1, D101.1 (K), J102.7, J102.9, J103.5, J104.1, J116.5, R101.1, U101.8 (VCC), U102.1 (IOVDD), U102.10 (IOVDD), U102.22 (IOVDD), U102.31 (GPIO20), U102.33 (IOVDD), U102.40 (GPIO28_ADC2), U102.42 (IOVDD), U102.43 (ADC_AVDD), U102.44 (VREG_IN), U102.48 (USB_VDD), U102.49 (IOVDD)
+1V1: C104.1, C105.1, C106.1, U102.23 (DVDD), U102.45 (VREG_VOUT), U102.50 (DVDD)
/AUX_I2C_SCL: J102.4, U102.30 (GPIO19)
/AUX_I2C_SDA: J102.2, U102.29 (GPIO18)
/CS: R101.2, U101.1 (~CS), U102.56 (QSPI_SS)
/Down: SW103.1, U102.2 (GPIO0)
/IO0: U101.5 (DI(IO0)), U102.53 (QSPI_SD0)
/IO1: U101.2 (DO(IO1)), U102.55 (QSPI_SD1)
/IO2: U101.3 (IO2), U102.54 (QSPI_SD2)
/IO3: U101.7 (IO3), U102.51 (QSPI_SD3)
/L1: J103.2, U102.6 (GPIO4)
/L2: J103.1, U102.5 (GPIO3)
/L3: J116.3, U102.4 (GPIO2)
/Left: SW101.1, U102.3 (GPIO1)
/MEM_CLK: U101.6 (CLK), U102.52 (QSPI_SCLK)
/PWM_Rumble: R102.1, U102.34 (GPIO22)
/Reserved: J103.3, U102.7 (GPIO5)
/Right: SW104.1, U102.9 (GPIO7)
/SWCLK: J101.1, U102.24 (SWCLK)
/SWDIO: J101.3, U102.25 (SWD)
/SYS_PWR_BTN: J102.1, SW114.1
/TS_+: J102.8, TH101.2
/TS_-: J102.10, TH101.1
/Up: SW102.1, U102.8 (GPIO6)
/X: J116.1, U102.38 (GPIO26_ADC0)
/XI: C103.2, U102.21 (XOUT), Y101.3
/XO: R104.2, U102.20 (XIN)
/Y: J116.4, U102.39 (GPIO27_ADC1)
GND: C101.2, C102.1, C103.1, C104.2, C105.2, C106.2, C107.2, C108.2, C109.2, C110.2, C111.2, C112.2, C113.2, C114.2, C115.2, J101.2, J102.3, J102.5, J102.6, J103.4, J116.2, Q101.2 (S), R103.2, SW101.2, SW102.2, SW103.2, SW104.2, SW114.2, U101.4 (GND), U102.19 (TESTEN), U102.57 (GND), Y101.2, Y101.4
unnamed: C102.2, R104.1, Y101.1
unnamed: D101.2 (A), J104.2, Q101.3 (D)
unnamed: Q101.1 (G), R102.2, R103.1

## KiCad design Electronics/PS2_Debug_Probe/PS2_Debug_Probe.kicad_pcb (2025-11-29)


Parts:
J1: Debug; FTSH-107-01-F-DV-K-P-TR; Part Number FTSH-107-01-F-DV-K-P-TR
J101: DEBUG_SWD; JST_SM03B-SRSS-TB(LF)(SN); Part Number SM03B-SRSS-TB
U1: RP2040-ZERO; MODULE_RP2040-ZERO; PARTREV NA
U2: FT2232H_mini_module_jtag

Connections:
+3V3: U2.1 (3V3), U2.3 (3V3), U2.5 (3V3), U2.11 (VIO), U2.21 (VIO), U2.38 (VIO), U2.48 (VIO)
+5V: U2.27 (VBUS), U2.29 (5Vin)
/CRESET_N: J1.3, U2.14 (AD4)
/SPI_SS: J1.5, U2.12 (AD3)
/SYS_SWCLK: J1.12, J101.1, U1.11 (GP10)
/SYS_SWDIO: J1.14, J101.3, U1.12 (GP11)
/SYS_UART_RX: J1.9, U1.9 (GP8)
/SYS_UART_TX: J1.11, U1.10 (GP9)
/TCK: J1.4, U2.52 (BD0)
/TDI: J1.8, U2.51 (BD1)
/TDO: J1.6, U2.50 (BD2)
/TMS: J1.2, U2.49 (BD3)
GND: J1.1, J1.7, J1.10, J1.13, J101.2, U1.13 (GP12), U1.22 (GND), U2.2 (GND), U2.4 (GND), U2.6 (GND), U2.28 (GND), U2.30 (GND)

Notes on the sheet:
GP8 TX GP9 RX GP10 SWCLK GP11 SWDIO GP12 GND GP13 GND GP14 3V3
FT2232H Mini Module with JTAG
Bus powered config
DEBUG



Board: 2 copper layers, 35.6 x 32.2 mm, 4 parts (2 on the bottom side), 13 nets.

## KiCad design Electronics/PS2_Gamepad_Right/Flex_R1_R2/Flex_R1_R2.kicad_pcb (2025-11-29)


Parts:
J101: Conn_01x05; 5034800540_FFC
SW101, SW102: SW; SW_KSC222J_LFS; Part Number KSC222J_LFS

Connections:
3V3_SBY: J101.1
/R1: J101.5, SW101.2
/R2: J101.4, SW102.2
GND: J101.2, SW101.1, SW102.1


Board: 2 copper layers, 14.7 x 20.6 mm, 3 parts (0 on the bottom side), 3 nets.

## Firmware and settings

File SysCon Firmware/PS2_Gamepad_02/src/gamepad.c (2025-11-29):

#include "gamepad.h"

uint8_t side_flag = 0;
struct Gamepad io;

uint16_t rumble_last = 0;
volatile uint8_t rumble_boost_flag = 0;

static struct
{
    uint8_t mem[10];
    uint8_t mem_size;
    uint8_t mem_address;
    bool mem_address_written;
} registers;

int main(void)
{
    /*first thing to do is to determine the gamepad side for initialization*/
    io.side_sel = determine_side(SIDE_SEL);
    
    /*initialize the gamepad IO, this contains left and right gamepad*/
    GPIO_init(&io);
    
    /*set the register size for the I2C slave and clear all registers*/
    registers.mem_size = sizeof(registers.mem);
    for(uint8_t i = 0; i < registers.mem_size; i++)
        registers.mem[i] = 0;

    /*initialize the slave based on the jumper positions*/
    if (io.side_sel == SIDE_RIGHT)
        i2c_slave_init(SLAVE_I2C, SLAVE_ADDRESS_RIGHT, &i2c_slave_handler);
    else
        i2c_slave_init(SLAVE_I2C, SLAVE_ADDRESS_LEFT, &i2c_slave_handler);

    while (1)
    {
        io_handler();
        if(io.side_sel == SIDE_RIGHT) led_handler();
        motor_handler();
    }
}

void i2c_slave_handler(i2c_inst_t *i2c, i2c_slave_event_t event)
{
    switch (event)
    {
    case I2C_SLAVE_RECEIVE: // master has written some data
        if (!registers.mem_address_written)
        {
            // writes always start with the memory address
            registers.mem_address = i2c_read_byte_raw(i2c);
            registers.mem_address_written = true;
        }
        else
        {
            // save into memory
            if (registers.mem_address <= registers.mem_size)
            {
                registers.mem[registers.mem_address] = i2c_read_byte_raw(i2c);
                registers.mem_address++;
            }
        }
        break;
    case I2C_SLAVE_REQUEST: // master is requesting data
        // load from memory
        if (registers.mem_address <= registers.mem_size)
        {
            i2c_write_byte_raw(i2c, registers.mem[registers.mem_address]);
            registers.mem_address++;
        }
        else
        {
            i2c_write_byte_raw(i2c, 0x00);
        }
        break;
    case I2C_SLAVE_FINISH: // master has signalled Stop / Restart
        registers.mem_address_written = false;
        break;
    default:
        break;
    }
}

void io_handler(void)
{
    /*read all button inputs and place them in registers 0 and 1*/
    /*read the analog sticks and stick voltage -> convert and store in reg 2-5 */
    /*run this funtion in main, as the slave is based on IRQ*/
    uint16_t digitalstates = 0;
    uint8_t pinstate = 0;

    uint16_t analog_x, analog_y, analog_vcc = 0;

    if (io.side_sel == SIDE_RIGHT)
    {
        for (uint8_t i = 0; i < RIGHT_PINCOUNT; i++)
        {
            pinstate = sys_get_pin(io.button_right[i]);
            digitalstates = digitalstates | (((uint16_t)pinstate) << io.button_right[i].shift);
        }
    }
    else
    {
        for (uint8_t i = 0; i < LEFT_PINCOUNT; i++)
        {
            pinstate = sys_get_pin(io.button_left[i]);
            digitalstates = digitalstates | (((uint16_t)pinstate) << io.button_left[i].shift);
        }
    }
    /*write digital states into the register map*/
    registers.mem[REG00_BUTTONS_L] = (uint8_t)digitalstates;
    registers.mem[REG01_BUTTONS_H] = (uint8_t)(digitalstates >> 8);

    /*adc read analog stick; consider splitting it into left&right in the future*/
    adc_select_input(X_ADC);
    analog_x = adc_read();
    adc_select_input(Y_ADC);
    analog_y = adc_read();
    adc_select_input(STICK_VOLTAGE_ADC);
    analog_vcc = adc_read();

    /*if VCC is 1.8V, multiply the values and cap them at 12bit; to "fake" the full range*/
    if (analog_vcc < 2400)
    {
        analog_x = analog_x * 2;
        analog_y = analog_y * 2;

        if (analog_x > 4096)
            analog_x = 4096;
        if (analog_y > 4096)
            analog_y = 4096;
    }
    /*write analog states into the register map*/
    registers.mem[REG02_ANALOG_X_L] = (uint8_t)analog_x;
    registers.mem[REG03_ANALOG_X_H] = (uint8_t)(analog_x >> 8);
    registers.mem[REG04_ANALOG_Y_L] = (uint8_t)analog_y;
    registers.mem[REG05_ANALOG_Y_H] = (uint8_t)(analog_y >> 8);
}

/*read the LED regs and set the respective PWM outputs*/
void led_handler(void)
{
    uint16_t red = registers.mem[REG07_LED_R] * WRAP_MULTIPLIER;
    uint16_t green = registers.mem[REG08_LED_G] * WRAP_MULTIPLIER;
    uint16_t blue = registers.mem[REG09_LED_B] * WRAP_MULTIPLIER;

    if(red > PWM_LED_WRAP) red = PWM_LED_WRAP;
    if(green > PWM_LED_WRAP) green = PWM_LED_WRAP;
    if(blue > PWM_LED_WRAP) blue = PWM_LED_WRAP;

    /*invert set value due to LED connection*/
    red = PWM_LED_WRAP - red;
    green = PWM_LED_WRAP - green;
    blue = PWM_LED_WRAP - blue;

    pwm_set_chan_level(io.slice_r, io.chan_r, red);
    pwm_set_chan_level(io.slice_g, io.chan_g, green);
    pwm_set_chan_level(io.slice_b, io.chan_b, blue);
}

/*read the Rumble PWM reg and set the respective PWM output*/
void motor_handler(void)
{
    /*map the register to PWM*/
    /*0 should turn off rumble; 1 should generate a voltage just high enough to start the motor (2V?)*/
    /*translate the motor startup voltage to PWM_MOT_MIN: 
    5100(PWM_MOT_WRAP) is equivalent to 3.3V -> PWM_MOT_MIN = measured startup voltage [V] * (5100/3.3)*/
    uint8_t rumble_strength = registers.mem[REG06_MOTOR];
    uint16_t pwm = map_to_pwm(rumble_strength, 0, 255, PWM_MOT_MIN, PWM_MOT_WRAP);

    /*if the register is set to zero we force off the motor; any vlue above that will start rumble*/
    if(rumble_strength == 0) pwm = 0;

    pwm_set_chan_level(io.slice_mot, io.chan_mot, pwm);

}

uint16_t map_to_pwm(uint8_t input, uint8_t in_min, uint8_t in_max, uint16_t out_min, uint16_t out_max)
{
    /*clip the input*/
    if (input > in_max)
        input = in_max;
    if (input < in_min)
        input = in_min;

    float delta_out = (float)out_max - (float)out_min;
    float delta_in = (float)in_max - (float)in_min;
    float factor = delta_out / delta_in;
    float result_f = (((float)(input - in_min)) * factor) + (float)out_min;
    uint16_t mapped_pwm = (uint16_t)result_f;

    if(mapped_pwm > out_max) mapped_pwm = out_max;
    if(mapped_pwm < out_min) mapped_pwm = out_min;
    //mapped_pwm = (uint8_t)((input - in_min) * (out_max - out_min) / (in_max - in_min) + out_min);

    return mapped_pwm;
}

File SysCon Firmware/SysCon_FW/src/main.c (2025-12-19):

#include "main.h"

/*variables to provide for core1*/
uint16_t digital_states = 0;
uint16_t previous_digital_states = 0;
uint8_t current_analog_states[16] = {0};
uint8_t motor_left_pwm = 0;
uint8_t motor_right_pwm = 0;

/*stuff used by main functions and IRQ*/
/*flag to indicate whether the power management needs to be polled*/
volatile uint8_t poll_power_flag = 0;
volatile uint8_t poll_button_flag = 0;
volatile uint8_t power_good_flag = 0;

/*incremented at every power poll timer irq, currently 100ms*/
volatile uint16_t systick = 0;

int main(void)
{
  #ifdef WATCHDOG_EN
    watchdog_enable(WATCHDOG_TIMEOUT, true);
  #endif

  static struct power_dev power_dev;
  /*initialize the both the run state and charge states*/
  power_dev.cur_run_state = STATE_SYS_DEFAULT;
  power_dev.next_run_state = STATE_SYS_DEFAULT;
  power_dev.last_run_state = STATE_SYS_DEFAULT;

  power_dev.cur_chg_state = STATE_CHARGE_DEFAULT;
  power_dev.next_chg_state = STATE_CHARGE_DEFAULT;
  power_dev.last_chg_state = STATE_CHARGE_DEFAULT;

  power_dev.power_error_flag = 0;

  /*init GPIO*/
  MX_GPIO_Init(&power_dev.io);
  /*initialize interfaces for debugging*/
  MX_UART_Init(UART);
  /*initial state for system*/
  power_dev.cur_run_state = syscon_state_str(STATE_INIT, power_dev.cur_run_state);

  while (1)
  {
    //run_state_machine(&power_dev);
    run_power_state_machine(&power_dev);
    run_charge_state_machine(&power_dev);
    
    if (poll_power_flag == 1)
      run_power_polling(&power_dev);

    if (poll_button_flag == 1)
      run_button_polling(&power_dev);

    #ifdef WATCHDOG_EN
      watchdog_update();
    #endif
  }
}


void run_power_polling(struct power_dev *power_dev)
{
  /*should be executed very POWER_POLL_INTERVAL_US when enabled*/
  if(BQ_read_ADC(&power_dev->BQ_Dev) != ERROR_OK)
    power_dev->power_error_flag = 1;
  if(BQ_getFault_Flag(&power_dev->BQ_Dev) != ERROR_OK)
    power_dev->power_error_flag = 1;
  if(BQ_getCHG_Status(&power_dev->BQ_Dev) != ERROR_OK)
    power_dev->power_error_flag = 1;

  #ifndef DEBUG_IGNORE_MAX
  if(MAX_get_batt_properties(&power_dev->MAX_Dev) != ERROR_OK)
    power_dev->power_error_flag = 1;
  if(MAX_get_status(&power_dev->MAX_Dev) != ERROR_OK)
    power_dev->power_error_flag = 1;
  #endif

  if((power_dev->cur_run_state == STATE_RUN) || (power_dev->cur_run_state == STATE_CONFIG))
  {
    /*sample temperature, apply fan curve and update PWM counts - ONLY when the PS2 is on*/
    run_fan_control(&power_dev->fan_dev);
    /*shut down system if EE gets too hot*/
    if(power_dev->fan_dev.ee_temperature > 50.0)
      power_dev->power_error_flag = 1;
  }
  /*update power LED with state of charge*/
  set_power_led(power_dev->MAX_Dev.MAX_batt_properties.state_of_charge, &power_dev->powerLED);
  handle_led_patterns(&power_dev->powerLED, &power_dev->gp_dev.extio_dev[GP_RIGHT], systick);
  /*check whether headphones were plugged*/
  power_dev->amp_dev.hp_detect_state = sys_get_pin(power_dev->io.pin[PIN_HP_DETECT]);

  poll_power_flag = 0;
  power_dev->power_status_known = 1;
}

void run_button_polling(struct power_dev *power_dev)
{

  gamepad_user_read_buttons(&power_dev->gp_dev);
  gamepad_user_set_rumble(&power_dev->gp_dev, motor_right_pwm, motor_left_pwm);

  if(power_dev->menu_dev.fpga_dev.magh_autodetect_enable == 1)
    fpga_magh_autocorrect(&power_dev->menu_dev.fpga_dev, &power_dev->io);

  if(power_dev->cur_run_state != STATE_CONFIG){
    digital_states = power_dev->gp_dev.current_digital_states;
    previous_digital_states = power_dev->gp_dev.previous_digital_states;

    for(uint8_t i = 0; i < 16; i++) 
      current_analog_states[i] = power_dev->gp_dev.current_analog_states[i];

  }

  poll_button_flag = 0;
}

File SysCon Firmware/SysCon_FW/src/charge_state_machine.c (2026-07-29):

#include "charge_state_machine.h"

void run_charge_state_machine(struct power_dev *power_dev)
{

    switch (power_dev->cur_chg_state)
    {

    case STATE_CHARGE_DEFAULT:
        /*do nothing*/
        break;

    case STATE_WAIT_FOR_STATUS:
        /*the power_status_known flag is set by the power state machine, once everything was initialized*/
        if (power_dev->power_status_known == 1)
        {
            #ifndef BLOCK_CHARGE
            power_dev->cur_chg_state = syscon_state_str(STATE_GET_POWER_STATUS, power_dev->cur_chg_state);
            #endif
        }
        break;

    case STATE_GET_POWER_STATUS:
        power_dev->next_chg_state = run_state_get_power_status(&power_dev->BQ_Dev);
        if (power_dev->next_chg_state != STATE_GET_POWER_STATUS)
        {
            power_dev->cur_chg_state = syscon_state_str(power_dev->next_chg_state, power_dev->cur_chg_state);
        }
        break;

    case STATE_CHARGE_INIT:
        power_dev->cur_chg_state = syscon_state_str(run_state_charge_init(&power_dev->STUSB_Dev, &power_dev->BQ_Dev, &power_dev->io), power_dev->cur_chg_state);
        break;

    case STATE_CHARGE:
        power_dev->next_chg_state = get_charger_status(&power_dev->BQ_Dev);
        power_dev->powerLED.led_parameters[PATTERN_SOC].enable = 1;
        if (power_dev->next_chg_state != STATE_CHARGE)
        {
            power_dev->cur_chg_state = syscon_state_str(power_dev->next_chg_state, power_dev->cur_chg_state);
        }
        break;

    case STATE_CHARGE_ERROR:
        /*not yet defined*/
        sys_set_pin(power_dev->io.pin[PIN_CHARGE_EN], SYSPIN_HIZ);
        /*dump all the MAX registers via UART*/
        MAX_dump_settings_uart(&power_dev->MAX_Dev);
        /*dump all the BQ registers via UART*/
        if (power_dev->powerLED.led_parameters[PATTERN_ERROR].enable == 0)
        {
            printf("----------------------------------------------\r\n");
            printf("ADC READINGS:\r\n");
            if (power_dev->BQ_Dev.BQ_ADC_Config.ibus_adc_dis == ADC_FUNC_ENABLE)
                printf("IBUS: %dmA\r\n", power_dev->BQ_Dev.BQ_ADC_Readings.ibus_adc);
            if ((power_dev->BQ_Dev.BQ_ADC_Config.ibat_adc_dis == ADC_FUNC_ENABLE) && (power_dev->BQ_Dev.BQ_ADC_Config.en_ibat == ADC_FUNC_ENABLE))
                printf("IBAT: %dmA\r\n", power_dev->BQ_Dev.BQ_ADC_Readings.ibat_adc);
            if (power_dev->BQ_Dev.BQ_ADC_Config.vbus_adc_dis == ADC_FUNC_ENABLE)
                printf("VBUS: %umV\r\n", power_dev->BQ_Dev.BQ_ADC_Readings.vbus_adc);
            if (power_dev->BQ_Dev.BQ_ADC_Config.vbat_adc_dis == ADC_FUNC_ENABLE)
                printf("VBAT: %umV\r\n", power_dev->BQ_Dev.BQ_ADC_Readings.vbat_adc);
            if (power_dev->BQ_Dev.BQ_ADC_Config.vsys_adc_dis == ADC_FUNC_ENABLE)
                printf("VSYS: %umV\r\n", power_dev->BQ_Dev.BQ_ADC_Readings.vsys_adc);
            if (power_dev->BQ_Dev.BQ_ADC_Config.ts_adc_dis == ADC_FUNC_ENABLE)
                printf("TempSens: %f%%\r\n", (float)(power_dev->BQ_Dev.BQ_ADC_Readings.ts_adc) * 0.0976563f);
            if (power_dev->BQ_Dev.BQ_ADC_Config.tdie_adc_dis == ADC_FUNC_ENABLE)
                printf("DieTemp: %f°C\r\n", (float)(power_dev->BQ_Dev.BQ_ADC_Readings.tdie_adc * 0.5));
            if (power_dev->BQ_Dev.BQ_ADC_Config.dp_adc_dis == ADC_FUNC_ENABLE)
                printf("D+: %umV\r\n", power_dev->BQ_Dev.BQ_ADC_Readings.dp_adc);
            if (power_dev->BQ_Dev.BQ_ADC_Config.dm_adc_dis == ADC_FUNC_ENABLE)
                printf("D-: %umV\r\n", power_dev->BQ_Dev.BQ_ADC_Readings.dm_adc);
            if (power_dev->BQ_Dev.BQ_ADC_Config.vac2_adc_dis == ADC_FUNC_ENABLE)
                printf("VAC2: %umV\r\n", power_dev->BQ_Dev.BQ_ADC_Readings.vac2_adc);
            if (power_dev->BQ_Dev.BQ_ADC_Config.vac1_adc_dis == ADC_FUNC_ENABLE)
                printf("VAC1: %umV\r\n", power_dev->BQ_Dev.BQ_ADC_Readings.vac1_adc);
            printf("----------------------------------------------\r\n");
            printf("CHG Status:\r\n");
            printf("IINDPM Status: %x\r\n", power_dev->BQ_Dev.BQ_CHGStatus.iindpm_stat);
            printf("VINDPM Status: %x\r\n", power_dev->BQ_Dev.BQ_CHGStatus.vindpm_stat);
            printf("Watchdog Status: %x\r\n", power_dev->BQ_Dev.BQ_CHGStatus.wd_stat);
            printf("Poor Source Status: %x\r\n", power_dev->BQ_Dev.BQ_CHGStatus.poorsrc_stat);
            printf("Power Good Status: %x\r\n", power_dev->BQ_Dev.BQ_CHGStatus.pg_stat);
            printf("VAC2 Insert Status: %x\r\n", power_dev->BQ_Dev.BQ_CHGStatus.ac2_present_stat);
            printf("VAC1 Insert Status: %x\r\n", power_dev->BQ_Dev.BQ_CHGStatus.ac1_present_stat);
            printf("VBUS Present Status: %x\r\n", power_dev->BQ_Dev.BQ_CHGStatus.vbus_present_stat);
            printf("Charge status bits: %x\r\n", power_dev->BQ_Dev.BQ_CHGStatus.chg_stat);
            printf("VBUS status bits: %x\r\n", power_dev->BQ_Dev.BQ_CHGStatus.vbus_stat);
            printf("BC1.2 status bit: %x\r\n", power_dev->BQ_Dev.BQ_CHGStatus.bc12_done_stat);
            printf("ICO Status: %x\r\n", power_dev->BQ_Dev.BQ_CHGStatus.ico_stat);
            printf("Thermal Regulation Status: %x\r\n", power_dev->BQ_Dev.BQ_CHGStatus.treg_stat);
            printf("D+/D- Detection Status: %x\r\n", power_dev->BQ_Dev.BQ_CHGStatus.dpdm_stat);
            printf("Battery Present Status: %x\r\n", power_dev->BQ_Dev.BQ_CHGStatus.vbat_present_stat);
            printf("ACFET 2 Status: %x\r\n", power_dev->BQ_Dev.BQ_CHGStatus.acrb2_stat);
            printf("ACFET 1 Status: %x\r\n", power_dev->BQ_Dev.BQ_CHGStatus.acrb1_stat);
            printf("ADC Conversion Status: %x\r\n", power_dev->BQ_Dev.BQ_CHGStatus.adc_done_stat);
            printf("VSYS Regulation Status: %x\r\n", power_dev->BQ_Dev.BQ_CHGStatus.vsys_stat);
            printf("Fast charge timer Status: %x\r\n", power_dev->BQ_Dev.BQ_CHGStatus.chg_tmr_stat);
            printf("Trickle charge timer Status: %x\r\n", power_dev->BQ_Dev.BQ_CHGStatus.trichg_tmr_stat);
            printf("Pre-charge timer Status: %x\r\n", power_dev->BQ_Dev.BQ_CHGStatus.prechg_tmr_stat);
            printf("VBAT too low for OTG: %x\r\n", power_dev->BQ_Dev.BQ_CHGStatus.vbatotg_low_stat);
            printf("Bat Temp is cold: %x\r\n", power_dev->BQ_Dev.BQ_CHGStatus.ts_cold_stat);
            printf("Bat Temp is cool: %x\r\n", power_dev->BQ_Dev.BQ_CHGStatus.ts_cool_stat);
            printf("Bat Temp is warm: %x\r\n", power_dev->BQ_Dev.BQ_CHGStatus.ts_warm_stat);
            printf("Bat Temp is hot: %x\r\n", power_dev->BQ_Dev.BQ_CHGStatus.ts_hot_stat);
            printf("----------------------------------------------\r\n");
            printf("Fault Flags:\r\n");
            printf("ibat_reg_flag: %x\r\n", power_dev->BQ_Dev.BQ_FaultFlags.ibat_reg_flag);
            printf("vbus_ovp_flag: %x\r\n", power_dev->BQ_Dev.BQ_FaultFlags.vbus_ovp_flag);
            printf("vbat_ovp_flag: %x\r\n", power_dev->BQ_Dev.BQ_FaultFlags.vbat_ovp_flag);
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

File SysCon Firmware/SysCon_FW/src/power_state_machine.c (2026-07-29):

#include "power_state_machine.h"

/*flag to stop the gamepad emulator; set to 1 to stop and wait until 0*/
extern volatile uint gamepad_reset_flag;
/*flash variables offset in flash, must align with 4k sectors*/
const uint8_t *flash_target_contents = (const uint8_t *)(XIP_BASE + FLASH_TARGET_OFFSET);
/*used to temporarily store and disable interrupts for flash functions*/
uint32_t irq_status = 0;

void run_power_state_machine(struct power_dev *power_dev)
{
    /*in case an error happened in the power polling function, shut down*/
    if (power_dev->power_error_flag == 1)
        power_dev->cur_run_state = syscon_state_str(STATE_RUN_ERROR, power_dev->cur_run_state);

    switch (power_dev->cur_run_state)
    {
    case STATE_INIT:
        power_dev->cur_run_state = syscon_state_str(run_state_init(power_dev), power_dev->cur_run_state);
        /*only continue when communication with MAX is possible -> checked in run_state_init() function*/
        if (power_dev->cur_run_state != STATE_RUN_ERROR)
        {
            /*charging state machine should only start when everything was initialized*/
            power_dev->cur_chg_state = syscon_state_str(STATE_WAIT_FOR_STATUS, power_dev->cur_chg_state);
            /*starts the timer to launch the power management check continuosly*/
            start_power_poll_timer(POWER_POLL_INTERVAL_US);
        }
        break;

    case STATE_WAIT_USER:
        power_dev->next_run_state = run_state_wait_user(&power_dev->io);
        if (power_dev->next_run_state != STATE_WAIT_USER)
        {
            power_dev->cur_run_state = syscon_state_str(power_dev->next_run_state, power_dev->cur_run_state);
            power_dev->powerLED.led_parameters[PATTERN_SOC].enable = 1;
        }
        break;

    case STATE_BOOT:
        power_dev->next_run_state = run_state_boot(power_dev);
        if (power_dev->next_run_state != STATE_BOOT)
        {
            power_dev->cur_run_state = syscon_state_str(power_dev->next_run_state, power_dev->cur_run_state);
        }
        break;

    case STATE_RUN:
        power_dev->next_run_state = run_state_run(&power_dev->io);
        if (power_dev->next_run_state != STATE_RUN)
        {
            power_dev->last_run_state = power_dev->cur_run_state;
            power_dev->cur_run_state = syscon_state_str(power_dev->next_run_state, power_dev->cur_run_state);
        }
        break;

    case STATE_CONFIG:
        power_dev->next_run_state = run_state_config(power_dev);
        if (power_dev->next_run_state != STATE_CONFIG)
        {
            power_dev->cur_run_state = syscon_state_str(power_dev->next_run_state, power_dev->cur_run_state);
        }
        break;

    case STATE_SHUTDOWN:
        power_dev->cur_run_state = syscon_state_str(run_state_shutdown(&power_dev->io, &power_dev->amp_dev, &power_dev->gp_dev), power_dev->cur_run_state);
        break;

    case STATE_LOAD_SETTINGS:
        power_dev->cur_run_state = syscon_state_str(run_state_load_settings(power_dev), power_dev->cur_run_state);
        break;

    case STATE_STORE_SETTINGS:
        power_dev->cur_run_state = syscon_state_str(run_state_store_settings(power_dev), power_dev->cur_run_state);
        break;

    case STATE_OFF:
        power_dev->cur_run_state = syscon_state_str(run_state_off(power_dev), power_dev->cur_run_state);
        break;

    case STATE_WRITE_CONFIG:
        manufacturing_config(power_dev);
        handle_led_patterns(&power_dev->powerLED, &power_dev->gp_dev.extio_dev[GP_RIGHT], systick);
        power_dev->cur_run_state = syscon_state_str(STATE_RUN_HALT, power_dev->cur_run_state);
        break;
    
    case STATE_RUN_HALT:
        /*do nothing*/
        break;

    case STATE_RUN_ERROR:
        /*not defined yet*/
        power_dev->cur_run_state = syscon_state_str(STATE_OFF, power_dev->cur_run_state);
        break;

    default:
        syscon_error_str(ENTERED_UNDEFINED_STATE);
        power_dev->cur_run_state = syscon_state_str(STATE_RUN_ERROR, power_dev->cur_run_state);
        break;
    }
}

syscon_state_t run_state_init(struct power_dev *power_dev)
{
    uint8_t retry = 0;

    spi_interface_init(FPGA_SPI, FPGA_TX_PIN, FPGA_RX_PIN, FPGA_SCK_PIN, FPGA_SPI_BAUDRATE);
    i2c_interface_init(PRW_I2C, PWR_I2C_SDA_PIN, PWR_I2C_SCL_PIN, PWR_I2C_BAUD_RATE);
    power_dev->BQ_Dev.interface = PRW_I2C;
    power_dev->STUSB_Dev.interface = PRW_I2C;
    power_dev->MAX_Dev.interface = PRW_I2C;

    led_patterns_init(&power_dev->powerLED);
    gamepad_interface_init(&power_dev->gp_dev);
    fan_init();
    menu_fill_struct(&power_dev->menu_dev);

    /*initialize battery mnagement*/
    BQ_init_structs(&power_dev->BQ_Dev);

    #ifndef DEBUG_IGNORE_MAX
    /*try to cummunicate with MAX - first time powering on or when battery was dead this will trigger*/
    do
    {
        retry++;
        if (MAX_get_status(&power_dev->MAX_Dev) != ERROR_OK)
        {
            printf("ERROR communicating with protector! - TRY #%u\n", retry);
            sys_set_pin(power_dev->io.pin[PIN_CHARGE_EN], SYSPIN_LOW);
            delay_ms(500);
            sys_set_pin(power_dev->io.pin[PIN_CHARGE_EN], SYSPIN_HIZ);
        }
        else
            break;
    } while (retry < 3);

    if (retry == 3)
        return STATE_RUN_ERROR;
    
    
    /*set config only if current config was lost -> battery removed
    possible registers to indicate: IOTG*/
    if (BQ_check_config_present(&power_dev->BQ_Dev) == BQ_CONFIG_MISMATCH)
    {
        //printf("UPDATING MAX CONFIG\n");
        /*only needed if NVM was not flashed*/
        // if (MAX_update_nvconfig(&power_dev->MAX_Dev) != ERROR_OK)
        //     return STATE_SHUTDOWN;

        printf("UPDATING BQ CONFIG\n");
        if (BQ_set_config(&power_dev->BQ_Dev) != ERROR_OK)
            return STATE_SHUTDOWN;
    }
    #endif
    if (BQ_write_ADC_config(&power_dev->BQ_Dev) != ERROR_OK)
        return STATE_SHUTDOWN;
    if (BQ_ADC_EnDi(&power_dev->BQ_Dev, ADC_ENABLE) != ERROR_OK)
        return STATE_SHUTDOWN;

    // debug - dump MAX settings

    return STATE_LOAD_SETTINGS;
}

syscon_state_t run_state_wait_user(struct SysCon_Pins *io)
{
    /*was the power button pressed?*/
    if (sys_get_pin(io->pin[PIN_POWERBTN]) == 0)
    {
        delay_ms(1000);

        if (sys_get_pin(io->pin[PIN_POWERBTN]) == 0)
        {
#if defined(DEBUG_WRITE_STUSB_NVM) || defined(DEBUG_FLASH_MAX_NVM)
            /*if this was defined, stop here and got to NVM flashing*/
            return STATE_WRITE_CONFIG;
#else
            /*else boot normally*/
            sys_set_pin(io->pin[PIN_SYS_FORCE_ON], SYSPIN_HIGH);
            return STATE_BOOT;
#endif
        }
    }
    return STATE_WAIT_USER;
}
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

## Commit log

2025-11-29 Release files
    [1048_18650_holder.step, 12402012E212A.step, 1551576-5.step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]
2025-11-29 re-export mainboard BOM
    [MechaCon_Interfaces.kicad_sch, PS2 AIO Mainboard Rev04.csv]
2025-12-19 implement magh-autodetect feature; various corrections in the docs based on feedback
    [BQ25792.c, FPGA_Registers.h, MCU_interface.c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]
2025-12-29 fix distorted video output for MAGH 9 setting; remove unused MAGH 8 setting from menu
    [MCU_interface.h, fpga.c]
2026-04-04 Add a version of the top housing with design supports on some features for more consistent print results
    [Backside Vent Cover REF2014.STEP, Battery Compartment Left REF2004.STEP, Battery Compartment Right REF2005.STEP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]
2026-06-21 correct part number of uSD2PSX SPI flash
    [NS2_Analog_Stick.SLDPRT, rp2040-memcard.kicad_pcb, rp2040-memcard.kicad_sch]
2026-06-23 Update part number of crystal Y1502 on REF4000
    [MechaCon_Interfaces.kicad_sch, PS2 AIO Mainboard Rev04.csv, PS2_79004_Rev_0_4.kicad_pcb]
2026-07-29 fix recovery from battery undervoltage events
    [BQ25792.c, MAX17320.c, MCU_interface.h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]
2026-09-13 fix random gamepad disconnects in certain games
    [MCU_interface.h, gamepad_core.c]
